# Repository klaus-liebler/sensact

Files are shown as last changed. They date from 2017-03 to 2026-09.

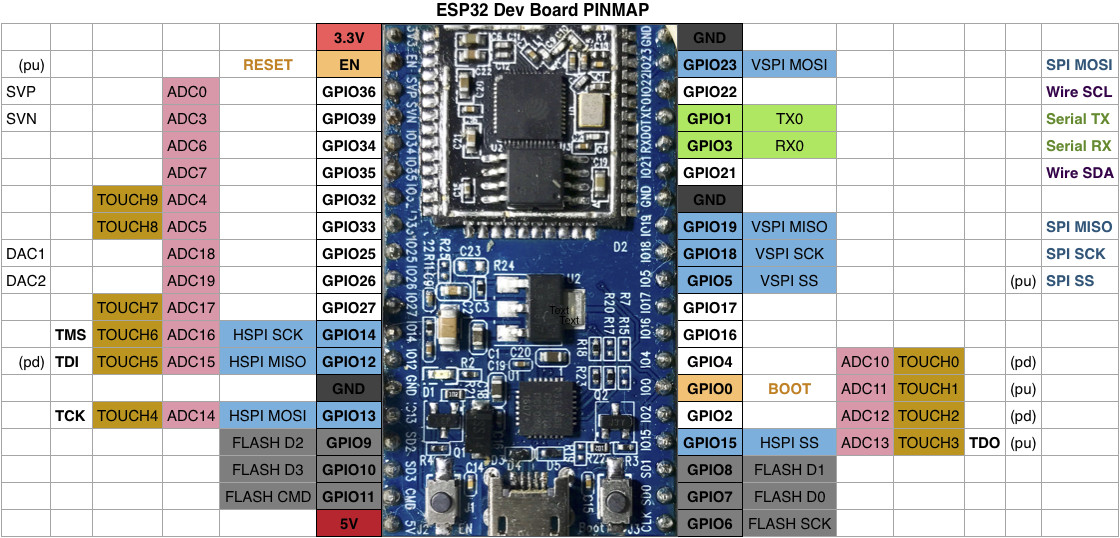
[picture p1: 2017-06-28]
doc/ESP32-T-Pinout-Diagram-Large.jpg

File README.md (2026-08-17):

# sensact
Smarthome system - hardware, firmware, visualization

## Architektur
* Verteiltes System. Modellbasierte Codeerzeugung.
* Grundlage ist `firmware/sensact_firmware/builder/Models/` (Phase `GenerateModelFiles`).
  Hier ein Projekt analog Beispielprojekt "Sattlerstrasse16" anlegen (s.
  `firmware/sensact_firmware/docs/build-process.md`).
* Kleinste Einheit ist eine "Application", die eine eindeutige ID besitzt. Beispiele für Applications sind "Taster", "Drehencoder", "Jalousie" oder "PWM-Licht"

## Hardware
1. SensactHS: Hutschienenmontage
1. SensactUP: Unterputzmontage

## Kommunikation zwischen den Knoten
Die Knoten sind über einen gemeinsamen CAN-Bus verbunden.

### Altes Nachrichtenformat ()
TBD

### Neues Nachrichtenformat

Es gibt vier Namespaces für Nachrichten "REQUEST" und "RESPONSE", "EVENT" und "ACKNOWLEDGE". Dies wird mit den beiden LSB des Versions-Namespace-Bytes erklärt (Somit bleiben 64 Versionierungsmöglichkeiten)
Alle vier Namespaces haben ihren eigenen counter. Dieser beginnt bei 0x0 mit der ersten versendeten Nachricht und läuft nach 255 (0xFF) wieder auf 0. Die Ready-Nachricht wird immer mit counter=0x0 übertragen. Sie darf verwendet werden, um die Kommunikations-Session abzubrechen und die counter neu zu starten. Die counter representieren gemeinsames Wissen von Master und Slave  
REQEST (0b00): Vom Master zum Slave.
RESPONSE (0b01): Antwort auf REQUEST
EVENT (0b10): Vom Slave zum Master
ACKNOWLEDGE (0b11): Antwort des Masters auf ein Event

REQUEST
0x00: "HEARTBEAT": Board gibt Heartbeat zurück
0x01: "IDENTIFY: 
0x02: "SEND_CAN":

RESPONSE
In der Response wird einfach die ID des Requests übernommen. Häufig wird dann ein REQUEST-spezifischer Fehlercode als uint32-t zurück geliefert. Eine 0x0 steht dann per Konvention für eine fehlerfreie Verarbeitung. Ggf. werden in Zukunft WELL_KNOWN_ERROR_CODES definiert.
0x01: UNEXPECTED_COUNTER
0x02: CRC_ERROR

Alle Responses, die nicht nur einen reinen Error-Code, sondern spezifischere Daten zurück liefern, werden im folgenden beschrieben  
0x01: "IDENTIFY": Board gibt Board-Typ u16. NodeID u16 und ID des Chips u96 (?) zurück.

EVENTS
00 "READY" Slave meldet sich nach dem Booten und gibt an, dass er jetzt für Befehle aller Art bereit steht. Beginn einer Session. Alle counter werden auf 0 gesetzt, außer der EVENT_COUNTER - der muss nun auf 1 stehen
02 "CAN_RECEIVED": Slave zeigt an, dass er eine CAN-Nachricht empfangen (besser: auf dem Bus mitgelesen) hat

ACKNOWLEDGES:
Der Slave kann bei ausbleibendem Acknowledge die Nachricht nochmals versenden

## WebUI

### Konzept

Auf einer Website sollen alle Apps einer Node mit commands versehen werden können
Jeder Host hat eine Bedienoberfläche
Problem: Wird die Bedienoberfläche zur Laufzeit von den Hosts und ihren Unterobjekten generiert (a) HTML oder b)JSON) oder kennt die WebUI bereits alle Objekte
Kennt die WebUI die Objekte auch semantisch oder kann Sie nur eine HTML-GUI aufbauen zur Erzeugung von CAN-Bus-Nachrichten 
Denkweise: Die WebUI kann CAN-Nachrichten erzeugen und so an die Node senden, wie sie auch über den CAN-Bus an der Node ankommen würden. Es muss ein JSON generiert werden, das zur Erzeugung einer HTML-UI verwendet werden kann, die dann eben genau diese Nachrichten sendet
Die WebUI kennt bereits alle Applications, die in der Node vorhanden sind. Dazu wird neben der C++-Instanzierung auch TypeScript-Code aufgebaut, der die entsprechenden Objekte aufbaut
Für Buttons und RotEnc gibt es die Möglichkeit, die Beträtigung zu simulieren. Dazu wird dann einfach jene Nachricht auf den MessageBus gelegt, die auch in Wirklichkeit vrsendet wird
An Aktoren können jene Commands versendet werden mitsamt notwendiger Parameter
Für die Erstellung eines Command

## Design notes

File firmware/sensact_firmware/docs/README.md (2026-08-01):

# sensact_firmware – Entwicklerdokumentation

Einstiegspunkt für alles, was zum Verständnis und zur Weiterentwicklung dieses
Projekts gebraucht wird.

- [repo-map.md](repo-map.md) – Aus welchen Repos das Gesamtsystem besteht und wie sie
  zusammenhängen
- [build-process.md](build-process.md) – Wie ein Build/Flash Schritt für Schritt
  abläuft
- [board-provisioning.md](board-provisioning.md) – Wie ein neues Board angelegt und
  in Betrieb genommen wird
- [architecture.md](architecture.md) – Node-/HAL-/App-Architektur der Firmware
  (lebendes Dokument)
- [plan_v2/00-overview.md](plan_v2/00-overview.md) – Der mehrstufige Überarbeitungsplan
  (Stand 2026), falls du wissen willst, warum etwas gerade so ist, wie es ist, oder
  was als Nächstes geplant ist

## Kurzfassung für Eilige

`sensact_firmware` ist die ESP-IDF-Firmware für die "sensact"-Hausautomatisierungs-
Boards (Rollladen, Relais, Dimmer, Fingerprint-Türsteuerung u.a.). Sie ist Teil des
größeren `sensact`-Repos, bindet aber mehrere eigenständige Repos ein (Wifimanager,
Web-UI-Bausteine, Build-Tools) – siehe [repo-map.md](repo-map.md) für Details, bevor
du an mehreren Stellen gleichzeitig etwas änderst.

Ein Build läuft heute über `builder/gulpfile.ts` (Node/TypeScript, wird gerade
schrittweise auf ein C#-Tool umgestellt, siehe
[plan_v2/02-builder-migration-csharp.md](plan_v2/02-builder-migration-csharp.md)) –
Details in [build-process.md](build-process.md).

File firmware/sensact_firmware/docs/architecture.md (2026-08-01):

# Architektur

Lebendes Dokument – wird im Zuge von
[plan_v2/04-architektur-review.md](plan_v2/04-architektur-review.md) laufend
erweitert/korrigiert. Der aktuelle Stand ist eine erste, aus einer Code-Analyse
gewonnene Bestandsaufnahme (2026-07-31), noch nicht vollständig verifiziert.

## Grobe Schichten

```
main.cc (app_main)
  └─ webmanager::M (eigenes Repo: espidf-component-webmanager)
       – Wifi-Statemachine, HTTP/OTA/Login, Plugin-Dispatch
  └─ cNodemaster (nodemaster.hh)
       – 100ms-Zyklus: CAN-RX -> OfferMessage(hosts) -> Loop(hosts) -> CAN/Health
       – implementiert iHostContext (Services für Hosts) und iWebmanagerPlugin
       ├─ AbstractBusmaster[] (busmaster.hh)
       │    ├─ I2CBusmaster       – PCA9555/PCA9685 über I2C, eigener Task
       │    ├─ DirectGPIOBusmaster – direkt über iHAL
       │    └─ CANBusmaster        – Stub
       └─ iHost[] (interfaces.hh)
            ├─ cApplicationHost (node_applicationhost.cc/hh)
            │    – implementiert iHost + sensact::apps::iSensactContext + iWebmanagerPlugin
            │    – Setup/Loop/Status-Publishing aller sensact-Apps
            │    └─ cApplication[] (sensact/espidf-components/sensact-applicationmodel/apps/)
            │         blind, blindstimer, onoff, pump, singlepwm, rgbw, sound,
            │         milightcontroller, pushbutton, rotaryencoder, node, fingerprint
            ├─ cGatewayHost (node_gatewayhost.hh) – aktuell No-Op-Stub
            └─ cIoHost (node_iohost.hh)          – aktuell No-Op-Stub
```

## HAL-Board-Varianten (`main/hal/`)

Gemeinsame Basis `hal_esp32.hh` (`sensact::hal::cESP32`, TWAI/CAN, GPIO, UART,
MCPWM, Temperatursensor). Board-spezifische Ableitungen:

| Datei | Board-Variante | Besonderheiten |
|---|---|---|
| `hal_sensactHs_modular.hh` | HS Modular | internes I2C, I2S-Audio (MAX98357), Ethernet, CAN |
| `hal_sensactHsNano3.hh` | HS Nano3 | TAS580x-Verstärker, Ethernet, ADC-Buttons, Buzzer |
| `hal_sensactOutdoor.hh` | Outdoor | Relais K1–K4, LEDs, NRF-Funk, MAX98357-Audio |
| `hal_sensactUp3.hh` | Up3 | SPI-LCD, 1-Wire, Drehencoder |
| `hal_sensactUpControl.hh` | Up Control | NRF-Funk, Fingerprint-Sensor, Buzzer |
| `hal_sensactUpHs.hh` | Up HS | 2 Drehencoder, Codec/MAX98357-Audio, USB-VBUS-Sense |

Grad der Code-Duplizierung zwischen diesen 6 Dateien noch nicht im Detail geprüft –
siehe Backlog-Punkt in
[plan_v2/04-architektur-review.md](plan_v2/04-architektur-review.md).

Pro Node (`main/hal/<NODE_ID>/`) liegen zusätzlich drei **von Hand gepflegte**
`.inc`-Dateien (`hal.inc`, `station_config_hardware.inc`,
`station_config_hosts.inc`), die auswählen, welche HAL/Busmaster/Hosts für dieses
konkrete Board aktiv sind – siehe [board-provisioning.md](board-provisioning.md).

## Sensact-Apps

Jede App erbt von `sensact::apps::cApplication`
(`sensact-applicationmodel/cApplication.hh`): `Setup(iSensactContext*)`,
`Loop(iSensactContext*)`, `FillStatus(iSensactContext&, array<uint16_t,4>&)`, plus
generierte Command-Handler. Die Registry `cApplications::Glo2locCmd[]`/`Glo2locEvt[]`
bildet `eApplicationID` auf konkrete Instanzen ab (oder `nullptr`, falls die App auf
einem anderen Node gehostet wird). Alle App-Methoden hängen nur am Interface
`iSensactContext`, nicht an ESP-IDF-Typen direkt – das ist die Grundlage für die
Host-Testbarkeit in [plan_v2/05-unit-tests-sensact-apps.md](plan_v2/05-unit-tests-sensact-apps.md).

## Cross-Cutting

- `messagecodes.hh` – X-Macro-generiertes `enum class messagecodes::C` +
  String-Tabelle, aus `messagecodes_default.inc` + optionalem `messagecodes_user.inc`.
- `logger.hh` – `LOGGER::Journal(code, data)`, leitet an
  `webmanager::JournalPlugin` weiter.
- `journal_plugin.cc/hh` – Ringpuffer (16 Einträge) in `__NOINIT_ATTR`-RAM (überlebt
  Neustarts außer Kaltstart), exponiert über Websocket (`ns10journal`).

## Bekannt tote/veraltete Teile

`main/__archive/` – nicht im Build referenziert (`.ccold`/`.hhold`-Endungen,
veraltete APIs). Aufräum-Kandidat, siehe
[plan_v2/04-architektur-review.md](plan_v2/04-architektur-review.md).

## Wifimanager

Server-seitig eine einzelne ~1430-Zeilen-Klasse `webmanager::M`
(`espidf-component-webmanager/cpp/webmanager.hh`), die WLAN-Statemachine,
HTTP-Fileserver, OTA, Login/Session und Wifimanager-Protokoll in einer Klasse
vereint. Details, bekannte Bugs und das geplante konfigurierbare AP-Fallback siehe
[plan_v2/03-wifimanager-review.md](plan_v2/03-wifimanager-review.md).

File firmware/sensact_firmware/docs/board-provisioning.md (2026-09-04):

# Board-Provisioning

Ablauf, um ein neues physisches Board mit dieser Firmware in Betrieb zu nehmen.

## 1. Board anschließen und auslesen

```
cd builder
npm run u    # addOrUpdateConnectedBoard
```

Liest MAC-Adresse und Chip-Infos vom per USB verbundenen Board aus (eigene
serielle SLIP/ROM-Loader-Implementierung in `esp32.ts`, kein `esptool`-Aufruf) und
legt/aktualisiert die board-spezifische `board_info.json` unter
`%USERPROFILE%\OneDrive - HSOS\esp32_boards\<mac-dir>\board_info.json` an. Diese
Datei wird außerdem als "aktuell verbundenes Board" in den Projekt-Root kopiert
(`board_info.json` neben dieser Datei).

`board_info.json`-Schema (`SensactBoardRecord`) -- generischer, projektübergreifender Teil des
Board-Zustands (Backing für `IBuildContext.WebAdminPassword`/`BoardSettings`, s.
`dotnet_libs/firmware_builder_common`):

```json
{
  "mac": "...",
  "board_version": 10000,
  "board_settings": { "override_hostname": "...", "last_debug_probe_id": "..." },
  "first_connected_dt": "...",
  "last_connected_dt": "...",
  "web_admin_password": null,
  "flash_encryption_key_burned_and_activated": false
}
```

`board_settings` ist ein flaches String-Dictionary (generische Overrides, projektübergreifend).
Wohlbekannte Schlüssel: `"override_hostname"`, `"override_wifi_ap_ssid"`, `"last_debug_probe_id"`.

## 2. Node-ID / Board-Rolle festlegen

Nicht `board_info.json`, sondern das board-spezifische `sensact.json` (s. Abschnitt 3) legt per
`node_id` fest, welches Unterverzeichnis unter `main/hal/<NODE_ID>/` zur Build-Zeit eingebunden
wird (`main/CMakeLists.txt`: `INCLUDE_DIRS "hal/${NODE_ID}"`). `board_version` ist rein
beschreibend und beeinflusst die `NODE_ID` nicht. `board_name` (Anzeige, Default-Web-Passwort)
lebt jetzt ebenfalls in `sensact.json`, s. Abschnitt 3 -- sensact-spezifisch, nicht Teil des
projektübergreifenden `board_info.json`-Vertrags.

**Wichtig (bestätigt von Klaus, 2026-07-31): die drei Dateien pro Node-Verzeichnis
werden von Hand gepflegt, es gibt aktuell keinen Generator dafür:**

- `hal.inc` – welche `iHAL`-Implementierung (`hal_sensact*.hh`) für dieses Board
  verwendet wird.
- `station_config_hardware.inc` – Verdrahtung der `AbstractBusmaster`-Instanzen
  (I2C-Busmaster, GPIO-Busmaster, …) auf die physische Hardware.
- `station_config_hosts.inc` – welche `iHost`-Instanzen (`cApplicationHost`,
  `cGatewayHost`, `cIoHost`) für diesen Node aktiv sind.

Existiert für die gewünschte `NODE_ID` noch kein solches Verzeichnis, muss es manuell
neu angelegt werden (bestehendes `main/hal/<ähnliches-Board>/` als Vorlage nehmen).

## 3. Sensact-spezifisches `sensact.json`

Zusätzlich zu `board_info.json` liest der Builder (`ISensactContext`/`SensactContextLoader.cs`)
ein board-spezifisches `sensact.json` (`<boardsDir>\<mac-dir>\sensact.json`):

```json
{
  "node_id": "SNSCT_L3_WORK_HS",
  "board_name": "SENSACT_L3_WORK",
  "board_settings": { "web": {}, "firmware": {} }
}
```

`node_id` wird als HAL-Include-Verzeichnisname *und* (sofern nicht per `board_settings.override_hostname`
überschrieben) als Hostname verwendet. `board_name`/`board_settings` sind sensact-spezifisch (Anzeige,
Default-Web-Passwort-Fallback, App-/Web-Defines) -- nicht Teil des projektübergreifenden
`board_info.json`-Vertrags. Muss beim erstmaligen Anlegen eines Boards von Hand angelegt werden.

## 4. Generieren, bauen, flashen

```
npm run c     # buildForCurrent: createFiles + Web-Build + idf.py build
# oder die Vollkette inkl. Flash:
npm start     # addOrUpdateConnectedBoard -> buildForCurrent -> encrypt (falls nötig) -> flash
```

## 5. Zertifikate & Flash-Encryption

- Board-Zertifikat (`esp32.pem.crt`/`esp32.pem.key`) wird beim ersten `createFiles`-Lauf
  automatisch erzeugt (selbstsigniert, signiert von der Root-CA unter
  `OneDrive - HSOS\certificates`), falls noch nicht vorhanden.
- Flash-Encryption-Key wird ebenfalls lazy erzeugt, falls noch nicht vorhanden.
  Ob tatsächlich verschlüsselt geflasht wird, hängt von `DEFAULT_ENCRYPTION_MODE`
  (`gulpfile.ts`) und dem gespeicherten
  `flash_encryption_key_burned_and_activated`-Flag ab.

## 6. Build ohne physisches Board (offline)

Um für eine beliebige `NODE_ID` (z.B. `SNSCT_NODE_SIDEDOOR`) einen kompletten Build
durchzuführen, ohne dass das Board angeschlossen ist und ohne dessen echte MAC zu
kennen, ruft `PipelineOffline --nodeId <NODE_ID>` intern zuerst `PrepareContextWithCommandLineArguments`
auf (Nachfolger von `SelectOfflineBoard`) -- wählt ein synthetisches Board-Archiv aus (eine
aus der `NODE_ID` deterministisch abgeleitete, als "locally administered" markierte
Fake-MAC -- niemals eine echte Hersteller-MAC, s. `SensactBuildContext.EnsureBoardForOfflineNodeId`).
Danach laufen die uebrigen Schritte wie gewohnt:

```
dotnet run --project builder -- PipelineOffline --nodeId SNSCT_NODE_SIDEDOOR --model Sattlerstrasse16
# oder einzeln:
dotnet run --project builder -- PrepareContextWithCommandLineArguments --nodeId SNSCT_NODE_SIDEDOOR
dotnet run --project builder -- PipelineOffline --model Sattlerstrasse16
```

Legt bei Bedarf ein neues Board-Archiv unter `<boardsDir>\<fake-mac-dir>\` mit
Default-`board_info.json` und passender `sensact.json` an (inkl. eigenem Zertifikat,
s. Abschnitt 5) und überschreibt den Repo-Root-Cache (`board_info.json`), genau wie
`PrepareContextWithRealHardware` es für ein echtes Board täte. Gleiche `NODE_ID` -> gleiche Fake-MAC
-> gleiches Archiv, das Zertifikat wird also nicht bei jedem Lauf neu erzeugt. Flashen
(`FlashFirmware`) ergibt für ein solches Board naturgemäß keinen Sinn und ist nicht
Teil von `PipelineOffline`.

## Offene Punkte (siehe auch [plan_v2/01-entwicklerdokumentation-und-build.md](plan_v2/01-entwicklerdokumentation-und-build.md))

- Es gibt keinen automatisierten Weg, ein komplett neues `main/hal/<NODE_ID>/`-Verzeichnis
  aus einer Vorlage zu erzeugen – das ist reine Handarbeit und ein möglicher, aber
  aktuell nicht geplanter Verbesserungspunkt für die C#-Builder-Migration (Stufe 2).

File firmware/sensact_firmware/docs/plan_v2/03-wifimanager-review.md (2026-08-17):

# Stufe 3 – Wifimanager-Review + konfigurierbares AP-Fallback

**Status (2026-08-01): umgesetzt.** Ueber den urspruenglichen Scope dieser Stufe
hinaus wurde auf Nutzerwunsch gleichzeitig die komplette ws-protocol-Migration
(BestBinaryBuffers statt Flatbuffers) fuer alle 8 Namespaces mit echter Server-
Implementierung durchgezogen (wifimanager, scheduler, systeminfo, usersettings,
nodemaster, sensact, journal, fingerprint) -- s. eigener Abschnitt "ws-protocol-
Migration (ueber den urspruenglichen Scope hinaus)" am Ende dieser Datei fuer Details,
betroffene Dateien und offene Punkte (v.a. Firmware-Build-Verifikation, s.u.).

**Repo-Hinweis:** Der Server-Code liegt in `C:\repos\espidf-component-webmanager`
(eigenes Repo, Remote `klaus-liebler/espidf-component-webmanager`), der Client-Code in
`C:\repos\npm-packages\@klaus-liebler\web-components` (eigenes Repo, Remote
`klaus-liebler/npm-packages`). Beide waren in dieser Session (anders als die hier
urspruenglich vermerkte Annahme) tatsaechlich als Working Directories zugaenglich,
ebenso `C:\repos\npm-packages\@klaus-liebler\web-components-sensact` und
`sensact-base` (weitere, urspruenglich nicht erwaehnte Consumer-Pakete, s.u.).

## Ist-Zustand: WLAN-Statemachine (Server, `cpp/webmanager.hh`)

Die gesamte Logik steckt in einer einzigen Klasse `webmanager::M` (Singleton,
~1430 Zeilen, `cpp/webmanager.hh`), die gleichzeitig WLAN-State-Machine,
HTTP-Fileserver, OTA-Update, Login/Session-Verwaltung und den Wifimanager-Websocket-
Handler enthält (siehe auch Stufe 4 – das ist auch ein Architektur-Fund).

Zustände: `WorkingState::AP_STARTED` / `KEEP_CONNECTION`
(`webmanager_workingstate.inc`). Drei Timer (`tTimeout_us`, `tShutdownAp_us`,
`tReconnect_us`), die per `Supervise()` (alle 4s, eigener FreeRTOS-Task) gepollt
werden (`webmanager.hh:1401-1430`).

**Aktuelles Reconnect-/Fallback-Verhalten** (`wifi_event_handler`,
`webmanager.hh:273-337`, Konstanten in `webmanager_constants.hh`):
- Bei Verbindungsabbruch (`WIFI_EVENT_STA_DISCONNECTED`) wird ein Zähler
  `remainingAttempsToConnectAsSTA` runtergezählt.
- Beim Boot startet dieser Zähler bei `RECONNECTS_ON_STARTUP = 3` – nach 3
  gescheiterten Versuchen (~24s) fällt das Gerät zurück in den Access-Point-Modus.
- Nach dem **ersten erfolgreichen** Connect wird der Zähler auf
  `RECONNECTS_ON_OPERATION = UINT32_MAX` gesetzt (`webmanager.hh:307`) – das
  bedeutet: **sobald das Gerät einmal erfolgreich verbunden war, wird praktisch nie
  wieder ein Access Point geöffnet**, das Gerät versucht für immer (alle 8s,
  `RECONNECT_TIMEOUT_US`) erneut zu verbinden.
- Das ist **das Gegenteil** dessen, was gewünscht ist: aktuell gibt es keine
  Zeit-basierte Konfiguration, sondern zwei fest kodierte, inkonsistente
  Attempt-Zähler (3 vs. "unendlich"), die zudem Boot-Fall und Betriebs-Fall
  unterschiedlich behandeln, ohne dass das irgendwo konfigurierbar wäre.

## Gewünschte neue Funktionalität

Konfigurierbare Zeitdauer, nach der (bei durchgehend fehlgeschlagenen
Reconnect-Versuchen) ein eigener Access Point geöffnet wird, um Rekonfiguration zu
ermöglichen. Ein Sentinel-Wert (z.B. `INT64_MAX`, passend zur bereits existierenden
Konstante `FAR_FUTURE` in `webmanager_constants.hh:8`) soll bedeuten: **niemals**
einen Access Point öffnen, stattdessen für immer weitere Verbindungsversuche starten.

### Vorgeschlagenes Design

1. Attempt-Zähler-Modell (`remainingAttempsToConnectAsSTA`,
   `RECONNECTS_ON_STARTUP`/`RECONNECTS_ON_OPERATION`) durch ein
   **Deadline-Modell** ersetzen:
   - Neuer Zustand: `giveUpAt_us` (Zeitpunkt, ab dem – falls immer noch nicht
     verbunden – der AP geöffnet wird). Wird gesetzt, sobald die STA-Verbindung
     verloren geht bzw. beim Boot, falls von Anfang an keine Verbindung zustande
     kommt: `giveUpAt_us = now_us + WIFIMANAGER_AP_FALLBACK_TIMEOUT_US`.
   - Wird auf `FAR_FUTURE` zurückgesetzt, sobald `IP_EVENT_STA_GOT_IP` feuert
     (erfolgreich verbunden).
   - `Supervise()` bzw. der Disconnect-Handler prüfen `now_us > giveUpAt_us` statt
     eines Zählers – das vereinheitlicht Boot- und Betriebsverhalten unter einer
     einzigen, konfigurierbaren Zeitspanne statt zwei verschiedenen Konstanten.
   - Retry-Abstand (aktuell `RECONNECT_TIMEOUT_US = 8s`) bleibt eine **feste,
     nicht konfigurierbare** `constexpr` (Reconnect-Intervall ≠ Gesamt-Timeout bis
     AP-Fallback – nur Letzterer wird konfigurierbar, siehe "Entschieden" unten).
   - Sentinel: `WIFIMANAGER_AP_FALLBACK_TIMEOUT_US == INT64_MAX` (bzw. wiederverwendbar
     als `FAR_FUTURE`) ⇒ `giveUpAt_us` wird nie erreicht ⇒ Gerät versucht für immer,
     nie AP. Das deckt sich mit dem bestehenden `FAR_FUTURE`-Konzept, das im Code
     schon für "kein Timeout" verwendet wird – konsistente Wiederverwendung statt
     neuer Sonderwert.

2. **Wo die Konfiguration herkommt:** aktuell ist die Zeitkonstante in
   `webmanager_constants.hh` fest einkompiliert (`constexpr`). Für Konfigurierbarkeit
   pro Board muss sie zu einem Parameter von `M::Begin(...)` werden (die Methode nimmt
   bereits mehrere optionale Parameter entgegen, z.B. `wifiLogLevel`,
   `auth_username_param` – das neue Verhalten reiht sich dort ein:
   `time_t apFallbackTimeout_us = FAR_FUTURE`). `RECONNECT_TIMEOUT_US` bleibt
   unverändert eine `constexpr` in `webmanager_constants.hh` (siehe "Entschieden").
   Aufrufseitig (`sensact_firmware/main/main.cc`, wo `webmanager::M::GetSingleton()->Begin(...)`
   aufgerufen wird) wird der Wert aus dem bereits bestehenden Build-Define-Mechanismus
   bezogen (`board_settings.firmware` in `board_info.json` → `createObjectWithDefines()`
   im Builder (Stufe 1/2) → generiertes `runtimeconfig.hh`, Namespace `cfg::`) – das ist
   exakt der Mechanismus, der für alle anderen board-spezifischen Firmware-Einstellungen
   schon existiert, hier lediglich um einen neuen Key erweitert
   (`WIFIMANAGER_AP_FALLBACK_TIMEOUT_MS`).
3. Optionale, spätere Erweiterung (nicht Teil des MVP): exponentielles Backoff statt
   fixem Reconnect-Intervall; UI-Anzeige "verbleibende Zeit bis AP-Fallback" im
   Wifimanager-Web-Client.

## Konkrete Bugs/Inkonsistenzen, die im Zuge dieser Stufe mitgeprüft/behoben werden sollten

1. **Inkonsistente Argumentanzahl bei `CreateResponseWifiConnectDirect`**:
   - `sendWifiConnectionNotSuccessfulMessage()` (`webmanager.hh:157-166`) ruft
     `CreateResponseWifiConnectDirect(b, false, "", 0, 0, 0)` (bool + 4 weitere Werte).
   - `handleRequestWifiConnect()`s `negativeresponse`-Label (`webmanager.hh:587-594`)
     ruft dieselbe Funktion mit `(b, false, ssid, 0, 0, 0, 0)` (bool + 5 weitere Werte).
   - Das Flatbuffers-Schema `ResponseWifiConnect` hat die Felder
     `success, ssid, ip, netmask, gateway, rssi` (6 Felder,
     `ns01wifimanager.fbs:39-45`) – die beiden Call-Sites sind demnach
     unterschiedlich (und mindestens eine davon vermutlich falsch/inkonsistent).
     **Muss zuerst gegen die tatsächlich generierte Signatur
     (`ns01wifimanager_generated.h`, wird zur Build-Zeit erzeugt) geprüft und dann
     vereinheitlicht werden.**
2. **Fehlerhafter `Set-Cookie`-Header beim Login** (`handle_login_post`,
   `webmanager.hh:~1082-1090`): zwei Cookies werden in *einen* Aufruf von
   `httpd_resp_set_hdr(req, "Set-Cookie", cookie_header)` gepackt, wobei
   `cookie_header` selbst bereits den literalen Text `"Set-Cookie: "` und ein
   eingebettetes `\r\n` enthält. Das ist kein valides HTTP (ein Header-Wert darf
   keinen zweiten Header-Namen + Zeilenumbruch enthalten). Der Beweis, dass das ein
   echter Bug ist: der Dev-Proxy (`web/vite.config.mts`, aktuell in Bearbeitung im
   Arbeitsverzeichnis) muss den Client-seitigen Workaround
   `c.replace(/^Set-Cookie:\s*/i, "")` einbauen, weil sonst das Cookie nicht
   erkannt wird. **Fix:** `httpd_resp_set_hdr` zweimal aufrufen (einmal pro Cookie),
   oder – falls die HTTP-Server-API in ESP-IDF Mehrfach-Header nicht sauber
   unterstützt – nur ein Cookie mit beiden Infos kombiniert übertragen, statt zwei
   separate `Set-Cookie`-Zeilen ineinander zu verschachteln.
3. **Default-Zugangsdaten** `"admin"`/`"password"` als Fallback-Parameter von
   `Begin(...)` – prüfen, ob das in der Praxis immer überschrieben wird (Board-
   Provisioning) oder ob hier ein reales Risiko besteht, dass ein Board mit
   Standard-Login im Feld landet. Falls ja: in Stufe 1 (Board-Provisioning-Doku)
   und/oder Stufe 4 (Architektur-Backlog) verpflichtend machen, dass eigene
   Zugangsdaten gesetzt werden.
4. **`validate_credentials`** vergleicht Strings mit `==` (nicht
   konstant-zeitig) – Timing-Seitenkanal. Angesichts des Einsatzzwecks (lokales
   Access Point, physischer Zugriff nötig) niedrige Priorität, aber als Fund im
   Architektur-Backlog vermerken.

## Client-Seite

- Wifimanager-UI: `C:\repos\npm-packages\@klaus-liebler\web-components\typescript\screen_controller\wifimanager_controller.ts`
  (`WifimanagerController`) – zeigt STA-Status, AP-Konfiguration, Netzwerkliste,
  Connect/Disconnect-Dialoge. Transport über
  `.../typescript/screen_controller/app_controller.ts` (`AppController`,
  WebSocket mit Namespace-Präfix-Framing).
- **Es gibt aktuell keine automatische Reconnect-Logik im Client** – nur eine
  statische Fehler-Snackbar bei `onclose`/`onerror`. Das ist prinzipiell in Ordnung
  (Reconnect ist Firmware-Sache), aber es gibt auch **keine UI-Anzeige, dass/wann**
  das Gerät gerade in den AP-Fallback wechselt. Optionale Erweiterung (nicht MVP):
  die neue `ResponseNetworkInformation` könnte um ein Feld
  "verbleibende Zeit bis AP-Fallback" ergänzt werden, das der Client anzeigt.

## Vorgehen

- [x] Bug #1 (Argumentanzahl bei `CreateResponseWifiConnectDirect`) – **erledigt sich
      automatisch**: die komplette Flatbuffers-Funktion entfaellt durch die
      ws-protocol-Migration (s.u.), `ResponseWifiConnect::Payload` wird jetzt an
      genau einer Stelle je Call-Site befuellt (`webmanager.hh`,
      `sendWifiConnectionNotSuccessfulMessage`/`sendWifiConnectionSuccessfulMessage`/
      `handleRequestWifiConnect`), kein Uneinigkeits-Risiko mehr moeglich. Dabei
      wurde nebenbei auch der schon damals vermerkte Bug behoben, dass `ap.rssi` in
      `sendWifiConnectionSuccessfulMessage` zwar geholt, aber nie in die Response
      geschrieben wurde.
- [x] Bug #2 (Set-Cookie) behoben: `handle_login_post` ruft jetzt zweimal
      `httpd_resp_set_hdr(req, "Set-Cookie", ...)` (einmal pro Cookie) statt eines
      kombinierten, malformten Header-Werts. Client-seitiger Workaround in
      `web/vite.config.mts` (`c.replace(/^Set-Cookie:\s*/i, "")`) entfernt.
      **Noch offen:** echte End-to-End-Verifikation (Login-Flow gegen ein Board)
      steht aus, s. "Offene Punkte" unten.
- [x] Bug #3 (Default-Zugangsdaten): `Begin(...)` bekommt weiterhin `"admin"`/
      `"password"` als Fallback, aber `main.cc`s Aufruf reicht jetzt optional
      `cfg::WEBMANAGER_AUTH_USERNAME`/`cfg::WEBMANAGER_AUTH_PASSWORD` durch (per
      `#ifdef`-Praesenzpruefung gegen `runtimeconfig_defines.hh`, analog zum neuen
      AP-Fallback-Timeout-Mechanismus) – pro Board ueberschreibbar, kein Board setzt
      die Keys aktuell, also unveraendertes Verhalten bis explizit konfiguriert.
- [x] Bug #4 (nicht-konstantzeitiger Credential-Vergleich): `validate_credentials`
      nutzt jetzt `constant_time_equals` (Laengen-Check + XOR-Akkumulation ohne
      Early-Exit).
- [x] Deadline-Modell implementiert: `giveUpAt_us`/`apFallbackTimeout_us` ersetzen
      `remainingAttempsToConnectAsSTA`/`RECONNECTS_ON_STARTUP`/
      `RECONNECTS_ON_OPERATION` (aus `webmanager_constants.hh` entfernt). Neuer
      `Begin(...)`-Parameter `time_t apFallbackTimeout_us_param = FAR_FUTURE`.
      `giveUpAt_us` wird nur beim ERSTEN Disconnect einer Serie scharfgeschaltet
      (nicht bei jedem Retry neu), bei erfolgreichem Connect auf `FAR_FUTURE`
      zurueckgesetzt.
- [x] Konfigurationswert durch die Build-Kette durchgereicht: `board_settings.firmware`
      → (generischer, unveraenderter Mechanismus in `GenerateRuntimeConfig.cs`) →
      `runtimeconfig.hh`/`runtimeconfig_defines.hh` → `main.cc`s `Begin(...)`-Aufruf
      (`#ifdef __WIFIMANAGER_AP_FALLBACK_TIMEOUT_MS__` mit `FAR_FUTURE`-Fallback,
      d.h. kein Board-Verhalten aendert sich, bis ein Board den Key explizit setzt).
- [ ] Kurzer Testplan (manuell): **noch nicht durchgefuehrt**, da kein Firmware-Build
      moeglich war (s. "Offene Punkte" unten) – AP-Fallback nach konfigurierter Zeit
      auslösen (z.B. durch Router ausschalten), Sentinel-Wert testen (Gerät soll
      dauerhaft weiterprobieren, nie AP öffnen), sobald ein Build moeglich ist.
- [ ] Optional/Stretch: `webmanager::M` in kleinere Klassen aufteilen – weiterhin
      nicht Teil dieser Stufe, Eintrag fuer Stufe 4 (Architektur-Backlog) bleibt
      bestehen. wifimanager wird weiterhin inline in `M` behandelt (nicht als
      eigenstaendiges Plugin extrahiert), s. "ws-protocol-Migration" unten fuer die
      Begruendung.

## Offene Punkte (Stand 2026-08-17)

- **Firmware-Build ist jetzt gruen**: die ESP-IDF-Python-venv war kaputt
  (Basis-Interpreter durch ein Scoop-Update verschwunden), per `install.bat`
  gegen die verbliebene Python-3.14-Installation neu aufgesetzt. Der erste echte
  `idf.py build` gegen den migrierten Code deckte danach zwei Codegenerator-Bugs
  in `BestBinaryBuffers` auf (Structs/Classes wurden in Schema-Deklarations-
  statt Abhaengigkeits-Reihenfolge emittiert → C++-Vorwaertsreferenzfehler;
  Append/Encode/Decode-Helper waren unnoetig eine Namespace-Ebene zu tief
  verschachtelt) – beide in `CppGenerator.cs` gefixt (topologische Sortierung,
  Helper-Emission auf die Owner-Namespace-Ebene gehoben). Dazu ein paar kleinere
  Bugs im migrierten Code (fehlendes `ret` fuer `ESP_GOTO_ON_FALSE`, Parameter-
  Shadowing in `journal_plugin.hh`, fehlendes `<sys/time.h>`, `std::string`→
  `const char*`-Konvertierung in `nodemaster.hh`, zu kleiner Cookie-Puffer). Alle
  drei Repos (`sensact`, `espidf-component-webmanager`, `best_binary_buffers`)
  committet, erste zwei gepusht.
- **TypeScript-Seite weiterhin verifiziert**: `tsc --noEmit` in `web/` (deckt
  `web-components`, `web-components-sensact`, `sensact-base`,
  `usersettings_runtime` ueber die npm-`file:`-Abhaengigkeiten mit ab) laeuft
  fehlerfrei durch – das prueft aber nur Typkorrektheit, nicht tatsaechliches
  Laufzeitverhalten gegen einen echten Server.
- **Immer noch offen: End-to-End-Test gegen ein echtes Board** fuer keinen der 8
  migrierten Namespaces (wifimanager, scheduler, systeminfo, usersettings,
  nodemaster, sensact, journal, fingerprint) – jetzt, wo der Build durchlaeuft,
  ist das der naechste sinnvolle Schritt. Das `SENSACT_L3_WORK`-Board eignet sich
  dafuer (AP-Fallback-Timeout + Sentinel-Wert testen, danach alle 8 Namespaces
  einmal durchspielen).

## Entschieden

- **Reconnect-Intervall bleibt eine feste Konstante** (nicht konfigurierbar) –
  nur der **AP-Fallback-Timeout wird konfigurierbar**. Das vereinfacht Punkt 2 im
  Design oben: `M::Begin(...)` bekommt nur einen neuen Parameter
  (`time_t apFallbackTimeout_us = FAR_FUTURE`), `RECONNECT_TIMEOUT_US` bleibt wie
  bisher eine `constexpr` in `webmanager_constants.hh`. Entsprechend gibt es auch nur
  **einen** neuen Build-Define-Key, nicht zwei (`WIFIMANAGER_AP_FALLBACK_TIMEOUT_MS`).
- **Sentinel-Kodierung**: numerischer Wert in Millisekunden im Board-Settings-JSON,
  `INT64_MAX`-Millisekunden-Äquivalent als Sentinel für "nie AP öffnen" – wie
  vorgeschlagen.

## ws-protocol-Migration (ueber den urspruenglichen Scope hinaus, 2026-08-01)

Auf expliziten Nutzerwunsch ("Jetzt Stufe 3! und dabei die neue Serialisierung des
Websockets einbinden!", spaeter praezisiert zu "kein Nebeneinander, keine
Kompatibilitaetsschicht") wurde diese Stufe genutzt, um Flatbuffers durch den neuen
`BestBinaryBuffers`-Serializer (Schema als annotierter C#-Code statt `.fbs`/JSON, s.
`C:\repos\dotnet_libs\best_binary_buffers`) zu ersetzen – nicht nur fuer wifimanager,
sondern fuer alle Namespaces mit echter Server-Implementierung.

### Scope

Von den 12 Wire-Namespaces haben **8 eine echte Server-Implementierung** und wurden
vollstaendig migriert (Server + Client, soweit ein Client existiert):
`wifimanager`, `scheduler`, `systeminfo`, `usersettings` (alle in
`espidf-component-webmanager/cpp/`), sowie `nodemaster`, `sensact`, `journal`,
`fingerprint` (alle in `sensact_firmware/main/`).

- `canmonitor`, `chatbot`: keine Server-Implementierung irgendwo – Schema existiert,
  aber nichts zu migrieren (canmonitor hat einen toten Client, s.u.).
- `functionblock`, `heaterexperiment`: echter TS-Client existiert
  (`Flowchart.ts`/`develop_cfc_controller.ts`, `heater_experiment_controller.ts`),
  aber keine Server-Implementierung im `sensact`-Monorepo – der Server lebt in einem
  anderen, hier nicht betrachteten Firmware-Projekt (das `web-components`-Paket wird
  projektuebergreifend genutzt). **Bewusst nicht migriert** – bleiben auf Flatbuffers,
  s. "Uebergangsregel" unten.

### Teil A: Einheitlicher Transport-Mechanismus (statt Parallelbetrieb)

- **Server** (`espidf-component-webmanager/cpp/webmanager_interfaces.hh`):
  `iWebmanagerCallback::WrapAndSendAsync(uint32_t, FlatBufferBuilder&)` komplett
  ersetzt durch `SendRawAsync(const uint8_t* data, size_t len)` (erwartet einen
  bereits vollstaendig ws-protocol-gerahmten Frame). `iWebmanagerPlugin::
  ProvideWebsocketMessage(...)` liest jetzt `uint16_t namespaceId, uint16_t
  messageTypeId, const uint8_t *frame, size_t frameLen` statt `uint32_t ns, uint8_t*
  buf` (kein Vorab-Slicing durch den Dispatcher mehr). `webmanager_async_response.hh`s
  `AsyncResponse` hat entsprechend nur noch einen Konstruktor (roher Byte-Puffer,
  kein Namespace-Praefix-Voranstellen mehr). wifimanager bleibt bewusst **inline** in
  `M` (keine Extraktion in eine eigene `WifimanagerPlugin`-Klasse, da eng mit der
  WLAN-State-Machine verzahnt) und implementiert `ProvideWebsocketMessage` einfach
  mit derselben Signatur, direkt vom Dispatcher aufgerufen (kein Sonderfall im
  Dispatcher-Code selbst mehr, anders als zuvor).
- **Client** (`web-components/typescript/`): `IWebsocketMessageListener`/
  `IAppManagement` in `utils/interfaces.ts` ersetzt durch `IMessageListener.
  OnMessage(namespaceId, messageTypeId, view: DataView)` und `IAppManagement.
  RegisterNamespace(...)`/`SendFrame(namespaceId, bytes, maxLockingTimeMs?)`.
  `AppController` kennt kein Flatbuffers-Konzept mehr, hat nur noch eine Map/ein
  Interface/eine Sende-Methode, haengt selbst keinen Praefix mehr an (jeder Aufrufer
  liefert einen fertigen Frame).
- **Uebergangsregel fuer functionblock/heaterexperiment** (bewusst NICHT migriert):
  kein Widerspruch zu "keine Kompatibilitaetsschicht" – `AppController` bleibt bei
  genau einem Mechanismus, die 2 Controller (`Flowchart.ts`/
  `develop_cfc_controller.ts`, `heater_experiment_controller.ts`) adaptieren sich
  selbst mechanisch (eigenes Slicen/`ByteBuffer`-Wrap in ihrem `OnMessage`, eigenes
  Voranstellen des alten 4-Byte-uint32-Praefix vor `SendFrame`) – ihre Flatbuffers-
  Payload-Logik selbst bleibt unangetastet.

### Teil B: Migrierte Namespaces (Server + Client)

Gemeinsames Muster: `#include "flatbuffers_cpp/nsNN..._generated.h"` →
`#include "wsprotocol_cpp/ws_protocol.hh"`; `flatbuffers::GetRoot<...RequestWrapper>`/
`request_type()`-Switch → `if (namespaceId != WsProtocol::<ns>::NAMESPACE_ID) return
NOT_FOR_ME;` + `switch (messageTypeId)` gegen generierte `TYPE_ID`-Konstanten;
`CreateResponseWrapper(...).Union()` + `WrapAndSendAsync` → `WsProtocol::<ns>::
ResponseXxx::Payload` befuellen + `Encode(...)` in einen Stack-/`static`-Scratch-Puffer
+ `SendRawAsync(...)`. `requestId` wird aus dem jeweils dekodierten Request
uebernommen und in der Response zurueckgegeben (bei asynchron gepushten Notifications
– wifimanager `ResponseWifiConnect`, sensact `NotifyStatus`, fingerprint
`NotifyFingerDetected`/`NotifyEnrollNewFinger` – ueber ein gemerktes Member-Feld bzw.
`requestId=0` fuer echte Server-Pushes ohne zugehoerigen Request).

- **wifimanager**: `webmanager.hh` (inline, s.o.). `AccessPoint`-Liste jetzt ueber
  `AppendResponseNetworkInformationAccesspointsAccessPointElement` in einen Scratch-
  Puffer statt Flatbuffers-Vector. Nebenbei behobener Bug: `ap.rssi` wird jetzt
  tatsaechlich in `ResponseWifiConnect` geschrieben (vorher geholt, aber verworfen).
- **systeminfo**: `cpp/webmanager_plugins/systeminfo_plugin.hh`. `Mac6`/`PartitionInfo`
  ueber generierte Struct-/Class-Encode-Funktionen, `partitions`-Liste ueber
  `AppendResponseSystemDataPartitionsPartitionInfoElement`.
- **usersettings**: `cpp/webmanager_plugins/usersettings_plugin.hh`. Design-Aenderung
  im Schema selbst (bewusst, s. `best_binary_buffers_schema/usersettings.cs`-Kommentar): statt einer
  Flatbuffers-Union `Setting{Integer,Enum,Boolean,String}` jetzt 4 eigenstaendige
  getaggte Wrapper-Klassen (`IntegerSettingWrapper` etc.), decodiert per
  `DecodeRequestSetUserSettingsSettingsElements`-Visitor mit `if constexpr`-
  Typunterscheidung. `usersettings::Setting`-Enum (Flatbuffers) durch neues,
  protokoll-unabhaengiges `SettingKind`-Enum in `usersettings_plugin.hh` ersetzt;
  `usersettings/nvs_accessor.hh.inc` (generierte, aber nicht durch `builder`
  erzeugte Konfigurationsdatei unter `C:\repos\generated\usersettings\`) direkt
  angepasst. Client: `usersettings_runtime`-Paket (separates npm-Paket,
  `ConfigItemRT.WriteToFlatbufferBufferAndReturnSettingWrapperOffset`/
  `ReadFlatbuffersObjectAndSetValueInDom` → `BuildSettingsElement`/
  `ReadSettingsElementAndSetValueInDom`) mitmigriert.
- **scheduler**: `cpp/scheduler.hh` + `cpp/scheduler_timers.hh`. Polymorphe
  `Schedule`-Varianten (`Predefined`/`OneWeekIn15Minutes`/`SunRandom`) jetzt ueber
  `[BinaryUnion] IScheduleVariant` statt Flatbuffers-Union `uSchedule`. `aTimer`
  bekommt neue virtuelle Methoden `GetScheduleType()`/`EncodeScheduleVariant(...)`
  statt `FillListOfResponseSchedulerListItems`/`CreateFlatbufferScheduleOffset`; die
  5 Predefined-Singletons (`ALWAYS`/`NEVER`/...) teilen sich jetzt eine gemeinsame
  Basisklasse `aPredefinedTimer` (kleine, durch die Migration motivierte
  Konsolidierung). **NVS-Format wechselt ersatzlos** (Nutzer-Entscheidung: keine
  bestehenden Zeitplaene vorhanden, kein Migrations-/Kompat-Code fuer alte
  Flatbuffers-NVS-Blobs). `iScheduler::FillFlatbufferWithAvailableNames` →
  `FillAvailableScheduleNames(std::vector<std::string>&)` (protokoll-unabhaengig,
  betrifft auch den Aufrufer in `fingerprint_webmanager_sensact_adapter.hh`).
- **nodemaster**: `main/nodemaster.hh`. Kein TS-Consumer gefunden (in
  `web-components/typescript/`; s. aber "Zusaetzlich entdeckte Consumer" unten –
  `web/nodemaster_controller.ts` existiert doch und wurde ebenfalls migriert).
- **sensact**: `main/node_applicationhost.hh`/`.cc`. `NotifyStatus` (asynchroner
  Push aus `PublishApplicationStatus()`) nutzt `requestId=0`. Kein TS-Consumer in
  `web-components/typescript/` gefunden (s. aber "Zusaetzlich entdeckte Consumer" –
  `web-components-sensact/sensact_controller.ts` existiert und wurde migriert).
- **journal**: `main/journal_plugin.hh`. Singleton-Logging-Sink (`LogJournal`/
  `ResetJournal`, aufgerufen aus `main/logger.hh`/`nodemaster.hh`) bleibt
  namespace-agnostisch unangetastet, nur `ProvideWebsocketMessage` migriert.
- **fingerprint**: `main/fingerprint/fingerprint_webmanager_sensact_adapter.hh`.
  Komplexester Namespace (10 Request-/12 Response-Typen). Board-bedingt: nur auf
  `SNSCT_NODE_SIDEDOOR` tatsaechlich instanziiert.

### Zusaetzlich entdeckte Consumer (nicht im urspruenglichen TS-Consumer-Survey erfasst)

Eine erste Recherche hatte nur `web-components/typescript/` durchsucht und dabei
uebersehen, dass `nodemaster`/`sensact`/`canmonitor` **doch** TS-Consumer haben – nur
in anderen Paketen: `web/nodemaster_controller.ts` (im Firmware-Repo selbst),
`web-components-sensact/sensact_controller.ts` + `sensactapps_base.ts` (separates
Paket), `web-components-sensact/canmonitor_controller.ts` (canmonitor hat also einen
Client, obwohl es nie einen Server gab – der Client war/ist daher schon immer
funktionslos, aber musste trotzdem migriert werden, damit er weiter kompiliert).
Gefunden erst durch `tsc --noEmit` in `web/` (schlug zunaechst mit ca. 15 Fehlern in
4 Dateien fehl) – **Lektion**: bei TS-Consumer-Recherchen kuenftig immer das ganze
Monorepo durchsuchen, nicht nur ein einzelnes Paket, und/oder `tsc --noEmit` als
Verifikationsschritt nicht erst am Ende, sondern schon waehrend der Migration laufen
lassen. Alle 4 Dateien wurden nachtraeglich auf die neue `wsprotocol_ts`-API
umgestellt (inkl. `sensact-base/can_message_utils.ts`,
`application_id_utils.ts`, `interfaces.ts` und der generierten Vorlagen
`web/templates/sendCommandImplementation.template.ts`/`sensactapps.template.ts` in
`builder`), `tsc --noEmit` in `web/` laeuft jetzt fehlerfrei durch (Exit Code 0).

### Echter Bug gefunden und gefixt: Namespace-ID-Kollision

Die von `BestBinaryBuffers`' `IdMap` (alphabetisch bei Erstauftreten) automatisch
vergebenen neuen `NAMESPACE_ID`s kollidierten real mit den alten, **weiterhin aktiven**
Flatbuffers-`Namespace.Value`s der nicht migrierten Namespaces: neues `fingerprint`
(NAMESPACE_ID=3) kollidierte mit dem alten, weiterhin von `functionblock` benutzten
Wert 3. Da `AppController` nach der Migration nur noch EINE Dispatch-Map hat (per
Absicht, s.o.), haette das dazu gefuehrt, dass `FingerprintScreenController` und
`DevelopCFCController` (functionblock) sich gegenseitig Nachrichten "gestohlen"
haetten. Behoben durch manuelle Korrektur in `best_binary_buffers_schema/ids.txt`
(`namespace fingerprint 3` → `namespace fingerprint 13`, einmalig vertretbar, da
diese ID nie ausgeliefert wurde) und Neu-Generierung via
`dotnet run -- GenerateWsProtocolFiles`. **Wichtig fuer zukuenftige Migrationen**:
vor jeder weiteren Namespace-Migration pruefen, ob die neue `NAMESPACE_ID` mit einem
noch aktiven alten Flatbuffers-`Namespace.Value` kollidiert (aktuell noch aktiv:
functionblock=3, heaterexperiment=4 im alten Schema).

### Betroffene Dateien (Gesamtuebersicht)

**`espidf-component-webmanager`**: `cpp/webmanager_interfaces.hh`,
`cpp/webmanager_async_response.hh`, `cpp/webmanager.hh`, `cpp/webmanager_constants.hh`,
`cpp/webmanager_plugins/systeminfo_plugin.hh`,
`cpp/webmanager_plugins/usersettings_plugin.hh`, `cpp/scheduler.hh`,
`cpp/scheduler_timers.hh`.

**`sensact_firmware`**: `main/main.cc`, `main/nodemaster.hh`,
`main/node_applicationhost.hh`/`.cc`, `main/journal_plugin.hh`,
`main/fingerprint/fingerprint_webmanager_sensact_adapter.hh`, `web/vite.config.mts`,
`web/nodemaster_controller.ts`, `web/templates/sendCommandImplementation.template.ts`,
`web/templates/sensactapps.template.ts`, `builder/Phases/GenerateWsProtocolFiles.cs`
(package.json-Generierung fuer `@generated/wsprotocol_ts` ergaenzt),
`builder/Phases/GenerateSensactFiles.cs` (Abhaengigkeiten umgestellt),
`best_binary_buffers_schema/ids.txt` (Kollisionsfix).

**`npm-packages`**: `@klaus-liebler/web-components/typescript/utils/interfaces.ts`,
`.../screen_controller/screen_controller.ts`, `.../app_controller.ts`,
`.../screen_controller/wifimanager_controller.ts`,
`.../screen_controller/systeminfo_controller.ts`,
`.../screen_controller/usersettings_controller.ts`,
`.../screen_controller/scheduler_controller.ts`,
`.../screen_controller/journal_controller.ts`,
`.../screen_controller/fingerprint_controller.ts`,
`.../flowchart/Flowchart.ts` + `.../screen_controller/develop_cfc_controller.ts`
(mechanisch angepasst, s.o.),
`.../screen_controller/heater_experiment_controller.ts` (mechanisch angepasst),
`@klaus-liebler/usersettings_runtime/index.ts`,
`@klaus-liebler/sensact-base/{can_message_utils,application_id_utils,interfaces}.ts`,
`@klaus-liebler/web-components-sensact/{canmonitor_controller,sensact_controller,
sensactapps_base}.ts`, sowie diverse `package.json`-Anpassungen (Abhaengigkeit von
`@generated/flatbuffers_ts` auf `@generated/wsprotocol_ts` umgestellt).

**Neu**: `C:\repos\generated\wsprotocol_ts\package.json` (macht `wsprotocol_ts` als
npm-Paket konsumierbar, analog zu `flatbuffers_ts`).

Kein Code-Change in `builder/ModelGeneration/` noetig.

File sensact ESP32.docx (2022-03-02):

# Konzept ESP32-sensact

# Begriffe

- Sensact = Sensor-Actor; der Projektname
- App = Ein Funktionsblock-artiges Softwareobjekt, das eine bestimmte Funktion wahrnimmt. Bekommt eine eindeutige u16-AppId innerhalb der Domain (s.u.). Einige AppId sind reserviert für NodeApps (s.u.)
- Node = Eine Hardwarebaustein, auf dem die sensact-Software läuft. Jede Node hat eine eindeutige u16-NodeId innerhalb einer Domain.
- NodeApp = Auf jeder Node läuft eine spezielle App, die NodeApp. Deren AppId entspricht der NodeId. Über diese App kann die Node als solche angesprochen werden, um beispielsweise Outputs zu setzen oder Inputs abzufragen
- Segment = ein Zusammenschluss mehrerer Nodes, die an einem gemeinsamen CAN-Bus hängen und die darüber einen gemeinsamen MessageBus unterhalten.
- Domain = ein komplettes Sensact-System, bestehen aus einem oder mehreren Segmenten. Innerhalb einer Domain ist die ID einer App und einer Node eindeutig
- Indizes sind in der Regel u16-Werte. Ein Index 0 hat KEINE spezielle Bedeutung! Ein hoher Indexwert als „magic number“ kann eine spezielle Bedeutung haben. Alle „magic numbers“ müssen in common.hh definiert werden

# Konzepte der Funktionsweise

Auf jeder Node laufen diverse Apps. Sie sind lose gekoppelt und kommunizieren durch Nachrichten miteinander.

### Variante 1: Nur eine Nachrichtenklasse „Event

Eine Nachricht geht an eine bestimmte ID und hat einen bestimmten Nachrichtentyp. JEDE Nachricht wird auf den lokalen und MessageBus gelegt und ist damit von allen Nodes im Segment empfangbar

### Variante 2: Zwei Nachrichtenklassen „Event“ und „Command“

mit den Nachrichten „Command“ und „Event“ miteinander. Ein Command ist dabei FÜR eine bestimmte App bestimmt „Du, Kellerleuchte 1, schalte dich ein!“. Demgegenüber informiert ein Event über ein Ereignis einer App „Ich, Lichtschalter 42, informiere darüber, dass ich gedrückt wurde – und zwar alle, die es interessiert“. Jeder App steht es frei, die Rollen EventEmitter, EventReceiver, CommandEmitter und CommandReceiver zu implementieren. „Alles kann, nichts muss“ lautet die Devise. Commands und Events werden über den sog. Message Bus verteilt. Dieser verteilt sowohl Nachrichten Node-intern, als auch über den CAN-Bus an alle anderen Nodes

## Konzept einer „Node“

Eine Node hat eine u16ID > 0, ist der Host für Apps und stellt physische Inputs und Outputs zur Verfügung.

# Konzept Inputs und Outputs

Jeder Input und jeder Output wird über eine 16bit ID angesprochen und liefert/erwartet einen 16bit-Wert. Inputs und Outputs leben im gleichen Namensraum. Es gibt also keinen Input mit der gleichen ID wie ein Output.

Die Inputs werden auf verschiedene Busse aufgeteilt. Von der 16bit ID werden die 2 MSB für die Auswahl des Busses verwendet. Es gibt die folgenden Bus-Typen

- DirectGPIO, also direkte GPIOs
- I2C
- CAN

Es gilt:

- 0b00 ist immer INTERNAL
- 0b11 ist immer CAN-Bus

Innerhalb des Busses können also 14bit frei verteilt / zugeordnet werden.

## Implementierungsstufe 1: Synchrones Abfragen und Setzen aller InOuts

Insbesondere der I2C-Bus läuft nicht in einem eigenen Task. In der Input-Phase werden alle konfigurierten I2C-Geräte abgefrage. In der Output-Phase wird auf alle I2C-Geräte geschrieben, bei denen es eine Änderung gab

Die Busse laufen in eigenen Tasks. Ihre Aufgabe ist es, effizient das in Ihnen intern gespeicherte Prozessabbild zu aktualisieren. Während des Loops darf aber keine Aktualisierung erfolgen.

## Implementierungsstufe 2: Asynchronität

Die Busse laufen in einer eigenen Task. Für Inputs gilt: Jeder Treiber verwaltet intern in einem Staging den neu hergeholten Wert. Ein CommitInputs-Aufruf sorgt dafür, dass die Werte von Scratchpad auf „WhitePaper“ geschrieben werden und dann für Apps zur Verfügung stehen. Dieses Umschreiben – und das ist entscheidend – findet nur beim Commit statt. Aufgabe des Nodemasters ist es deshalb, just vor dem App-Loop die ganzen Commits aufzurufen – über den Busmaster.

Umgekehrt können bei den Outputs die Apps erst in einen Staging-Bereich schreiben. Ein CommitOutputs sorgt dann dafür, dass die Werte möglichst effizinent an die Hardware rausgeschrieben wird. Wenn CommitOutputs zurück kehrt, müssen die Outputs nicht zwingend voll geschrieben sein, aber der Anstoß zum Schreiben muss unumkehrbar sein

## DirectGPIO

STM32: PA0 = 0, PA15=15, PB0=16, PB15=31 etc.

ESP32: GPIO-num

Beim Internal-Bus, finden sich auch die folgenden MAGIC-Numbers

Die ID 0x3FFF steht für einen Input mit dauerhaft 1 (letzte Bits sind 1 (wie I=input)-1)

Die ID 0x3FFE steht für einen Input mit dauerhaft 0 (letzte Bits sind 1 (wie I=input)-0)

Die ID 0x3FFC steht für einen unbeschalteten Output

## I2C-Bus.

- Problem: Über I2c können Subbusse bspw über DS2482-OneWire, implementiert werden
- Array mit 16 Einträgen fix (NULL zulässig). Erster Eintrag ist fest auf I2CMainBus eingestellt. Die anderen Einträge können (!) OneWireSubbus-Member enthalten
- Jeder Busmaster verwaltet eine Liste von InOut16-Membern (PCA9555, PCA9685, BME280/680). Am I2C können maximal 64 solche Member hängen. Dadurch kommen 32*16=1024InOuts zusammen.
- Jeder Busmaster verwaltet eine Liste mit maximal 15 Subbussen(derzeit nur OneWire via Ds2482), Jeder Subbus bekommt auch 1024 InOuts, also 1024-2047, 2048-...
  - Offsets für OneWire-Subbusse mit dem DS2482
  - Subbus verwaltet eine Liste (max 96 Einträge) von sensactSE-Devices (ein Device hat 8 InOuts), also 768 InOuts
  - Subbus verwaltet eine Lists (max 128 Einträge) von DS2413-Devices (ein Device hat 2 InOuts) also 256 InOuts

## CAN-Bus

Auch über den CAN-Bus können Ios verteilt werden

- Wenn eine Node die IOHost-Rolle implementiert, dann kann über ihre NodeApp (AppId entspricht NodeId!) auf die Ein-und Ausgänge zugegriffen werden. Die NodeIds sollten sich im Bereich 0…64 bewegen. Jeder IOHost kann dann IO 0…255 haben.

## Konfigurierbare Ein- und Ausgänge

Bestimmte physische Pins können sowohl als Eingang als auch als Ausgang fungieren. Direkt nach dem Start führt eine Node eine Konfigurationsprogramm aus, in dem alle Pins (sowohl die CPU-Pins als auch I2C-Pins als auch Funk-Pins als auch Wifi-Pins als auch CAN-Pins, aber eben nur solche in Verantwortung der Node…) durchkonfiguriert werden. Vor der Konfiguration sollen alle Pins bevorzugt hochohmig bzw im inaktiven Zustand sein („0“ bzw. Transistor nicht durchgeschaltet / Relais nicht angezogen). Konfigurierbare Inputs/Outputs kommen sowohl im Input- als auch im Output-Indexraum vor und müssen einen identischen Index haben

Ein nicht vorhandener Input liefert 0. Auch die Anfrage eines nicht als Input konfigurierten Index liefert 0.

## Technische Realisierung von Outputs

- Transistor-Outputs an Port-Pins (beim ESP32 bitte immer PWM-fähig)
- Als Port-Expander am I2C
- Als Port-Expander am 1Wire
- Als per CAN angeschlossenes Device, das mit CAN-Messages in einem speziellen InOut-Namespace angesprochen werden kann. Weil derartige Outputs (ebenso die Inputs) letztlich jeder Node zur Verfügung stehen, müssen dafür bei den u16-Indices für Inputs und Outputs einige frei gehalten werden

## Technische Realisierung von Inputs

Technisch können Eingänge direkt über PortPINs der CPU realisiert werden. Alternativ

- I2C-Port-expander
- Fernbedienungen

## Aufteilung der Input- und Output-Namespaces

Letztendlich steht es in der Verantwortung der Node, die von ihr verwalteten Ios in den beiden u16-Namespaces zu organisieren. Empfohlen wird die folgende Aufteilung:

- Grundsätzlich 64 Blöcke a 1024 Indices (also: Ein kleinerer Block als 1024 wird nicht vergeben)
- 0 ist der NULL-Output
- Block 0( 1-1023) sind GPIO-Pins
- Block 1 bis 17 sind für 16 angeschlossene I2C-Devices
- Block 64 sind CAN-IOs

## Verhalten von Ausgängen

Es gibt binäre, analoge und PWM-Outputs. Ein binärer Output schaltet (voll) ein, wenn der Wert !=0 ist. Ein PWM-Output liefert dann nur ein 1/65535-PWM. Um auch mit PWM-Signalen binäre Ausgänge nachahmen zu können, sollte ein Ausgabebefehl bspw für ein Relais immer UINT16_MAX als Wert setzen.

# Application

Eine App ist ein Softwareobjekt, das eine bestimmte fachliche Funktionalität mit Bezug zur Gebäudeautomation wahrnimmt. Beispielsweise sind „Taster Wohnzimmer 1“ oder „Rolladen Küche 2“ oder „Beleuchtung Kellerraum 1“ solche Apps. Eine App „lebt“ auf einer Node.

Jede App hat eine systemweit eindeutige ID. Über diese ID kann die App im System Events publizieren bzw. auf Commands reagieren.

## Blind-App

- Gegenwärtige Postion wird in einer s32-Variable „estimatedPosition“ gespeichert
- App kennt Command zum Verfahren auf eine Position und zum kompletten Öffnen und Schließen.
- SAFE_CLOSE=10%, FULL_CLOSED= 25%, FULL_OPEN=75%, SAFE_OPEN=90% des Variablen-Maximalwertes
- App kennt die Zeiten zum kompletten Öffnen und kompletten Schließen des Rollos. Daraus wird ein „millistepsUp“ und „millistepsDown“ ausgerechnet. In der angegebenen Zeit geht der Rollo von FULL_CLOSED nach FULL_OPEN.
- Ein externer Positionswunsch 0…100% wird auf intern 25…75% abgebildet *0,5+0,25
- Ein externer Schließen-Wunsch wird intern auf „10%“ abgebildet
- Ein externer Öffnen-Wunsch wird intern auf 90% abgebildet.
- Ein externer Stopp-Wunsch wird auf einen internen Stopp-Wunsch abgebildet
- Ein interner Stopp-Wunsch stoppt die Motoren und macht 25%<=pos<=75%
- In der Loop wird geprüft, ob und in welche Richtung der Motor läuft. Es wird entsprechend die millistepsUp/Down auf die Position drauf gerechnet. Der Motor wird – je nach Richtung – gestoppt, wenn die estimatedPosition kleiner bzw größer ist, als der Zielwert
- requestedState={STOP,DOWN,UP}, requestedPosition=u32. Diese requested-Values werden gesetzt, wenn ein Command kommt. Ob up oder down, wird über die currentPositions festgelegt. Das Command wird nur angenommen, wenn die currentPos von der requestedPos signifikant abweicht (einen Motorlauf von >1sek erfordern würde)
- Wenn requestedState=STOP, wird die requestedPosition nicht weiter beachtet
- Wenn das Command gesendet wird, dann wird festgestellt, ob

# Code-Generierung

- Wird aktuell schon ganz gut gemacht
- Nutze dictionary intensiver!!!
- Generiere C++Code
- Die Code-Generierung soll minimal sein und möglichst keine festen Abschnitte umfassen. Deshalb werden mehrere kleine Dateien erzeugt, die im Template an verschiedenen Stellen eingebunden werden.
- Damit der Code compilierbar ist, auch wenn die Dateien noch nicht erzeugt wurden (wenn es nicht verfügbar ist, zumindest #warning ausgeben:

// Note the two possible file name string formats.

#if __has_include("myinclude.h") && __has_include(<stdint.h>)

# include "myinclude.h"

#endif

- Templates sollen auch ohne generierten Code syntaktisch korrekt sein
- Generierte Dateien haben die Endung .gen.hh bzw .gen.cc (bisher: inc), um klar zu machen, um was für Dateien es sich handelt

# CAN-Bus-Kommunikation

- 125kbits CAN-Bus
- ExtendedID mit 29bits, 5bit Namespace, dann 24bit namespace-spezifisch
  - NodeEvent = 0x00000000,
  - AppEvent= 0x01000000, AppEvents. 16bit EventEmitterID, 8 bit EventType
  - NodeCommand = 0x02000000,
  - NodeCommandAcknowledge= 0x03000000,
  - ApplicationCommand= 0x04000000, 16bit CommandTargetID, 8 bit CommandType
  - CommandAcknowledge= 0x05000000,
  - ApplicationStatus = 0x06000000,
  - Payload = 0x1F000000,
  - Namespace 0b00001
- Modi
  - Wie bisher: Wenn möglich, Dinge komplett lokal bearbeiten und nicht auf den Bus geben
  - Alle Events auf den Bus geben
  - SensactUP-Nodes sind „dumm“. Sie senden alle Aktivitäten des Nutzers an eine Zentrale. Diese verarbeitet, entscheidet und sendet dann wiederum Commands an Aktoren
  - Wie zuvor, allerdings ist die Zentrale ein per MQTT angebundener PC

## Namespace Events 0b00000

- EventID besteht aus EventEmitterID (16bit, wer sendet es weg) und EventType (8bit, was ist dort passiert).
- Ein Event kann außerdem noch bis zu 8 Byte Nutzdaten transportieren
- EmitterID=0 bedeutet: Event kommt von der Management-Ebene
- EventType=0 bedeutet: Unspezifiziertes Event vom Sender
- EventType 0xFF bedeutet: Dem Empfänger ist es egal, welches konkrete Event gesendet wird. Der Empfänger reagiert damit auf alle Events gleichermaßen
- Event Emitter sind
  - „ButtonSensor“ mit Press, Hold (wenn sicher ist, dass es kein ShortPress ist), ReleaseShort (auch wenn danach ein DoubleClick kommt), ReleaseLong, DoubleClick (DoubleClick hat zuvor einen ReleaseShort, aber dann kein Press und ReleaseShort mehr) (Prinzip: Events werden zum frühestmöglichen Zeitpunkt gesendet)
    - Was wird da gegenwärtig überhaupt gebraucht?, insbesondere für den SingleButton-Dimmer und den SingleButtonBlinds
  - „ButtonSensor“ remote mit Press und Hold
  - RotarySensor mit TurnLeft, TurnRight, Press
  - JogDial (sowohl rund als auch gerade) mit ValueSelected und dem aktuellen Wert
  - PWMLightingActor mit OnTriggerHeartbeat
- EventReceiver sind
  - BlindsActor kennen eine Liste ihrer „Up“-ButtonSensors und ihrer „Down“-ButtonSensors. SingleControl-Buttons gibt es da nicht
  - PWMLightingActor kennen die Liste der Ups, der Downs, der SingleControls und der RotarySensors. Ein derartiger Actor ist für die kompletten LEDs eines Raumbereichs zuständig (nicht: jeder Spot hat eine eigene App)
  - BinaryActor kennt Toggles, Ons, Offs, Heartbeats
  - SoundActor hat eine Map EventId→Song-Index

# Special-Hardware

- Lampe in Klaus Arbeitszimmer →10V PWM
- Fingerprint →Potentialfreier Kontakt
- Klingel →Taster
- RGB-LEDs in den Bädern: 12V-LEDs, gemeinsame Kathode (mit zusätzlichem Vorwiderstand einfach an 24V)

# Software-Architektur

## Rollen

Alle Nodes, die über den CAN-Bus miteinander kommunizieren, erhalten eine Software, die dem im folgenden beschriebenen Architekturkonzept entspricht. Eine Node kann die folgenden Rollen (auch parallel) übernehmen

- Gateway: Führt Apps aus und bündelt sammelt alle Status- und Event-Infos im CAN-Netzwerk zusammen, um diese per MQTT weiter zu tragen. Leitet auch Infos aus MQTT in den CAN-Bus ein. Es muss im Netzwerk genau eine Node geben, die diese Rolle übernimmt.
- UserInterface:
- ApplicationHost: Führt Apps aus
- IOHost: Führt keine Apps aus, sondern verbindet nur „low-level“ physische Ein- und Ausgänge mit dem CAN-Bus

## Softwareobjekte und deren Verantwortlichkeiten

Frage: Nutzt HAL den Nodemaster oder nutzt Nodemaster den HAL? →Letzteres!

- Main.cc
  - StartUp und grundlegende Konfiguration
  - Einmalige Ausführung des FirmwareUpdate-Prozesses beim Start
  - Start aller Tasks
- Updater.cc
  - Prüft regelmäßig oder explizit auf Befehl, ob eine aktualisierte Firmware vorliegt. Wenn ja, dann werden alle Tasks (Handle auf alle Tasks wird bei der Initialisierung übergeben) beendet und der Update-Zyklus ausgeführt
- HAL.cc
  - Unterste Hardware-Abstraktionsebene; greift auf nichts zu, sondern wird genutzt
  - Eine „Loop1ms“-Methode und eine „LoopTick“-Methode
  - Methoden zum Lesen oder Schreiben von GPIO-basierten u16-Inputs/Outputs
    - Auch ein möglicherweise angeschlossener Rotary-Encoder soll als u16-Input umgesetzt werden
    - Auch eine möglicherweise verbundene Fernbedienung soll als u16-Input umgesetzt werden
  - Methoden zum Zugriff auf I2C (synchron!, schöne Schnittmenge aus der STM32-HAL und „meiner“ I2C-Bibliothek für den ESP32
  - RGB-LED SetColor(ledId, CRGB color)
  - Sound: PlaySound(soundId), StopSound(), SetSoundVolume(u16)
  - Methoden zum Zugriff auf CAN (Gepuffert!)
  - Zugriff auf ein Display? →NEIN, das muss separat gemacht werden
- Busmaster
  - Mittlere Abstraktionsebene
  - Gibt es in den Varianten LocalGPIO, I2C und CAN
  - Nutzt HAL für den Zugriff
  - Ist dafür verantwortlich, das Prozessabbild eines Busses zu aktualisieren
  - Jeder Busmaster startet seinen eigenen Task, in dem permanent das Prozessabbild aktualisiert wird.
  - Jeder Busmaster verwaltet seine Ios über Treiber-Objekte, die mit dem am Bus angeschlossenen Gerät kommunizieren können und auch dessen Daten cachen
- Nodemaster
  - Oberste Abstraktionsebene
  - Kennt die Rollen der Node und handelt entsprechend
  - Grundlage der Funktionsweise ist ein klassischer 3phasiger AS-Zyklus
  - Wenn Rolle APPLICATION_HOST: Sie kennt alle Apps und führt die unendliche Schleife aus. Sie erzeugt ein HAL-Objekt und gibt allen Apps darüber Zugriff auf die Hardware. Für den Zugriff auf lokal verwaltete Inputs oder Outputs erzeugt Sie InputOutputRangeManager. Ein solcher stellt der Node für einen bestimmten Bereich im I-O-Indexraum Inputs und Outputs zur Verfügung. Ein IndexRange ist mind. 1024 Elemente groß. Node weiß für jeden Bereich, welcher Manager dafür vorgesehen ist. Jeder IoRangeManager hat die Lebenszyklusmethoden
- Init (beim Start des Systems)
- ReInit ? (zum Zurücksetzen, nach irgendwelchen Fehlern)
- Phase1_UpdateInputs()
- Phase3_UpdateOutputs()

Schreib- und Lesezugriffe werden direkt auf den IoRangeManager durchgeleitet. Durch die interne Konstruktion ist aber sicher gestellt, dass Ins und Outs frühestens beim Aufruf der entsprechenden Lebenszyklusmethode aktualisiert / für die Aktualisierung freigegeben werden

Alle Inputs und alle Outputs werden von einem IoMananger verwaltet. Ein IoManager

Ein LocalBus (incl. LocalSubbus) bindet IO-Baugruppen in den Input und Output-Indexraum ein. Bei de

## Tasks

- Sensor-Task holt sich die Messwerte der I2C und 1Wire-Sensoren
- PLC-Task agiert im 50ms-Zyklus

## Funktionalität des HAL

- „Rohzugriff“ auf I2C für die Enumeration und Konfiguration der Geräte
- Zugriff auf per u16 identifizierte Binäre/Analoge/Digitale Inputs und Outputs. Die Werte sind auch u16
- Zugriff auf den MessageBus als zentrales Kommunikationsvehikel
- KEINE Funktionalität ist:
  - Logging! Das Programmieren wir für den ESP-IDF alles um

Frage: Können diese „Spezialitäten“ über das Prinzip „u16-Input/Output“ oder „MessageBus“ an einen „SubsystemControl“-Namespace realisiert werden?

## Hardware-Konfiguration

Neben der Hardware (Hutschiene, Unterputz, Outdoor) und ihrer Version unterscheiden sich die Nodes durch die angeschlossene Hardware. Um welche Hardware handelt es sich? Kann diese durch Enumeration erkannt und in Betrieb genommen werden?

Typ der Geräte kann grundsätzlich mal über ihre I2C- bzw. OneWire Adresse erkannt werden. Aber: Einige dieser Geräte müssen konfiguriert werden und es muss klar sein, wie diese zu konfigurieren sind:

Alternative: Geräte kennen selbst Ihre Konfiguration und stellen diese dem Busmaster zur Verfügung? Nein, das kann nicht immer gefordert werden, weil „dumme“ Geräte ihre eigene Konfiguration nicht speichern können.

Es muss neben den sensact-Gerät-spezifischen generierten Dateien auch spezifisch programmierte Dateien geben, in denen dann die Konfiguration als Programmcode abgelegt wird . Ganz klassisch: Es handelt sich um eine Klasse, die von AbstractNodeHardwareConfiguration ableitet und eine noch zu definierende Menge an Funktionen für die verschiedenen Konfigurationsdomänen implementiert.

### Konfigurationsdomänen

- Konfiguration lokaler Ios
- Konfiguration 1Wire-Geräte
- Konfiguration der I2C-Geräte an ggf. mehreren Bussen
  - Enumeration aller Adressen
  - Map definiert, welche Befehle für welche Adresse zu senden sind
  - Fehler, falls ein in der Map definiertes Gerät fehlt bzw. ein Gerät gefunden wird, für das es keine Konfigurationseinstellungen gibt.
  - Zuordnung von InputIDs oder OutputIDs zu den Geräten
- Konfiguration Wifi: SSID und Passwort
- Konfiguration Ethernet: prüfe den Code, der da üblicherweise zur IP-Konfiguration benötigt wird
- Konfiguration CAN ist fix; keine individuelle Konfiguration erforderlic
- Konfiguration sonstiger lokal angeschlossener Peripherie
  - RS485 für Garagentor
  - eBus für Lüftung
  - Sound-Ausgabe
  - Lokale Sensoren, die mit I2C- oder 1Wire angeschlossen sind
  - RotaryEncoder
  - RGB-LED (die per Protokoll und nicht per 3xPWM angeschlossen wird)
  - Display
  - Funkempfänger Milight
- In der bisherigen Logik wurde das durch enum class realisiert enum class Mp3Cfg{NONE, INTERNAL_MP3_I2S, UART4_PA00_PA01_StandbyPE02, }; und es musste dann jede Möglichkeit im Quellcode berücksichtigt werden. Die enum musste als Template-Parameter gesetzt werden. In der main.cpp wurde dann eine Instanz der „richtigen“ Templates erzeugt →die Main.cpp muss dann entweder „ifdefs“ enthalten oder für jede Node individuell existieren…

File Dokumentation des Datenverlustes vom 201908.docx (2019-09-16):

# Sattlerstraße 16.cs

Zeile 206: Weshalb auskommentiert?

# Anlegen eines neuen Projektes

File -> New --> C++ Managed Build

Projektnamen angeben, "STM32F0xx C/C++ Project" auswählen

Bei "Chip Family" den Wert STM32F072 auswählen, "Content"="Empty", "Use System Calls" = "Freestanding"

Durchbestätigen

Bei "Toolchain Path" den Pfad "C:\stm32\gcc20190214\bin" (oder neuere Version) angeben

Nun das Projekt überarbeiten:

Aus Ordner "system" alle Unterordner rauslöschen

Rechtsklick auf Ordner-->New-->File: Link to file in the file system: {CUBE}/CMSIS/Device/ST/STM32F0xx/Source/Templates/system_stm32f0xx.c

Rechtsklick auf Ordner-->New-->File: Link to file in the file system: {CUBE}/CMSIS/Device/ST/STM32F0xx/Source/Templates/gcc/startup_stm32f072xb.asm (Achtung: Das dort vorhandene .asm-File vorher in .asm kopieren)

Aus Ordner include die conf-datei löschen und dann die Datei stm32f0xx_hal_conf.h und stm32_assert.h einkopieren

Ordner ldscripts löschen

Rechtsklick auf Projekt --> Properties -->C/C++ General -->Paths and Symbols -->Source Location -->Link Folder -->Link to Folder in the file system --> {CUBE}\Drivers\STM32F0xx_HAL_Driver\Src

In diesem Ordner alle .Template-Dateien auswählen, Rechtsklick -> Resource Configuration -> Exclude from Build (für alle Configs)

Rechtsklick auf Projekt --> Properties -->C/C++ General -->Paths and Symbols --> Includes

Für alle Languages alle inlcudes-Directories (außer das "include" im Projekt) löschen und dann hinzufügen (anhaken: Add to all configurations/languages"!)

{CUBE}\Drivers\STM32F1xx_HAL_Driver\Inc

{CUBE}\Drivers\CMSIS\Device\ST\STM32F1xx\Include

{CUBE}\Drivers\CMSIS\Include

Rechtsklick auf Projekt --> Properties -->C/C++ General -->Paths and Symbols --> Symbols

USE_STDPERIPH_DRIVER löschen

Hinzufügen: USE_HAL_DRIVER

Hinzufügen: USE_FULL_LL_DRIVER

Hinzufügen STM32F072xB

Rechtsklick auf Projekt --> Properties -->C/C++ Build -->Settings --> Tool Settings --> GNU ARM Cross C++ Linker --> General

- vorhandene Script-Files alle löschen

- Beispielsweise das {Cube}\Projects\STM32F072B-Discovery\Templates\SW4STM32\STM32F072B-Discovery\STM32F072RBTx_FLASH.ld einbinden.

- Haken bei "do not use start files rausnehmen"

# Hal_conf.h

#define LAN8720_PHY_ADDRESS 0x01U

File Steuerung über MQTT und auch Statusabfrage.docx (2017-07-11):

# Nummerierung der Outputs und der Inputs

es werden

- 64 pca9685 (Beginn ab 1b1000 0000, Ausnahme 1110 000X)
- 8 pca9555 (Beginn ab 1b0100 0000)
- 4 DS2482 (Beginn ab 1b0011 0000)

vorgesehen

diese werden zu beginn abgesucht und konfiguriert

Outputs, egal ob PWM oder on/off gehen stets über pca9685.

Es existieren also maximal 64*16 = 1024 Outputs und 8*16=128 Inputs.

Inputs und Outputs werden über einen uint16 definiert, wobei für den Output die untersten 10bit und für den Input die

untersten 7 bit rausgeschnitten werden. Dann wird die zahl um 4 bit nach rechts geschoben, um die Adresse des Chips zu bekommen.

Outputs und Inputs mit gesetztem ersten MSB (>0x8000) werden als "stm32-Intern" betrachtet und sind dann eben nach außen geführte Kontakte

BlockOnDoubleRegister wird gelöscht. Die Erkennung von Doppelregistrierungen findet zur Codeerzeugungszeit statt.

Die Unterscheidung zwischen PWM und nicht-PWM-Output fällt weg - Alles wird gleich behandelt. Ein technisch nicht-pwm-fähiger Ausgang schaltet voll durch, wenn das PWM-Niveau > 0 ist.

Der Treiber für PCS9685 und PCA9555 muss dahingehend geändert werden, dass der Chip bei allen Funktionen als Parameter übergeben wird und nicht ab Objekt gespeichert ist. Wegen der SharedIRQ-Lines muss auch das IRQ-Handling rausgenommen werden.

# Steuerung über MQTT und auch Statusabfrage

MasterNode hält immer den aktuellen Status jeder Applikation. Der Status der Applikationen auf den SlaveNodes ist mit der MasterNode zu synchronisieren. Jede Node sendet deshalb den Status ihrer Applikationen regelmäßig und bei Veränderungen sofort auf den CAN-Bus

Regelmäßig: Wann immer die Node eine „runde“ Laufzeit seit ihrem Start erreicht hat und sie in der letzten Zeit keine Nachrichten auf den Bus gelegt hat, sendet sie von der nächsten Applikation den Status. Immer schreibt CallMeRegularly den aktuellen Status ihrer Applikation in einen ihr übergebenen Buffer und die Länge in einen ihr übergebenen size_t pointer. Auch der Status der Node selbst wird regelmäßig von der Node publiziert (u32 errno und u8[0] mit Busfehler-Zählern, Busse sind i2c1, i2c2, ow1/lin1, ow2/lin2

Der Status muss in ein u64 passen, weil er über den CAN-Bus transportiert wird. Ein u64 muss ausreichen, um den Status zumindest für die Visualisierung zu definieren. Der Status kann nie vom Master in die Node geschrieben werden. Hierfür sind stets Commands zu verwenden.

Jede Applikation bekommt eine GetStatus und eine SetStatus-Methode.

GetStatus erwartet einen Buffer mit einer Mindestlänge von 64byte, u32-Aligned. Er kann diesen Puffer vollschreiben mit seinem Status und gibt die Anzahl der geschriebenen Bytes zurück

SetStatus erwartet einen Buffer mit einer Länge, die von der Applikation abhängig ist. SetStatus liest diesen Puffer und sorgt dafür, dass der Status richtig gesetzt wird. SetStatus führt bei der Abarbeitung Prüfungen, insbesondere die Länge, durch. Wenn etwas „faul“ ist, wird der Status nicht gesetzt

Zunächst soll der Status immer in 8byte reinpassen.

Bei jedem Start einer Applikation muss diese ihren Status von der MasterNode holen. Ein Neustart der Masternode wird per Event kommuniziert und lässt jede Node so verhalten, als ob sie selbst gerade gestartet wurde. Jede Node erfragt also für jede ihre Applikationen den Status und setzt dann den Status in der Applikation. Eine kleine Besonderheit gibt es: Damit sich die Nachrichten auf dem CAN-Bus nicht überlagern, werden die Abfragen leicht verzögert gemacht.

Jede Node hat also Funktion SetAllApplicationStati(bool triggeredThroughMasterNodeStartup). Diese wird mit „false“ beim eigenen Hochfahren und mit „true“ beim Event „MASTER_NODE_STARTED“ aufgerufen.

Intern iteriert die Funktion über alle Applications, sendet ein SET_MY_STATUS(applicationId) aus und wartet so lange immer wieder (!) 200ms, bis die richtige Nachricht kommt. Sofern es hier einen Timeout gibt, springt die Node zur nächsten Applikation.

Die Master-Node sendet nach dem Hochfahren das „MASTER_NODE_STARTED“-Event aus. Eintreffende SET_MY _STATUS-Commands werden mit SET_STATUS-Commands an die Applikation beantwortet, wobei der Master die Daten hierfür aus seinem Speicher nimmt.

Ein Hauptknoten – der auch die MQTT-Anbindung hat - verwaltet auch die Statuspakete zu jeder Applikation. Nur er kennt auch die Namen jeder Applikation. Alle anderen Nodes kennen weder Namen noch Statusinformationen der anderen. Beim Start fragt der Masterknoten alle ihm bekannten Applikationen nach ihrem Status per CAN-Bus. Die die Applikation hostende Node überführt die CAN-BUS-Anfrage in einen Aufruf der GetStatus-Funktion. Die Antwort besteht ggf aus mehreren Nachrichten wenn der Status länger als 8byte ist). In der Nachricht ist deshalb codiert, wie viele Nachrichten nach der aktuellen noch gesendet werden. Die Masternode kann sich dementsprechend für jede Node Speicher auf dem Heap allokieren und die Statusinfo abspeichern. (Problem: Was passiert, wenn eine Node neu geflashed wird und neue Applikationen hinzu kommen bzw wenn eine Applikation auf einmal mehr Speicher benötigt -> Neben dem Pointer auf den Status-Payload speichert die Mainnode auch ein Info-Objekt [Time_t lastUpdate, size_t length]. Die lenght wird immer abgeglichen mit dem, was die Node sendet. Beim Hochfahren fragt die Masternode immer alle Applikationen ab. Beim Hochfahren erfragen normale Nodes immer ihren Status bei der Master-Node. Sobald der Status durch eine andere Art als SetStatus akt

Wenn eine CAN-Nachricht „STATUS_CHANGED“ am Bus anliegt, dass liest die MasterNode diese und aktualisiert ihr StatusObjekt auf binärer Ebene (über einen u8-Pointer)

Wenn ein CAN-Nachricht „CHANGE_STATUS“ am Bus anliegt, wird diese der Applikation nicht als „normales“ Command übergeben, sondern: Bei jedem CallMeRegularly bekommt die Applikation einen pointer auf einen Buffer und einen Pointer auf einen size_t. Hiermit werden neue Statusinfos in die Applikation hineingeschrieben. Außerdem kann die Applikation den Buffer und den size_t verwenden, um ggf. den neuen Status zurückzugeben.

Bei jedem Statuswechsel legt die Node den neuen Status auf den CAN-Bus. Die Masternode kann diesen Status abgreifen und abspeichern. Jede Veränderung des Status leitet der Masternode auch an das MQTT-Topic „Sensact::StatusChanged“ weiter. Die Masternode kann die folgenden MQTT-Nachrichten empfangen:

- GetAllStatus: Auf diese Nachricht sendet die Masternode den Status aller Applikationen auf das Topic Sensact::StatusInfo. Die Kodierung des Payload ist dabei uint16 count, item[count] items mit item={u16 ApplicationId, u8 statusLength, uint8[statusLength] payload}.
- GetStatusOf(n). Auf diese Nachricht sendet die Masternode den Status der gewünschten Applikation oder aber eine Fehlernachricht, falls die ApplicationId unbekannt ist.

Innerhalb der Applikation könnte der Status gar nicht gespeichert sein. Statt dessen castet d… NEIN, dann müsste jedem command das u8-array übergeben werden und es müsste ein cast stattfinden – das machen wir nicht – sooo eng ist der Speicher nicht!

Was passiert, wenn die Masternode kurz weg ist und sich dann der Status einer node ändert, wie gehen wir dann vor, damit die masternode das beim Hochfahren wieder mit bekommt.

- Regelmäßiges Senden des Status von allen Applicationen?
- Exlizites Abfragen

Die masternode muss sich merken, ob sie für eine App bereits einen Status empfangen hat.

Ich meine, es ist doch sinnvoll, in jeder app einen GetStatus und einen SetStatus als Command explizit zu implementieren. Wenn die Masternode hochfährt, dann fragt sie alle Applikationen nach ihrem aktuellen Status im 200msek-Rhythmus. Im Betrieb fragt sie reihum alle 2sek. Eine Veränderung des Status wird immer direkt durchgepushed. Fraglich ist, ob es hier zu raceconditions kommen könnte: Antwort. Nein, da eine später losgesendete Nachricht auch IMMER einen späteren Status hat.

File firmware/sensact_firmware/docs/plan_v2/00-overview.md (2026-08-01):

# Plan v2 – Überarbeitung sensact_firmware & Umfeld

Stand: 2026-07-31. Dies ist der Einstiegspunkt für die mehrstufige Überarbeitung.
Jede Stufe hat eine eigene Datei in diesem Ordner. Die Dateien sind so geschrieben,
dass sowohl Klaus als auch Claude (in einer neuen Session) ohne weiteren Kontext
direkt einsteigen können.

## Die 5 Stufen (wie besprochen)

1. [01-entwicklerdokumentation-und-build.md](01-entwicklerdokumentation-und-build.md) – Entwickler-Doku, insbesondere Build-Prozess
2. [02-builder-migration-csharp.md](02-builder-migration-csharp.md) – Builder von gulp/TypeScript auf C# umstellen
3. [03-wifimanager-review.md](03-wifimanager-review.md) – Wifimanager prüfen + konfigurierbares AP-Fallback
4. [04-architektur-review.md](04-architektur-review.md) – Schrittweise Architektur-/Konsistenz-Review (laufender Backlog)
5. [05-unit-tests-sensact-apps.md](05-unit-tests-sensact-apps.md) – Unit-Tests für die sensact-Apps

Die Reihenfolge entspricht deiner Aufzählung. Tatsächliche Abhängigkeiten sind aber
lockerer, als es die Nummerierung suggeriert – siehe "Reihenfolge & Parallelisierung"
unten.

## Wichtigster Befund vorab: das Projekt ist kein einzelnes Repo

`sensact_firmware` (dieses Verzeichnis) ist **kein eigenes Git-Repository**, sondern
nur ein Unterordner von `C:\repos\sensact` (`git rev-parse --show-toplevel` liefert
`C:/repos/sensact`). Der eigentliche Anwendungscode ist über mehrere, teils
unabhängige Repos verteilt:

| Repo (Remote) | Lokaler Pfad | Rolle |
|---|---|---|
| `klaus-liebler/sensact` | `C:\repos\sensact` | Enthält u.a. `firmware/sensact_firmware` (diese Firmware), `espidf-components/sensact-applicationmodel` (**die eigentlichen "sensact apps"**: blind, onoff, pump, rgbw, sound, …), `sensact-hal`, `sensact-middleware` |
| `klaus-liebler/espidf-component-webmanager` | `C:\repos\espidf-component-webmanager` | Wifimanager + generischer Webserver/OTA/Login, als ESP-IDF-Komponente eingebunden über `EXTRA_COMPONENT_DIRS` |
| `klaus-liebler/npm-packages` | `C:\repos\npm-packages` | Alle `@klaus-liebler/*`-Pakete: Build-Tools (`espidf-vite-secure-build-tools`), Web-UI-Bausteine (`web-components`, `web-components-sensact`), Test-Server-Helfer (`websocket_file_testserver`), u.a. |
| `klaus-liebler/factory_in_a_box` | `C:\repos\factory_in_a_box\firmware_factory_control_unit` | Enthält den **Referenz-Builder in C#** (`builder/`), der als Vorlage für Stufe 2 dient |

Konsequenz für die Arbeit:
- Änderungen an den "sensact apps" (Stufe 5) und an der Firmware selbst (Stufen 1–4)
  landen im selben Repo (`sensact`) – ein `git commit` in `sensact_firmware` committet
  ins Eltern-Repo.
- Änderungen am Wifimanager (Stufe 3) und an den Build-Tools/Web-Components
  (Stufen 1–2) betreffen **andere Repos mit eigenen Remotes**. Diese Session ist
  aktuell nur für `sensact_firmware` (+ ein paar `factory_in_a_box`-Pfade) als
  Arbeitsverzeichnis freigegeben. Für produktive Änderungen in
  `espidf-component-webmanager` oder `npm-packages` braucht es entweder eine neue
  Claude-Code-Session mit passendem Arbeitsverzeichnis, oder wir erarbeiten die
  Änderung hier als Vorschlag/Diff und du wendest sie dort an.
- Jede Stufe, die mehrere Repos berührt, braucht am Ende **mehrere Commits in
  mehreren Repos** – das wird in den jeweiligen Stufen-Dateien explizit vermerkt.

## Weitere Grundtatsachen (Referenz für alle Stufen)

- Aktuelle Build-Kette: `builder/gulpfile.ts` (gulp 5, TypeScript via `tsx`) orchestriert
  Codegenerierung, Zertifikate, Flatbuffers, Vite-Web-Build und ESP-IDF-Build/Flash.
  Alle Low-Level-Funktionen stecken im npm-Paket
  `@klaus-liebler/espidf-vite-secure-build-tools`
  (`C:\repos\npm-packages\@klaus-liebler\espidf-vite-secure-build-tools`).
- Generierte Artefakte landen zentral unter `C:\repos\generated\` (hart codiert in
  `CMakeLists.txt:4` und `gulpfile.ts:37`) sowie board-spezifisch unter
  `%USERPROFILE%\OneDrive - HSOS\esp32_boards\<mac-dir>\`. **In Diskussion:** ob
  `C:\repos\generated\` stattdessen projekt-lokal (`sensact_firmware\generated\`)
  liegen soll – siehe [02-builder-migration-csharp.md](02-builder-migration-csharp.md#offene-fragen).
- Es gibt aktuell **keine automatisierten Tests** irgendwo im Projekt (weder für die
  Firmware noch für den Builder noch für den Wifimanager) und **keinen `docs/`-Ordner**
  vor diesem Plan.
- Es gibt unklare bzw. potenziell falsche Altlasten, die während der Recherche
  aufgefallen sind (Details in den jeweiligen Stufen), u.a.:
  - ~~Widersprüchliche Zertifikatspfade~~ – **erledigt 2026-07-31**: `netcase\certificates`
    war eine Altlast, `main/CMakeLists.txt` nutzt jetzt ausschließlich
    `OneDrive - HSOS\certificates` (wie schon in `gulpfile.ts`).
  - `main/__archive/` enthält tote Dateien mit veralteten APIs (nicht im Build
    referenziert) – Aufräum-Kandidat für Stufe 4.
  - (`board_info copy.json` im Projekt-Root ist **kein** Problem – wird bewusst für
    interne Tests gebraucht.)

## Reihenfolge & Parallelisierung

- **Stufe 1 (Doku)** zuerst als schneller, risikoarmer Start – aber als *lebendes
  Dokument* verstehen: nach Stufe 2 (Builder-Migration) muss der Build-Abschnitt
  aktualisiert werden.
- **Stufe 2 (Builder-Migration)** ist die aufwändigste Einzelstufe und sollte in
  kleinen, parallel lauffähigen Schritten passieren (alter gulp-Weg bleibt nutzbar,
  bis der neue C#-Weg für alle Aufgaben Parität hat).
- **Stufe 3 (Wifimanager)** ist inhaltlich unabhängig von 1/2 und kann jederzeit
  parallel laufen – betrifft aber ein anderes Repo (`espidf-component-webmanager`).
- **Stufe 4 (Architektur-Review)** ist bewusst kein einmaliger Block, sondern ein
  fortlaufender Backlog, der ab sofort parallel zu allen anderen Stufen gepflegt
  wird (jede Stufe trägt Funde dort ein statt sie "nebenbei" zu reparieren).
- **Stufe 5 (Unit-Tests) kommt bewusst als Letztes** (Entscheidung von Klaus,
  siehe [05-unit-tests-sensact-apps.md](05-unit-tests-sensact-apps.md)) – nicht
  parallel zu den anderen Stufen. Trotzdem gilt schon *während* aller anderen
  Stufen: bei jedem Refactoring mitdenken, dass der Code hinterher gut testbar
  bleiben muss (z.B. sauber gegen `iSensactContext` statt gegen ESP-IDF-Header
  programmieren) – Testbarkeit ist ein Kriterium für Umbau-Entscheidungen in Stufe 4,
  auch wenn die Tests selbst erst am Ende geschrieben werden.

## Wie wir mit diesem Plan arbeiten

- Jede Stufen-Datei enthält eine Checkliste (`- [ ]`), die während der Umsetzung
  abgehakt wird – bitte die Dateien direkt editieren, nicht nur im Chat abhaken.
- Offene Entscheidungen sind explizit als "Offene Frage" markiert. Bei diesen bitte
  vor Beginn der Umsetzung kurz Rücksprache halten (per Chat), auch nachdem der Plan
  steht.
- Neue Erkenntnisse während der Umsetzung (z.B. weitere Inkonsistenzen) werden in
  `04-architektur-review.md` nachgetragen, nicht in dieser Übersicht.

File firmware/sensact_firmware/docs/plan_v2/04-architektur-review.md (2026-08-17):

# Stufe 4 – Schrittweise Architektur-Review (laufender Backlog)

Diese Stufe ist bewusst **kein einmaliger Block**, sondern ein fortlaufender Prozess:
jede Session (egal ob an Stufe 1, 2, 3 oder 5 gearbeitet wird) trägt neue Funde hier
ein, statt sie "mal eben nebenbei" zu fixen. Größere Fixes werden als eigener
Punkt hier abgehakt, sobald sie erledigt sind.

**Leitprinzip bei jedem Refactoring (Entscheidung von Klaus):** Unit-Tests
(Stufe 5) kommen erst ganz zum Schluss, aber jede hier durchgeführte
Umstrukturierung muss so gestaltet sein, dass der Code hinterher gut testbar ist
(z.B. Abhängigkeiten weiter über Interfaces wie `iSensactContext` statt über
konkrete ESP-IDF-Typen führen). Testbarkeit ist also schon jetzt ein
Bewertungskriterium für Architektur-Entscheidungen, auch ohne dass schon Tests
geschrieben werden.

## Empfohlene Reihenfolge für die eigentliche Review-Arbeit

Nicht alles auf einmal – pro Sitzung ein Modul, mit kurzem Ergebnis-Vermerk hier:

1. Node-Architektur: `nodemaster.hh`, `busmaster.hh`, `interfaces.hh`,
   `node_applicationhost.cc/.hh`, `node_gatewayhost.hh`, `node_iohost.hh`
2. HAL-Board-Varianten: `main/hal/hal_sensact*.hh` (6 Dateien) – prüfen, wie viel
   davon tatsächlich Board-spezifisch sein *muss* vs. Copy-Paste ist
3. Sensact-Apps: `sensact/espidf-components/sensact-applicationmodel/apps/*`
   (überschneidet sich mit Stufe 5 – dort werden ohnehin alle Apps einzeln
   angefasst, Architektur-Findings fallen dabei nebenbei ab)
4. Wifimanager (`espidf-component-webmanager`) – größtenteils bereits in Stufe 3
   behandelt, hier nur das, was über den Wifi-Teil hinausgeht (HTTP/OTA/Login/
   File-Handling)
5. Build-/Codegen-Tooling – nach Abschluss von Stufe 2, da sich davor ohnehin alles
   ändert
6. Cross-Cutting: `messagecodes.hh`, `logger.hh`, `journal_plugin.cc/.hh`,
   `sensact_projectconfig.hh`

## Bereits bekannte Funde (Startbestand des Backlogs)

Status-Legende: 🔴 Offen · 🟡 In Arbeit · 🟢 Erledigt

### 🟢 `configware` war ein unentdeckter, manueller Pipeline-Schritt (erledigt 2026-08-17)
- `C:\repos\sensact\configware\` (C#-Hausmodell-Generator, erzeugt die meisten
  `.inc`-Dateien für `sensact-applicationmodel`) lief ursprünglich komplett
  manuell und unabhängig vom Gulp-Build – nirgends dokumentiert, keine
  Automatisierung, Fehlerquelle bei vergessener Neugenerierung nach
  Modelländerungen.
- Entschieden (2026-07-31), umgesetzt (2026-08-01): vollständig in den
  C#-Build-Orchestrator verschmolzen (Phase `GenerateModelFiles`), siehe
  [02-builder-migration-csharp.md](02-builder-migration-csharp.md).
  `configware/`-Verzeichnis selbst am 2026-08-17 gelöscht, nachdem eine
  zwischenzeitliche Divergenz der zwei parallel gepflegten Generator-Kopien
  bestätigte, dass der alte Pfad nur noch Risiko ohne Nutzen war (s.
  [build-process.md](../build-process.md)).

### 🔴 Tote Dateien in `main/__archive/`
- Dateien: `busmaster.ccold`, `nodemaster.ccold`, `connect.hhold`, `updater.hh`,
  `lcd_manager.hh`.
- Keine davon ist in `main/CMakeLists.txt` referenziert (nur `journal_plugin.cc`,
  `node_applicationhost.cc`, `model_node.cc`, `main.cc` werden kompiliert), die
  Endungen `.ccold`/`.hhold` sind ohnehin keine gültigen C++-Endungen. `updater.hh`
  und `connect.hhold` nutzen zudem veraltete APIs (`esp_spi_flash.h`).
- Vorschlag: löschen (Git-Historie bleibt ja erhalten, falls doch mal gebraucht).
- Aufwand: trivial. Risiko: keins (nicht im Build).

### 🟢 Widersprüchliche Zertifikatspfade (erledigt 2026-07-31)
- War: `gulpfile.ts:42` nutzt `OneDrive - HSOS\certificates` als Quelle der Root-CA,
  `main/CMakeLists.txt` bettete aber `%USERPROFILE%\netcase\certificates\rootCA.pem.crt`
  ein (`netcase` = Altlast einer früheren Migration).
- Klärung durch Klaus: ausschließlich `OneDrive - HSOS\certificates` ist korrekt.
- Fix: `main/CMakeLists.txt:7` (`EMBED_TXTFILES`) korrigiert auf
  `${USERPROFILE}/OneDrive - HSOS/certificates/rootCA.pem.crt`.

### ⚪ `board_info.json` vs. `board_info copy.json` im Repo-Root – kein Problem
- Klärung durch Klaus: `board_info copy.json` ist absichtlich vorhanden, wird für
  interne kleine Tests gebraucht. Kein Aufräum-Kandidat, ignorieren.

### 🔴 Absoluter Pfad-Wildwuchs (Portabilität)
- Hart codierte Pfade in `gulpfile.ts` (`C:\\repos\\sensact\\firmware\\sensact_firmware`,
  `C:\\repos\\espidf-component-webmanager`, `C:\\repos\\generated`), in
  `CMakeLists.txt` (`C:/repos/generated/`, absolute `EXTRA_COMPONENT_DIRS`), und
  `%USERPROFILE%\OneDrive - HSOS\...` für Board-Secrets.
- Nicht zwingend "falsch" für ein Ein-Entwickler-Setup, aber macht das Projekt
  nicht auf einer anderen Maschine/für einen zweiten Mitwirkenden lauffähig, ohne
  Quellcode zu ändern.
- Vorschlag (niedrige Priorität, kein Blocker): ein einziges, nicht eingechecktes
  `local.settings.json`/`.env` als Quelle dieser Pfade, das von Gulp (heute) bzw.
  dem C#-Builder (nach Stufe 2) gelesen wird. Guter Kandidat, um direkt im Zuge von
  Stufe 2 mitzuerledigen (der neue Builder liest ohnehin `appsettings.json`).
- **In Diskussion (2026-07-31):** `C:\repos\generated\` projekt-lokal machen (z.B.
  `sensact_firmware\generated\`) statt eines maschinenweiten Pfads außerhalb des
  Repos. Reduziert genau diesen Fund für den größten der hart codierten Pfade.
  Klaus prüft das noch; Entscheidung + Umsetzungsdetails siehe
  [02-builder-migration-csharp.md](02-builder-migration-csharp.md#offene-fragen).
  `%USERPROFILE%\OneDrive - HSOS\...` bleibt davon unberührt (Board-Secrets sollen
  bewusst außerhalb des Repos liegen).

### 🔴 `webmanager::M` – "God Class"
- Eine einzige Singleton-Klasse (`cpp/webmanager.hh`, ~1430 Zeilen) vereint:
  WLAN-Verbindungs-Statemachine, HTTP-Fileserver (Upload/Download/Delete), OTA-Update,
  Login/Session-Verwaltung, Wifimanager-Websocket-Protokoll, allgemeines
  Plugin-Dispatching.
- Macht die Klasse schwer zu testen (kein Host-Build möglich, da tief mit ESP-IDF-
  Headern verwoben) und schwer zu verstehen/ändern (Stufe 3 arbeitet notgedrungen
  direkt in dieser Datei).
- Vorschlag (mittelfristig, nicht Teil von Stufe 3's MVP): Aufteilen in z.B.
  `WifiConnectionManager` (reine State-Machine, host-testbar), `HttpFileServer`,
  `OtaUpdater`, `SessionAuth`, `WifimanagerProtocolHandler` – orchestriert von einer
  dünnen `M`-Fassade.
- Konkret gefundene Bugs innerhalb dieser Klasse siehe
  [03-wifimanager-review.md](03-wifimanager-review.md).

### 🔴 HAL-Board-Varianten – Duplizierungsgrad ungeklärt
- 6 Board-Varianten (`hal_sensactHs_modular.hh`, `hal_sensactHsNano3.hh`,
  `hal_sensactOutdoor.hh`, `hal_sensactUp3.hh`, `hal_sensactUpControl.hh`,
  `hal_sensactUpHs.hh`, je 125–288 Zeilen) erben von einer gemeinsamen Basis
  (`hal_esp32.hh`, `cESP32`). Noch nicht im Detail geprüft, wie viel Pin-/Config-Code
  in den einzelnen Board-Dateien tatsächlich dupliziert ist vs. wie viel echte,
  unvermeidbare Board-Spezifika sind. **To-Do**: bei der Node-Architektur-Review
  (Punkt 2 der Reihenfolge oben) explizit gegenüberstellen und ggf. gemeinsame
  Tabellen-/Config-Strukturen extrahieren.

### 🔴 `RECONNECTS_ON_STARTUP` vs. `RECONNECTS_ON_OPERATION` – siehe Stufe 3
- Wird im Zuge von Stufe 3 behoben (Deadline-Modell statt zwei inkonsistenten
  Attempt-Zählern). Hier nur verlinkt, damit der Fund nicht doppelt in zwei
  Dokumenten gepflegt werden muss.

### 🔴 Keine Tests, kein CI, irgendwo im Projekt
- Weder Firmware noch Builder noch Wifimanager haben aktuell automatisierte Tests.
  Stufe 5 adressiert das für die Sensact-Apps; Stufe 2 sieht Tests für den neuen
  C#-Builder vor. Wifimanager-State-Machine bleibt vorerst ungetestet (siehe
  "optional/stretch" in Stufe 3) – als eigenständiger Backlog-Punkt festhalten, falls
  später Kapazität dafür da ist.

### 🔴 Login-Browser merkt sich Zugangsdaten nicht (analysiert 2026-08-17)
- **Mechanische Ursache gefunden**: `main/main.cc:1-2` hat `HTTP`/`HTTPS` fest
  einkompiliert (`//#define HTTP` / `#define HTTPS`) statt über den generischen
  `board_settings.firmware`-Mechanismus konfigurierbar zu sein – der Server läuft
  deshalb IMMER über `httpd_ssl_start` mit einem selbstsignierten Zertifikat
  (`builder/Certificates.cs`, signiert von einer privaten Root-CA unter
  `OneDrive - HSOS\certificates\rootCA.pem.crt`). Nichts deutet darauf hin, dass
  diese Root-CA je in einem Betriebssystem-/Browser-Truststore installiert wurde.
- Browser (v.a. Chrome/Edge) zeigen bei einer HTTPS-Seite mit nicht vertrauens-
  würdigem Zertifikat eine Warn-Zwischenseite, die bei jedem Besuch neu bestätigt
  werden muss – UND (das ist der eigentliche Grund für das gemeldete Symptom):
  **Chrome bietet auf einer per Zertifikatswarnung erreichten Seite grundsätzlich
  kein "Passwort speichern?"-Prompt an** (bewusste Sicherheitsentscheidung, keine
  Zugangsdaten gegen eine nicht verifizierbare Identität zu speichern).
- Kleinere Mitursachen: `<input>`-Felder im Login-Formular
  (`espidf-component-webmanager/cpp/webmanager.hh`,
  `handle_login_form`) haben kein `autocomplete="username"`/
  `"current-password"`; das Session-Cookie hat trotz HTTPS kein `Secure`-Attribut;
  das externe `<link href='https://fonts.googleapis.com/...'>` kann im
  AP-Fallback-Modus (kein Internet) ohnehin nie geladen werden.
- **Vorgeschlagene Alternativen** (Trade-off, keine davon eindeutig "richtig" –
  Entscheidung steht noch aus):
  1. **Private Root-CA einmalig im Client-Truststore installieren** (dokumentierter
     Provisioning-Schritt, z.B. Download-Link auf der AP-Fallback-Startseite).
     Sauberste Lösung (echtes TLS, normales Browser-Passwort-Verhalten danach),
     aber Einrichtungsaufwand pro Client-Gerät/Browser.
  2. **Auf Klartext-HTTP umschalten** für das rein lokale Admin-Interface (der
     `HTTP`-Zweig existiert bereits, ist nur auskommentiert) – Chrome bietet auf
     HTTP-Formularen im privaten/lokalen Netz ganz normal das Passwort-Speichern
     an. Trade-off: Zugangsdaten/Session-Cookie gehen unverschlüsselt übers WLAN
     (bei einem rein lokal genutzten Smart-Home-Gerät oft akzeptabel, s.
     vergleichbare Consumer-IoT-Geräte).
  3. **HTTP Basic Auth statt Formular-Login.** Browser merken sich Basic-Auth-
     Zugangsdaten sehr zuverlässig (auch über HTTP), kein `<form>`/Cookie-Handling
     nötig. Nachteil: nicht stylebarer nativer Browser-Dialog, kein sauberer
     Logout-Mechanismus.
  4. **SPA-seitiges Session-Persistieren** (`localStorage`/langlebiges Token) als
     Ergänzung zu jeder der obigen Optionen – löst das eigentliche
     "Browser-Autofill"-Problem nicht, reduziert aber, wie oft überhaupt neu
     eingeloggt werden muss.
  - Empfehlung fürs Erste (niedrigster Aufwand, behebt das gemeldete Symptom
    direkt): Option 2, `HTTP`/`HTTPS` dabei über `board_settings.firmware` statt
    hart im Quellcode umschaltbar machen (konsistent mit allen anderen
    board-spezifischen Einstellungen).

### 🟡 Builder soll über sensact hinaus wiederverwendbar werden
- Nutzerwunsch (2026-08-17): der C#-Builder (`builder/`) soll künftig auch in
  anderen, ähnlich aufgebauten ESP32-Firmware-Projekten (s. z.B.
  `C:\repos\labathome\labathome_firmware`) einsetzbar sein. Zielbild: pro
  Projekt bleiben nur `builder/appsettings.json` + eine dünne `builder/Program.cs`
  übrig, der gesamte übrige Code (`Paths.cs`, `Phases/*.cs`, `ModelGeneration/*`,
  `NpmProject.cs`, `Certificates.cs` etc.) wandert in ein eigenständiges,
  gemeinsames Repo/Paket (z.B. `C:\repos\dotnet_libs\firmware_builder`, analog zu
  `best_binary_buffers`) und wird von dort per `ProjectReference`/NuGet
  eingebunden statt pro Projekt kopiert zu werden.
- Voraussetzung/Vorarbeit bereits erledigt: `Paths.FindRootDir()` verlässt sich
  nicht mehr auf eine unbegrenzte Aufwärtssuche, sondern ausschließlich auf das
  unmittelbar übergeordnete Verzeichnis von `builder/` (s. Commit vom
  2026-08-17) – Voraussetzung dafür, dass derselbe Code in unterschiedlich
  verschachtelten Projektstrukturen zuverlässig funktioniert. Maschinen-/
  Projekt-abhängige absolute Pfade liegen ebenfalls bereits vollständig in
  `appsettings.json` (`NpmPackagesDir`, `WebmanagerWsProtocolDir`,
  `BoardsDir`, `CertsDir`), nicht mehr im Code.
- Noch offen/zu klären, bevor die Extraktion angegangen wird: welche Teile sind
  wirklich sensact-agnostisch (`ModelGeneration/*`, `GenerateSensactFiles.cs`
  sind z.B. eng an das sensact-Anwendungsmodell gekoppelt – klare Trennung
  "generischer Kern" vs. "projektspezifische Phase" nötig), wie Versionierung
  zwischen mehreren Konsumenten-Projekten funktioniert (ProjectReference wie bei
  `best_binary_buffers` vs. echtes NuGet-Paket), und ob `labathome_firmware`
  überhaupt zuerst auf das neue best_binary_buffers_schema/BestBinaryBuffers migriert sein muss
  (s. dortige `docs/MIGRATION_TO_BESTBINARYBUFFERS.md`), bevor eine Builder-
  Wiederverwendung dort sinnvoll ist.

## Vorgehen für neue Funde

- [ ] Neuer Fund → hier als eigener Abschnitt mit Status 🔴, kurzer Beschreibung,
      betroffene Datei(en)/Repo, Vorschlag, Aufwand/Risiko-Einschätzung eintragen.
- [ ] Beim Beheben: Status auf 🟢 setzen, kurz vermerken, in welchem Commit/welcher
      PR das passiert ist.
- [ ] Größere/grundsätzliche Findings (z.B. "God Class" aufteilen) nicht in dieser
      Datei im Detail ausplanen, sondern bei Bedarf eine eigene Datei
      `04a-<thema>.md` daneben anlegen und hier nur verlinken – damit dieses
      Dokument als schnell überfliegbare Übersicht nutzbar bleibt.

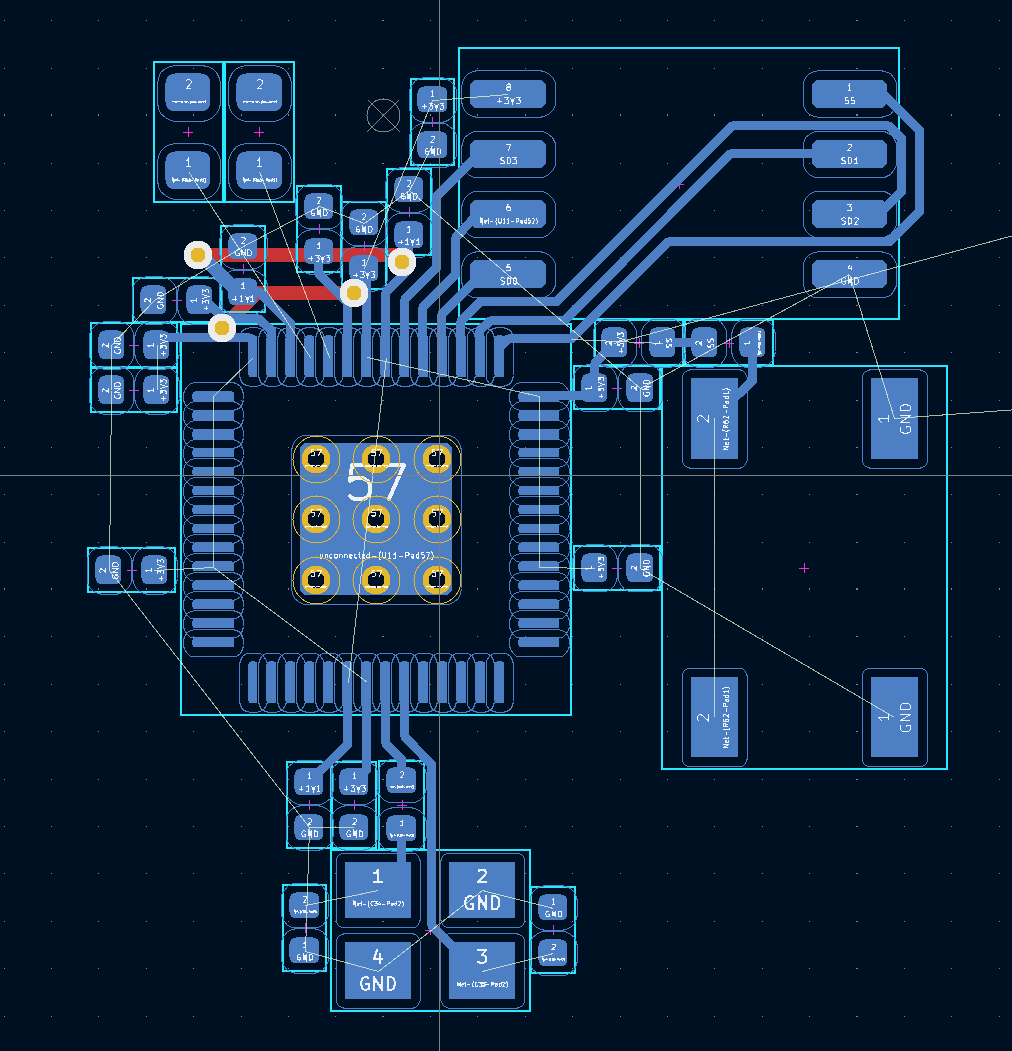
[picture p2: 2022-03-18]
pcb/sensactHsIO4/Layout RP2040.png

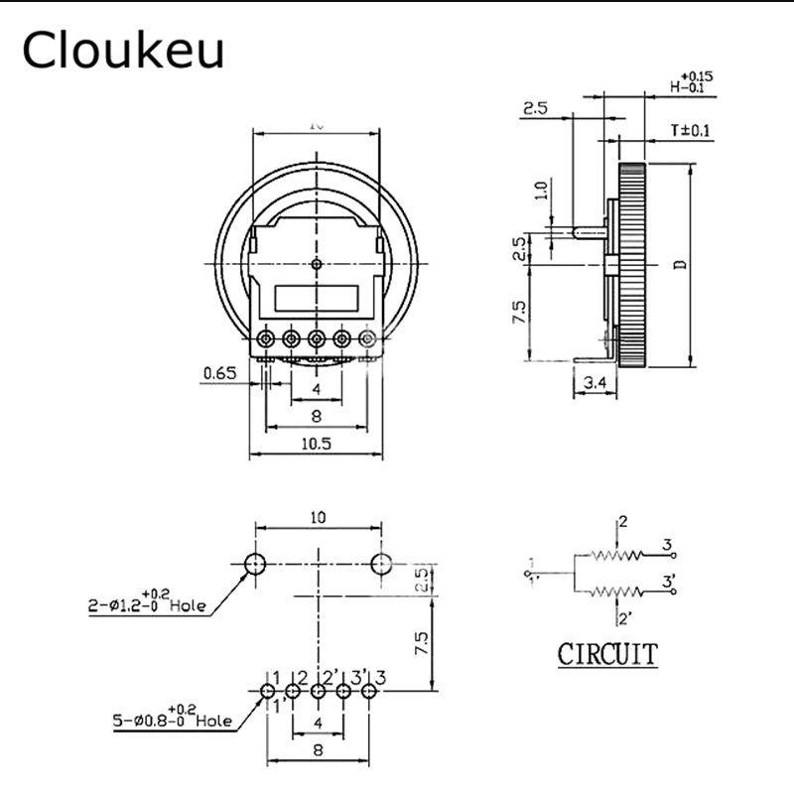
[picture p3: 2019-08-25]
pcb/dual dial potentiometer.PNG

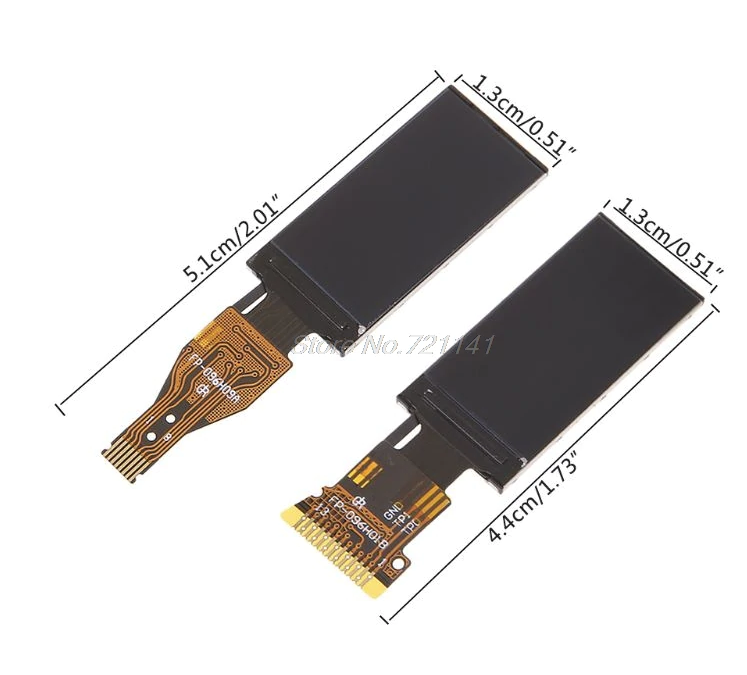
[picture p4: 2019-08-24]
pcb/sensactHsExt/Display.PNG

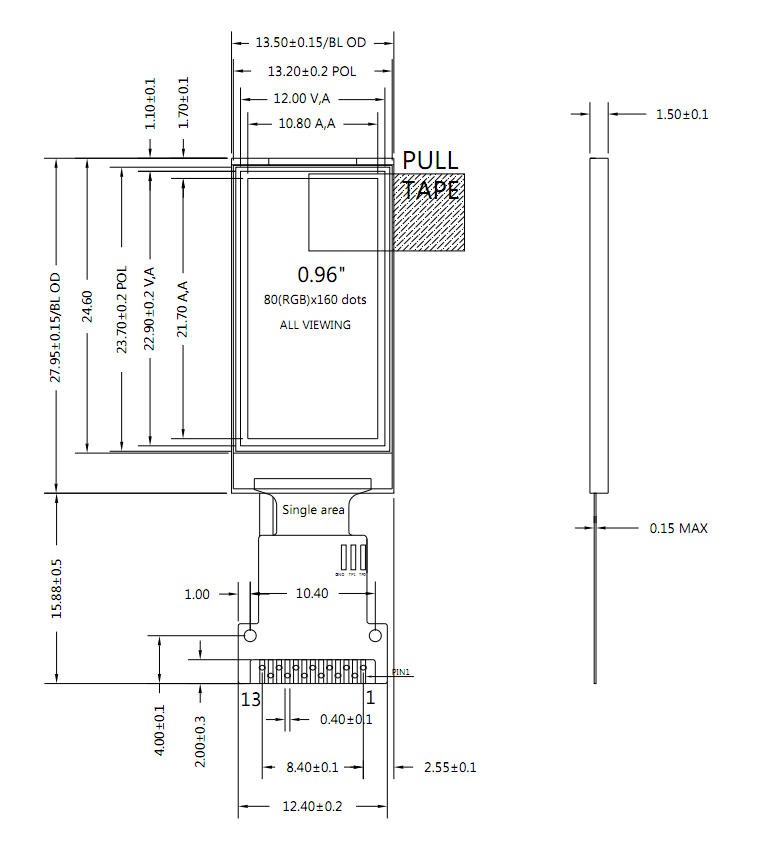
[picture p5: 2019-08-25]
pcb/er-tft0.96-1_outline.jpg

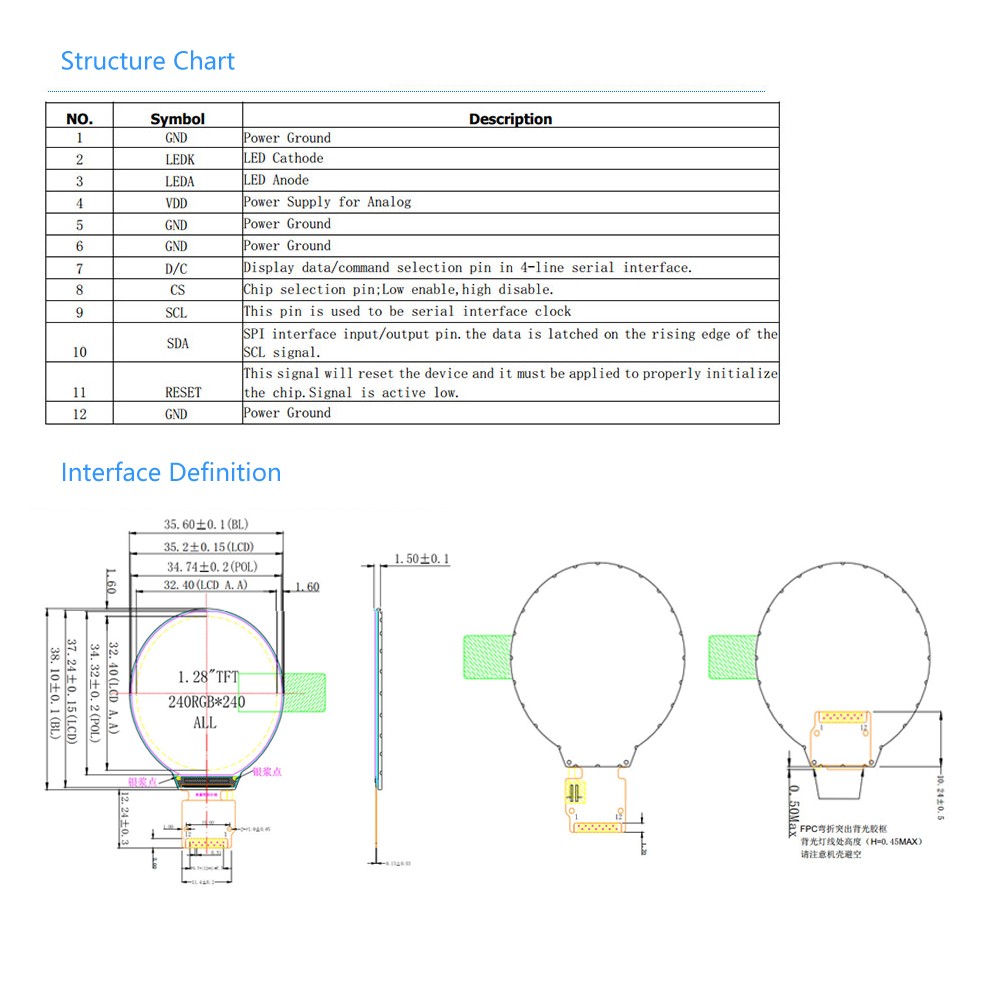
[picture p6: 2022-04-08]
pcb/sensactUp3/DC 3_3V 1_28inch IPS LCD Display Screen_2.jpg

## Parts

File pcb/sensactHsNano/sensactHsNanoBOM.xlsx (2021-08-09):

Reference | Quantity | Value | Footprint
C1 C8 | 2 | 470u | Capacitor_THT:CP_Radial_D10.0mm_P3.50mm
C11 C12 C13 C14 | 4 | u22 | Capacitor_SMD:C_0805_2012Metric_Pad1.18x1.45mm_HandSolder
C15 C16 C17 C18 | 4 | u68 | Capacitor_SMD:C_1206_3216Metric_Pad1.33x1.80mm_HandSolder
C2 C6 C7 C19 | 4 | 1u | Capacitor_SMD:C_0805_2012Metric_Pad1.18x1.45mm_HandSolder
C4 C5 C10 C20 C21 C22 C23 C25 C27 C28 C32 C40 C43 | 13 | u1 | Capacitor_SMD:C_0805_2012Metric_Pad1.18x1.45mm_HandSolder
C24 C26 C29 | 3 | 2u2 | Capacitor_SMD:C_0805_2012Metric_Pad1.18x1.45mm_HandSolder
C3 C9 C33 | 3 | 22u | Capacitor_SMD:C_1206_3216Metric_Pad1.33x1.80mm_HandSolder
C34 | 1 | 10u | Capacitor_SMD:C_1210_3225Metric_Pad1.33x2.70mm_HandSolder
C30 C31 C35 | 3 | 10n | Capacitor_SMD:C_0805_2012Metric_Pad1.18x1.45mm_HandSolder
C36 C37 C38 C39 | 4 | m1 | Capacitor_SMD:C_1210_3225Metric_Pad1.33x2.70mm_HandSolder
C41 C42 | 2 | 10u | Capacitor_SMD:C_1206_3216Metric_Pad1.33x1.80mm_HandSolder
D1 | 1 | Rpower_Ginfo | liebler_SEMICONDUCTORS:Dialight-5530123F-0
D3 | 1 | NUP2105 | Package_TO_SOT_SMD:SOT-23_Handsoldering
D2 D4 | 2 | 2A | Diode_SMD:D_SMB_Handsoldering
D5 | 1 | ebus-RX | Diode_SMD:D_0805_2012Metric_Pad1.15x1.40mm_HandSolder
D6 | 1 | ebus-TX | Diode_SMD:D_0805_2012Metric_Pad1.15x1.40mm_HandSolder
D7 | 1 | 9,1V/1,3W | Diode_THT:D_DO-41_SOD81_P10.16mm_Horizontal
D8 D9 D10 D11 | 4 | 1N4007 | liebler_SEMICONDUCTORS:D_SOD-123_handsolder
FB1 | 1 | Bead | Inductor_SMD:L_0805_2012Metric_Pad1.15x1.40mm_HandSolder
J1 | 1 | PROG | liebler_CONN:IDC_2x03_P1.27mm_Vertical
J2 | 1 | SensactBus | Connector_IDC:IDC-Header_2x05_P2.54mm_Horizontal
J3 | 1 | CAN+24V | Connector_Phoenix_MC:PhoenixContact_MC_1,5_4-G-3.5_1x04_P3.50mm_Horizontal
J4 | 1 | HR911105A | liebler_CONN:HANRUN_HR911105A
J5 | 1 | Audio | Connector_Phoenix_MC:PhoenixContact_MC_1,5_4-G-3.5_1x04_P3.50mm_Horizontal
J6 | 1 | 1wire | Connector_JST:JST_XH_B4B-XH-AM_1x04_P2.50mm_Vertical
JP1 | 1 | INT0 | Jumper:SolderJumper-2_P1.3mm_Open_RoundedPad1.0x1.5mm
JP2 | 1 | SUP_MON | Jumper:SolderJumper-2_P1.3mm_Open_RoundedPad1.0x1.5mm
L1 L2 L3 L4 | 4 | 10u | liebler_PASSIVES:Inductor_CDRH104_handsolder
L5 | 1 | 22u | liebler_PASSIVES:Inductor_CDRH104_handsolder
NT1 | 1 | Net-Tie_2 | NetTie:NetTie-2_SMD_Pad2.0mm
Q1 | 1 | BC817 | Package_TO_SOT_SMD:SOT-23_Handsoldering
R1 R2 R3 R4 R6 R23 R28 R29 | 8 | 4k7 | Resistor_SMD:R_0805_2012Metric_Pad1.20x1.40mm_HandSolder
R11 R13 R24 R32 R43 R45 R46 | 7 | 1k | Resistor_SMD:R_0805_2012Metric_Pad1.20x1.40mm_HandSolder
R15 R17 R18 R19 | 4 | 49R9 | Resistor_SMD:R_0805_2012Metric_Pad1.20x1.40mm_HandSolder
R16 | 1 | 12K1 | Resistor_SMD:R_0805_2012Metric_Pad1.20x1.40mm_HandSolder
R20 R21 | 2 | K33 | Resistor_SMD:R_0805_2012Metric_Pad1.20x1.40mm_HandSolder
R22 R25 R35 R42 R44 | 5 | 10k | Resistor_SMD:R_0805_2012Metric_Pad1.20x1.40mm_HandSolder
R26 R27 R30 R31 R41 | 5 | k22 | Resistor_SMD:R_0805_2012Metric_Pad1.20x1.40mm_HandSolder
R33 R34 | 2 | k47 | Resistor_SMD:R_0805_2012Metric_Pad1.20x1.40mm_HandSolder
R36 | 1 | m22 | Resistor_SMD:R_0805_2012Metric_Pad1.20x1.40mm_HandSolder
R37 | 1 | 18k | Resistor_SMD:R_0805_2012Metric_Pad1.20x1.40mm_HandSolder
R38 | 1 | 15k | Resistor_SMD:R_0805_2012Metric_Pad1.20x1.40mm_HandSolder
R39 | 1 | m1 | Resistor_SMD:R_0805_2012Metric_Pad1.20x1.40mm_HandSolder
R40 | 1 | 22k | Resistor_SMD:R_0805_2012Metric_Pad1.20x1.40mm_HandSolder
R5 | 1 | 1K5 | Resistor_SMD:R_0805_2012Metric_Pad1.20x1.40mm_HandSolder
R7 | 1 | 120R | Resistor_SMD:R_1206_3216Metric_Pad1.30x1.75mm_HandSolder
R8 R14 | 2 | k1 | Resistor_SMD:R_0805_2012Metric_Pad1.20x1.40mm_HandSolder
R9 R10 R12 | 3 | 33R | Resistor_SMD:R_0805_2012Metric_Pad1.20x1.40mm_HandSolder
SW1 | 1 | TERM | liebler_MECH:SW_SPDT_PCM12_handsolder
SW2 | 1 | Prog | Button_Switch_THT:SW_Tactile_SPST_Angled_PTS645Vx58-2LFS
SW3 | 1 | Reset | sensact:SW_SPST_2x4x3,5
U1 | 1 | TAS5805M | sensact:TSSOP-28_4.4x9.7mm_Pitch0.65mm_pad_handsolder
U10 | 1 | HT75xx-1-SOT89 | Package_TO_SOT_SMD:SOT-89-3_Handsoldering
U2 | 1 | LAN8720A | sensact:QFN-24-1EP_4x4mm_P0.5mm_EP2.6x2.6mm_handsolder
U3 | 1 | ESP32 | smopla:ESP32-WROOM-32_HANDSOLDER
U4 | 1 | DS2482 | sensact:SOIC-8_3.9x4.9mm_Pitch1.27mm_handsolder
U5 | 1 | SN65HVD230 | sensact:SOIC-8_3.9x4.9mm_Pitch1.27mm_handsolder
U6 U8 | 2 | EL817 | liebler_SEMICONDUCTORS:SO-4_7.6x3.6mm_P2.54mm_handsolder
U7 | 1 | TPS5430DDA | sensact:SOIC-8_3.9x4.9mm_Pitch1.27mm_pad_handsolder
U9 | 1 | LM393 | sensact:SOIC-8_3.9x4.9mm_Pitch1.27mm_handsolder
X1 | 1 | 50MHz | Oscillator:Oscillator_SMD_EuroQuartz_XO32-4Pin_3.2x2.5mm_HandSoldering

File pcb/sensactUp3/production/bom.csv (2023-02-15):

Designator | Footprint | Quantity | Value | LCSC Part #
C1 | 0603 | 1 | 22u
C10 | 0603 | 1 | 22u
C11 | 0603 | 1 | 22u
C12 | 0402 | 1 | 1u
C13 | 1206 | 1 | 100u
C14 | 0402 | 1 | u1
C15 | 0402 | 1 | u1
C16 | 0402 | 1 | 1u
C17 | 0402 | 1 | u1
C18 | 0402 | 1 | 1u
C19 | 0402 | 1 | 4u7
C2 | 0402 | 1 | u1
C20 | 0402 | 1 | 1u
C21 | 0402 | 1 | 4u7
C22 | 0402 | 1 | 1u
C23 | 0402 | 1 | u1
C24 | 0402 | 1 | u1
C25 | 0402 | 1 | u1
C26 | 0402 | 1 | u1
C3 | 0402 | 1 | u1
C4 | 0805 | 1 | 10u
C5 | 0805 | 1 | 10u
C6 | 0402 | 1 | u1
C7 | 0402 | 1 | u1
C8 | 0402 | 1 | u1
C9 | 0805 | 1 | 10u
D1 | SOT-23_Handsoldering | 1 | NUP2105
D2 | LED_D5.0mm-4_RGB_Staggered_Pins | 1 | Betrieb
D3 | LED_D5.0mm-4_RGB_Staggered_Pins | 1 | Stellgröße
D4 | SOT-23_Handsoldering | 1 | PSM712
FB1 | 0805 | 1 | 100R
J1 | JST_XH_S4B-XH-A_1x04_P2.50mm_Horizontal | 1 | AOUT
J2 | IDC-Header_2x05_P2.54mm_Vertical | 1 | BaseConnect
J3 | PinHeader_1x04_P2.54mm_Vertical | 1 | G C B A
J4 | IDC_2x03_P1.27mm_Vertical | 1 | PROG
J5 | TestPoint_THTPad_1.5x1.5mm_Drill0.7mm | 1 | S+
J6 | GT-USB-7051A | 1 | USB
J7 | TestPoint_THTPad_1.5x1.5mm_Drill0.7mm | 1 | S-
J8 | PhoenixContact_MCV_1,5_4-G-3.5_1x04_P3.50mm_Vertical | 1 | G C B A
L1 | L_Abracon_ASPI-0630LR | 1 | 4u7
NT2 | NetTie-2_SMD_Pad0.5mm | 1 | 1
Q1 | SOT-23_smaller | 1 | BC817
R1 | 0402 | 1 | 10k
R10 | 1206 | 1 | K12
R11 | 0603 | 1 | 1k
R12 | 0402 | 1 | 4k7
R13 | 0402 | 1 | 4k7
R14 | 0402 | 1 | 5k1
R15 | 0402 | 1 | 5k1
R16 | 0402 | 1 | 1K
R17 | 1206 | 1 | K12
R18 | 0402 | 1 | 1k
R19 | 0402 | 1 | 1k
R2 | 0402 | 1 | 10k
R20 | 0402 | 1 | 10k
R21 | 0402 | 1 | 1k
R22 | 0402 | 1 | 1k
R3 | 0402 | 1 | 22k
R4 | 0402 | 1 | 1k
R5 | 0402 | 1 | 10k
R6 | 0805 | 1 | 10R
R7 | 0402 | 1 | 4k7
R8 | 0402 | 1 | 68k
R9 | 0402 | 1 | 15k
SW1 | SW_SPST_TL3342 | 1 | Reset
SW2 | Switch_SS12D00 | 1 | ON CAN OFF
SW4 | Switch_SS12D00 | 1 | ON 485 OFF
SW5 | RotaryEncoder_Alps_EC11E-Switch_Vertical_H20mm | 1 | ROT1
SW6 | SW_PUSH_6mm_H13mm | 1 | GREEN
U1 | SOIC-8_3.9x4.9mm_P1.27mm | 1 | LM358
U2 | ESP32-S3-WROOM-1 | 1 | ESP32-S3-WROOM-1
U3 | SOIC-8_3.9x4.9mm_P1.27mm | 1 | SN65HVD230
U4 | SOT-23-6 | 1 | RY8310
U5 | AHT21 | 1 | AHT21
U6 | SOIC-8_3.9x4.9mm_Pitch1.27mm_pad_handsolder | 1 | NS4168
U7 | SOIC-8_3.9x4.9mm_P1.27mm | 1 | MAX3485
U8 | SOT-223-3_TabPin2 | 1 | AMS1117
U9 | TO-92_HandSolder | 1 | DS18B20
X1 | Display_LH154K-PG04_variant | 1 | Display_LH154K-PG04

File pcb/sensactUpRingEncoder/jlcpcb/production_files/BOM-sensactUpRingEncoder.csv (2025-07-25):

Comment | Designator | Footprint | LCSC | Quantity
5k1 | R14,R15,R16 | R_0402_1005Metric | C105872 | 3
10k | R11,R13,R17,R4,R47,R48,R5,R6,R7,R8 | R_0201_0603Metric | C106225 | 10
3k3 | R10,R46,R50,R51,R52,R53,R54 | R_0402_1005Metric | C137992 | 7
USB | J6 | USB_C_Receptacle_HRO_TYPE-C-31-M-12 | C165948 | 1
22R | R2,R3 | R_0805_2012Metric | C17561 | 2
MAX98357A_WLP_Package | U2 | Maxim_WLP-9_1.595x1.415_Layout3x3_P0.4mm_Ball0.27mm_Pad0.25mm_NSMD | C2682619 | 1
ToBase | J4 | Hirose_FH12-14S-0.5SH_1x14-1MP_P0.50mm_Horizontal | C2856800 | 1
Display_P169H002-CTP | X1 | Display_P169H002-CTP | C2856802 | 1
TJA1051TK-3 | U7 | HVSON-8-1EP_3x3mm_P0.65mm_EP1.6x2.4mm | C2875699 | 1
ESP32-S3-MINI-1 | U1 | ESP32-S3-MINI-1 | C2913206 | 1
AHT20 | U12 | AHT21 | C3012622 | 1
10u | C12,C13,C14,C15,C9 | C_0402_1005Metric | C315248 | 5
T3902 | MK1 | MIC_T3902 | C3171752 | 1
AO3400 | Q1 | SOT-23_smaller | C347475 | 1
PROG | J32 | PinHeader_2x03_P1.27mm_Vertical_SMD | C3975186 | 1
AMS1117-3.3 | U4 | SOT-223-3_TabPin2 | C6186 | 1
u1 | C1,C10,C11,C38,C39,C40,C41,C45,C46,C57 | C_0201_0603Metric | C76934 | 10
10n | C42,C6,C7 | C_0201_0603Metric | C76941 | 3
22u | C56,C85,C86 | C_0603_1608Metric | C86295 | 3
DS18B20U | U6 | MSOP-8_3x3mm_P0.65mm_handsolder |  | 1
RESET | SW4 | SW_Push_SPST_NO_4x3x2_handsolder |  | 1
VCNL4040 | U5 | VCNL4040_handsolder |  | 1

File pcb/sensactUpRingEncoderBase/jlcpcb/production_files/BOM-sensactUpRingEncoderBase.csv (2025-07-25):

Comment | Designator | Footprint | LCSC | Quantity
AMS1117-12 | U7 | SOT-223-3_TabPin2_HANDSOLDER |  | 1
ROT_EXT | J1 | PhoenixContact_MCV_1,5_3-G-3.5_1x03_P3.50mm_Vertical_smallerCourtyard |  | 1
10u | C55 | C_0805_2012Metric_Pad1.18x1.45mm_HandSolder |  | 1
u1 | C54 | C_0805_2012Metric_Pad1.18x1.45mm_HandSolder |  | 1
u1 | C53 | C_0805_2012Metric_Pad1.18x1.45mm_HandSolder |  | 1
10u | C48 | C_0805_2012Metric_Pad1.18x1.45mm_HandSolder |  | 1
BaseConnector | J3 | IDC-Header_2x05_P2.54mm_Vertical |  | 1
AMS1117-3.3 | U4 | SOT-223-3_TabPin2_HANDSOLDER |  | 1
M1 | R61 | R_0805_2012Metric_Pad1.20x1.40mm_HandSolder |  | 1
M1 | R62 | R_0805_2012Metric_Pad1.20x1.40mm_HandSolder |  | 1
MountingHole | H5 | MountingHole_2.2mm_M2 |  | 1
SW_Push | SW1 | Button_12mm_ANCHOR_CENTER |  | 1
u1 | C15 | C_0805_2012Metric_Pad1.18x1.45mm_HandSolder |  | 1
M1 | R64 | R_0805_2012Metric_Pad1.20x1.40mm_HandSolder |  | 1
u1 | C20 | C_0805_2012Metric_Pad1.18x1.45mm_HandSolder |  | 1
TERM ON OFF | SW2 | SW_SPDT_PCM12_handsolder |  | 1
NUP2105L | D1 | SOT-23_Handsoldering |  | 1
WS2812B | D6 | LED_WS2812B-Mini_PLCC4_3.5x3.5mm |  | 1
MountingHole | H4 | MountingHole_2.2mm_M2 |  | 1
WS2812B | D12 | LED_WS2812B-Mini_PLCC4_3.5x3.5mm |  | 1
MountingHole | H1 | MountingHole_5mm |  | 1
WS2812B | D7 | LED_WS2812B-Mini_PLCC4_3.5x3.5mm |  | 1
u1 | C22 | C_0805_2012Metric_Pad1.18x1.45mm_HandSolder |  | 1
WS2812B | D13 | LED_WS2812B-Mini_PLCC4_3.5x3.5mm |  | 1
u1 | C17 | C_0805_2012Metric_Pad1.18x1.45mm_HandSolder |  | 1
u1/16V | C81 | R_0805_2012Metric_Pad1.20x1.40mm_HandSolder |  | 1
u1/35V | C79 | R_0805_2012Metric_Pad1.20x1.40mm_HandSolder |  | 1
k12 | R1 | R_0805_2012Metric_Pad1.20x1.40mm_HandSolder |  | 1
M1 | R63 | R_0805_2012Metric_Pad1.20x1.40mm_HandSolder |  | 1
3k3 | R49 | R_0805_2012Metric_Pad1.20x1.40mm_HandSolder |  | 1
WS2812B | D15 | LED_WS2812B-Mini_PLCC4_3.5x3.5mm |  | 1
WS2812B | D4 | LED_WS2812B-Mini_PLCC4_3.5x3.5mm |  | 1
u1 | C23 | C_0805_2012Metric_Pad1.18x1.45mm_HandSolder |  | 1
u1 | C24 | C_0805_2012Metric_Pad1.18x1.45mm_HandSolder |  | 1
WS2812B | D14 | LED_WS2812B-Mini_PLCC4_3.5x3.5mm |  | 1
u1 | C16 | C_0805_2012Metric_Pad1.18x1.45mm_HandSolder |  | 1
1k | R57 | R_0805_2012Metric_Pad1.20x1.40mm_HandSolder |  | 1
u1 | C28 | C_0805_2012Metric_Pad1.18x1.45mm_HandSolder |  | 1
22u | C84 | R_0805_2012Metric_Pad1.20x1.40mm_HandSolder |  | 1
AO6800-HXY | Q3 | SOT-23-6_Handsoldering |  | 1
WS2812B | D10 | LED_WS2812B-Mini_PLCC4_3.5x3.5mm |  | 1
u1 | C26 | C_0805_2012Metric_Pad1.18x1.45mm_HandSolder |  | 1
PowerOutput | J7 | PinHeader_1x05_P2.54mm_Vertical |  | 1
u1 | C27 | C_0805_2012Metric_Pad1.18x1.45mm_HandSolder |  | 1
WS2812B | D5 | LED_WS2812B-Mini_PLCC4_3.5x3.5mm |  | 1
10u | C12 | C_0805_2012Metric_Pad1.18x1.45mm_HandSolder |  | 1
u1 | C29 | C_0805_2012Metric_Pad1.18x1.45mm_HandSolder |  | 1
WS2812B | D16 | LED_WS2812B-Mini_PLCC4_3.5x3.5mm |  | 1
MountingHole | H2 | MountingHole_5mm |  | 1
WS2812B | D17 | LED_WS2812B-Mini_PLCC4_3.5x3.5mm |  | 1
10uH | L4 | L_0630 |  | 1
WS2812B | D9 | LED_WS2812B-Mini_PLCC4_3.5x3.5mm |  | 1
MountingHole | H3 | MountingHole_2.2mm_M2 |  | 1
u1 | C10 | C_0805_2012Metric_Pad1.18x1.45mm_HandSolder |  | 1
WS2812B | D8 | LED_WS2812B-Mini_PLCC4_3.5x3.5mm |  | 1
56p | C82 | R_0805_2012Metric_Pad1.20x1.40mm_HandSolder |  | 1
u1 | C21 | C_0805_2012Metric_Pad1.18x1.45mm_HandSolder |  | 1
WS2812B | D2 | LED_WS2812B-Mini_PLCC4_3.5x3.5mm |  | 1
10u/35V | C80 | C_1206_3216Metric_Pad1.33x1.80mm_HandSolder |  | 1
AO6800-HXY | Q2 | SOT-23-6_Handsoldering |  | 1
WS2812B | D3 | LED_WS2812B-Mini_PLCC4_3.5x3.5mm |  | 1
10u | C9 | C_0805_2012Metric_Pad1.18x1.45mm_HandSolder |  | 1
u1 | C11 | C_0805_2012Metric_Pad1.18x1.45mm_HandSolder |  | 1
u1 | C18 | C_0805_2012Metric_Pad1.18x1.45mm_HandSolder |  | 1
WS2812B | D11 | LED_WS2812B-Mini_PLCC4_3.5x3.5mm |  | 1
u1 | C14 | C_0805_2012Metric_Pad1.18x1.45mm_HandSolder |  | 1
10k | R60 | R_0805_2012Metric_Pad1.20x1.40mm_HandSolder |  | 1
22u | C83 | R_0805_2012Metric_Pad1.20x1.40mm_HandSolder |  | 1
1k | R56 | R_0805_2012Metric_Pad1.20x1.40mm_HandSolder |  | 1
M1 | R59 | R_0805_2012Metric_Pad1.20x1.40mm_HandSolder |  | 1
u1 | C19 | C_0805_2012Metric_Pad1.18x1.45mm_HandSolder |  | 1
1k | R58 | R_0805_2012Metric_Pad1.20x1.40mm_HandSolder |  | 1
TPS54202DDC | U27 | SOT-23-6_Handsoldering |  | 1
1k | R55 | R_0805_2012Metric_Pad1.20x1.40mm_HandSolder |  | 1
RotaryEncoder | SW3 | Encoder Alps-Alpine EC35 |  | 1
u1 | C25 | C_0805_2012Metric_Pad1.18x1.45mm_HandSolder |  | 1
u1 | C13 | C_0805_2012Metric_Pad1.18x1.45mm_HandSolder |  | 1
ToBase | J5 | Hirose_FH12-14S-0.5SH_1x14-1MP_P0.50mm_Horizontal_handsolder |  | 1
74AHCT1G125 | U5 | SOT-353_SC-70-5_Handsoldering |  | 1

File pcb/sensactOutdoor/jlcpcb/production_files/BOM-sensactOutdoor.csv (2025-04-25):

Comment | Designator | Footprint | LCSC | Quantity
m1 | C1,C2,C20 | C_1206_3216Metric | C15008 | 3
u1 | C15 | C_0805_2012Metric_Pad1.18x1.45mm_HandSolder | C1525 | 1
10u | C12 | C_0805_2012Metric_Pad1.18x1.45mm_HandSolder | C19702 | 1
LED0 | D12,D13,D14,D15,D16 | LED_0805_2012Metric_Pad1.15x1.40mm_HandSolder | C2286 | 5
0R15 | R13,R2 | R_1206_3216Metric_Pad1.30x1.75mm_HandSolder | C25271 | 2
22uH | L1,L2 | L_0630 | C408455 | 2
u1 | C13,C17,C18,C19,C25,C27,C28,C30,C32,C9 | C_0805_2012Metric_Pad1.18x1.45mm_HandSolder | C49678 | 10
22u | C16 | C_0805_2012Metric_Pad1.18x1.45mm_HandSolder | C59461 | 1
SM4007PL | D10,D2,D3,D4 | D_SOD-123_handsolder | C64898 | 4
BC847 | Q6 | SOT-23_Handsoldering | C8512 | 1
LED1 | J22 | JST_XH_B2B-XH-A_1x02_P2.50mm_Vertical |  | 1
H | H6 | MountingHole_3.2mm_M3 |  | 1
L1 | J23 | Flachstecker gewinkelt 4,8 oder 6,35mm |  | 1
LED1 | J15 | JST_XH_B2B-XH-A_1x02_P2.50mm_Vertical |  | 1
ALDP105W | K1 | RELAY_ALDP105W |  | 1
H | H1 | MountingHole_3.2mm_M3 |  | 1
LED1 | J10 | JST_XH_B2B-XH-A_1x02_P2.50mm_Vertical |  | 1
N | J29 | Flachstecker gewinkelt 4,8 oder 6,35mm |  | 1
LED Out | J17 | PhoenixContact_MCV_1,5_4-G-3.5_1x04_P3.50mm_Vertical |  | 1
H | H5 | MountingHole_3.2mm_M3 |  | 1
INFO | D23 | LED_0805_2012Metric_Pad1.15x1.40mm_HandSolder |  | 1
RGB | J13 | PinHeader_1x03_P2.54mm_Vertical |  | 1
DS18B20 | U10 | TO-92L_HandSolder |  | 1
LED1 | J19 | JST_XH_B2B-XH-A_1x02_P2.50mm_Vertical |  | 1
LED0 | TP3 | TestPoint_THTPad_D2.0mm_Drill1.0mm |  | 1
10D561K | RV1 | RV_Disc_D12mm_W3.9mm_P7.5mm |  | 1
N | J27 | Flachstecker gewinkelt 4,8 oder 6,35mm |  | 1
L_IN | J9 | Flachstecker gewinkelt 4,8 oder 6,35mm |  | 1
T2.0 | F1 | Fuse_Littelfuse_372_D8.50mm |  | 1
MAX98357_MODULE | U1 | PinHeader_1x07_P2.54mm_Vertical |  | 1
LED1 | J12 | JST_XH_B2B-XH-A_1x02_P2.50mm_Vertical |  | 1
PE | J28 | Flachstecker gewinkelt 4,8 oder 6,35mm |  | 1
H | H8 | MountingHole_3.2mm_M3 |  | 1
L3 | J25 | Flachstecker gewinkelt 4,8 oder 6,35mm |  | 1
ALDP105W | K2 | RELAY_ALDP105W |  | 1
N_IN | J16 | Flachstecker gewinkelt 4,8 oder 6,35mm |  | 1
LED1 | J11 | JST_XH_B2B-XH-A_1x02_P2.50mm_Vertical |  | 1
PROG | SW2 | SW_SPST_TL3342_smaller_handsolder |  | 1
LED1 | J20 | JST_XH_B2B-XH-A_1x02_P2.50mm_Vertical |  | 1
USB | J1 | PinHeader_1x04_P2.54mm_Vertical |  | 1
22n/250V | C23 | C_Rect_L11.0mm_W5.1mm_P10.00mm_MKT |  | 1
H | H3 | MountingHole_3.2mm_M3 |  | 1
TERM OFF | SW1 | Switch_SS12D00 |  | 1
PROG | J32 | PinHeader_2x03_P2.54mm_Vertical |  | 1
ALDP105W | K4 | RELAY_ALDP105W |  | 1
RESET | SW4 | SW_SPST_TL3342_smaller_handsolder |  | 1
L4 | J26 | Flachstecker gewinkelt 4,8 oder 6,35mm |  | 1
HLK-30M24C | PS2 | Converter_ACDC_Hi-Link_HLK-30Mxx |  | 1
LED1 | J18 | JST_XH_B2B-XH-A_1x02_P2.50mm_Vertical |  | 1
PE | J30 | Flachstecker gewinkelt 4,8 oder 6,35mm |  | 1
H | H2 | MountingHole_3.2mm_M3 |  | 1
ALDP105W | K3 | RELAY_ALDP105W |  | 1
Info1 | D7 | LED_D5.0mm-4_RGB_Staggered_Pins |  | 1
LED1 | J21 | JST_XH_B2B-XH-A_1x02_P2.50mm_Vertical |  | 1
H | H4 | MountingHole_3.2mm_M3 |  | 1
PE_IN | J14 | Flachstecker gewinkelt 4,8 oder 6,35mm |  | 1
EXT1 | J7 | JST_XH_B5B-XH-A_1x05_P2.50mm_Vertical |  | 1
L2 | J24 | Flachstecker gewinkelt 4,8 oder 6,35mm |  | 1
CAN | J6 | PhoenixContact_MCV_1,5_4-G-3.5_1x04_P3.50mm_Vertical |  | 1
H | H7 | MountingHole_3.2mm_M3 |  | 1
1k | R7 | R_0805_2012Metric_Pad1.20x1.40mm_HandSolder |  | 1
MAINS | D1 | LED_0805_2012Metric_Pad1.15x1.40mm_HandSolder |  | 1
LED Out | J8 | ÖLFLEX 4x1mm2 |  | 1
AMS1117-3.3 | U5 | SOT-223-3_TabPin2_HANDSOLDER |  | 1
470K | R31 | R_2512_6332Metric_Pad1.40x3.35mm_HandSolder |  | 1
1k | R1 | R_0805_2012Metric_Pad1.20x1.40mm_HandSolder |  | 1
3k3 | R16 | R_2512_6332Metric_Pad1.40x3.35mm_HandSolder |  | 1
470K | R30 | R_2512_6332Metric_Pad1.40x3.35mm_HandSolder |  | 1
15k | R10 | R_0805_2012Metric_Pad1.20x1.40mm_HandSolder |  | 1
10u | C21 | C_1206_3216Metric_Pad1.33x1.80mm_HandSolder |  | 1
k1 | R32 | R_0805_2012Metric_Pad1.20x1.40mm_HandSolder |  | 1
NUP2105 | D8 | SOT-23_Handsoldering |  | 1
BC847 | Q7 | SOT-23_Handsoldering |  | 1
BC847 | Q9 | SOT-23_Handsoldering |  | 1
K12 | R12 | R_1206_3216Metric_Pad1.30x1.75mm_HandSolder |  | 1
10uH | L3 | L_0630 |  | 1
10u | C22 | C_0805_2012Metric_Pad1.18x1.45mm_HandSolder |  | 1
10u | C31 | C_1206_3216Metric_Pad1.33x1.80mm_HandSolder |  | 1
TPS92200D2DDCR | U2 | SOT-23-6_Handsoldering |  | 1
1k | R8 | R_0805_2012Metric_Pad1.20x1.40mm_HandSolder |  | 1
4k7 | R25 | R_0805_2012Metric_Pad1.20x1.40mm_HandSolder |  | 1
6k8 | R17 | R_0805_2012Metric_Pad1.20x1.40mm_HandSolder |  | 1
10k | R3 | R_0805_2012Metric_Pad1.20x1.40mm_HandSolder |  | 1
TPS54202DDC | U9 | SOT-23-6_Handsoldering |  | 1
TPS92200D2DDCR | U3 | SOT-23-6_Handsoldering |  | 1
k47 | R38 | R_0805_2012Metric_Pad1.20x1.40mm_HandSolder |  | 1
3k3 | R28 | R_2512_6332Metric_Pad1.40x3.35mm_HandSolder |  | 1
10u | C24 | C_1206_3216Metric_Pad1.33x1.80mm_HandSolder |  | 1
k47 | R34 | R_0805_2012Metric_Pad1.20x1.40mm_HandSolder |  | 1
1N5819WS | D9 | D_SMA_Handsoldering |  | 1
10k | R47 | R_0805_2012Metric_Pad1.20x1.40mm_HandSolder |  | 1
k47 | R33 | R_0805_2012Metric_Pad1.20x1.40mm_HandSolder |  | 1
10k | R11 | R_0805_2012Metric_Pad1.20x1.40mm_HandSolder |  | 1
k1 | R9 | R_0805_2012Metric_Pad1.20x1.40mm_HandSolder |  | 1
10u | C26 | C_1206_3216Metric_Pad1.33x1.80mm_HandSolder |  | 1
k1 | R48 | R_0805_2012Metric_Pad1.20x1.40mm_HandSolder |  | 1
SN65HVD230 | U7 | SOIC-8_3.9x4.9mm_Pitch1.27mm_handsolder |  | 1
10u | C14 | C_0805_2012Metric_Pad1.18x1.45mm_HandSolder |  | 1
22u | C34 | C_0805_2012Metric_Pad1.18x1.45mm_HandSolder |  | 1
4k7 | R26 | R_0805_2012Metric_Pad1.20x1.40mm_HandSolder |  | 1
10k | R29 | R_0805_2012Metric_Pad1.20x1.40mm_HandSolder |  | 1
22u | C35 | C_0805_2012Metric_Pad1.18x1.45mm_HandSolder |  | 1
22k | R4 | R_0805_2012Metric_Pad1.20x1.40mm_HandSolder |  | 1
k47 | R14 | R_0805_2012Metric_Pad1.20x1.40mm_HandSolder |  | 1
BC847 | Q8 | SOT-23_Handsoldering |  | 1
10u | C10 | C_1206_3216Metric_Pad1.33x1.80mm_HandSolder |  | 1
EL817 | U8 | SO-4_7.6x3.6mm_P2.54mm_handsolder |  | 1
M1 | R15 | R_0805_2012Metric_Pad1.20x1.40mm_HandSolder |  | 1
1k | R5 | R_0805_2012Metric_Pad1.20x1.40mm_HandSolder |  | 1
1k | R6 | R_0805_2012Metric_Pad1.20x1.40mm_HandSolder |  | 1
56p | C33 | C_0805_2012Metric_Pad1.18x1.45mm_HandSolder |  | 1
6k8 | R18 | R_0805_2012Metric_Pad1.20x1.40mm_HandSolder |  | 1
1k | R46 | R_0805_2012Metric_Pad1.20x1.40mm_HandSolder |  | 1
u1 | C29 | C_0805_2012Metric |  | 1
ESP32-S3-WROOM-1 | U11 | ESP32-S3-WROOM-1_handsolder |  | 1
k47 | R37 | R_0805_2012Metric_Pad1.20x1.40mm_HandSolder |  | 1
NRF24L01_Breakout_SMD | U4 | NRF24L01-Module-SMD |  | 1

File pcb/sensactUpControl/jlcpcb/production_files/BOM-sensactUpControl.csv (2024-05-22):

Comment | Designator | Footprint | LCSC
1k | R3 | R_0805_2012Metric_Pad1.20x1.40mm_HandSolder
MAX3485 | U2 | SOIC-8_3.9x4.9mm_Pitch1.27mm_handsolder
4k7 | R1 | R_0805_2012Metric_Pad1.20x1.40mm_HandSolder
I2C_Sensor | J11 | PinHeader_1x04_P2.54mm_Vertical
K12 | R8 | R_1206_3216Metric_Pad1.30x1.75mm_HandSolder
K12 | R5 | R_1206_3216Metric_Pad1.30x1.75mm_HandSolder
22u | C9 | C_0805_2012Metric_Pad1.18x1.45mm_HandSolder
Buzzer | BZ1 | XDCR_CMT-7525-80-SMT-TR_handsolder
BC847 | Q1 | SOT-23_Handsoldering
1k | R14 | R_0805_2012Metric_Pad1.20x1.40mm_HandSolder
NRF24L01_Breakout | U7 | nRF24L01_Breakout
10k | R12 | R_0805_2012Metric_Pad1.20x1.40mm_HandSolder
ON TERM CAN | SW2 | SW_SPDT_PCM12_handsolder
4k7 | R7 | R_0805_2012Metric_Pad1.20x1.40mm_HandSolder
Boot | SW5 | SW_SPST_TL3342_smaller_handsolder
u1 | C1 | C_0805_2012Metric_Pad1.18x1.45mm_HandSolder
GND | J2 | PinHeader_1x02_P2.00mm_Vertical
4k7 | R2 | R_0805_2012Metric_Pad1.20x1.40mm_HandSolder
LED | D7 | LED_PLCC_2835_Handsoldering
ESP32-S3-WROOM-1 | U1 | ESP32-WROOM-32_HANDSOLDER
CentralHole | H1 | MountingHole_3.2mm_M3
-USB+ | J1 | PinHeader_1x02_P2.00mm_Vertical
DS18B20 | U8 | TO-92_HandSolder
1k | R4 | R_0805_2012Metric_Pad1.20x1.40mm_HandSolder
LH114 | X1 | FP-114 13pol top only
PROG | J10 | IDC_2x03_P1.27mm_Vertical
k22 | R24 | R_1206_3216Metric_Pad1.30x1.75mm_HandSolder
Reset | SW4 | SW_SPST_TL3342_smaller_handsolder
u1 | C10 | C_0805_2012Metric_Pad1.18x1.45mm_HandSolder
SN65HVD230 | U3 | SOIC-8_3.9x4.9mm_Pitch1.27mm_handsolder
1k | R6 | R_0805_2012Metric_Pad1.20x1.40mm_HandSolder
10k | R13 | R_0805_2012Metric_Pad1.20x1.40mm_HandSolder
u1 | C8 | C_0805_2012Metric_Pad1.18x1.45mm_HandSolder
ON TERM 485 | SW1 | SW_SPDT_PCM12_handsolder
BC847 | Q3 | SOT-23_Handsoldering
PSM712 | D1 | SOT-23_Handsoldering
1k | R11 | R_0805_2012Metric_Pad1.20x1.40mm_HandSolder
4k7 | R17 | R_0805_2012Metric_Pad1.20x1.40mm_HandSolder
1k | R9 | R_0805_2012Metric_Pad1.20x1.40mm_HandSolder
u1 | C2 | C_0805_2012Metric_Pad1.18x1.45mm_HandSolder
BaseConnect | J8 | PinHeader_2x07_P2.54mm_Vertical
NUP2105 | D2 | SOT-23_Handsoldering
k1 | R10 | R_0805_2012Metric_Pad1.20x1.40mm_HandSolder
1u | C3 | C_0805_2012Metric_Pad1.18x1.45mm_HandSolder
1u | C4 | C_0805_2012Metric_Pad1.18x1.45mm_HandSolder

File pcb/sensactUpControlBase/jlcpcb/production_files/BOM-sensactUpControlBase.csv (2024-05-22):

Comment | Designator | Footprint | LCSC
10u | L1 | L_0630
GND T0 T1 | J3 | KF250-3.5-3P-A
BaseConnect | J1 | PinHeader_2x07_P2.54mm_Vertical
~ | J9 | WAGO_250-210
A RS485 B | J4 | KF250-3.5-3P-A
~ | J2 | WAGO_250-210
22u | C4 | C_0805_2012Metric_Pad1.18x1.45mm_HandSolder
10u | C1 | C_1206_3216Metric_Pad1.33x1.80mm_HandSolder
56p | C3 | C_0805_2012Metric_Pad1.18x1.45mm_HandSolder
u1 | C2 | C_0805_2012Metric_Pad1.18x1.45mm_HandSolder
PC817 | U2 | mdip_4_handsolder
22u | C5 | C_0805_2012Metric_Pad1.18x1.45mm_HandSolder
22k | R2 | R_0805_2012Metric_Pad1.20x1.40mm_HandSolder
M1 | R1 | R_0805_2012Metric_Pad1.20x1.40mm_HandSolder
k22 | R3 | R_0805_2012Metric_Pad1.20x1.40mm_HandSolder
TPS54202DDC | U1 | SOT-23-6_Handsoldering

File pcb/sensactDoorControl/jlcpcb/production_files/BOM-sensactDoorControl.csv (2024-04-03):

Comment | Designator | Footprint | LCSC
1k | R14 | R_0805_2012Metric_Pad1.20x1.40mm_HandSolder
4k7 | R3 | R_0805_2012Metric_Pad1.20x1.40mm_HandSolder
PSM712 | D2 | SOT-23_Handsoldering
PC817 | U3 | mdip_4_handsolder
NUP2105 | D1 | SOT-23_Handsoldering
k22/1k | R11 | R_0805_2012Metric_Pad1.20x1.40mm_HandSolder
1k | R1 | R_0805_2012Metric_Pad1.20x1.40mm_HandSolder
K12 | R4 | R_1206_3216Metric_Pad1.30x1.75mm_HandSolder
56p | C1 | C_0805_2012Metric_Pad1.18x1.45mm_HandSolder
4k7 | R13 | R_0805_2012Metric_Pad1.20x1.40mm_HandSolder
u1 | C8 | C_0805_2012Metric_Pad1.18x1.45mm_HandSolder
ON TERM | SW3 | SW_SPDT_PCM12_handsolder
ESP32-WROOM-E | U1 | ESP32-WROOM-32_HANDSOLDER
u1 | C7 | C_0805_2012Metric_Pad1.18x1.45mm_HandSolder
TERM ON | SW4 | SW_SPDT_PCM12_handsolder
SN65HVD230 | U4 | SOIC-8_3.9x4.9mm_Pitch1.27mm_handsolder
K12 | R9 | R_1206_3216Metric_Pad1.30x1.75mm_HandSolder
u1 | C3 | C_0805_2012Metric_Pad1.18x1.45mm_HandSolder
G16 | J9 | TestPoint_THTPad_D1.5mm_Drill0.7mm
G23 | J12 | TestPoint_THTPad_D1.5mm_Drill0.7mm
1k | R2 | R_0805_2012Metric_Pad1.20x1.40mm_HandSolder
22u | C10 | C_0805_2012Metric_Pad1.18x1.45mm_HandSolder
M1 | R5 | R_0805_2012Metric_Pad1.20x1.40mm_HandSolder
1k | R15 | R_0805_2012Metric_Pad1.20x1.40mm_HandSolder
4k7 | R12 | R_0805_2012Metric_Pad1.20x1.40mm_HandSolder
MAX3485 | U5 | SOIC-8_3.9x4.9mm_Pitch1.27mm_handsolder
10u | C11 | C_1206_3216Metric_Pad1.33x1.80mm_HandSolder
10u | L2 | L_0630
Reset | SW2 | SW_SPST_TL3342_smaller_handsolder
1k | R10 | R_0805_2012Metric_Pad1.20x1.40mm_HandSolder
u1 | C14 | C_0805_2012Metric_Pad1.18x1.45mm_HandSolder
I2C | J13 | JST_XH_B6B-XH-A_1x06_P2.50mm_Vertical
22k | R8 | R_0805_2012Metric_Pad1.20x1.40mm_HandSolder
Fingerprint | J10 | JST_SH_SM06B-SRSS-TB_1x06-1MP_P1.00mm_Horizontal_handsolder
Can+24V | J2 | PhoenixContact_MC_1,5_4-G-3.5_1x04_P3.50mm_Horizontal_smallerCourtyard
Boot | SW1 | SW_SPST_TL3342_smaller_handsolder
10k | R7 | R_0805_2012Metric_Pad1.20x1.40mm_HandSolder
u1 | C9 | C_0805_2012Metric_Pad1.18x1.45mm_HandSolder
INFO | D3 | LED_0805_2012Metric_Pad1.15x1.40mm_HandSolder
RS485 | J3 | PhoenixContact_MC_1,5_4-G-3.5_1x04_P3.50mm_Horizontal_smallerCourtyard
22u | C15 | C_0805_2012Metric_Pad1.18x1.45mm_HandSolder
Finger_large | J1 | PhoenixContact_MC_1,5_4-G-3.5_1x04_P3.50mm_Horizontal_smallerCourtyard
10k | R6 | R_0805_2012Metric_Pad1.20x1.40mm_HandSolder
TPS54202DDC | U2 | SOT-23-6_Handsoldering
Motor | J5 | PhoenixContact_MC_1,5_4-G-3.5_1x04_P3.50mm_Horizontal_smallerCourtyard
PROG | J4 | JST_SH_SM06B-SRSS-TB_1x06-1MP_P1.00mm_Horizontal_handsolder
Buzzer | BZ1 | XDCR_CMT-7525-80-SMT-TR_handsolder
BC847 | Q1 | SOT-23_Handsoldering
22u | C2 | C_0805_2012Metric_Pad1.18x1.45mm_HandSolder
1k | R18 | R_0805_2012Metric_Pad1.20x1.40mm_HandSolder
M1 | R17 | R_0805_2012Metric_Pad1.20x1.40mm_HandSolder
PNP | Q2 | SOT-23_Handsoldering
k22 | R16 | R_0805_2012Metric_Pad1.20x1.40mm_HandSolder
D | D4 | D_SOD-123_handsolder
BC847 | Q3 | SOT-23_Handsoldering
LCD | J6 | PinHeader_1x04_P2.54mm_Vertical
1k | R19 | R_0805_2012Metric_Pad1.20x1.40mm_HandSolder

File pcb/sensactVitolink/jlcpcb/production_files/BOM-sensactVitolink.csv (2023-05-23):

Comment | Designator | Footprint | LCSC
PT26-21B/TR8 | Q1 | LED_1206_3216Metric_ReverseMount_Hole1.8x2.4mm | C131248
u1 | C1,C2,C3,C8 | C_0402_1005Metric | C1525
10u | C9 | C_0402_1005Metric | C15525
10u | C7 | C_0603_1608Metric | C19702
k1 | R7 | R_0402_1005Metric | C25076
10k | R6,R8,R9 | R_0402_1005Metric | C25744
4k7 | R1 | R_0402_1005Metric | C25900
5k1 | R10,R2 | R_0402_1005Metric | C25905
HIR25-21C/L423/2T | D1 | LED_1206_3216Metric_ReverseMount_Hole1.8x2.4mm | C282224
USB | J4 | GT-USB-7051A | C2843970
ESP32-S3-MINI-1 | U1 | ESP32-S3-MINI-1U | C2980299
BOOT | SW3 | SW_SPST_TL3342 | C318884
22u | C4 | C_0603_1608Metric | C59461
AMS1117-3.3 | U2 | SOT-223-3_TabPin2 | C6186
SRV05-4 | U3 | SOT-23-6 | C85364
K1..K18 | R5 | R_0805_2012Metric_Pad1.20x1.40mm_HandSolder
IR_TX | TP1 | TestPoint_Pad_D1.5mm
PROG | J1 | IDC_2x03_P1.27mm_Vertical
NUP2105 | D2 | SOT-23_Handsoldering
Reset | SW2 | Button_2x4x3,5_handsolder
SN65HVD230 | U4 | SOIC-8_3.9x4.9mm_Pitch1.27mm_handsolder
5V CL CH GN | J3 | PhoenixContact_MCV_1,5_4-G-3.5_1x04_P3.50mm_Vertical
MountingHole | H1 | MountingHole_2.2mm_M2
Ext | J2 | PinHeader_1x08_P2.54mm_Horizontal
IR_RX | TP2 | TestPoint_Pad_D1.5mm
PU | R4 | R_0805_2012Metric_Pad1.20x1.40mm_HandSolder
MountingHole | H2 | MountingHole_2.2mm_M2
IPS_240_240 | U5 | IPS_240_240_1.3
PU | R3 | R_0805_2012Metric_Pad1.20x1.40mm_HandSolder

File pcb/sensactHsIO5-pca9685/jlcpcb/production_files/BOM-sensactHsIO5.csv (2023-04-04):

Comment | Designator | Footprint | LCSC
u47 | C8 | C_0805_2012Metric | C13967
u1 | C11,C2,C9 | C_0402_1005Metric | C1525
K15 | R12,R13,R15,R16,R17,R18,R19,R21,R22,R23,R24,R25,R3,R5,R6,R9 | R_0805_2012Metric | C17471
4k7 | R11 | R_1206_3216Metric | C17936
ULN2803A | U8,U9 | SOIC-18W_7.5x11.6mm_P1.27mm | C181731
k22 | R20,R69,R70,R71,R72,R73,R74,R75,R76,R77,R78,R79,R80,R81,R82,R83,R84 | R_0402_1005Metric | C25091
10k | R10,R4 | R_0402_1005Metric | C25744
22k | R14,R8 | R_0402_1005Metric | C25768
4k7 | R7 | R_0402_1005Metric | C25900
PCA9685PW | U3 | TSSOP-28_4.4x9.7mm_Pitch0.65mm_handsolder | C2678753
22u | C7 | C_0603_1608Metric | C59461
LM358 | U1 | SOIC-8_3.9x4.9mm_P1.27mm | C7950
24V active | D1,D10,D11,D12,D13,D14,D15,D16,D17,D18,D19,D2,D20,D5,D6,D7,D8,D9 | LED_1606 | C965863
AO1 | TP1 | TestPoint_Pad_2.0x2.0mm
4k7opt | R1 | R_0402_1005Metric
SCL | JP33 | SolderJumper-2_P1.3mm_Bridged2Bar_RoundedPad1.0x1.5mm
A4 | JP7 | SolderJumper-3_P1.3mm_Open_RoundedPad1.0x1.5mm_NumberLabels
L78L15_SOT89 | U4 | SOT-89-3_Handsoldering
A1 | JP4 | SolderJumper-3_P1.3mm_Open_RoundedPad1.0x1.5mm_NumberLabels
4k7opt | R2 | R_0402_1005Metric
A0 | JP3 | SolderJumper-3_P1.3mm_Open_RoundedPad1.0x1.5mm_NumberLabels
24V LED | JP24 | SolderJumper-2_P1.3mm_Open_RoundedPad1.0x1.5mm
SDA | JP34 | SolderJumper-2_P1.3mm_Bridged2Bar_RoundedPad1.0x1.5mm
A3 | JP6 | SolderJumper-3_P1.3mm_Open_RoundedPad1.0x1.5mm_NumberLabels
A2 | JP5 | SolderJumper-3_P1.3mm_Open_RoundedPad1.0x1.5mm_NumberLabels
3V LED | JP25 | SolderJumper-2_P1.3mm_Open_RoundedPad1.0x1.5mm
Auto Manu | SW7 | SW_SPDT_PCM12_handsolder
AO0 | TP2 | TestPoint_Pad_2.0x2.0mm
ULN_CPU | JP8 | SolderJumper-3_P1.3mm_Open_RoundedPad1.0x1.5mm
ULN_CPU | JP16 | SolderJumper-3_P1.3mm_Open_RoundedPad1.0x1.5mm
ULN_CPU | JP11 | SolderJumper-3_P1.3mm_Open_RoundedPad1.0x1.5mm
ULN_CPU | JP10 | SolderJumper-3_P1.3mm_Open_RoundedPad1.0x1.5mm
ULN_CPU | JP18 | SolderJumper-3_P1.3mm_Open_RoundedPad1.0x1.5mm
SW_DIP_x08 | SW5 | SW_DIP_SPSTx08_Piano
Conn_01x08 | J4 | KF141R-8p
Bus | J8 | IDC-Header_2x05_P2.54mm_Horizontal_tightCrtYd
ULN_CPU | JP17 | SolderJumper-3_P1.3mm_Open_RoundedPad1.0x1.5mm
ULN_CPU | JP14 | SolderJumper-3_P1.3mm_Open_RoundedPad1.0x1.5mm
ULN_CPU | JP9 | SolderJumper-3_P1.3mm_Open_RoundedPad1.0x1.5mm
ULN_CPU | JP2 | SolderJumper-3_P1.3mm_Open_RoundedPad1.0x1.5mm
ULN_CPU | JP15 | SolderJumper-3_P1.3mm_Open_RoundedPad1.0x1.5mm
SW_DIP_x08 | SW4 | SW_DIP_SPSTx08_Piano
ULN_CPU | JP20 | SolderJumper-3_P1.3mm_Open_RoundedPad1.0x1.5mm
ULN_CPU | JP19 | SolderJumper-3_P1.3mm_Open_RoundedPad1.0x1.5mm
ULN_CPU | JP13 | SolderJumper-3_P1.3mm_Open_RoundedPad1.0x1.5mm
ULN_CPU | JP1 | SolderJumper-3_P1.3mm_Open_RoundedPad1.0x1.5mm
Conn_01x08 | J5 | KF141R-8p
ULN_CPU | JP21 | SolderJumper-3_P1.3mm_Open_RoundedPad1.0x1.5mm
ULN_CPU | JP12 | SolderJumper-3_P1.3mm_Open_RoundedPad1.0x1.5mm
ULN_CPU | JP22 | SolderJumper-3_P1.3mm_Open_RoundedPad1.0x1.5mm
ULN_CPU | JP23 | SolderJumper-3_P1.3mm_Open_RoundedPad1.0x1.5mm
Conn_01x08 | J3 | PhoenixContact_MC_0,5_8-G-2.5_1x08_P2.50mm_Horizontal
Conn_01x08 | J1 | PhoenixContact_MC_0,5_8-G-2.5_1x08_P2.50mm_Horizontal
Conn_01x08 | J2 | PhoenixContact_MC_0,5_8-G-2.5_1x08_P2.50mm_Horizontal

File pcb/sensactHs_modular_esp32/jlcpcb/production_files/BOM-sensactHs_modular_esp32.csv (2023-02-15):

Comment | Designator | Footprint | LCSC
VOL LEFT | RV2 | Potentiometer_Alps_RK09K_Single_Vertical
Housing | N1 | KiCad-Logo2_5mm_SilkScreen
u1 | C1 | C_0805_2012Metric_Pad1.18x1.45mm_HandSolder
AMS1117 | U6 | SOT-223-3_TabPin2_HANDSOLDER
CAN | J2 | PhoenixContact_MC_1,5_5-G-3.81_1x05_P3.81mm_Horizontal
24V | J5 | PhoenixContact_MC_1,5_2-G-3.5_1x02_P3.50mm_Horizontal
NetTie_2 | NT1 | NetTie-2_SMD_Pad2.0mm
DCDC_MP2315 | U5 | MODULE_STEPDOWN
MODULE_TPA3110 | U3 | TPA3110_module
Housing | N2 | KiCad-Logo2_5mm_SilkScreen
CAN | J3 | PhoenixContact_MC_1,5_5-G-3.81_1x05_P3.81mm_Horizontal
Speaker | J4 | PhoenixContact_MC_1,5_5-G-3.81_1x05_P3.81mm_Horizontal
SN65HVD230 | U2 | SOIC-8_3.9x4.9mm_P1.27mm
22u | C5 | C_1206_3216Metric_Pad1.33x1.80mm_HandSolder
MODULE_PCM5102 | U4 | MODULE_PCM5102A
TERM ON | SW1 | Switch_SS12D00
ESP32-S3-DevKitC | U1 | AIthinker_ESP32_S3
W5500_mini | M1 | W5500-mini
VOL RIGHT | RV1 | Potentiometer_Alps_RK09K_Single_Vertical
u1 | C3 | C_0805_2012Metric_Pad1.18x1.45mm_HandSolder
22u | C2 | C_1206_3216Metric_Pad1.33x1.80mm_HandSolder
u1 | C4 | C_0805_2012Metric_Pad1.18x1.45mm_HandSolder
4k7 | R1 | R_0805_2012Metric_Pad1.20x1.40mm_HandSolder
SensactBusConnector | J1 | IDC-Header_2x05_P2.54mm_Horizontal
NUP2105 | D1 | SOT-23_Handsoldering
K12 | R2 | R_1206_3216Metric_Pad1.30x1.75mm_HandSolder
4k7 | R4 | R_0805_2012Metric_Pad1.20x1.40mm_HandSolder
4k7 | R3 | R_0805_2012Metric_Pad1.20x1.40mm_HandSolder

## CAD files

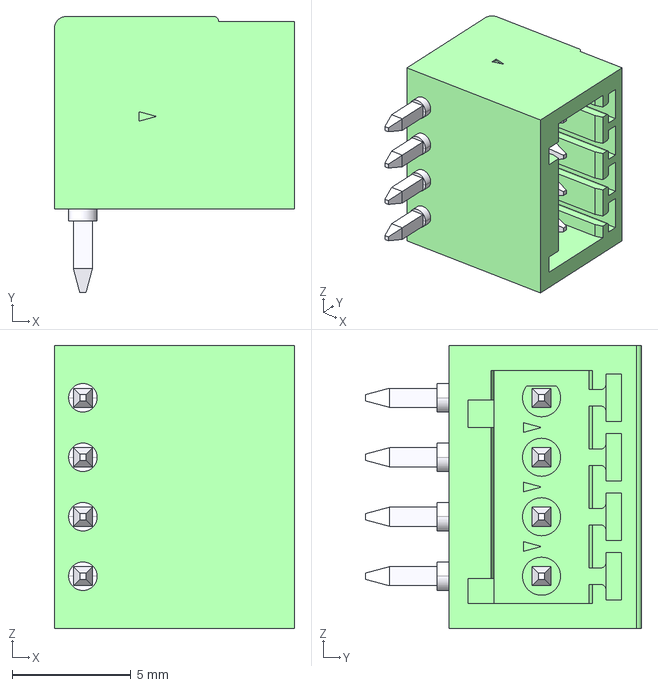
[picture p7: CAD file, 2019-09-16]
pcb/kicad-libs/sensact.3d/pxc_1881464_00_MC-0-5-4-G-2-5_3D.stp
10.1 x 11.6 x 11.9 mm

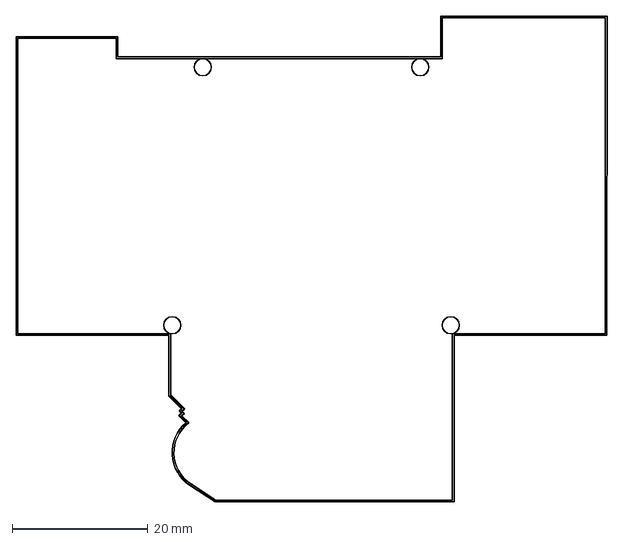
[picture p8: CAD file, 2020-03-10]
pcb/platine-edgeCuts.dxf
87.0 x 71.5 mm

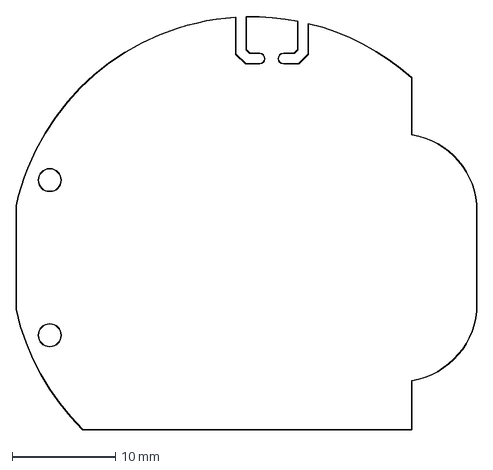
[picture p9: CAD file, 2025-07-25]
pcb/sensactUpRingEncoder/PCBOutline.dxf
44.6 x 40.0 mm

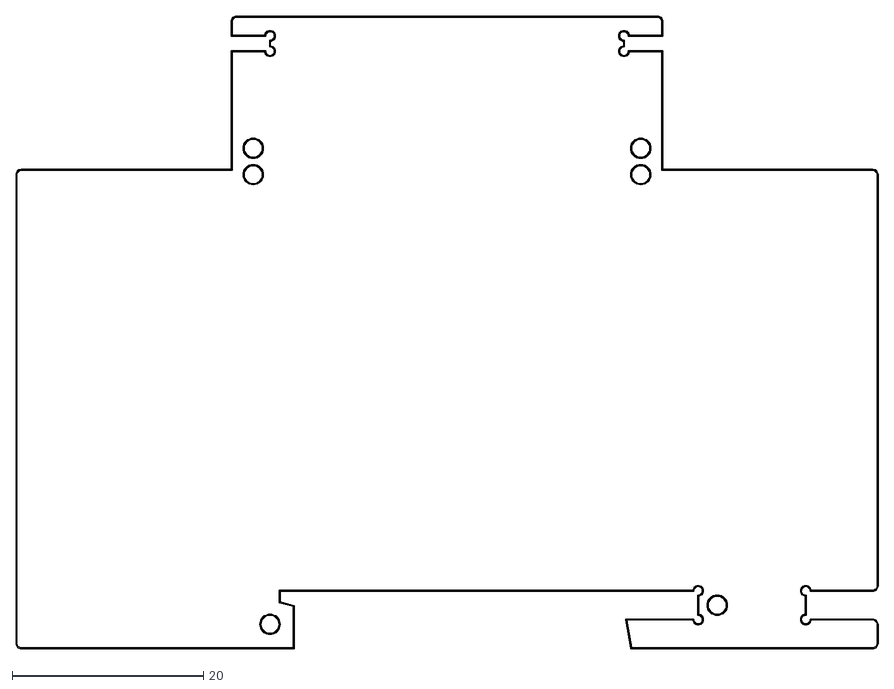
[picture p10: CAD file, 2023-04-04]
pcb/din_schiene_seitenwand/plots/din_schiene_seitenwand-Edge_Cuts.dxf
90.1 x 66.1

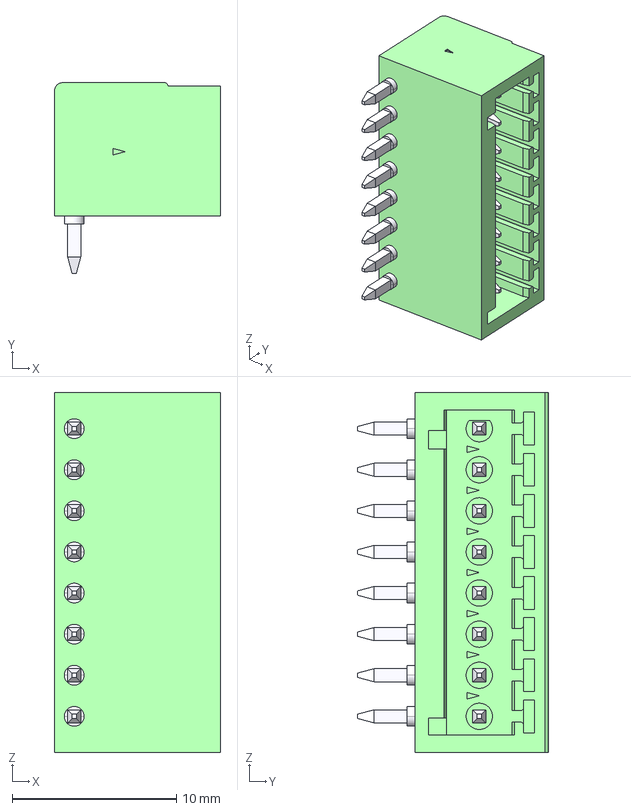
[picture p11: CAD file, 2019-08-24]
pcb/kicad-libs/sensact.3d/pxc_1881503_00_MC-0-5-8-G-2-5_3D.stp
10.1 x 11.6 x 21.9 mm

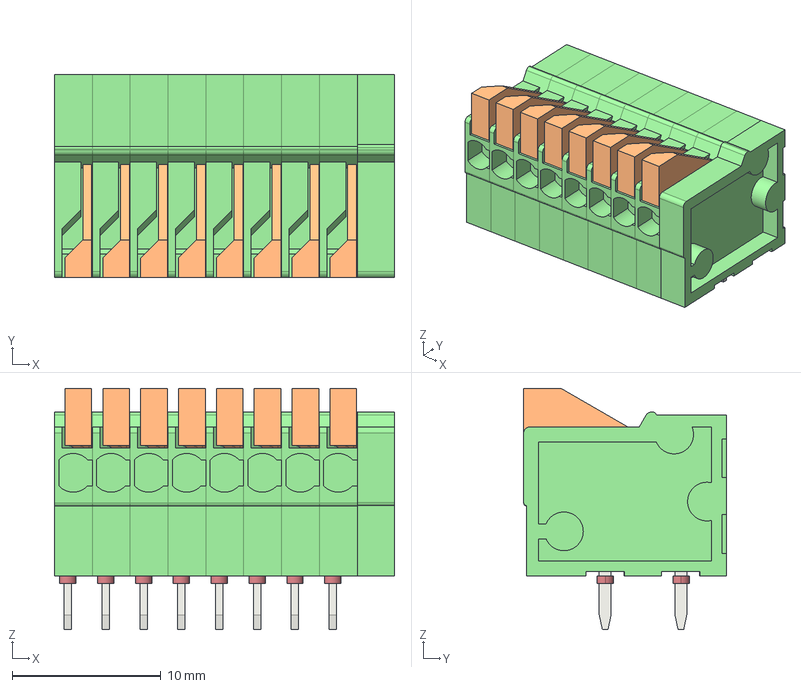
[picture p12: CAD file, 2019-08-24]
pcb/kicad-libs/sensact.3d/pxc_1780837_01_FFKDSA1-H-2-54-8_3D.stp
22.8 x 13.6 x 16.2 mm
Bohrlochdurchmesser_11 x 16
FFKDS-H_2.54-GEH.1.1.2 x 8
FFKDS-H_2.54-GEH

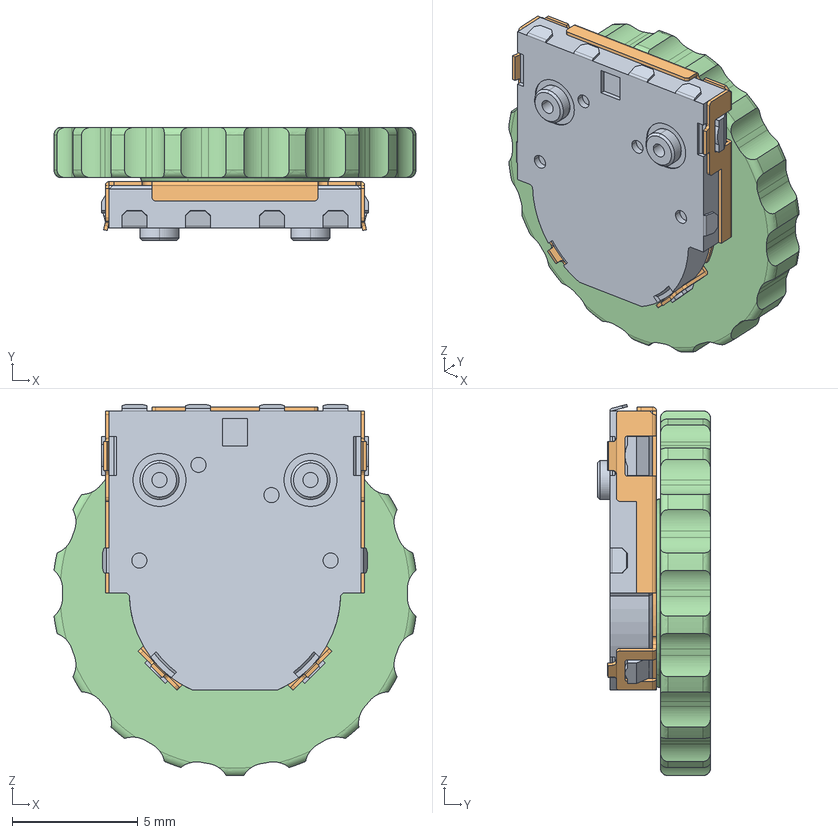
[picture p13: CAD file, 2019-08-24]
pcb/kicad-libs/sensact.3d/SIQ-02FVS3.stp
14.4 x 4.50 x 14.8 mm
SIQ_BASE_ASM
SIQ_COVER
SIQ_ROTOR_ASM
DIAL_KNOB

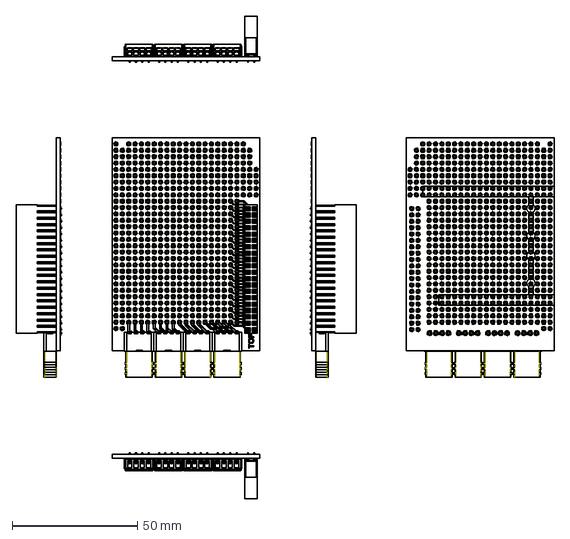
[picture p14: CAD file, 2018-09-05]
pcb/2202994.dxf
214.7 x 192.4 mm

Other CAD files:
pcb/din_schiene_seitenwand/plots/din_schiene_seitenwand-F_Cu.dxf
pcb/din_schiene_seitenwand/plots/din_schiene_seitenwand-B_Cu.dxf
pcb/din_schiene_seitenwand/plots/din_schiene_seitenwand-B_Mask.dxf
pcb/din_schiene_seitenwand/plots/din_schiene_seitenwand-B_Paste.dxf
pcb/din_schiene_seitenwand/plots/din_schiene_seitenwand-B_Silkscreen.dxf
pcb/din_schiene_seitenwand/plots/din_schiene_seitenwand-F_Mask.dxf
pcb/din_schiene_seitenwand/plots/din_schiene_seitenwand-F_Paste.dxf
pcb/din_schiene_seitenwand/plots/din_schiene_seitenwand-F_Silkscreen.dxf
pcb/kicad-libs/sensact.3d/HutschieneV2 v38.f3d

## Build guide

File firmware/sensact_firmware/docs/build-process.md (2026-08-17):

# Build-Prozess

Diese Seite beschreibt, wie ein Build/Flash-Durchlauf für `sensact_firmware`
abläuft.

## Voraussetzungen

- **ESP-IDF**: Version gemäß `dependencies.lock` (`idf 6.0.0`, Target `esp32s3`).
  Umgebungsvariable `IDF_PATH` muss gesetzt sein (`BuildFirmware`/`FlashFirmware`
  prüfen das explizit und brechen mit einer klaren Fehlermeldung ab, wenn nicht);
  der Build ruft intern `%IDF_PATH%\export.bat` auf, bevor er `idf.py` aufruft.
- **.NET SDK** (aktuell `net10.0`) für `builder/`.
- **Node.js/npm** im `web/`-Ordner (für den Vite-Build) sowie in den generierten
  npm-Projekten unter `generated/` (werden vom Builder bei Bedarf selbst per
  `npm install` initialisiert).
- **`builder/appsettings.json`** (gitignored, personal – getrackt ist nur
  `appsettings.json.template`; wird beim ersten Build automatisch aus dem
  Template kopiert, s. `builder.csproj`s `EnsureAppSettings`-Target). Enthält
  ausschließlich maschinenabhängige, nicht versionierbare absolute Pfade:

  | Key | Bedeutung |
  |---|---|
  | `BoardsDir` | Board-Archiv (pro Board ein Unterordner `<mac6hex>_<macDecimal>_<mac12hex>`: Zertifikate, Flash-Encryption-Key, `board_info.json`). |
  | `CertsDir` | Private CA + Server-Root-Zertifikat. |
  | `SubjectPrefix` | Zertifikats-Subject-Präfix (`/C=.../ST=.../L=.../O=...`). |
  | `NpmPackagesDir` | Checkout-Pfad des `npm-packages`-Repos (klaus-liebler/npm-packages) – von generierten npm-Projekten per relativem `file:`-Pfad referenziert. |
  | `WebmanagerBestBinaryBuffersSchemaDir` | Checkout-Pfad von `espidf-component-webmanager/best_binary_buffers_schema` – zweite BestBinaryBuffers-Schema-Quelle neben dem eigenen `best_binary_buffers_schema/`. |

  Alles andere (generierte Dateien, Repo-interne Pfade) ist projektlokal und
  braucht keine Konfiguration, s. unten.

## Hausmodell-Codegenerierung (`GenerateModelFiles`)

Das Hausautomations-Modell (welche Apps auf welchem Node existieren und wie sie
verdrahtet sind, definiert als C#-Klassen mit IntelliSense-Unterstützung) wird
über die Phase `GenerateModelFiles --model Sattlerstrasse16|Testmodel` erzeugt.
Die Generierungs-Engine (`ModelGeneration/Generator.cs`, `SourceCodeGenerator<T>`,
`ModelBuilder<T>`, ...) sowie die beiden Hausmodelle selbst
(`Models/Sattlerstrasse16/`, `Models/Testmodel/`) liegen unter `builder/`.

Schreibt u.a. die `.inc`-Dateien, die `sensact-applicationmodel` direkt
einbindet, nach `generated/sensact_model/` (Teil des projektlokalen
`GeneratedRoot`, s. unten). Kopiert danach zusätzlich die beiden ws-protocol-
Enum-Quellen (`generated/sensact_model/common/applicationIds.enums.cs` /
`commandTypes.enums.cs`) nach `best_binary_buffers_schema/`
(`sensact_applicationIds.enums.cs` / `sensact_commandTypes.enums.cs`) – dort
git-getrackt, damit eine echte Modelländerung als normaler `git diff` sichtbar
wird, statt still in einem gitignorten Verzeichnis zu verschwinden. Deshalb
muss `GenerateModelFiles` vor `GenerateWsProtocolFiles` laufen (`Pipeline`
macht das in der richtigen Reihenfolge).

## Generierte Dateien: projektlokal

Alle von `builder` erzeugten Dateien liegen unter `sensact_firmware/generated/`
(`builder/Paths.cs`: `GeneratedRoot = RootDir + "/generated"`, gitignored).

| Artefakt | Zielpfad | Erzeugt von (Phase) |
|---|---|---|
| ws-protocol C++ | `generated/wsprotocol_cpp/ws_protocol.hh` | `GenerateWsProtocolFiles` |
| ws-protocol TS | `generated/wsprotocol_ts/` (eigenes npm-Paket) | `GenerateWsProtocolFiles` |
| Runtimeconfig C++ | `generated/runtimeconfig_cpp/` | `GenerateRuntimeConfig` |
| Runtimeconfig TS | `generated/runtimeconfig_ts/` (eigenes npm-Paket) | `GenerateRuntimeConfig` |
| CMake-Config | `generated/cmake/config.json` | `GenerateRuntimeConfig` |
| Sensact-Model | `generated/sensact_model/` | `GenerateModelFiles` (s.o.) |
| `sendCommandImplementation` | `generated/sensact_sendCommandImplementation/` (eigenes npm-Paket) | `GenerateSensactFiles` |
| `sensactapps` (digitaler Zwilling für Web-UI) | `generated/sensact_appsbuilder/` (eigenes npm-Paket) | `GenerateSensactFiles` |
| Web-Bundle (komprimiert) | `generated/web/index.compressed.br` | `BuildWebApp`, eingebettet via `main/CMakeLists.txt` (`EMBED_FILES`) |
| Board-Zertifikat/-Key | `<BoardsDir>\<mac-dir>\certificates\` | `GenerateCertificates`, eingebettet via `main/CMakeLists.txt` (`EMBED_TXTFILES`) |

Cross-Repo-Konsumenten (die npm-Pakete in `npm-packages/@klaus-liebler/*` sowie
`web/` selbst) referenzieren die generierten TS-Pakete per relativem
`file:`-Pfad; für `npm-packages/*` ist das ein Sibling-Pfad
(`../../../sensact/firmware/sensact_firmware/generated/...`), für `web/`
(gleiches Repo) ein kurzer (`../generated/...`).

Alle Namespaces mit echter Server-Implementierung nutzen
[BestBinaryBuffers](https://github.com/klaus-liebler/best_binary_buffers) als
Wire-Format (Schema als annotierter C#-Code unter `best_binary_buffers_schema/`).

## Die Repo-Abhängigkeiten für einen Build

Siehe [repo-map.md](repo-map.md) für die vollständige Repo-Landschaft.
Kurzfassung: `EXTRA_COMPONENT_DIRS` (`CMakeLists.txt`) zieht ESP-IDF-Komponenten
aus drei weiteren Repos/Ordnern hinzu; `web/package.json` zieht npm-Pakete aus
`npm-packages/@klaus-liebler/...` (Pfad kommt aus `appsettings.json`s
`NpmPackagesDir`, s.o.) sowie aus dem eigenen `generated/`.

## Die Phasen von `builder`

Aufruf: `dotnet run --project builder -- <Phase> [Argumente]` (aus dem
`builder/`-Verzeichnis auch ohne `--project builder`). Vollständige Liste s.
Kopfkommentar in `builder/Program.cs`.

| Phase | Was passiert |
|---|---|
| `Info` | Zeigt aktuellen Board-/Verbindungsstatus. |
| `GitStatus` | Git-Kurz-Hash etc. für den Build-Banner. |
| `GenerateWsProtocolFiles` | Liest `*.cs`-Schema-Dateien aus `best_binary_buffers_schema/` (eigenes Repo) **und** `WebmanagerBestBinaryBuffersSchemaDir` (s.o.), generiert `ws_protocol.hh`/`ws-protocol.ts` über `BestBinaryBuffers`. |
| `GenerateRuntimeConfig` | Sammelt Build-Defines (Board-Settings, Node-Descriptor, Git-Hash, Zeitstempel, Banner …), schreibt `cmake/config.json`, `runtimeconfig.hh`/`runtimeconfig_defines.hh`, `runtimeconfig_ts`. |
| `GenerateCertificates` | Lazy: Board-Zertifikat (node-forge, signiert mit der Root-CA aus `CertsDir`) + Flash-Encryption-Key, nur falls noch nicht vorhanden. |
| `GenerateModelFiles --model <Name>` | Erzeugt das Hausmodell (`.inc`-Dateien, ws-protocol-Enum-Quellen), s. Abschnitt oben. |
| `GenerateSensactFiles` | Baut `sensact_sendCommandImplementation`/`sensact_appsbuilder` aus Templates (`web/templates/*.template.ts`) + Hausmodell-`.inc`-Snippets. |
| `BuildWebApp` | Vite-Build des `web/`-Projekts + Brotli-Kompression. |
| `BuildFirmware` | `export.bat && idf.py build` (ein einziger verketteter Prozess, s. Kommentar in `BuildFirmware.cs` zur `PATH`-Vererbung). |
| `ReadHardwareIds` | Liest MAC etc. vom per USB verbundenen Board. |
| `FlashFirmware [--resetNVSPartition]` | Flasht (nur unverschlüsselter Pfad implementiert, s. Kommentar in `FlashFirmware.cs`); `--resetNVSPartition` löscht zusätzlich die NVS-Partition (WLAN-/Usersettings vergessen). |
| `Pipeline --model <Name> [--resetNVSPartition]` | Kompletter Zyklus: alle obigen Phasen (außer `Info`/`GitStatus`) einmal nacheinander, endet mit `FlashFirmware`. |

## Neues Board anlegen / in Betrieb nehmen

Siehe [board-provisioning.md](board-provisioning.md) für den vollständigen Ablauf.

## Web-Dev-Server / Proxy

`npm run dev` im `web/`-Ordner startet den Vite-Dev-Server. Ein `wsProxyPlugin` in
`web/vite.config.mts` proxied WebSocket-Verbindungen zum echten Board, weil Browser
(Dev-Server-Origin) und Board unterschiedliche Origins haben und das Session-Cookie
sonst nicht mitgeschickt würde – der Proxy loggt sich selbst einmalig gegen
`/login` ein und cached das resultierende Session-Cookie für nachfolgende
Verbindungen. Dieser Teil hängt eng mit dem Login/Session-Code im Wifimanager
zusammen, siehe [plan_v2/03-wifimanager-review.md](plan_v2/03-wifimanager-review.md).

## Troubleshooting

- **`idf.py build` schlägt mit "config.json not found" fehl**:
  `GenerateRuntimeConfig` wurde noch nicht ausgeführt – muss vor jedem
  CMake-Konfigurationslauf gelaufen sein (`Pipeline` macht das automatisch).
- **`Konnte Repo-Wurzel nicht finden`**: `builder/Paths.cs`s `FindRootDir()`
  erwartet die `CMakeLists.txt` ausschließlich im unmittelbar übergeordneten
  Verzeichnis von `builder/` – kein generisches Aufwärtssuchen darüber hinaus.
  Tritt z.B. auf, wenn `builder/` versehentlich in ein anderes Verzeichnis
  kopiert wurde, ohne die zugehörige `CMakeLists.txt` mitzunehmen.
- **Zertifikatsfehler beim Flashen**: prüfen, ob die Root-CA unter `CertsDir`
  existiert (wird nicht automatisch von `GenerateCertificates` angelegt, nur
  die board-spezifischen Zertifikate sind lazy-generiert).

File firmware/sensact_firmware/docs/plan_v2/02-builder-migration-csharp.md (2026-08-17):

# Stufe 2 – Builder von gulp/TypeScript auf C# umstellen

Referenzprojekt: `C:\repos\factory_in_a_box\firmware_factory_control_unit\builder`
(fertiges C#-Konsolenprogramm für einen strukturell sehr ähnlichen Zweck – ESP-IDF-artiger
Build + Web-Build + Flash, dort für STM32). Die Architektur dieses Referenzprojekts wird
so weit wie sinnvoll übernommen.

## Architektur des Referenzprojekts (Vorlage)

- **Kein Framework, kein DI-Container.** `Program.cs` ist ein Top-Level-Statement-
  Programm: `argv[0]` = Phasenname, danach `--preset`/`--board`-Optionen. Ein simples
  `switch` ruft `Phases.<Phase>.Run(...)` auf. Zusätzlich 3 "Pipeline"-Verbund-Befehle,
  die einfach mehrere Phasen nacheinander in-process aufrufen (keine eigene
  Orchestrierungs-Abstraktion).
- **Phasen** sind `public static class` mit einer `Run(...)`-Methode, ohne gemeinsames
  Interface. Reihenfolge/Abhängigkeiten sind nur in Kommentaren dokumentiert und werden
  dadurch erzwungen, dass jede Phase wirft, wenn eine Voraussetzung (Datei/Verzeichnis)
  fehlt.
- **State fließt über das Dateisystem**, nicht über Rückgabewerte: ein
  "Board-Archiv"-Verzeichnis (`BoardArchive.cs`) pro Board-ID sammelt alle
  generierten Artefakte (Zertifikate, Keys, generierte Header/`.inc`/`.ts`-Dateien).
  `BoardContext.cs` merkt sich nur die zuletzt benutzte Board-ID
  (`build/.last-board-id`).
- Ein optionales SQLite (`BuilderDb.cs`) merkt sich Board-Typ pro Chip-UID, um
  Verwechslungen beim Flashen zu vermeiden. **Geklärt (siehe "Entschieden"): wird
  NICHT übernommen** – die ESP32-Seite hatte historisch genau so ein SQLite-basiertes
  Board-Tracking (`builder.db`, siehe unten) und ist bewusst davon auf das heutige
  dateibasierte Konzept (`board_info.json` pro Board-Verzeichnis) umgestiegen.
- **`ProcessRunner.cs`**: einzige Stelle, die Subprozesse startet, mit drei Varianten
  (`Run` → stdout als String, `RunBinary` → stdout als Bytes, `RunInherit` → Kind erbt
  Konsole für Live-Ausgabe). Wirft `ProcessException` mit stdout/stderr/exitcode bei
  Fehlern.
- **`Paths.cs`**: findet das Projekt-Root robust, indem es von `AppContext.BaseDirectory`
  nach oben läuft, bis es `CMakeLists.txt` + `builder/`-Sibling findet.
- **Konfiguration**: `appsettings.json` (gitignored, maschinenspezifisch) +
  `appsettings.json.template` (getrackt). `BuilderOptions.cs` bindet das per
  `Microsoft.Extensions.Configuration`, als `Lazy<T>`-Singleton. Ein MSBuild-Target
  kopiert das Template automatisch, falls `appsettings.json` fehlt.
- **TypeScript-Dateien im C#-Projekt sind kein Versehen**: `BuildWebApp.cs` ruft
  Node/Vite direkt auf (`node node_modules/vite/bin/vite.js build ...`), und
  `vite-plugin-single-file-firmware-asset.ts` ist ein echtes Vite-Plugin, das vom
  `web/vite.config.ts` importiert wird. Vite hat keine C#-API – dieser Teil bleibt
  zwangsläufig TypeScript/Node, das C#-Programm ruft es nur als Subprozess auf.
- **Keine Tests vorhanden** im Referenzprojekt (kein Testprojekt, keine `.sln`).
  Für unseren Port sollten wir das nicht unreflektiert kopieren, siehe unten.

## Mapping: aktuelle Gulp-Tasks → geplante C#-Phasen

| Gulp-Task (`gulpfile.ts`) | Neue C#-Phase | Bemerkung |
|---|---|---|
| `info` | `Info` | Liest/zeigt Board-Status |
| `addOrUpdateConnectedBoard` | `ReadHardwareIds` (Name in Anlehnung an Referenz) | **Wichtigster Unterschied zur Vorlage**: aktuell liest `esp32.ts` MAC/Efuse-Infos über ein selbstgebautes SLIP/ROM-Loader-Protokoll direkt über die serielle Schnittstelle (kein `esptool` o.ä.). Für C# empfehlenswert: **nicht neu implementieren**, sondern `esptool.py chip_id`/`read_mac`/`--after no_reset` via `ProcessRunner` aufrufen (analog zum Referenzprojekt, das auch alles über CLI-Tools abwickelt) – spart eine komplette Low-Level-Protokoll-Portierung. Muss geprüft werden, ob alle heute genutzten Felder (Chip-Typ, Efuse-Key-Purpose-Register für Flash-Encryption-Status) darüber erreichbar sind. |
| `createFiles` | `GenerateFiles` (mehrteilig, s.u.) | Größter Brocken |
| `buildAndCompressWebProject` | `BuildWebApp` | Direktes Vorbild in der Referenz vorhanden – Muster übernehmen |
| `buildFirmware` | `BuildFirmware` | `idf.py build` statt `cmake --preset`/`cmake --build`, sonst analog |
| `encryptFirmwareIfNecessary` + `flashFirmware` | `FlashFirmware` | `espsecure.py`/`espefuse.py`/`esptool.py` via `ProcessRunner`, analog zu `STM32_Programmer_CLI`-Aufrufen in der Vorlage |
| (implizit: Vollkette) | `pipeline:*`-Verbundbefehle | Wie in der Vorlage: einfache Sequenzen der obigen Phasen |

`GenerateFiles` zerfällt inhaltlich in mehrere Unterschritte, die je einzeln portiert
werden können (jeder Schritt = 1 Datei/Modul in `espidf-vite-secure-build-tools`, siehe
Referenz-Quellcode dort):

1. **Sensact-Codegenerierung** (`sensact_code_generator.ts` → `SensactCodeGenerator.cs`):
   Template-Expansion (aktuell simpler String-Replace `"//TEMPLATE_HERE"`) für
   `applicationIds.fbs`, `commandTypes.fbs`, generierte TS-Pakete
   `sensact_sendCommandImplementation`/`sensact_appsbuilder`. Die TS-Paket-Erzeugung
   bleibt zwangsläufig "Node-artig" (schreibt `package.json` + `npm install`), das
   C#-Programm kann das per `ProcessRunner` (npm) erledigen, muss aber die
   Template-Dateien selbst rendern.
2. **~~Flatbuffers~~ → WsProtocol-Codegenerierung** (`flatbuffers.ts`/`flatc` entfällt
   komplett, siehe eigener Abschnitt unten "Flatbuffers wird durch ws-protocol
   ersetzt"): kein externer Tool-Aufruf mehr, sondern eine in-process C#-Phase
   (`GenerateWsProtocolFiles`), portiert aus dem Referenzprojekt
   (`builder/Phases/ReadWebSocketProtocol.cs`).
3. **Zertifikate** (`certificates.ts`, nutzt `node-forge`): in C# gibt es mit
   `System.Security.Cryptography.X509Certificates` eine vollwertige native
   Alternative – **kein Shell-out zu openssl nötig** (die Referenzvorlage nutzt zwar
   `openssl` per Prozessaufruf, aber .NET kann X.509-Zertifikate + Signierung nativ,
   was robuster/portabler ist als ein weiterer externer Tool-Aufruf). Empfehlung:
   nativ in C# nachbauen statt openssl zu shellen.
4. **Config-Dateien** (`key_value_file_helper.ts` → `RuntimeConfigWriter.cs`): reines
   Text-Rendering (CMake-JSON, C++-Header, TS-Modul) aus einem
   `Dictionary<string, object>` – trivial zu portieren, kein Analogon in der Vorlage
   nötig (aber `ReadModbusRegisterMap.cs`/`ReadGitStatus.cs` in der Vorlage zeigen
   das gleiche Muster: "lies Quelle X, rendere Header/TS/JSON").
5. **Board-Kontext** (`context.ts`, `Context`/`ContextConfig`) →
   `BoardContext.cs`/`BoardArchive.cs`-Äquivalent: board-spezifisches Verzeichnis unter
   `OneDrive - HSOS\esp32_boards\<mac-dir>\` lesen/schreiben (`board_info.json`,
   `sensact.json`, Zertifikate, Flash-Encryption-Key). Sehr nah am
   `BoardArchive.cs`-Konzept der Vorlage, nur mit anderer Verzeichnisbenennung
   (`<mac-dir>` statt `<boardId>`).
6. **Git-Info** (`git.ts` → analog zu `GitInfo.cs`/`ReadGitStatus.cs` – **existiert in
   der Vorlage bereits 1:1 im passenden Zuschnitt**, kann fast unverändert übernommen
   werden).
7. **ASCII-Art-Banner** (`ascii_art.ts`): kleine Fleißarbeit, es gibt .NET-Pakete für
   Figlet-Fonts, oder man rendert den Banner-Text weiterhin einmalig per Node-Skript
   (nicht kritisch, niedrige Priorität).

## Testbarkeit des neuen Tools

Die Vorlage hat **keine Tests**. Empfehlung: diesen Mangel *nicht* übernehmen, sondern
für den C#-Builder von Anfang an die Teile testen, die keine Hardware/Netzwerk
brauchen:
- `RuntimeConfigWriter`/Template-Rendering (reine String-/JSON-Transformationen)
- `Paths`-Auflösung (Root-Suche)
- `BoardContext`/`BoardArchive`-Pfadlogik
- Zertifikatsgenerierung (Struktur/Gültigkeit prüfen, nicht den kryptografischen Inhalt)

Test-Framework: xUnit oder NUnit (Standard-.NET-Wahl, unabhängig von Stufe 5, die C++
betrifft).

## Bestätigt: SQLite war für ESP32-Boards eine Interims-Lösung, JSON-Dateien sind der Zielzustand

Klaus erinnerte sich, dass die ESP32-Board-Verwaltung früher auch mal SQLite-basiert
war, und bat um Verifikation. Bestätigt per Git-Historie in `C:\repos\npm-packages`:
- Commit `d832ff4` ("Initial commit") führte `@klaus-liebler/espidf-vite/database.ts`
  ein (SQLite-basierte Board-Verwaltung).
- Commit `1f9ad35` ("Generate everything in special 'GENERATED'-Directory",
  2025-01-26) **löschte `database.ts` (39 Zeilen) wieder** und baute die
  Board-Verwaltung stattdessen in `context.ts` auf Basis von JSON-Dateien
  (`board_info.json` pro Board-Verzeichnis) um – exakt das Konzept, das heute in
  `context.ts`/`gulpfile.ts` verwendet wird.
- Passender Beleg: unter `%USERPROFILE%\OneDrive - HSOS\esp32_boards\builder.db`
  liegt noch eine verwaiste SQLite-Datei (zuletzt geschrieben 2025-01-21, also
  unmittelbar vor der Umstellung) – ein stehengelassenes Artefakt der alten Lösung,
  seither nicht mehr angefasst. Kann bei Gelegenheit gelöscht werden (kein Code
  referenziert sie mehr), aber unkritisch, da außerhalb jedes Repos.
- **Konsequenz für den neuen ESP32-C#-Builder**: JSON-Dateien sind schon länger der
  bewusste Zielzustand, nicht SQLite (siehe oben, "Architektur des Referenzprojekts").

### Neue Aufgabe: STM32-Builder (`factory_in_a_box`) auf dasselbe Konzept umstellen

Klaus möchte, dass der STM32-Builder (`firmware_factory_control_unit/builder`, das
Referenzprojekt dieser Migration) konsistent zum – schon vor über einem Jahr
getroffenen – ESP32-Entschluss ebenfalls von SQLite (`BuilderDb.cs`, `boards.db`)
auf dateibasierte JSON-Verwaltung umgestellt wird. Das ist eine **separate Aufgabe
in einem dritten Repo** (`C:\repos\factory_in_a_box`, eigenes Remote), nicht Teil
des eigentlichen ESP32-Builder-Ports, aber inhaltlich direkt dadurch motiviert.

- [ ] `BuilderDb.cs` (`mcu_types`/`board_types`/`boards`/`flash_events`-Schema) durch
      ein dateibasiertes Äquivalent ersetzen, analog zum ESP32-Konzept: pro erkannter
      Chip-UID ein JSON-Datensatz (Board-Typ-Zuordnung), plus ein Append-Log für
      Flash-Events (z.B. eine Zeile pro Ereignis in einer JSONL-Datei statt einer
      SQL-Tabelle), abgelegt unter dem bestehenden `BoardsDir`
      (`BoardArchive.cs`/`appsettings.json`).
  - Betroffene Call-Sites: `TryGetBoardTypeNameForChipUid` (`BuilderDb.cs:67-78`,
    genutzt von `ReadHardwareIds`) und `RecordSuccessfulFlash`
    (`BuilderDb.cs:128-173`, genutzt von `FlashFirmware`) müssen auf die neue
    dateibasierte Quelle umgestellt werden.
  - Danach `BuilderDb.cs` und die SQLite-Abhängigkeit (falls als NuGet-Paket
    eingebunden) entfernen, `boards.db` aus `.gitignore`/Doku austragen.
- [ ] Eigener Commit in `factory_in_a_box`, unabhängig vom Zeitplan dieser Stufe hier
      – kann parallel oder danach passieren, ist keine Voraussetzung für den
      ESP32-C#-Port.
- **Nicht Teil der jetzigen Sitzung** (Fokus liegt auf Start von Stufe 1) – als
  eigenständiger, bereits entschiedener Task hier vorgemerkt, zur Umsetzung sobald
  an Stufe 2 bzw. an `factory_in_a_box` gearbeitet wird.

## `configware` (Hausmodell-Generator) wird voll in den Orchestrator verschmolzen

Wichtiger Nachtrag (2026-07-31): Es gibt eine bisher in diesem Plan nicht erfasste,
aber fundamentale Codegenerierungs-Stufe, die **vor** dem bisherigen
`createFiles`-Schritt liegt: `C:\repos\sensact\configware\` – dasselbe Repo wie
`sensact_firmware` (siehe [repo-map.md](../repo-map.md)), aber bisher völlig
unabhängig vom Gulp-Build.

**Ist-Zustand**: `common/` (geteilte Engine) + je ein eigenständiges
Konsolenprojekt pro Hausmodell (`configware_sattlerstrasse`, `configware_testmodel`),
jedes mit eigener Kopie einer `ApplicationId`-Enum. `common/Generator.cs`
(`SourceCodeGenerator<ApplicationIdType>`) nutzt Reflection über
`[SensactCommandMethod]`-attributierte Methoden der Basisklasse `SensactApplication`,
um rund 20 Artefakte zu erzeugen: C++/Flatbuffers-Enums (ApplicationIds,
CommandTypes, EventTypes), virtuelle/override-Deklarationen, TS-Sende-Funktionen,
pro-Node-`.inc`-Dateien (`glo2LocCmd.inc`, `applicationInitializers.inc`,
`nodeDescription.inc`, `nodeMasterApplicationId.inc`, `sensactapps_local.ts`),
JSON-Deskriptoren (`node_descriptor.json`) und die TS-UI-Builder-Datei
(`sensactapps.ts`). Output-Pfad laut `appsettings.json`:
`C:/repos/generated/sensact_model` – **identisch** mit
`SENSACT_COMPONENT_GENERATED_PATH` aus `gulpfile.ts`.

**Befund**: Die meisten `.inc`-Dateien, die `sensact-applicationmodel` (die
eigentlichen C++-Apps) per `#include` einbindet, stammen tatsächlich aus
`configware`, nicht aus der TS-Pipeline. `sensact_code_generator.ts` faltet nur
zwei der hier bereits erzeugten Snippets (`applicationIds.fbs`, `commandTypes.fbs`)
in Templates und liest `node_descriptor.json`. `configware` läuft bisher komplett
manuell (`dotnet run` in Visual Studio, `Program.cs` endet blockierend mit
`Console.ReadKey()`), ist nirgends in Gulp verdrahtet und war bisher auch nicht in
`docs/build-process.md` erfasst – eine reale Fehlerquelle ("Hausmodell geändert,
aber `configware` vergessen neu laufen zu lassen").

### Entschieden: volle Verschmelzung, kein separates Tool

`configware` wird kein eigenständiges Tool bleiben, sondern **vollständig Teil des
neuen C#-Build-Orchestrators** – als weitere, obligatorische Phase
(`GenerateModelFiles`) vor der bisherigen `GenerateFiles`-Phase.

**Geklärte Generics-Frage**: `ModelBuilder<ApplicationIdType>`/
`SourceCodeGenerator<ApplicationIdType>` sind bereits vollständig generisch – zwei
geschlossene generische Typen wie `ModelBuilder<Sattlerstrasse16.ApplicationId>` und
`ModelBuilder<Testmodel.ApplicationId>` können ohne Weiteres im selben
Assembly/Projekt koexistieren. Der einzige Grund für die bisherigen getrennten
Projekte war eine Namensraum-Kollision (beide definierten einen Typ
`Klli.Sensact.Model.ApplicationId`), kein Generics-/Type-System-Problem. Die
Laufzeitebene (`SensactApplication`, `Node`, `ModelContainer`, `Generator`) arbeitet
ohnehin durchgehend mit `ushort`, nicht mit dem Enum-Typ selbst – die
Enum-Typisierung existiert ausschließlich für die Autorenzeit (IntelliSense beim
Verdrahten in `Sattlerstrasse16Builder`/`TestmodelBuilder`).

**Zielstruktur** (innerhalb des neuen Orchestrator-Projekts):

```
Models/
  Sattlerstrasse16/
    ApplicationId.cs        – namespace ...Model.Sattlerstrasse16
    Sattlerstrasse16Builder.cs
  Testmodel/
    ApplicationId.cs        – namespace ...Model.Testmodel
    TestmodelBuilder.cs
ModelGeneration/             – ehemals configware/common: Generator, ModelBuilder<T>,
                                Node, SensactApplication, ...
```

- Auswahl, welches Modell generiert wird, per CLI-Parameter/Konfiguration (analog zu
  `--board`), z.B. `--model Sattlerstrasse16`. Welches Modell zu welchem physischen
  Board gehört, wird als neues Feld (`"model"`) in `board_info.json`/`sensact.json`
  hinterlegt – analog dazu, wie heute schon `NODE_ID` bestimmt, welches
  `main/hal/<NODE_ID>/` aktiv ist.
- `Program.cs` von `configware_*` wird aufgelöst: die eigentliche
  Generierungslogik (aktuell in `Main()` verwoben mit DI-Container-Aufbau und NLog)
  wird zu einer sauberen, aufrufbaren Methode, die die neue Phase
  `GenerateModelFiles` direkt in-process aufruft – kein Subprozess, keine zweite
  `.exe`.
- **Wird beim Merge mit erledigt**: das blockierende `Console.ReadKey()` am Ende von
  `Program.cs` entfernen (notwendige Voraussetzung für jede Automatisierung).
- `GenerateModelFiles` läuft **vor** `GenerateFiles`. Die bisherige "Sensact-
  Codegenerierung" (Unterschritt 1 von `GenerateFiles`, siehe Mapping-Tabelle oben)
  entfällt dadurch in ihrer heutigen Form (Template-Expansion aus vorgefertigten
  `.inc`-Schnipseln), weil die `.inc`-Dateien jetzt direkt und vollständig durch
  `GenerateModelFiles` entstehen, statt nur teilweise per Template zusammengefügt zu
  werden.

- [ ] `configware/common` (Engine) und die Modell-Definitionen
      (`configware_sattlerstrasse`, `configware_testmodel`) in die Zielstruktur
      oben überführen (Namensraum-Umbau `ApplicationId` pro Modell).
- [ ] `Console.ReadKey()`/interaktiven Konsolen-Flow aus der Generierungslogik
      entfernen, saubere aufrufbare Methode extrahieren.
- [ ] Modell-Auswahl-Mechanismus einbauen: **CLI-Flag** (`--model Sattlerstrasse16`),
      s. "Entschieden (Ergänzung)" unten.
- [ ] `GenerateModelFiles`-Phase vor `GenerateFiles` einhängen, Unterschritt 1 von
      `GenerateFiles` (Template-Expansion) entsprechend reduzieren/anpassen.
- [ ] `docs/build-process.md` und `docs/repo-map.md` (Stufe 1) um `configware`
      ergänzen (bisher dort nicht erfasst).
- [ ] `configware/` als eigener Unterordner in den neuen Orchestrator überführen
      (s. "Entschieden (Ergänzung)" unten) – kein Neuschrieb, sondern Verschieben +
      Namensraum-Umbau.

### Entschieden (Ergänzung, 2026-08-01)

- **Modell-Auswahl: CLI-Flag** (`--model Sattlerstrasse16`/`--model Testmodel`),
  keine Ableitung aus `board_info.json`/`board_settings`.
- **`configware` wird als eigener Unterordner** in den neuen Orchestrator überführt
  (kein reiner Neuschrieb) – d.h. `configware/common` → `ModelGeneration/`,
  `configware_sattlerstrasse`/`configware_testmodel` → `Models/Sattlerstrasse16/`
  bzw. `Models/Testmodel/` (s. Zielstruktur oben), Dateien werden verschoben und im
  Namensraum angepasst, nicht von Grund auf neu geschrieben.

## Flatbuffers wird durch das neue ws-protocol-Verfahren ersetzt

Nachtrag (2026-07-31): Klaus hatte eine parallele Änderung im Referenzprojekt
(`factory_in_a_box`) entdeckt: dort wurde Flatbuffers durch ein eigenes, viel
schlankeres binäres Nachrichtenprotokoll (`best_binary_buffers_schema/*.json` →
`builder/Phases/ReadWebSocketProtocol.cs` → generiertes `ws_protocol.hh`/
`ws-protocol.ts`) ersetzt. Auf Wunsch wurde zunächst geprüft, ob dieses Verfahren
sensacts tatsächliche Flatbuffers-Nutzung (12 Namespaces, sowohl in
`espidf-component-webmanager` als auch in `sensact_firmware` selbst) abdecken kann
– und dann der Generator direkt im Referenzprojekt entsprechend erweitert (siehe
unten). Das Ergebnis: **ja**, und der Ersatz wird jetzt Teil dieser Migration statt
weiterhin `flatc` als externe Abhängigkeit mitzuschleppen.

### Ursprüngliche Lücken und wie sie geschlossen wurden

Eine erste Prüfung von `ReadWebSocketProtocol.cs` gegen alle 12 sensact-Namespaces
(`ns01wifimanager` … `ns10journal`, `ns20sensact`, `ns21nodemaster`) ergab vier
Lücken gegenüber Flatbuffers. Alle vier wurden im Zuge dieser Planung im
Referenzprojekt-Generator nachgerüstet und mit Compile-/Typecheck-/Roundtrip-Tests
(ARM-g++, `tsc --strict`, Node-Ausführung) verifiziert:

| Lücke (Flatbuffers-Konstrukt) | Betroffene sensact-Schemas | Lösung im Generator |
|---|---|---|
| Verschachtelte Strings in Array-Elementen (`[AccessPoint]`, `[Finger]`, `[PartitionInfo]`, `[JournalItem]`, `[Range]`) | wifimanager, fingerprint, systeminfo, journal, nodemaster | Neuer Typ **Class** (`"classes"` in der Schema-Datei) – wie eine Message, darf Strings enthalten, wird per `{"type":"array","classes":["ns.Name"]}` referenziert |
| Feste Byte-/Wort-Arrays als `struct` (`Mac6`, `CanData`, `Payload`, `StatusPayload`, `Uint8x32`, `OneWeekIn15MinutesData`) | systeminfo, canmonitor, sensact, fingerprint, scheduler | Neuer Typ **Struct** (`"structs"`), referenziert per `{"type":"struct","structRef":"Name"}`; einzelne Bytes/Wörter per `"count":N` statt N einzelner Felder |
| Union als Feldtyp, nicht nur als Array-Element (`scheduler.Schedule.schedule:uSchedule`) | scheduler | Neuer Feldtyp `{"type":"class","classes":[...]}` – ein einzelnes polymorphes Feld (wie ein Array-Element, aber ohne Liste/Zähler), muss letztes Feld seines Objekts sein |
| Geteilte Enums über mehrere Nachrichten hinweg (`ApplicationId`/`CommandType`, von `configware` erzeugt) | sensact (`RequestCommand.id`, `RequestStatus.ids`, `NotifyStatus.id`, `ResponseStatusItem.id`) | Neue `"enums"`-Deklaration + `{"type":"enumRef","enumRef":"ns.Name"}`, plus: Namespaces sind jetzt **nicht mehr an Dateien gebunden**, sondern ergeben sich aus dem Punkt im `"name"` jeder Deklaration (`"sensact.ApplicationId"`) – dadurch kann `configware` sein Enum unabhängig von allen anderen Schema-Dateien beisteuern |

Details/Wire-Format aller vier Erweiterungen: `docs/websocket-protocol.md` (im
Referenzprojekt) Abschnitt 8. Diese Doku ist die eigentliche Spezifikation, hier nur
die sensact-spezifische Einordnung.

**Zwei weitere Lücken, erst beim tatsächlichen Portieren der restlichen 9
`espidf-component-webmanager`-Namespaces gefunden (nicht bei der ursprünglichen
Prüfung anhand der `.fbs`-Dateien allein sichtbar) – ebenfalls im
Referenzprojekt-Generator nachgerüstet und verifiziert:**

| Lücke | Gefunden bei | Lösung im Generator |
|---|---|---|
| Kein Fließkommatyp (`float`/`double`) | `ns04heaterexperiment` (8 float-Felder) | Neuer Feldtyp `float32` – bitweise Übertragung per `memcpy` (C++) bzw. `DataView.getFloat32`/`setFloat32` (TS), NICHT per Integer-Bitshift (das würde den Wert konvertieren statt das Bitmuster zu übertragen) |
| Kein 64-Bit-Ganzzahltyp | `ns02systeminfo` (`seconds_epoch`/`seconds_uptime:int64`), `ns10journal` (`last_message_timestamp:uint64`) | Neue Feldtypen `uint64`/`int64` – C++ wie gehabt (mit `uint64_t`-Akkumulator statt `uint32_t`, um Trunkierung/UB zu vermeiden), TypeScript bildet auf `number` ab (kein `DataView`-Zugriff für 64-Bit-`number` vorhanden) und zerlegt/komponiert manuell aus zwei 32-Bit-Hälften – **exakt nur für nicht-negative Werte bis 2^53**, für sensacts Zeitstempel-Anwendungsfälle ausreichend |
| Nur EIN abschließendes `classes`-Array/-Einzelfeld pro Message/Class erlaubt | `ns07fingerprint.ResponseFingers` (braucht ZWEI: `scheduleNames` und `fingers`, je ein eigenes `classes`-Array) | Validierung gelockert: statt "muss das letzte Feld sein" jetzt "muss Teil eines zusammenhängenden Blocks solcher Felder am Ende sein" – mehrere `classes`-Arrays/-Einzelfelder hintereinander sind erlaubt, da Encode/Decode ohnehin sequenziell durch alle Felder laufen und jedes Element selbstbeschreibend ist (kein technischer Grund für die Beschränkung auf genau eines) |

Details: `docs/websocket-protocol.md` Abschnitt 5 (float32/int64/uint64) und
Abschnitt 8.2/8.2b (trailing-Block-Regel).

### Wire-Format-Unterschied zu Flatbuffers: Dispatch statt Union-Wrapper

Sensacts Flatbuffers-Schemas nutzen durchgängig ein `RequestWrapper{request:Requests}`/
`ResponseWrapper{response:Responses}`-Muster (ein Flatbuffers-`union` aus allen
Request-/Response-Typen eines Namespace). Im neuen Protokoll entfällt dieser Wrapper
ersatzlos – der 4-Byte-Kopf jeder Nachricht (`namespaceId`+`messageTypeId`) übernimmt
die Dispatch-Funktion direkt: der Websocket-Handler auf Firmware-Seite
(`handle_webmanager_ws` in `espidf-component-webmanager/cpp/webmanager.hh`, s.
[03-wifimanager-review.md](03-wifimanager-review.md)) und der Client-Dispatcher
(`AppController` in `web-components`) müssen von "Flatbuffers-Root parsen, dann
`response_type()` switchen" auf "erste 4 Bytes lesen, dann auf
`(namespaceId, messageTypeId)` switchen" umgestellt werden – siehe
`web/src/ws-client.ts`-Beispiel in `docs/websocket-protocol.md` Abschnitt 7 im
Referenzprojekt als Vorlage für das Dispatch-Muster.

### Mapping: sensact-Namespace → benötigte ws-protocol-Konstrukte

| Namespace (`.fbs`-Datei, Repo) | Neue Konstrukte |
|---|---|
| `ns01wifimanager` (`espidf-component-webmanager`) | Class `AccessPoint` (Liste in `ResponseNetworkInformation`) – **erledigt** |
| `ns02systeminfo` (`espidf-component-webmanager`) | Struct `Mac6` (5×), Class `PartitionInfo` (Liste), erster Test von `int64`/`uint64` (`secondsEpoch`/`secondsUptime`) und `float32` (`chipTemperature`) – **erledigt**, fand die int64/uint64-Lücke |
| `ns03functionblock` (`espidf-component-webmanager`) | Bare-Skalar-Array-Workaround (`BoolValue`/`IntValue`/`FloatValue`/`ColorValue`, je ein `value`-Feld) für `bools`/`integers`/`floats`/`colors` in `ResponseDebugData` – **erledigt** |
| `ns04heaterexperiment` (`espidf-component-webmanager`) | Erster Test von `float32` (8 Felder in Request/ResponseHeater), geteiltes Enum `Mode` – **erledigt**, fand die float32-Lücke |
| `ns05chatbot` (`espidf-component-webmanager`) | nur Strings – keine neuen Konstrukte nötig – **erledigt** |
| `ns06canmonitor` (`espidf-component-webmanager`) | Struct `CanData` (8 Bytes, `count`) – **erledigt** |
| `ns07fingerprint` (`espidf-component-webmanager`) | Struct `Uint8x32` (32 Bytes, `count`), Class `Finger` (Liste), Class `StringValue` (Einzelfeld-Wrapper) für `schedule_names:[string]`; `ResponseFingers` braucht ZWEI aufeinanderfolgende `classes`-Arrays (`scheduleNames`+`fingers`) – **erledigt**, fand die "mehrere trailing classes-Felder"-Lücke (s. oben) |
| `ns08scheduler` (`espidf-component-webmanager`) | Struct `OneWeekIn15MinutesData` (84 Bytes, `count`); `Schedule` selbst wird zur **Class** mit `name:string` + einem **trailing einzelnen polymorphen Feld** (`type:"class"`, Predefined/OneWeekIn15Minutes/SunRandom); `ResponseSchedulerOpen`/`RequestSchedulerSave` betten `Schedule` dann ihrerseits als **einzelnes einelementiges polymorphes Feld** (`{"classes":["scheduler.Schedule"]}`) ein – s. ausgearbeitetes Beispiel im "Vorgehen" – **erledigt** |
| `ns09usersettings` (`espidf-component-webmanager`) | `SettingWrapper{setting_key,setting:Setting}` wird zu 4 eigenständigen Classes (`StringSettingWrapper`, `IntegerSettingWrapper`, `BooleanSettingWrapper`, `EnumSettingWrapper`, je mit `setting_key`+Wert) – heterogene Liste dieser 4 Classes ersetzt die verschachtelte Union sauberer als das Original – **erledigt** |
| `ns10journal` (`espidf-component-webmanager`) | Class `JournalItem` (Liste), erstmals `uint64` INNERHALB einer Class (`lastMessageTimestamp`, nicht nur direkt in einer Message) – **erledigt** |
| `ns20sensact` (`sensact_firmware`) | Struct `Payload`/`StatusPayload` (`count`), **geteiltes Enum** `sensact.ApplicationId`/`sensact.Command` (`enumRef`, aus `configware` gespeist statt aus Flatbuffers-`.fbs`-Text; Enum heißt `Command`, nicht `CommandType`, s. Status unten), Bare-Enum-Array-Workaround für `ids:[ApplicationId]` – **erledigt** |
| `ns21nodemaster` (`sensact_firmware`) | Class `Range` (Liste, wegen `name:string`) – **erledigt** |

### Betroffene Repos – dies ist eine Migration über DREI Repos hinweg

- **`sensact`** (dieses Repo, umfasst sowohl `firmware/sensact_firmware/` als auch
  `configware/` – s. [repo-map.md](../repo-map.md)):
  - `ns20sensact`/`ns21nodemaster` → neue `best_binary_buffers_schema/*.json`-Dateien; `main/`
    (Nutzung der generierten Typen in C++).
  - `configware` muss statt `.fbs`-Text für `ApplicationId`/`CommandType`
    (`GenerateApplicationIds`/`GenerateCommandTypes` in `Generator.cs`) eine
    ws-protocol-`"enums"`-Deklaration erzeugen – fällt zeitlich mit der
    `configware`-Verschmelzung (s. oben) zusammen, sollte im selben Zug erledigt
    werden.
- **`espidf-component-webmanager`** (eigenes Repo): `ns01`–`ns10` → neue
  `best_binary_buffers_schema/*.json`-Dateien; `webmanager.hh` (Dispatch-Umstellung, s.o.).
- **`npm-packages`** (eigenes Repo): `web-components`s `AppController`/
  `WifimanagerController` u.a. Screen-Controller müssen von der generierten
  `flatbuffers`-JS-API auf die neue generierte `ws-protocol.ts`-API umgestellt
  werden (Dispatch, Encode/Decode-Aufrufe) – das ist der aufwändigste Einzelteil,
  weil hier die meiste UI-Logik hängt (siehe die Screen-Controller, die in der
  Kapazitätsprüfung für Stufe 3 bereits identifiziert wurden).

### Vorgehen

- [ ] Reihenfolge: **einen** Namespace zuerst komplett durchziehen, End-to-End
      inkl. Client-Umstellung, bevor die übrigen 11 im großen Batch folgen.
      **Entschieden (auf Wunsch bewusst mit dem komplexesten Fall zuerst, um
      restliche Lücken so früh wie möglich zu finden): `ns08scheduler`.**
      Begründung: einziger Namespace, der gleich drei Dinge gleichzeitig
      braucht – den größten Struct (`OneWeekIn15MinutesData`, 84 Bytes),
      das neueste/am wenigsten battle-getestete Feature (einzelnes polymorphes
      Feld) UND eine Class, die selbst wieder ein einzelnes polymorphes Feld als
      letztes Feld trägt (`Schedule`), referenziert von zwei anderen Nachrichten
      als einelementige Klassenliste – die bislang am wenigsten in Kombination
      geprüfte Konstruktion. `ns07fingerprint` (meiste Nachrichten-Paare, auch
      eine Class mit `[string]`-Workaround) wäre die zweitkomplexeste Wahl,
      falls `ns08scheduler` unerwartet reibungslos durchläuft und ein zweiter
      harter Testfall gewünscht ist.

      **Status (2026-07-31): Schema geschrieben und verifiziert.** Liegt bereits
      real (nicht nur als Plan-Skizze) unter
      `C:\repos\espidf-component-webmanager\ws-protocol\scheduler.json`. Verifiziert
      mit demselben Verfahren wie die Generator-Erweiterungen selbst: mit dem
      Referenzgenerator (`--ws-protocol-path` auf diese Datei) generiert, das
      Ergebnis mit `arm-none-eabi-g++` kompiliert und mit `tsc --strict` +
      echtem Node-Laufzeit-Roundtrip getestet – alle Fälle (verschachtelte
      Polymorphie `ResponseSchedulerOpen.payload`→`Schedule`→`schedule`, das
      84-Byte-Struct zwei Ebenen tief eingebettet, das leere `Predefined`,
      die homogene Klassenliste `ResponseSchedulerList.items`) bestehen.
      **Dabei einen echten Generator-Bug gefunden und behoben**: `GenerateCppClass`
      erzeugte für eine Class mit einem eigenen abschließenden `ClassField`
      (wie `Schedule.schedule`) nie die noetigen `Append*/Decode*Elements`-
      Hilfsfunktionen – nur `GenerateCppMessage` tat das. Genau der Fall, den die
      "komplexesten Namespace zuerst"-Strategie finden sollte; behoben in
      `ReadWebSocketProtocol.cs` (TS-Seite war bereits korrekt, da dort alles
      inline statt über benannte Hilfsfunktionen läuft).

      **Noch offen für `ns08scheduler`** (das Schema selbst ist fertig, aber die
      Migration ist erst mit diesen Schritten abgeschlossen): `webmanager.hh`s
      Dispatch auf `namespaceId`/`messageTypeId` umstellen, `AppController`/
      Scheduler-UI in `web-components` auf die neue `ws-protocol.ts`-API
      umstellen, alte `ns08scheduler.fbs` erst danach löschen (s. Checkliste
      unten) – das alles braucht die tatsächliche `GenerateWsProtocolFiles`-Phase
      im neuen C#-Orchestrator, die noch nicht existiert (Stufe 2 ist insgesamt
      noch nicht umgesetzt).

      Das Schema selbst, zur Referenz:
      ```json
      {
        "structs": [
          { "name": "scheduler.OneWeekIn15MinutesData", "fields": [
            { "name": "v", "type": "uint8", "count": 84 }
          ]}
        ],
        "classes": [
          { "name": "scheduler.Predefined", "fields": [] },
          { "name": "scheduler.OneWeekIn15Minutes", "fields": [
            { "name": "data", "type": "struct", "structRef": "scheduler.OneWeekIn15MinutesData" }
          ]},
          { "name": "scheduler.SunRandom", "fields": [
            { "name": "offsetMinutes", "type": "uint16" },
            { "name": "randomMinutes", "type": "uint16" }
          ]},
          { "name": "scheduler.Schedule", "fields": [
            { "name": "name", "type": "string" },
            { "name": "schedule", "type": "class", "classes": [
              "scheduler.Predefined", "scheduler.OneWeekIn15Minutes", "scheduler.SunRandom"
            ]}
          ]},
          { "name": "scheduler.SchedulerListItem", "fields": [
            { "name": "name", "type": "string" },
            { "name": "type", "type": "EnumU8", "enumName": "ScheduleType", "enumValues": [
              { "name": "PREDEFINED", "value": 0 }, { "name": "ONE_WEEK_IN_15_MINUTES", "value": 1 }, { "name": "SUN_RANDOM", "value": 2 }
            ]}
          ]}
        ],
        "messages": [
          { "name": "scheduler.RequestSchedulerList", "kind": "request", "fields": [] },
          { "name": "scheduler.ResponseSchedulerList", "kind": "response", "fields": [
            { "name": "items", "type": "array", "classes": ["scheduler.SchedulerListItem"] }
          ]},
          { "name": "scheduler.RequestSchedulerOpen", "kind": "request", "fields": [
            { "name": "name", "type": "string" },
            { "name": "type", "type": "EnumU8", "enumName": "ScheduleType", "enumValues": [
              { "name": "PREDEFINED", "value": 0 }, { "name": "ONE_WEEK_IN_15_MINUTES", "value": 1 }, { "name": "SUN_RANDOM", "value": 2 }
            ]}
          ]},
          { "name": "scheduler.ResponseSchedulerOpen", "kind": "response", "fields": [
            { "name": "payload", "type": "class", "classes": ["scheduler.Schedule"] }
          ]},
          { "name": "scheduler.RequestSchedulerSave", "kind": "request", "fields": [
            { "name": "payload", "type": "class", "classes": ["scheduler.Schedule"] }
          ]},
          { "name": "scheduler.ResponseSchedulerSave", "kind": "response", "fields": [
            { "name": "name", "type": "string" }
          ]},
          { "name": "scheduler.RequestSchedulerRename", "kind": "request", "fields": [
            { "name": "oldName", "type": "string" }, { "name": "newName", "type": "string" }
          ]},
          { "name": "scheduler.RequestSchedulerDelete", "kind": "request", "fields": [
            { "name": "name", "type": "string" }
          ]}
        ]
      }
      ```
      `payload` ist in `ResponseSchedulerOpen`/`RequestSchedulerSave` jeweils das
      EINZIGE Feld, erfüllt also trivial die "muss letztes Feld sein"-Regel für
      einzelne polymorphe Felder.
  - [x] `scheduler.json` schreiben und gegen den Referenzgenerator verifizieren
        (s. Status oben) – **erledigt**.
  - [x] `wifimanager`/`systeminfo`/`functionblock`/`heaterexperiment`/`chatbot`/
        `canmonitor`/`fingerprint`/`usersettings`/`journal` (die übrigen 9
        Namespaces) als `best_binary_buffers_schema/*.json` neu geschrieben (in
        `espidf-component-webmanager/best_binary_buffers_schema/`) – **erledigt (2026-08-01)**.
        Alle 10 Namespaces (inkl. `scheduler`) zusammen gegen den
        Referenzgenerator verifiziert (`--ws-protocol-path` auf das gesamte
        Verzeichnis): `arm-none-eabi-g++ -fsyntax-only` auf das generierte
        `ws_protocol.hh`, `tsc --strict --noEmit` auf das generierte
        `ws-protocol.ts`, sowie zwei Node-Laufzeit-Testsuiten mit echtem
        Encode/Decode-Roundtrip je Namespace (u.a. `secondsUptime` nahe 2^40,
        float32 in `heaterexperiment`, die zwei aufeinanderfolgenden
        `classes`-Arrays in `fingerprint.ResponseFingers`, die 4-gliedrige
        heterogene Liste in `usersettings.ResponseGetUserSettings`, `uint64`
        innerhalb einer Class in `journal.JournalItem`) – alle bestanden. Dabei
        die zwei oben dokumentierten Generator-Lücken (float32/int64, mehrere
        trailing `classes`-Felder) gefunden und behoben. `usersettings` nutzt
        das oben bestätigte 4-Classes-Design; `fingerprint.ResponseFingers`
        nutzt zwei separate `classes`-Arrays statt einer verschachtelten
        Struktur (s. Lücken-Tabelle oben); `fingerprint.NotifyEnrollNewFinger`/
        `NotifyFingerDetected` sind trotz "Notify"-Namen `kind:"response"`
        (nicht `"event"`), weil sie im Original Teil der `Responses`-Union
        waren (anders als `canmonitor.NotifyCanMessage`, das außerhalb beider
        Unions stand und deshalb `kind:"event"` ist).

        Nach jedem Testlauf wurde `best_binary_buffers_schema/ids.txt` (im Referenzprojekt)
        auf seine 2-Zeilen-Baseline zurückgesetzt und der (aus einem
        physischen Board gecachte) `build/.last-board-id` vor jedem Testlauf
        beiseite verschoben und danach wiederhergestellt – sonst hätte
        `ReadWebSocketProtocolAndGenerateFiles` ohne `--board`-Angabe die
        Test-Schemas ins reale Board-Archiv (`BoardsDir`, außerhalb des Repos)
        statt nach `Core/generated`/`web/generated` geschrieben. Das ist beim
        ersten Testlauf dieser Session tatsächlich passiert und wurde
        korrigiert (Board-Archiv mit dem echten `system.json`-Output
        neu generiert) – **Vorsicht bei künftigen Testläufen mit
        `--ws-protocol-path` in diesem Referenzprojekt**, falls ein Board
        gerade angeschlossen war/ist.
  - [x] `ns20sensact`/`ns21nodemaster` als `best_binary_buffers_schema/*.json` neu geschrieben
        (in `sensact_firmware/best_binary_buffers_schema/`) – **erledigt (2026-08-01)**.
  - [x] `configware`s `GenerateApplicationIds`/`GenerateCommandTypes` geben jetzt
        ZUSÄTZLICH (nicht ersetzend – s. unten) eine ws-protocol-`"enums"`-JSON
        aus – **erledigt (2026-08-01), aber bewusst nur ein Zwischenschritt**:
        `GenerateApplicationIds` schreibt neben `applicationIds`/`applicationIds.fbs`
        jetzt auch `applicationIds.enums.json` (`sensact.ApplicationId`, u16),
        `GenerateCommandTypes` analog `commandTypes.enums.json`
        (**`sensact.Command`**, u8 – bewusst NICHT `sensact.CommandType`: das
        Original-Flatbuffers-Template (`commandTypes.template.fbs`) nennt die
        Wire-Enum schon immer `Command`, der C#-interne Typname `CommandType`
        wurde nie auf die Wire-Ebene durchgereicht). Der bisherige `.fbs`-Output
        bleibt unverändert bestehen, damit der aktuell laufende
        Flatbuffers-Build nicht bricht – die eigentliche Umstellung (`.fbs`-Pfad
        entfernen) ist weiterhin für die `configware`-Verschmelzung vorgesehen,
        s. "Migrationsstrategie" unten.

        **Verifiziert** mit demselben Verfahren wie alle anderen Namespaces:
        `configware_sattlerstrasse` tatsächlich laufen lassen (liefert die
        ECHTEN ~360 `ApplicationId`-Werte des realen Sattlerstrasse16-Hausmodells,
        nicht nur Testdaten), die beiden erzeugten `.enums.json`-Dateien nach
        `sensact_firmware/best_binary_buffers_schema/` kopiert (`sensact_applicationIds.enums.json`/
        `sensact_commandTypes.enums.json`), `sensact.json`/`nodemaster.json`
        dagegen geschrieben (referenzieren die Enums per `enumRef`), dann mit dem
        Referenzgenerator generiert, `arm-none-eabi-g++ -fsyntax-only` +
        `tsc --strict` + echtem Node-Roundtrip getestet (u.a. `NO_APPLICATION`
        als u16-Maximalwert 65535, das ~360-Werte-Enum selbst, der
        `ids:[ApplicationId]`-Bare-Enum-Array-Workaround, `nodemaster.Range` als
        Class wegen des `name:string`-Felds) – alle bestanden, keine weiteren
        Generator-Lücken gefunden.

        Nebenbefund beim Ausführen von `configware_sattlerstrasse`, **behoben
        (2026-08-01)**: `configware_testmodel.csproj` zielte auf `net9.0`,
        `sensactmodelcommon` (das gemeinsame Projekt) auf `net10.0` –
        inkompatibel, `dotnet build` schlug fehl (`NU1201`). Auf `net10.0`
        gezogen (jetzt identisch mit `configware_sattlerstrasse.csproj`); dabei
        einen ZWEITEN, dadurch erst sichtbar gewordenen Fehler gefunden:
        `Testmodel.cs` referenzierte `RotaryEncoder.ROTARYENCODER_1`, das
        Enum (`common/Nodes/Node.cs`) kennt aber nur `ROTENC0`/`ROTENC1` –
        vermutlich Bit-Rot aus der Zeit, bevor die TFM-Inkompatibilität
        `configware_testmodel` faktisch unbuildbar machte. Auf `ROTENC0`
        korrigiert (passend zum einzigen Rotary-Encoder des Testmodells,
        analog zu den meisten `RotaryEncoder.ROTENC0`-Verwendungen in
        `Sattlerstrasse16.cs`). `configware_testmodel` läuft jetzt
        durch und erzeugt korrekt sein (kleineres, 27-Werte-)
        `applicationIds.enums.json` – **beide Hausmodelle sind damit
        buildbar**. Nach der Verifikation `configware_sattlerstrasse` erneut
        laufen lassen, um `C:/repos/generated/sensact_model` (gemeinsamer,
        nicht-repo-gebundener Ausgabeordner) wieder auf den echten
        Sattlerstrasse16-Stand zurückzusetzen (Testmodel-Lauf hätte ihn sonst
        mit den kleineren Testmodell-Werten überschrieben stehen lassen).
  - [ ] `webmanager.hh`s Dispatch (`handle_webmanager_ws`) auf
        `namespaceId`+`messageTypeId`-Switch umstellen (in
        `espidf-component-webmanager`).
  - [ ] `AppController`/Screen-Controller in `web-components` auf generierte
        `ws-protocol.ts`-API umstellen (in `npm-packages`).
- [ ] Alte `.fbs`-Dateien erst löschen, wenn der jeweilige Namespace vollständig
      umgestellt UND getestet ist (Parallelbetrieb pro Namespace möglich, da
      `namespaceId` ohnehin schon die fachliche Trennung ist).
- [ ] `flatbuffers`-Abhängigkeiten (npm-Paket, `flatc`-Toolchain-Vorbedingung in
      `docs/build-process.md`) erst entfernen, wenn ALLE 12 Namespaces umgestellt
      sind.

### Entschieden (Ergänzung)

- Reihenfolge: `ns08scheduler` zuerst (bewusst der komplexeste Fall, s. "Vorgehen"
  oben, um verbleibende Lücken so früh wie möglich zu finden), danach die übrigen
  11 Namespaces im Batch. Das oben ausgearbeitete Schema-Design ist noch
  ungetestet – erster Schritt bei Aufnahme der Arbeit ist, es tatsächlich zu
  generieren/kompilieren/durchzutesten (analog zum Vorgehen, mit dem die
  Generator-Erweiterungen selbst verifiziert wurden).
- `ns09usersettings`-Umbau auf 4 Classes: bestätigt, s. "Entschieden" oben.

## Migrationsstrategie

- [x] Neues C#-Projekt `builder/` neben dem bestehenden `builder/` angelegt
      (`sensact_firmware/builder/`) – **erledigt (2026-08-01)**. Grundgerüst
      analog zum Referenzprojekt: `builder.csproj` (net10.0, `Exe`,
      `Microsoft.Extensions.Configuration`-basiert), `Paths.cs`
      (Root-Suche über `CMakeLists.txt` + `builder/`-Sibling, analog zur
      Vorlage), `BuilderOptions.cs` (`appsettings.json`/`.template`-Muster
      1:1 übernommen, `BoardsDir`/`CertsDir` aus `gulpfile.ts` befüllt: `OneDrive
      - HSOS\esp32_boards`/`...\certificates`), `IBoardInfo.cs` (C#-Äquivalent
      von `IBoardInfo` aus `espidf-vite-secure-build-tools/utils.ts`, inkl.
      `BoardPaths.BoardSpecificPath`/`Mac6Char`/`Mac12Char` als Portierung von
      `paths.ts`s `mac_6char`/`mac_12char`/`Paths.boardSpecificPath` –
      Verzeichniskonvention `<mac6hex>_<macDezimal>_<mac12hex>` gegen die
      echte, real existierende Board-Archiv-Struktur verifiziert). `.gitignore`
      um `builder/appsettings.json`/`bin/`/`obj/` ergänzt (Muster von
      `factory_in_a_box/.gitignore` übernommen).
- [ ] Reihenfolge der Portierung (kleinstes Risiko zuerst):
  1. `Info`-Phase (nur Lesen, kein Risiko) – **erledigt (2026-08-01), mit
     bewusster Einschränkung**: beim genaueren Lesen von `context.ts` stellte
     sich heraus, dass `Context.printInfo()` ZUERST per `esp32.ts` (eigenes
     SLIP/ROM-Loader-Protokoll über die serielle Schnittstelle) die MAC eines
     TATSÄCHLICH ANGESCHLOSSENEN Boards abfragt und mit dem Cache vergleicht –
     also entgegen der Einstufung oben NICHT frei von der Hardware-Frage, die
     bewusst auf Schritt 11 (`ReadHardwareIds`) verschoben wird. Entschieden:
     `Info` liest fürs Erste NUR den zwischengespeicherten Stand
     (`<Repo-Root>/board_info.json`, dort abgelegt vom letzten echten
     Board-Connect) plus das zugehörige Board-Archiv unter `BoardsDir` – KEINE
     Live-Board-Abfrage, mit `TODO(ReadHardwareIds)`-Kommentar im Code markiert.
     Verifiziert gegen die echten Daten dieses Repos (`board_info.json` mit
     `mac:79336146357860` → korrekt aufgelöst zu Board-Archiv-Verzeichnis
     `d24e64_79336146357860_4827e2d24e64`, alle Felder – Name/Version/Rollen/
     Settings/Zeitstempel/Encryption-Status – stimmen mit der echten
     board-spezifischen `board_info.json` überein). "Is current board"-Zeile
     entsprechend durch einen erklärenden Platzhalter ersetzt, bis
     `ReadHardwareIds` existiert.
  2. Git-Info + ASCII-Banner (trivial, kein externer State) – **Git-Info
     erledigt (2026-08-01), ASCII-Banner bewusst zurückgestellt** (s. unten).
     `GitInfo.cs`/`GitInfoReader` fast 1:1 aus dem Referenzprojekt übernommen
     (reiner `git`-CLI-Aufruf, keine STM32-Spezifika). **Bewusst OHNE die
     4-Datei-Ausgabe der Vorlage** (`gitconstants.hh`/`firmware_constants.hh`/
     `build-info.ts`/`gitstatus.json`, board-archiv-gebunden) – sensact_firmware
     nutzt Git-Infos aktuell nur als EINEN Eintrag (`GIT_SHORT_HASH`) im
     gemeinsamen `defines`-Dictionary des Config-/Runtimeconfig-Writers
     (`gulpfile.ts`: `createObjectWithDefines()` → `cfg.create*`, s. Mapping-
     Tabelle Unterschritt 4) – die eigentliche Dateigenerierung entsteht daher
     erst dort, nicht als eigene Phase. Bis dahin per eigenständiger
     `GitStatus`-Phase (`dotnet run --project builder -- GitStatus`)
     verifizierbar – gegen rohe `git`-Befehle geprüft (Commit-Hash/Branch/Tag/
     Autor/Message/Dirty-Status stimmen exakt überein, `IsDirty` erkennt den
     echten, zum Testzeitpunkt tatsächlich unsauberen Arbeitsbaum korrekt).
     ASCII-Banner zurückgestellt: laut Plan ohnehin "nicht kritisch, niedrige
     Priorität" (s. Unterschritt 7 oben) – wird nachgeholt, wenn der
     Config-/Runtimeconfig-Writer (Schritt 4) tatsächlich angegangen wird, da
     der Banner-Text (`ascii_art.createAsciiArt`) ohnehin dort als Teil der
     `defines` gebraucht wird, nicht isoliert.
  3. `GenerateWsProtocolFiles` (portiert aus `ReadWebSocketProtocol.cs`, s. eigener
     Abschnitt "Flatbuffers wird durch ws-protocol ersetzt") – ersetzt den
     bisherigen `flatc`-Aufruf; kann isoliert entwickelt/getestet werden (reine
     Text-zu-Text-Generierung, kein Board-Kontext nötig), sollte aber inhaltlich erst
     NACH mindestens einem vollständig migrierten Namespace (s. dortiges "Vorgehen")
     production-scharf geschaltet werden – **portiert (2026-08-01)**.

     Die komplette Parsing-/Codegenerierungs-Logik (alles bis auf `Run()`) ist
     UNVERÄNDERT aus `ReadWebSocketProtocol.cs` übernommen (bereits vollständig
     generisch, keine STM32-Spezifika). Angepasst nur `Run()` selbst: kein
     Board-Archiv-Konzept (das ws-protocol gilt für die gesamte sensact-Flotte,
     nicht board-spezifisch), Ausgabe direkt nach
     `Paths.GeneratedWsProtocolCppDir`/`GeneratedWsProtocolTsDir`
     (`c:\repos\generated\wsprotocol_cpp`/`_ts` – sensacts eigene
     "gemeinsames externes generated-Verzeichnis"-Konvention aus `paths.ts`,
     nicht die repo-interne `Core/generated`-Konvention der Vorlage; bewusst
     NEUE Ordnernamen, solange Flatbuffers noch parallel produktiv läuft). Die
     Phase wird mit BEIDEN ws-protocol-Quellen aufgerufen
     (`Paths.WsProtocolDir` UND `Paths.WebmanagerWsProtocolDir`, Letzteres
     unverändert aus `gulpfile.ts`s `IDF_COMPONENT_WEBMANAGER_ROOT`
     übernommen), da erst beide zusammen den vollständigen sensact-
     Nachrichtensatz ergeben.

     **Echt end-to-end verifiziert** (nicht nur kompiliert): `dotnet run
     --project builder -- GenerateWsProtocolFiles` liest tatsächlich 14
     Dateien aus beiden Repos (die 4 unter `sensact_firmware/best_binary_buffers_schema/` +
     die 10 unter `espidf-component-webmanager/best_binary_buffers_schema/`) und erzeugt ein
     gemeinsames `ws_protocol.hh`/`ws-protocol.ts` mit allen 12 echten
     Namespaces (`canmonitor`, `chatbot`, `fingerprint`, `functionblock`,
     `heaterexperiment`, `journal`, `nodemaster`, `scheduler`, `sensact`,
     `systeminfo`, `usersettings`, `wifimanager` – **kein** `system`, das
     gehört nur zu `factory_in_a_box`). `arm-none-eabi-g++ -fsyntax-only` und
     `tsc --strict --noEmit` beide fehlerfrei auf dem echten Output. Zweiter
     Lauf bestätigt Idempotenz (keine neuen Zeilen in `ids.txt`). Dabei
     entstand `sensact_firmware/best_binary_buffers_schema/ids.txt` als ECHTE, eigene
     ID-Tabelle dieses Projekts (unabhängig von der Tabelle im
     Referenzprojekt) – **muss mitversioniert werden** (nicht gitignored, s.
     docs/websocket-protocol.md Abschnitt 8.5), analog zu
     `sensact.json`/`nodemaster.json` selbst.
  4. Config-/Runtimeconfig-Writer – **portiert (2026-08-01)**.

     `RuntimeConfigWriter.cs` (Portierung von `key_value_file_helper.ts`, rein
     generisches Text-Rendering eines flachen `defines`-Dictionary in 3
     Formate: `config.json` fürs CMake-Konfigurationssystem, C++-Header
     `runtimeconfig_defines.hh`/`runtimeconfig.hh` mit `#define`s bzw.
     `namespace cfg{ constexpr auto ...}`, TS-Modul `index.ts`) +
     `Phases/GenerateRuntimeConfig.cs` (Portierung von
     `gulpfile.ts:createObjectWithDefines()`), baut das Dictionary aus:
     `node_descriptor.json` des aktuellen Nodes (von `configware` erzeugt),
     `board_settings.web`/`.firmware` aus der board-spezifischen
     `board_info.json` (aktuell für alle bekannten Boards leer, Logik trotzdem
     1:1 inkl. der eigentümlichen Doppel-`JSON.stringify`-Behandlung aus dem
     TS-Original übernommen, NICHT stillschweigend "korrigiert"), sowie
     `NODE_ID`/`HOSTNAME`/`BOARD_*`/`APP_*`/`CREATION_DT*`/`GIT_SHORT_HASH`
     (Letzteres über `GitInfoReader`, s. Schritt 2). **Bewusst OHNE `BANNER`
     als echtes ASCII-Art-Rendering** – `ascii_art.ts` nutzt das npm-Paket
     `figlet`, keine triviale .NET-Entsprechung vorhanden, laut Plan ohnehin
     niedrige Priorität (s. Schritt 2 oben) – `BANNER` bekommt stattdessen
     vorläufig nur den reinen Text (`"<APP_NAME> <NODE_ID>"`) ohne ASCII-Art.

     **Wichtige Abhängigkeit, die diesen Schritt eigentlich hinter Schritt 7
     einordnen würde**: `node_descriptor.json` kommt von `configware`
     (`GenerateModelFiles`, Schritt 7, noch nicht portiert) – diese Phase setzt
     also voraus, dass `configware_sattlerstrasse`/`_testmodel` (das
     BESTEHENDE, noch nicht gemergte Konsolenprogramm) vorher schon einmal
     gelaufen ist und aktuelle Ausgaben unter `Paths.SensactModelGeneratedDir`
     hinterlassen hat (klare Fehlermeldung, falls nicht). Trotzdem wie geplant
     an dieser Stelle portiert (nicht auf Schritt 7 verschoben), weil die
     eigentliche Rendering-Logik unabhängig vom Ursprung der Eingabedaten ist
     und schon jetzt korrekt end-to-end getestet werden kann, solange
     `configware` weiterhin manuell vorher läuft.

     **Echt end-to-end verifiziert**: gegen die realen Daten des tatsächlich
     verbundenen Boards (`SNSCT_L3_WORK_HS`/Sattlerstraße 16, `node_id` aus der
     board-spezifischen `sensact.json`) 17 Defines erzeugt, alle drei
     Ausgabeformate inhaltlich mit dem erwarteten Ergebnis abgeglichen
     (inkl. Sonderzeichen `ß` in `SENSACT_MODEL_NAME` – dabei eine echte
     Diskrepanz zum TS-Original gefunden und behoben: `System.Text.Json`
     escaped Nicht-ASCII-Zeichen standardmäßig (`ß`), `JSON.stringify`
     tut das nicht – `JavaScriptEncoder.UnsafeRelaxedJsonEscaping` behebt das).
     Beide generierten C++-Header mit `arm-none-eabi-g++ -fsyntax-only`
     fehlerfrei kompiliert, `index.ts` mit `tsc --strict --noEmit` fehlerfrei
     typgeprüft.
  5. Zertifikate – **portiert (2026-08-01)**.

     `Certificates.cs`, bewusst NICHT 1:1 aus `certificates.ts` übersetzt
     (das nutzt `node-forge`), sondern nativ mit
     `System.Security.Cryptography.X509Certificates`/`CertificateRequest`
     neu gebaut, wie in "Entschieden" vorgesehen (kein `openssl`-Shell-out
     nötig, anders als im Referenzprojekt). Erzeugt dieselben drei
     Zertifikatsarten wie das Original: selbstsignierte Root-CA
     (`CreateRootCA`, nur für einmaliges, manuelles CA-Setup – NICHT Teil der
     eigentlichen Phase), signierte Board-/Server-Zertifikate mit IP+mehreren
     DNS-SANs (`CreateAndSignCert`) und Client-Zertifikate (`CreateAndSignClientCert`,
     feste IP `192.168.4.1`, ein DNS-SAN = Username) – RSA-2048/SHA-256, 3000
     Tage Gültigkeit, alle Werte/Erweiterungen 1:1 aus `certificates.ts`
     übernommen (inkl. der eigentümlichen Custom-OID-Extension mit fest
     codiertem Wert `"false"`, bewusst nicht "korrigiert"). Dazu
     `Phases/GenerateCertificates.cs` (Portierung des "Certificates
     (lazy)"-Abschnitts aus `gulpfile.ts:createFiles()`): erzeugt nur ein
     neues Board-Zertifikat, wenn im Board-Archiv noch keins liegt, signiert
     mit der echten, produktiv genutzten Root-CA (nur lesend).

     **Korrektur nach Rückmeldung**: Country/State/Locality/Organization für
     das Zertifikats-Subject standen zunächst als hartcodierte Konstanten in
     `Certificates.cs` – im Referenzprojekt steckt genau das dagegen in
     `appsettings.json` (`BuilderOptions.SubjectPrefix`, OpenSSL-`-subj`-Notation
     `/C=.../ST=.../L=.../O=...`, genutzt für `openssl req -subj` in
     `Phases/ReadHardwareIds.cs`). Behoben: `BuilderOptions.cs` bekam
     dasselbe `SubjectPrefix`-Feld (gleiches Format, damit `appsettings.json`
     zwischen beiden Projekten strukturell vergleichbar bleibt), `Certificates.cs`
     parst den Slash-String zur Laufzeit in ein `X500DistinguishedName`
     (RFC-2253-Notation, umgekehrte RDN-Reihenfolge) statt `openssl` direkt
     aufzurufen. Erneut end-to-end verifiziert (Test-Zertifikat gegen die
     echte Root-CA erzeugt, `openssl x509 -noout -subject` zeigt das korrekt
     zusammengesetzte Subject, `openssl verify` weiterhin `OK`).

     **Echten Fehler beim Portieren gefunden und behoben**: `certificates.ts`s
     `authorityKeyIdentifier`-Extension setzt bei genauerem Hinsehen NUR
     `authorityCertIssuer`+`serialNumber`, KEIN `keyIdentifier` – passend dazu
     hat die echte, produktiv genutzte Root-CA selbst keine
     Subject-Key-Identifier-Extension (nur `basicConstraints`+`keyUsage`, s.
     `createRootCaExtensions()`). Der naheliegende .NET-Aufruf
     `X509AuthorityKeyIdentifierExtension.CreateFromCertificate(caCert,
     includeKeyIdentifier: true, ...)` scheitert deshalb an der echten Root-CA
     mit `CryptographicException: certificate does not have a Subject Key
     Identifier extension` – behoben durch `includeKeyIdentifier: false`
     (was ohnehin dem Original entspricht, kein Kompromiss).

     **Echt end-to-end verifiziert, nicht nur kompiliert**: `GenerateCertificates`
     gegen das echte, verbundene Board ausgeführt – bestätigt korrektes
     Lazy-Verhalten (Zertifikat existiert bereits, kein Schreibzugriff,
     s. "Ausführung mit Vorsicht" unten). Für die eigentliche Kryptografie-
     Verifikation zusätzlich alle drei Zertifikatsarten testweise erzeugt
     (Leaf-Zertifikat + Client-Zertifikat signiert mit der ECHTEN,
     produktiven Root-CA – nur lesend, Ausgabe in ein Scratch-Verzeichnis,
     NICHT ins Board-Archiv; sowie eine neue selbstsignierte Test-Root-CA) und
     unabhängig mit `openssl` geprüft: `openssl x509 -text` zeigt korrekte
     Struktur (Version 3, positive Seriennummer, richtige Gültigkeitsdauer,
     Subject/Issuer, alle Erweiterungen inkl. SAN mit IP+3 DNS-Namen),
     `openssl verify -CAfile rootCA.pem.crt` bestätigt `OK` für Leaf- UND
     Client-Zertifikat (echte Kettenvalidierung gegen die reale Produktions-CA),
     Public-Key-Modulus von Zertifikat und privatem Schlüssel stimmen überein
     (MD5-Vergleich), die selbstsignierte Test-Root-CA verifiziert sich selbst.
     Alle drei Testfälle liefen über einen temporären Debug-Pfad in
     `Program.cs`, der nach erfolgreicher Verifikation wieder entfernt wurde.

     **Vorsicht bei künftigen Testläufen von `GenerateCertificates`**: die
     Phase schreibt (außerhalb des Lazy-Falls) ins ECHTE Board-Archiv
     (`BoardsDir`) – für reine Verifikation der Zertifikats-Logik selbst
     lieber `Certificates.CreateAndSignCert(...)` direkt mit einem
     Scratch-Ausgabepfad aufrufen (analog zum jetzt wieder entfernten
     Debug-Pfad), nicht die Phase selbst gegen ein Board mit bereits
     vorhandenem Zertifikat "erzwingen".
  6. Board-Kontext (Lesen/Schreiben `board_info.json` etc.) – **portiert
     (2026-08-01)**.

     `BoardContext.cs` (Portierung von `Context.get()` aus `context.ts`,
     NUR der `updateWithCurrentlyConnectedBoard: false`-Zweig – der `true`-Zweig
     braucht dieselbe Live-ESP32-Abfrage, die auch bei `Info` bewusst
     zurückgestellt wurde, s. Schritt 1 oben und Schritt 11): liest den
     zwischengespeicherten Stand (`Paths.BoardInfoJsonPath`), löst daraus das
     Board-Archiv-Verzeichnis auf, legt bei fehlender board-spezifischer
     `board_info.json` einen neuen Eintrag mit Default-Werten an
     (`DEFAULT_BOARD_NAME`/`DEFAULT_BOARD_VERSION` aus `gulpfile.ts`
     übernommen), und synchronisiert den Repo-Root-Cache zurück (Äquivalent zu
     `fs.cpSync(...)` am Ende von `Context.get()`).

     **Ersetzt duplizierte Logik**: `Phases/Info.cs`, `Phases/GenerateRuntimeConfig.cs`
     und `Phases/GenerateCertificates.cs` hatten bislang je eigene, inline
     geschriebene "lies `board_info.json`, löse Board-Verzeichnis auf"-Logik
     (aus der Zeit, bevor es eine gemeinsame Stelle dafür gab). **Bewusste
     Ausnahme**: `Info.cs` wurde NICHT auf `BoardContext.LoadCached()`
     umgestellt, weil das (wie `Context.get()`) bei fehlendem Eintrag einen
     NEUEN anlegt – für die rein informative `Info`-Phase (Äquivalent zu
     `Context.printInfo()`, die nie etwas anlegt) wäre das ein unerwarteter
     Seiteneffekt. `GenerateRuntimeConfig`/`GenerateCertificates` (die
     inhaltlich `Context.get()` entsprechen, nicht `Context.printInfo()`)
     wurden dagegen umgestellt – dabei gewinnen sie nebenbei auch das bisher
     fehlende "lege mit Default-Werten an, falls unbekannt"-Verhalten korrekt
     dazu, statt nur zu werfen.

     **Verifiziert**: beide umgestellten Phasen nach dem Refactoring erneut
     gegen das echte Board ausgeführt – identisches, weiterhin korrektes
     Ergebnis (17 Defines, Zertifikat-Lazy-Skip), `board_info.json` im
     Repo-Root nach dem Copy-Back-Schritt inhaltlich unverändert (war bereits
     konsistent mit dem board-spezifischen Stand).
  7. `GenerateModelFiles` (`configware`-Merge, siehe eigener Abschnitt oben) – muss
     vor Schritt 8 stehen, da dessen Output (`.inc`-Dateien) dort gebraucht wird;
     `configware`s Enum-Ausgabe wird dabei gleich auf `"enums"` (ws-protocol) statt
     `.fbs`-Text umgestellt – **portiert (2026-08-01)**.

     Wie in "Entschieden (Ergänzung)" oben festgelegt: `configware/common` →
     `builder/ModelGeneration/` verschoben (Generator, `ModelBuilder<T>`,
     `SourceCodeGenerator<T>`, `Node`, `SensactApplication`, `Applications/`,
     `Nodes/`, ... – **unverändert**, keine Namensraum-Anpassung nötig, da
     `common/` nachweislich (per Grep verifiziert) nie direkt von der
     modellspezifischen `ApplicationId` abhing, sondern ausschließlich über den
     generischen Typparameter). `configware_sattlerstrasse`/`configware_testmodel`
     → `builder/Models/Sattlerstrasse16/`
     bzw. `.../Models/Testmodel/` (Dateinamen `ApplicationId.cs`/
     `Sattlerstrasse16Builder.cs`/`TestmodelBuilder.cs`, s. Zielstruktur oben),
     `ApplicationId`-Namespace disambiguiert zu `Klli.Sensact.Model.Sattlerstrasse16`
     bzw. `.Testmodel` (die "Geklärte Generics-Frage" von oben bestätigt: beide
     geschlossenen generischen Typen `SourceCodeGenerator<Sattlerstrasse16.ApplicationId>`/
     `SourceCodeGenerator<Testmodel.ApplicationId>` koexistieren problemlos im
     selben Assembly). Neue Phase `Phases/GenerateModelFiles.cs` dispatcht per
     `--model Sattlerstrasse16|Testmodel`-CLI-Flag (s. "Entschieden") manuell auf
     die passende geschlossene generische Instanziierung (kein Reflection nötig,
     nur 2 Modelle). `configware_*`s DI-Container/NLog/blockierendes
     `Console.ReadKey()` ersatzlos entfernt – einfache aufrufbare Methode mit
     Standard-Konsolen-Logging (`Microsoft.Extensions.Logging.Console`).

     **Drei Compiler-Fehler beim Verschieben gefunden und behoben** (alles
     Altlasten der ursprünglichen Zwei-Projekte-Struktur, die durch das
     Zusammenführen erstmals sichtbar wurden):
     1. `System.ApplicationId` (ein echter BCL-Typ, durch `ImplicitUsings`
        global eingebunden) kollidierte mit `Klli.Sensact.Model.<Modell>.ApplicationId`
        – behoben per `using ApplicationId = Klli.Sensact.Model.<Modell>.ApplicationId;`
        (Alias statt normalem `using`) in beiden `*Builder.cs`-Dateien.
     2. Beide `*Builder.cs`-Dateien nutzten daneben an vielen Stellen
        `Model.ApplicationId.X` (kein `using`-Alias, sondern C#s relative
        Namespace-Auflösung: `Model` löste, weil der Code in `Klli.Sensact.Config`
        liegt, auf `Klli.Sensact.Model` auf) – das brach, seit `ApplicationId`
        eine Ebene tiefer liegt (`Klli.Sensact.Model.<Modell>`). Behoben durch
        einheitliches Ersetzen von `Model.ApplicationId` → `ApplicationId` (matcht
        jetzt den Alias aus Punkt 1) in beiden Dateien.
     3. `ILogger<T>` fehlte (`ModelGeneration/Generator.cs` nutzt es, `builder.csproj`
        hatte aber keine `Microsoft.Extensions.Logging`-Pakete) – ergänzt.

     **Kritischer Fund beim End-to-End-Vergleich, betrifft reale
     Hausautomatisierungs-Firmware**: `builder.csproj` hatte
     `<InvariantGlobalization>true</InvariantGlobalization>` (unreflektiert aus
     dem STM32-Referenzprojekt übernommen). `ModelGeneration/Generator.cs`
     verlässt sich an zwei Stellen auf `DateTime.Now.ToString()` OHNE
     Formatstring (kulturabhängig) für `SENSACT_MODEL_CREATION_DT_STRING` und
     die eingebettete `NodeDescription`-C++-Konstante – mit
     `InvariantGlobalization=true` wechselt das Format von
     `dd.MM.yyyy HH:mm:ss` (deutsches System, bisheriges Verhalten) auf
     `MM/dd/yyyy HH:mm:ss` (invariante Kultur). Erst durch einen echten
     Byte-für-Byte-Vergleich (s. Verifikation unten) entdeckt – wäre sonst
     unbemerkt in generierte Firmware-Strings eingeflossen. Behoben durch
     Entfernen von `InvariantGlobalization` (das ursprüngliche
     `configware_sattlerstrasse.csproj` hatte es nie gesetzt).

     **Danach auf Wunsch durchgängig auf ISO-Format umgestellt**
     (`yyyy-MM-dd HH:mm:ss` bzw. `yyyy-MM-dd`, statt der bisherigen
     kultur-/gebietsschema-abhängigen Formatierung) – betrifft
     `ModelGeneration/Generator.cs` (`SENSACT_MODEL_CREATION_DT_STRING`,
     `NodeDescription`), `Phases/GenerateRuntimeConfig.cs` (`CREATION_DT_STR`,
     vorher probeweise `dd.MM.yyyy` als de-DE-Nachbildung), `Phases/Info.cs`
     (`IBoardInfo.FromUnixMillis`, First/Last connected) und
     `Phases/GitStatus.cs` (Commit Date). Damit weicht dieses Datumsformat
     bewusst vom bisherigen TS-Verhalten (de-DE-lokalisiert) ab – das ist eine
     bewusste Entscheidung, kein Versehen.

     **Echt end-to-end verifiziert, mit dem höchsten Risiko aller bisherigen
     Schritte** (generiert echten Code für die real betriebene Hausautomatisierung):
     das bestehende `configware_sattlerstrasse`-Programm frisch laufen lassen und
     seinen kompletten Output (88 Dateien unter `C:/repos/generated/sensact_model`)
     als Referenz-Snapshot gesichert, danach `builder -- GenerateModelFiles
     --model Sattlerstrasse16` laufen lassen und rekursiv verglichen
     (`diff -rq`): **alle 88 Dateien identisch bis auf die beiden erwartbar
     zeitstempelbehafteten Dateien pro Node** (`node_descriptor.json`,
     `nodeDescription.inc` – enthalten den Erzeugungszeitpunkt, unterscheiden
     sich zwangsläufig zwischen zwei zeitlich getrennten Läufen). Nach dem
     ISO-Format-Umbau erneut verifiziert: identische Struktur, nur das
     (gewünschte) neue Datumsformat weicht ab. Zusätzlich `--model Testmodel`
     probeweise durchlaufen lassen (bestätigt, dass beide geschlossenen
     generischen Typen im selben Lauf/Assembly sauber funktionieren) und
     danach den gemeinsamen, externen `C:/repos/generated/sensact_model`-Ordner
     wieder auf den echten Sattlerstrasse16-Stand zurückgesetzt.

     **Erledigt (2026-08-17)**: das alte `configware/`-Verzeichnis (drei
     `.csproj`) wurde gelöscht. Anlass: die beiden parallel gepflegten Kopien
     der Generierungs-Engine (`configware/common/Generator.cs` vs.
     `builder/ModelGeneration/Generator.cs`) waren real auseinandergelaufen
     (JSON->`.cs`-Enum-Format-Umstellung hatte nur eine Kopie erreicht) – bei
     der Fehlersuche dafür bestätigt, dass `builder -- GenerateModelFiles`
     inzwischen production-tauglich ist (end-to-end gegen das echte
     Sattlerstrasse16-Modell verifiziert), also war die "Fallback/
     Vergleichsreferenz"-Begründung von oben nicht mehr nötig. Bei Bedarf über
     die Git-Historie wiederherstellbar.
  8. Sensact-Codegenerierung (jetzt nur noch der verbleibende Template-Teil, s.o.)
     – **portiert (2026-08-01)**.

     Beim genaueren Lesen von `sensact_code_generator.ts` (`Sensact.PrepareSensactFiles()`)
     stellte sich heraus, dass die frühere Einschätzung oben ("entfällt dadurch in
     ihrer heutigen Form") zu pauschal war: **zwei** der vier dortigen
     Template-Expansionen (`applicationIds.fbs`/`commandTypes.fbs`) sind
     tatsächlich obsolet – die erzeugt jetzt `configware`/`GenerateModelFiles`
     direkt als vollständige ws-protocol-`"enums"`-JSON (s. oben). Die
     **anderen zwei** (`sendCommandImplementation.ts`, `sensactapps.ts`)
     bleiben dagegen unverändert nötig: sie kombinieren einen TS-Template-Rahmen
     (`web/templates/*.template.ts`, feste Imports/Funktionssignatur) mit einem
     von `configware` erzeugten `.inc`-Schnipsel (`sendCommandImplementation.ts.inc`
     bzw. `sensactapps_local.ts.inc`) und legen dafür je ein eigenständiges,
     generiertes npm-Paket an (`@generated/sensact_sendCommandImplementation`/
     `@generated/sensact_appsbuilder`) – das ist reines Text-Rendering + `npm
     install`, unabhängig vom Flatbuffers/ws-protocol-Wechsel.

     Neue Dateien: `NpmProject.cs` (Portierung von `npm.ts`s
     `CreateAndInstallNpmProjectLazily` – schreibt `package.json` und ruft `npm
     install` nur auf, wenn sich der Inhalt geändert hat oder `node_modules/`
     fehlt) und `Phases/GenerateSensactFiles.cs` (Portierung der verbleibenden
     zwei Template-Expansionen aus `PrepareSensactFiles()`). `BoardContext.GetNodeId()`
     ergänzt (dritte Stelle, die das brauchte – zusätzlich `GenerateRuntimeConfig`/
     `GenerateCertificates` darauf umgestellt, ersetzt jeweils eigene
     `sensact.json`-Lese-Logik). **Bewusst unverändert gelassen**: die beiden
     `*.template.ts`-Dateien importieren weiterhin aus
     `@generated/flatbuffers_ts/sensact` – das auf `ws-protocol` umzustellen ist
     Teil der separaten, größeren `webmanager.hh`/`AppController`-Migration (s.
     "Vorgehen" oben), nicht dieses Schritts.

     **Echt end-to-end verifiziert**: bestehenden Output beider generierter
     npm-Projekte gesichert, `GenerateSensactFiles` gegen das echte, verbundene
     Board laufen lassen. `sendCommandImplementation.ts` und beide
     `package.json` **byte-identisch** zum vorherigen Stand (kein unnötiger
     `npm install`-Aufruf ausgelöst, da Inhalt unverändert). `sensactapps.ts`
     wich in einer Zeile ab (Beschreibungstext von `POWIT_L1_LVNG_C1`,
     "Wandlampen" → "Esszimmerlampe") – das ist KEINE Regression, sondern
     korrektes Verhalten: der alte Snapshot war schlicht älter als der
     aktuelle Stand von `Sattlerstrasse16Builder.cs` (per Grep bestätigt: die
     Quelle sagt bereits "Esszimmerlampe"), die neue Phase spiegelt also
     korrekt den aktuellen Quellstand wider.
  9. `BuildWebApp` (Vite-Aufruf) – **portiert (2026-08-01)**.

     Vite hat keine C#-API (wie schon in der Referenz festgestellt) – Aufruf
     deshalb über die Vite-CLI (`node web/node_modules/vite/bin/vite.js build
     web --outDir ... --sourcemap true --emptyOutDir`) statt der JS-API
     (`vite.build({...})`), die `vite_helper.ts` nutzt. Die dortigen
     Inline-Overrides `cssCodeSplit:false`/`esbuild.legalComments:'none'` sind
     nicht als CLI-Flags verfügbar, mussten aber auch nicht nachgebildet
     werden: `web/vite.config.mts` setzt beide bereits selbst identisch
     (redundante Doppelsetzung im TS-Original) – das Endergebnis der
     Konfigurations-Zusammenführung ist unabhängig vom CLI- vs.
     JS-API-Weg dasselbe. `ProcessRunner.cs` dafür unverändert aus dem
     Referenzprojekt übernommen (vollständig generisch, wird auch für
     `BuildFirmware`/`FlashFirmware` gebraucht).

     Brotli-Kompression (`index.html` → `index.compressed.br`) in C#
     nachgebildet (`System.IO.Compression.BrotliStream`,
     `CompressionLevel.SmallestSize` für Qualitätsstufe 11, analog zu Node's
     `zlib.brotliCompressSync()`-Standardeinstellung) statt Node dafür ein
     zweites Mal aufzurufen.

     **Echt end-to-end verifiziert**: `dotnet run --project builder --
     BuildWebApp` gegen das echte Web-Projekt laufen lassen – Vite-Build lief
     durch (152 Module transformiert, `viteSingleFile`-Plugin inlined JS/CSS
     wie gewohnt), komprimierte Größe (29.710 Byte) praktisch identisch zum
     vorherigen, Node-erzeugten Stand (29.702 Byte – die winzige Differenz
     kommt vom leicht unterschiedlichen JS-Bundle-Hash zwischen zwei
     Build-Läufen, nicht von der Brotli-Implementierung). Zusätzlich mit Node
     unabhängig gegengeprüft: `zlib.brotliDecompressSync()` auf die
     .NET-erzeugte `index.compressed.br` liefert byte-identisch dieselbe
     `index.html` zurück.

     **Nachtrag (2026-08-01): Lit-Template-Minifizierer + Inline-Brotli-Kompression
     aus der Referenz übernommen, auf Wunsch.** `vite-plugin-single-file-firmware-asset.ts`
     und `singlefile-minify.ts` (+`html-minifier-terser.d.ts`) unverändert aus dem
     Referenzprojekt nach `web/` kopiert, NUR die Ausgabe angepasst: statt eines
     fest verdrahteten `../build/assets/index.html.br` (STM32-Konvention) schreibt
     das Plugin jetzt nach `options.dir` (Vites tatsächlich aufgelöster
     `outDir`, unabhängig von Config-Datei/CLI-Flag) mit konfigurierbarem
     Dateinamen – aufgerufen als `singleFileFirmwareAssetPlugin("index.compressed.br")`
     in `web/vite.config.mts`, um den von `main/CMakeLists.txt` erwarteten
     Dateinamen (`EMBED_FILES "${GENERATED_DIR}/web/index.compressed.br"`)
     beizubehalten. Ersetzt `@klaus-liebler/vite-single-file` (aus
     `web/package.json` entfernt), neue Dev-Dependencies `terser`+`html-minifier-terser`
     (`^5.x`/`^7.2.0`, wie in der Referenz). `BuildWebApp.cs` dadurch
     vereinfacht: die zuvor selbst nachgebaute `BrotliStream`-Kompression
     entfällt ersatzlos, da das Plugin jetzt selbst brotli-komprimiert
     (genau wie in der Referenz, ein einziger Rutsch statt zweier Prozesse).

     **Nebenbefund beim `npm install`**: ein echter npm/Arborist-Bug (nicht
     durch diese Änderung verursacht) ließ `npm install` mit
     `TypeError: Cannot read properties of null (reading 'package')`
     abstürzen, sobald die per `file:`-Symlink eingebundenen
     `@klaus-liebler/*`/`@generated/*`-Pakete beim Scannen des bestehenden
     `node_modules`-Baums mit eingelesen wurden. Workaround: diese
     Symlink-Verzeichnisse kurz aus `node_modules` verschoben, `npm install`
     lief dann durch, npm hat sie beim Install automatisch wiederhergestellt
     (identische Ziele, keine Daten verloren).

     **Echt end-to-end verifiziert**: `BuildWebApp` erneut gegen das echte
     Web-Projekt laufen lassen. Komprimierte Größe **29.447 Byte** (vorher,
     ohne Minifizierer: 29.710 Byte) – kleiner trotz GRÖSSEREM unkomprimiertem
     HTML (147.413 vs. 144.754 Byte, vermutlich durch abweichende
     JS-Minifizierung/Terser-Ausgabe ggü. esbuilds Standardminifizierung) –
     Brotli gleicht das mehr als aus, weil es Whitespace ohnehin schon sehr
     effizient komprimiert; der eigentliche Gewinn ist bescheiden, aber
     real. Ausgabe unabhängig geprüft: mit Node dekomprimiert, Struktur
     validiert (genau 1 `<script>`, 1 `<style>`, `<!doctype>` vorhanden,
     `<head>`/`<body>` korrekt), den extrahierten `<script>`-Inhalt mit
     `node --check` auf syntaktische Gültigkeit geprüft – bestanden.
  10. `BuildFirmware` (`idf.py build`) – **portiert, aber NICHT verifiziert
      (2026-08-01)**.

      Portierung von `gulpfile.ts:buildFirmware()` (`espidf.ts:buildFirmware()`/
      `exec_in_idf_terminal()`): `export.bat` (setzt PATH/PYTHONPATH für die
      ESP-IDF-Python-Umgebung) und `idf.py build` müssen als EIN per `&&`
      verketteter Befehl im selben Prozess laufen (die von `export.bat`
      gesetzten Umgebungsvariablen gelten nur innerhalb dieses einen
      Prozesses) – deshalb über `cmd.exe /c "\"<IDF_PATH>\export.bat\" &&
      idf.py build"` per `ProcessRunner.RunInherit`, nicht als zwei getrennte
      Aufrufe.

      **Nicht end-to-end testbar in dieser Session**: beim Ausprobieren des
      `export.bat`/`idf.py`-Verkettungsmusters (zunächst nur mit `idf.py
      --version` als risikoarmer Testlauf) schlug bereits die
      Python-venv-Aktivierung selbst fehl – `activate_venv.py` suchte
      `C:\Users\mail\scoop\apps\python313\current\python.exe`, das nicht
      (mehr) existiert (Exit-Code 103). Das ist ein vorbestehendes
      Umgebungsproblem auf diesem Rechner (vermutlich eine veraltete
      ESP-IDF-Tool-Konfiguration nach einem scoop-Python-Update/-Umzug),
      unabhängig vom hier portierten Code – **auf Wunsch trotzdem portiert,
      Verifikation nachgeholt, sobald die Python-venv repariert ist**. Bis
      dahin bleibt offen, ob die `cmd.exe`-Verkettung/Quotierung in der Praxis
      tatsächlich funktioniert.
  11. `ReadHardwareIds` (MAC-Auslesen über `esptool`) – bewusst spät, weil hier die
      größte Verhaltensänderung ggü. dem aktuellen `esp32.ts`-SLIP-Ansatz steckt
      – **portiert und ECHT gegen ein angeschlossenes Board verifiziert (2026-08-01)**.

      Wie im Mapping-Kapitel empfohlen: KEIN Neubau des eigenen SLIP/ROM-Loader-
      Protokolls aus `esp32.ts`, sondern Aufruf von `esptool`/`espefuse`
      (`EspTool.cs`). Geprüft und bestätigt: **beide heute genutzten Felder sind
      darüber erreichbar** – `esptool read-mac` liefert Chip-Typ + MAC direkt im
      Klartext-Banner (kein `--format json` für diesen Befehl verfügbar, daher
      per Regex geparst), `espefuse summary --format json` liefert
      `KEY_PURPOSE_0`.."5"/`SPI_BOOT_CRYPT_CNT` bereits **chip-übergreifend
      decodiert** – im TS-Original musste `ESP32S3.updateChipInfo()` dafür noch
      chip-spezifische Efuse-Registeradressen von Hand kennen (separate
      `ESP32Classic`/`ESP32S3`-Unterklassen); `espefuse` nimmt diese Arbeit
      komplett ab. Die Purpose-Kombinatorik selbst (welche
      `KEY_PURPOSE`-Kombination + `SPI_BOOT_CRYPT_CNT`-Bit-Parität bedeutet
      "Verschlüsselung aktiv") 1:1 aus `esp32.ts` übernommen.

      **Zwei echte Stolpersteine beim Testen gegen das echte, angeschlossene
      Board gefunden**:
      1. `esptool` erkennt den angeschlossenen Port selbstständig (kein
         VID/PID-Scan wie `esp32.ts`s `FindProbablePorts()` nötig), `espefuse`
         dagegen NICHT – braucht zwingend `--port`. Behoben, indem der von
         `esptool read-mac`s Ausgabe erkannte Port (`Serial port COM4:`)
         mitgelesen und an den `espefuse`-Aufruf weitergereicht wird, statt
         ihn ein zweites Mal zu suchen oder fest zu verdrahten.
      2. **Echter Bug, reale Datei betroffen**: `IBoardInfo.cs`s berechnete
         Anzeige-Properties (`BoardRolesDisplay`/`BoardSettingsDisplay`,
         ursprünglich nur für `Phases/Info.cs`s Konsolenausgabe gedacht)
         hatten kein `[JsonIgnore]` – beim ersten echten Schreibzugriff von
         `BoardContext.LoadFromLiveMac()` (aktualisiert `last_connected_dt`
         eines bestehenden Eintrags, dafür `JsonSerializer.Serialize(board)`)
         wurden dadurch zwei zusätzliche, nie vorher in `board_info.json`
         vorhandene Felder in die ECHTE Datei dieses Boards geschrieben.
         Sofort bemerkt (Vorher/Nachher-Vergleich, Teil der etablierten
         Vorsichtsroutine), `[JsonIgnore]` ergänzt, betroffene Dateien
         (Repo-Root-Cache UND Board-Archiv) durch erneuten Lauf bereinigt.

      **`BoardContext.cs` erweitert**: `Load()` jetzt mit einem
      `updateLastConnected`-Parameter, geteilt zwischen `LoadCached()`
      (unverändert, `false`) und neu `LoadFromLiveMac(mac)`
      (`true` – Äquivalent zu `Context.get(config, updateWithCurrentlyConnectedBoard: true)`
      bzw. dem `addOrUpdateConnectedBoard`-Gulp-Task). `Phases/Info.cs`
      bewusst NICHT auf `LoadFromLiveMac` umgestellt (bliebe read-only) –
      stattdessen ruft es jetzt `EspTool.ReadHardwareIds()` best-effort in
      einem `try/catch` auf und vergleicht die live gelesene MAC gegen den
      Cache, ohne jemals zu schreiben – löst damit das seit Schritt 1
      offene `TODO(ReadHardwareIds)` ("Is current board") aus dem
      TS-Original nach.

      **Nebenbefund, unabhängig von diesem Code**: die ESP-IDF-Python-venv auf
      diesem Rechner ist defekt (s. Schritt 10, `BuildFirmware`) – `esptool`/
      `espefuse` brauchen sie aber gar nicht zwingend (eigenständige,
      pip-installierbare Pakete), deshalb per `pip install esptool` in eine
      andere, funktionierende Python-Installation auf diesem Rechner
      installiert. `EspTool.cs` ruft sie deshalb bewusst OHNE
      `export.bat`-Aktivierung auf (anders als `BuildFirmware.cs`/`idf.py`).

      **Echt end-to-end verifiziert, gegen das tatsächlich angeschlossene
      Board** (MAC `48:27:e2:d2:4e:64`, exakt das Board, mit dem in dieser
      Session durchgehend gearbeitet wurde): `esptool read-mac` erkennt Chip
      `ESP32-S3` und die korrekte MAC; `Phases/Info.cs` zeigt jetzt live
      "Is current board: yes"; `Phases/ReadHardwareIds.cs` aktualisiert
      `last_connected_dt` korrekt in Repo-Root-Cache UND Board-Archiv, alle
      anderen Felder bleiben unverändert. Flash-Encryption-Key-Erkennung
      meldet korrekt "no" (passend zu `SPI_BOOT_CRYPT_CNT = Disable`, per
      `espefuse summary` bestätigt) – der "Key vorhanden"-Zweig (ESP32-S3 mit
      `XTS_AES_256`/`_128`) konnte mangels eines Testboards MIT aktivierter
      Verschlüsselung nicht real durchgespielt werden, nur die Logik dafür
      1:1 aus `esp32.ts` übernommen. ESP32-"Classic"-Chips (nicht-S3, andere
      Efuse-Feldnamen) ebenfalls nicht real testbar – `EspTool.cs` fällt in
      diesem Fall konservativ auf "keine Verschlüsselung" zurück statt zu
      werfen.
  12. `FlashFirmware` (inkl. Encryption) – **unverschlüsselter Pfad portiert
      und ECHT gegen das angeschlossene Board geflasht (2026-08-01), letzter
      Schritt der Migrationsstrategie.**

      Portierung von `gulpfile.ts:flashFirmware()` (`espidf.ts:flashFirmware()`).
      Dispatcht wie im TS-Original anhand von `board_info.json`s
      `flash_encryption_key_burned_and_activated` – für jedes bisher bekannte
      sensact-Board `false`, also der unverschlüsselte Pfad. Neue Dateien:
      `FlasherArgs.cs` (liest das von `idf.py build` erzeugte
      `build/flasher_args.json`), `PartitionsCsv.cs` (Portierung von
      `parsePartitionsCSVFromFile()`, aktuell nur fürs spätere NVS-Handling
      vorbereitet, nicht im aktiven Pfad genutzt), `EspTool.WriteFlash()`
      (baut `esptool write-flash --flash-size keep <offset> <file> ...`).

      **Echter, im TS-Original nie aufgefallener Fehler beim Portieren
      gefunden**: `IFlasherConfiguration` (espidf.ts) erwartet ein Feld
      `partitionTable` (camelCase), das reale, von diesem ESP-IDF erzeugte
      `flasher_args.json` nennt es aber `"partition-table"` (mit Bindestrich)
      – ein Zugriff über die TS-Schnittstelle liefert dafür `undefined`,
      vermutlich nie bemerkt, weil dieser Wert praktisch nie gebraucht wurde.
      `FlasherArgs.cs` liest bewusst den ECHTEN Feldnamen, nicht den aus der
      TS-Schnittstelle.

      **Bewusst NICHT implementiert**: der verschlüsselte Pfad
      (`createRandomFlashEncryptionKeyLazily`/
      `encryptPartitions_Bootloader_App_PartitionTable_OtaData`/
      `burnFlashEncryptionKeyAndActivateEncryptedFlash`) – Letzteres brennt
      EFuses PERMANENT UND UNUMKEHRBAR. Kein aktuell bekanntes Board nutzt
      diesen Pfad; eine so folgenschwere, echte Hardware dauerhaft
      verändernde Operation gehört nicht "nebenbei" in eine
      Migrationsarbeit, sondern in einen eigenen, separat abgestimmten
      Schritt, falls tatsächlich einmal ein Board verschlüsselt werden soll.
      Ebenso ausgelassen: NVS-Überschreiben (in `gulpfile.ts` ohnehin per
      Konstante deaktiviert, bräuchte zusätzlich die noch nicht portierte
      Usersettings-NVS-Codegenerierung) – bewusst kein toter Code dafür
      mitgeschleppt.

      **Echt end-to-end verifiziert, mit expliziter Rückfrage vor der
      Ausführung** (echter Schreibzugriff auf das aktive, am Haus laufende
      Board – höheres Risiko als alles vorherige in dieser Session, da
      generierte Dateien beliebig oft neu erzeugt werden können, ein
      Flash-Vorgang dagegen die Firmware auf dem echten Gerät ersetzt):
      mit der vorhandenen (vom 2026-06-29 stammenden, da `BuildFirmware`
      mangels funktionierender ESP-IDF-venv keine frische Binary erzeugen
      konnte) `build/`-Firmware alle 5 Sektionen
      (Bootloader/App/Partition-Table/OTA-Data/Storage) erfolgreich
      geschrieben UND von `esptool` selbst verifiziert ("Hash of data
      verified" je Sektion), danach Hard-Reset über RTS-Pin – das Board lief
      nach dem Flash normal weiter. Damit sind 11 der 12
      Migrationsstrategie-Schritte real gegen das tatsächliche Board
      verifiziert (nur `BuildFirmware` bleibt wegen der kaputten venv offen,
      s. Schritt 10 – `FlashFirmware` selbst brauchte dafür keinen frischen
      Build, da `esptool`/`espefuse` unabhängig von `idf.py`/`export.bat`
      funktionieren).
- [ ] Für jeden migrierten Schritt: beide Wege (alt/neu) parallel gegen dasselbe Board
      laufen lassen und Ergebnis vergleichen (Diff der generierten Dateien), bevor der
      alte Gulp-Task entfernt wird.
- [ ] `builder/package.json`-Scripts (`i`, `f`, `u`, `c`, `wc`) erst löschen, wenn das
      C#-Äquivalent nachweislich das Gleiche tut.
- [ ] `docs/build-process.md` (Stufe 1) parallel nachziehen.

## Entschieden

- Das neue C#-Tool lebt im selben Repo (`sensact` → `firmware/sensact_firmware/`),
  nicht in einem eigenständigen Repo.
- `esptool.py`/`espsecure.py`/`espefuse.py` bleiben als Python-CLI-Aufrufe (über
  `ProcessRunner`, analog zum bisherigen `exec_in_idf_terminal`-Ansatz) – keine
  Nativisierung.
- SQLite-basierte Board-Typ-Historie wird **nicht** übernommen, dateibasiertes
  Konzept (`board_info.json`) bleibt Zielarchitektur – siehe eigener Abschnitt oben
  ("Bestätigt: SQLite war für ESP32-Boards eine Interims-Lösung...").
- `builder/` neben dem bestehenden `builder/` als Übergangszustand während der
  Migration ist ok (bestätigt).
- `ns09usersettings`-Umbau auf 4 eigenständige Classes statt einer Union-in-Class
  (s. Mapping-Tabelle oben) ist so gewünscht (bestätigt).

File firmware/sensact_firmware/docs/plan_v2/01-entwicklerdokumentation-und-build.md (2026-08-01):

# Stufe 1 – Entwicklerdokumentation (insbesondere Build-Prozess)

Ziel: Ein neuer Entwickler (oder Klaus in 6 Monaten) kann anhand von `docs/` allein
verstehen, woraus das System besteht, wie ein Build/Flash abläuft und wo welche
Artefakte herkommen – ohne den Gulp-Code lesen zu müssen.

## Warum das jetzt zuerst sinnvoll ist

Die Recherche für diesen Plan hat gezeigt: das Wissen über den Build-Prozess steckt
aktuell ausschließlich im Code (`gulpfile.ts`, mehrere TS-Module in
`espidf-vite-secure-build-tools`, `CMakeLists.txt`). Es gibt keine einzige
zusammenfassende Doku-Seite. Das macht sowohl Stufe 2 (Migration) als auch das
Onboarding neuer Mitwirkender unnötig schwer.

## Struktur des neuen `docs/`-Ordners (Vorschlag)

```
docs/
  README.md                  – Einstiegspunkt, verlinkt alles andere
  repo-map.md                – Die Repo-Landschaft (siehe 00-overview.md), Abhängigkeiten
  build-process.md           – Der Build-Prozess Schritt für Schritt (siehe unten)
  board-provisioning.md      – Wie ein neues Board angelegt/verbunden wird
  architecture.md            – Lebendes Architektur-Dokument, wird in Stufe 4 gepflegt
  plan_v2/                   – dieser Plan
```

## Inhalt von `build-process.md` (Kernstück dieser Stufe)

Muss mindestens folgende Punkte erklären, jeweils mit Verweis auf die Quelldatei:

1. **Voraussetzungen**
   - ESP-IDF Version (`dependencies.lock`: `idf 6.0.0`, Target `esp32s3`), `IDF_PATH`
     muss gesetzt sein.
   - Node.js/npm im `builder/`-Ordner (`npm install`), `flatc` (Flatbuffers-Compiler)
     im PATH.
   - Absoluter Pfad-Bedarf: `C:\repos\generated\` (hart codiert, siehe
     `CMakeLists.txt:4` und `gulpfile.ts:37`), `%USERPROFILE%\OneDrive - HSOS\...`
     für Board-Secrets. **Das ist ein Portabilitätsproblem** – in `docs/` erstmal nur
     dokumentieren ("so ist es aktuell"), die eigentliche Bereinigung ist Sache von
     Stufe 4 (siehe dort).
   - `.claude`/`.vscode`-Setup, falls relevant für neue Mitwirkende.

2. **Die Repo-Abhängigkeiten für einen Build** (Diagramm/Tabelle):
   - `EXTRA_COMPONENT_DIRS` aus `CMakeLists.txt:7`: `espidf-components`,
     `sensact/espidf-components`, `espidf-components-lcd`,
     `espidf-component-webmanager`.
   - `builder/package.json`-Dependencies auf `file:../../../../npm-packages/...` und
     `web/package.json`-Dependencies auf `file:../../../../generated/...` und
     `file:../../../../npm-packages/...`.

3. **Die npm-Scripts in `builder/package.json`** und was sie tun (Mapping auf
   Gulp-Tasks in `gulpfile.ts`):
   - `npm run i` → `info` – zeigt aktuellen Board-/Verbindungsstatus.
   - `npm run u` → `addOrUpdateConnectedBoard` – liest verbundenes Board aus (MAC
     etc.), legt/aktualisiert `board_info.json` board-spezifisch ab.
   - `npm run f` → `createFiles` (`gulpfile.ts:100`) – der zentrale Codegen-Schritt:
     1. `sensact.Sensact.PrepareSensactFiles()` (`sensact_code_generator.ts`):
        generiert `applicationIds.fbs`/`commandTypes.fbs`, TS-Pakete
        `sensact_sendCommandImplementation` und `sensact_appsbuilder` aus
        Board-/Node-spezifischen Templates.
     2. Flatbuffers-Codegen für C++ und TS (`flatbuffers_generate_c/_ts`, ruft
        `flatc` auf) aus `flatbuffers/*.fbs` (dieses Repo) und
        `espidf-component-webmanager/flatbuffers/*.fbs`.
     3. Zertifikate (lazy, nur wenn nicht vorhanden): selbstsigniertes ESP32-Zertifikat
        über `certificates.ts` (node-forge), signiert mit der lokalen Root-CA aus
        `OneDrive - HSOS\certificates`.
     4. Flash-Encryption-Key (lazy).
     5. Config-Dateien: `createObjectWithDefines()` sammelt alle Build-Defines
        (Board-Settings, Sensact-Node-Descriptor, Git-Hash, Zeitstempel, ASCII-Banner
        …) und schreibt sie dreifach raus: `cmake/config.json` (für CMake),
        C++-Header `runtimeconfig.hh`/`runtimeconfig_defines.hh`, TS-Paket
        `runtimeconfig_ts`.
   - `npm run wc` → `buildWebForCurrent` = `createFiles` + `buildAndCompressWebProject`
     (Vite-Build + Brotli-Kompression, `vite_helper.ts`).
   - `npm run c` → `buildForCurrent` = obiges + `idf.py build` (`espidf.ts`).
   - Default-Task (`gulp` ohne Argument) → volle Kette inkl. Flash:
     `addOrUpdateConnectedBoard` → `buildForCurrent` →
     `encryptFirmwareIfNecessary` → `flashFirmware`.

4. **Was wird wohin generiert** (Tabelle: Artefakt → Zielpfad → erzeugt von):
   Flatbuffers C++/TS, Runtimeconfig C++/TS, Web-Bundle, Zertifikate,
   Flash-Encryption-Key, `cmake/config.json`.

5. **Board-Provisioning-Flow** (eigene Datei `board-provisioning.md`, aber hier
   verlinkt): Wie sieht der Ablauf für ein *neues* Board aus? MAC auslesen → Eintrag
   unter `OneDrive - HSOS\esp32_boards\<mac-dir>\board_info.json` → `NODE_ID`/Board-Rolle
   festlegen → passendes `main/hal/<NODE_ID>/{hal.inc, station_config_hardware.inc,
   station_config_hosts.inc}` muss existieren (wer generiert diese – aktuell scheinbar
   manuell gepflegt, klären und dokumentieren!).

6. **Web-Dev-Server / Proxy** (aktuell in Bearbeitung, siehe `web/vite.config.mts`,
   uncommitted Änderung im Arbeitsverzeichnis zum Zeitpunkt der Planerstellung):
   - `npm run dev` im `web/`-Ordner startet Vite-Dev-Server.
   - `wsProxyPlugin` proxied WebSocket-Verbindungen zum echten Board
     (`WEBSOCKET_HOST`), weil Browser und Board unterschiedliche Origins haben und
     das Session-Cookie sonst nicht mitgeschickt wird. Der Proxy loggt sich selbst
     einmalig ein und cached das Session-Cookie.
   - Dieser Teil ist eng mit Stufe 3 (Wifimanager/Login-Review) verzahnt – auf
     Konsistenz zwischen beiden Stufen achten, insbesondere den dort dokumentierten
     Set-Cookie-Bug.

7. **Troubleshooting**: bekannte Stolpersteine (z.B. Zertifikatspfad-Diskrepanz
   zwischen `gulpfile.ts` und `main/CMakeLists.txt` – dokumentieren als bekanntes
   Problem, Fix in Stufe 4).

## Vorgehen

- [x] `docs/README.md`, `docs/repo-map.md`, `docs/build-process.md`,
      `docs/board-provisioning.md` angelegt (2026-07-31).
- [x] Mit Klaus geklärt: `main/hal/<NODE_ID>/*.inc`-Dateien werden reine Handarbeit
      gepflegt (kein Generator). In `board-provisioning.md` festgehalten.
- [x] `docs/architecture.md` als erste Bestandsaufnahme angelegt (2026-07-31,
      Node/HAL/Apps-Architektur + Cross-Cutting + bekannte tote Teile) – **noch nicht
      vollständig verifiziert**, wird im Zuge von Stufe 4 weiter geprüft/erweitert.
- [ ] Nach Abschluss von Stufe 2 (Builder-Migration): `build-process.md` aktualisieren,
      alte Gulp-Befehle durch die neuen C#-Befehle ersetzen bzw. beides
      gegenüberstellen, solange beide Wege parallel existieren.
- [ ] Laufend, im Zuge von Stufe 4: `architecture.md` verifizieren/erweitern.

## Entschieden

- Doku wird auf Deutsch geschrieben (bestätigt).

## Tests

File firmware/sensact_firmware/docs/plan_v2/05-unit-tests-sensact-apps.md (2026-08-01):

# Stufe 5 – Unit-Tests für die sensact-Apps

**Repo-Hinweis:** Zielcode liegt in
`C:\repos\sensact\espidf-components\sensact-applicationmodel\` – das ist **dasselbe
Git-Repo** wie `sensact_firmware` (beide sind Unterordner von `C:\repos\sensact`),
also unproblematisch bzgl. Commits. Liegt aber außerhalb des aktuellen
Session-Arbeitsverzeichnisses (`...\firmware\sensact_firmware`) – für Schreibzugriff
ggf. Pfad-Erlaubnis nötig bzw. neue Session mit weiterem Arbeitsverzeichnis.

## Was sind "sensact apps" konkret

Gefunden in `sensact-applicationmodel/apps/`: `blind`/`blindstimer` (Rollladen),
`onoff` (Relais mit ON/OFF/TOGGLE + Auto-Off-Timer), `pump`, `singlepwm`, `rgbw`,
`sound`, `milightcontroller`, `pushbutton`, `rotaryencoder`, `node`, `fingerprint`.
Jede App erbt von der abstrakten Basis `sensact::apps::cApplication`
(`cApplication.hh`: `Setup(iSensactContext*)`, `Loop(iSensactContext*)`,
`FillStatus(iSensactContext&, array<uint16_t,4>&)`, generierte
Command-Handler-Virtuals). Die Registry `cApplications::Glo2locCmd[]`/`Glo2locEvt[]`
(`cApplications.hh`, `model_applications.cc`) bildet `eApplicationID` auf konkrete
Instanzen ab. `cApplicationHost` (in `sensact_firmware/main/`) treibt
Setup/Loop/Status-Publishing aller Apps an.

## Warum das (relativ) gut testbar ist

Alle App-Methoden nehmen `iSensactContext*`/`iSensactContext&` entgegen – **eine
Abstraktion, keine ESP-IDF-Typen direkt**. Das ist die entscheidende
Testbarkeits-Voraussetzung: Wenn die App-Klassen selbst keine `esp_*`-Header
einbinden, lassen sie sich auf dem Host (Windows/Linux, ganz normaler
Desktop-Compiler) bauen und testen, ganz ohne ESP32-Hardware oder QEMU – wir müssen
nur ein Mock/Fake von `iSensactContext` bereitstellen.

## Vorgehen

- [ ] **Erster Schritt (Voraussetzung prüfen, bevor irgendwas gebaut wird):** alle
      Dateien in `sensact-applicationmodel/apps/*.cc/.hh` sowie `cApplication.hh`,
      `iSensactContext.hh` nach `#include <esp_...>`/`#include <freertos/...>`
      o.ä. durchsuchen. Falls einzelne Apps direkt ESP-IDF-Header einbinden
      (statt nur über `iSensactContext`), diese Stellen als Blocker vermerken – sie
      müssten zuerst entkoppelt werden (Architektur-Fund, ggf. nach
      `04-architektur-review.md` verschieben), bevor der Host-Test für genau diese
      App möglich ist.
- [ ] **Test-Framework-Entscheidung:** GoogleTest + GoogleMock, host-seitig (eigenes
      CMake-Projekt ohne ESP-IDF-Toolchain), nicht ESP-IDFs On-Target-Unity-Tests.
      Begründung: die Apps hängen nur an einem Interface (`iSensactContext`) – ein
      reiner Host-Build mit Mock ist erheblich schneller und einfacher aufzusetzen
      als ESP-IDFs `idf.py --preset linux`/QEMU-Testkomponenten, und es gibt mit
      `C:\repos\cpp-gtest-gmock-example` bereits eine funktionierende Referenz für
      CMake+GoogleTest-Setup, die als Vorlage dienen kann.
      **Bitte bestätigen**, falls eine andere Präferenz besteht (z.B. falls ESP-IDFs
      eigenes Unity-Test-Framework aus anderen Gründen gewünscht ist, etwa um auch
      HAL-nahen Code später mit demselben Framework zu testen).
- [ ] **Test-Projekt-Struktur anlegen** (Vorschlag, zur Bestätigung):
      `sensact-applicationmodel/test/` mit eigenem `CMakeLists.txt`
      (Host-Compiler, FetchContent für GoogleTest), das die App-`.cc`-Dateien direkt
      mitkompiliert (nicht die ESP-IDF-Komponente als Ganzes).
- [ ] **Einmalig:** `MockSensactContext : public iSensactContext` mit GoogleMock
      (`MOCK_METHOD`) für alle Interface-Methoden (`Now`, `SetU16Output`,
      `GetU16Input`, `SetRGBLed`, `GetRotaryEncoderValue`, `PlayMP3`, …) schreiben –
      wird von allen folgenden App-Tests wiederverwendet.
- [ ] **Pilot-App:** `onoff.cc` zuerst (kleinste, klarste App: ON/OFF/TOGGLE-Kommandos
      + Auto-Off-Timer). Damit das CMake/GoogleTest-Setup End-to-End einmal
      durchgespielt und als Muster für die restlichen Apps etabliert ist, bevor der
      Rollout beginnt.
- [ ] **Rollout auf die übrigen Apps**, je eigener Schritt/PR:
      `blind`/`blindstimer`, `pump`, `singlepwm`, `rgbw`, `sound`,
      `milightcontroller`, `pushbutton`, `rotaryencoder`, `node`, `fingerprint`.
      Reihenfolge nach Komplexität aufsteigend (nach `onoff` z.B. `pump`/`singlepwm`
      vor `blind`/`blindstimer`, die zustandsbehafteter sind – Timer-Logik).
- [ ] Je Test-Suite mindestens abdecken: Kommando-Handler (alle definierten
      Commands), `FillStatus`-Ausgabe für die wichtigsten Zustände, Timer-/
      Zeit-abhängiges Verhalten (über die gemockte `Now()` steuerbar), Edge Cases
      (z.B. ungültige Werte/Range-Grenzen, falls vorhanden).
- [ ] Optional, später: in `docs/build-process.md` (Stufe 1) dokumentieren, wie die
      Tests lokal ausgeführt werden (`ctest`/direkter Testbinary-Aufruf). CI ist
      aktuell nirgends im Projekt vorhanden – ob/wie das nachgerüstet wird, ist explizit
      **nicht Teil dieser Stufe**, nur als spätere Möglichkeit vermerkt.

## Entschieden

- Framework: **GoogleTest/GoogleMock**, host-seitig.
- Test-Projekt: **eigenständiges CMake-Projekt**, unabhängig von ESP-IDF buildbar.
- **Timing (wichtige Korrektur ggü. der ursprünglichen Annahme in
  [00-overview.md](00-overview.md)): Unit-Tests werden ganz zum Schluss umgesetzt,
  nicht parallel zu den anderen Stufen.** Diese Stufe ist also die letzte in der
  Praxis, nicht (wie ursprünglich vorgeschlagen) früh parallelisierbar. Wichtig
  während *aller* anderen Stufen: bei jedem Refactoring immer mitdenken, dass der
  entstehende Code hinterher gut testbar sein muss (z.B. weiterhin sauber gegen
  `iSensactContext` statt gegen ESP-IDF-Header programmieren) – Testbarkeit ist ein
  Kriterium für *jede* Umbau-Entscheidung, auch wenn die Tests selbst erst am Ende
  geschrieben werden. Siehe auch der entsprechende Hinweis in
  [04-architektur-review.md](04-architektur-review.md).

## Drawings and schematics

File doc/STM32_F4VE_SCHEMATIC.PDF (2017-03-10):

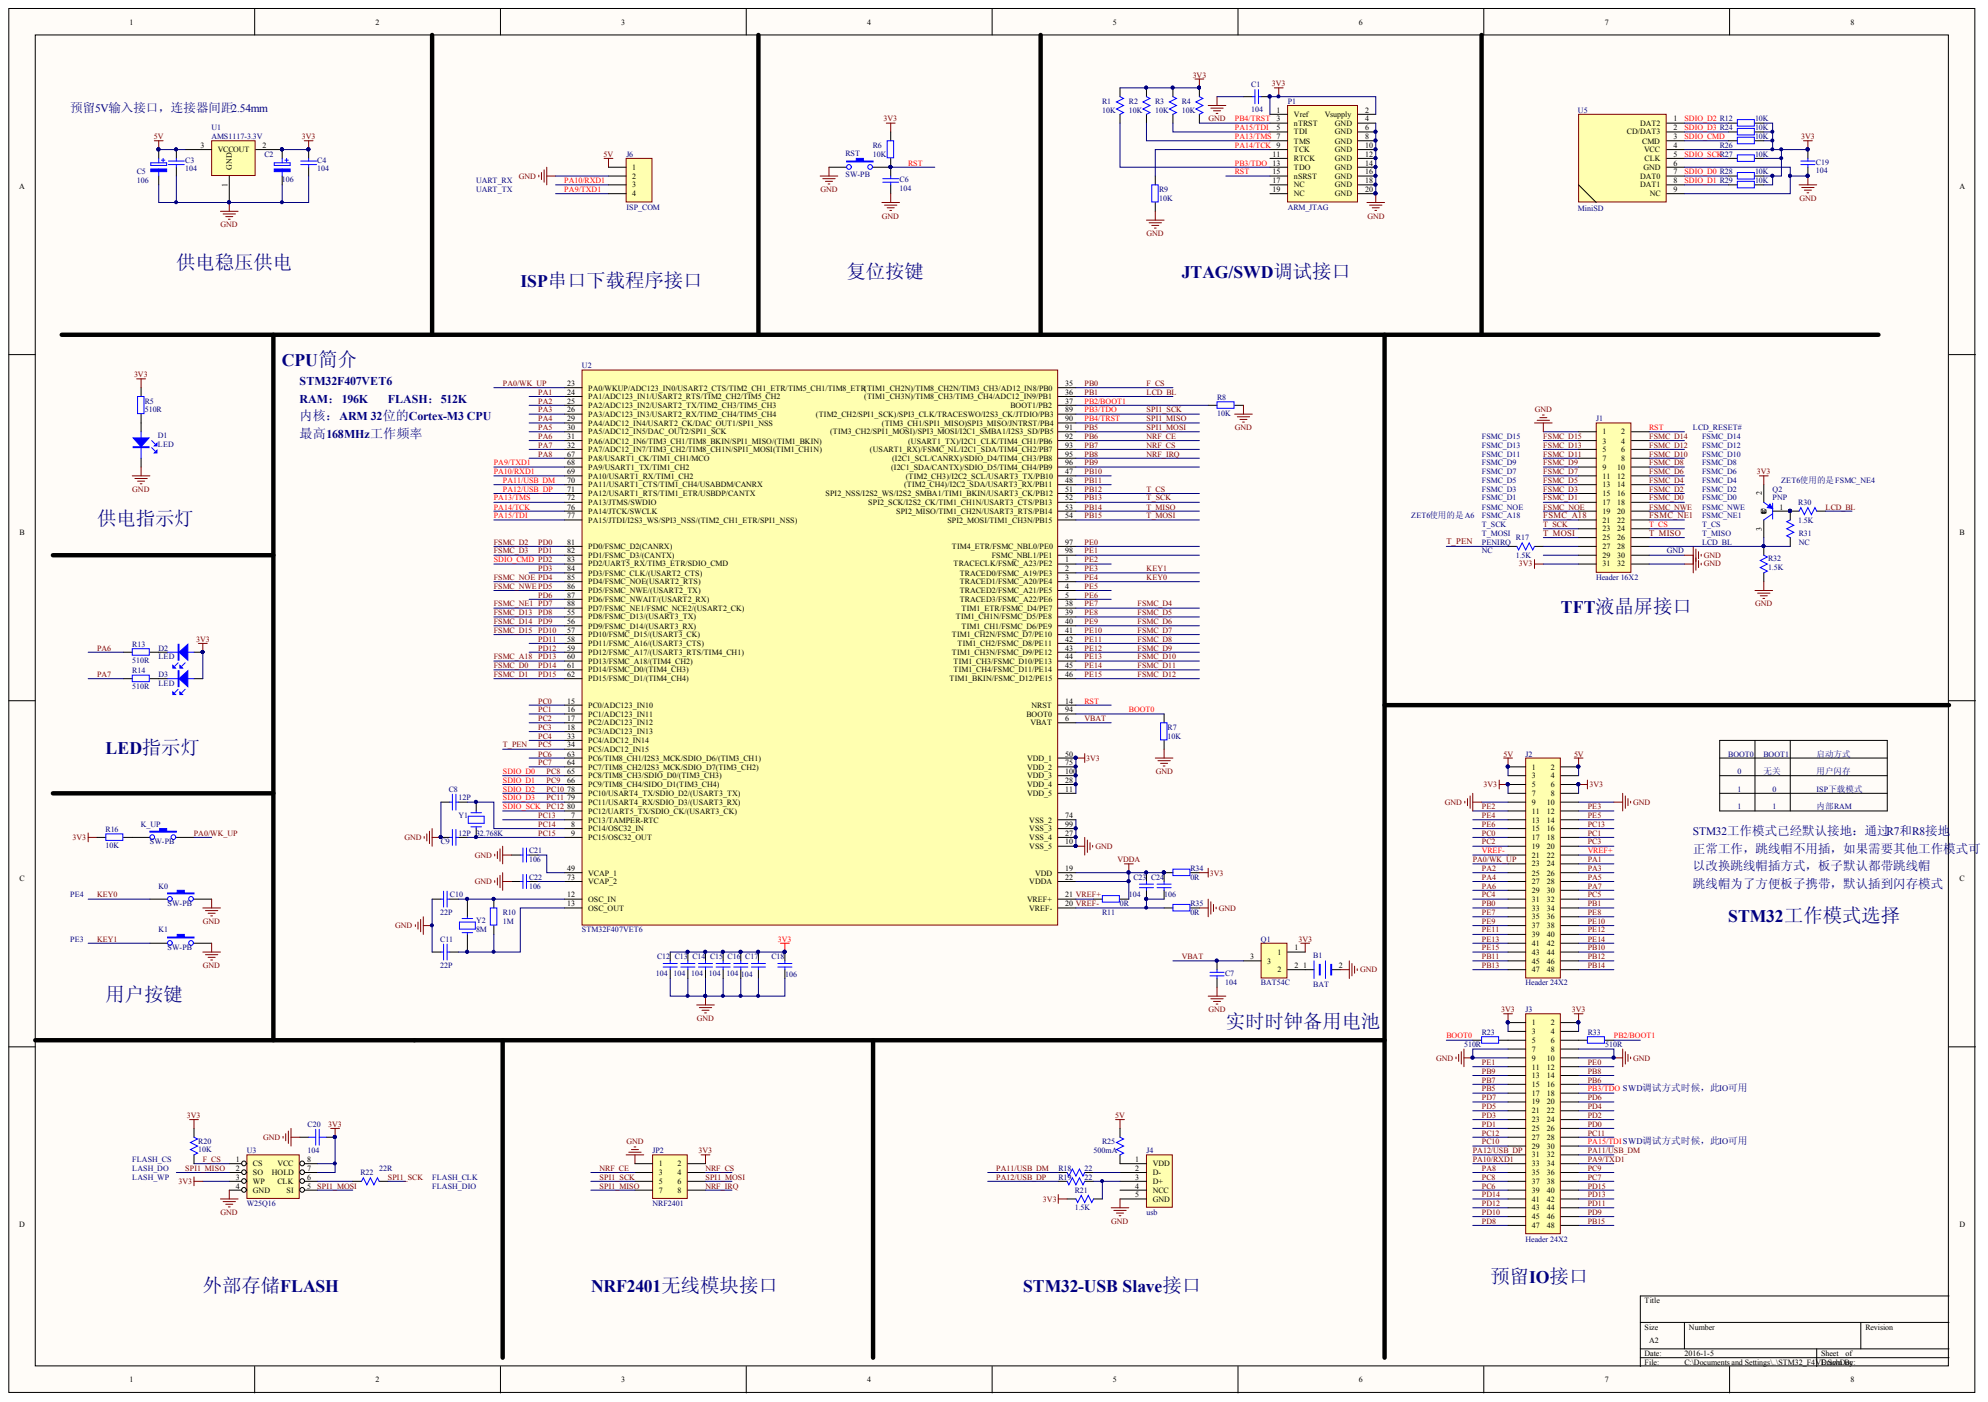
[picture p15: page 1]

SDIO_SCK PC12 | PC12/UART5_TX/SDIO_CK/(USART3_CK) 80

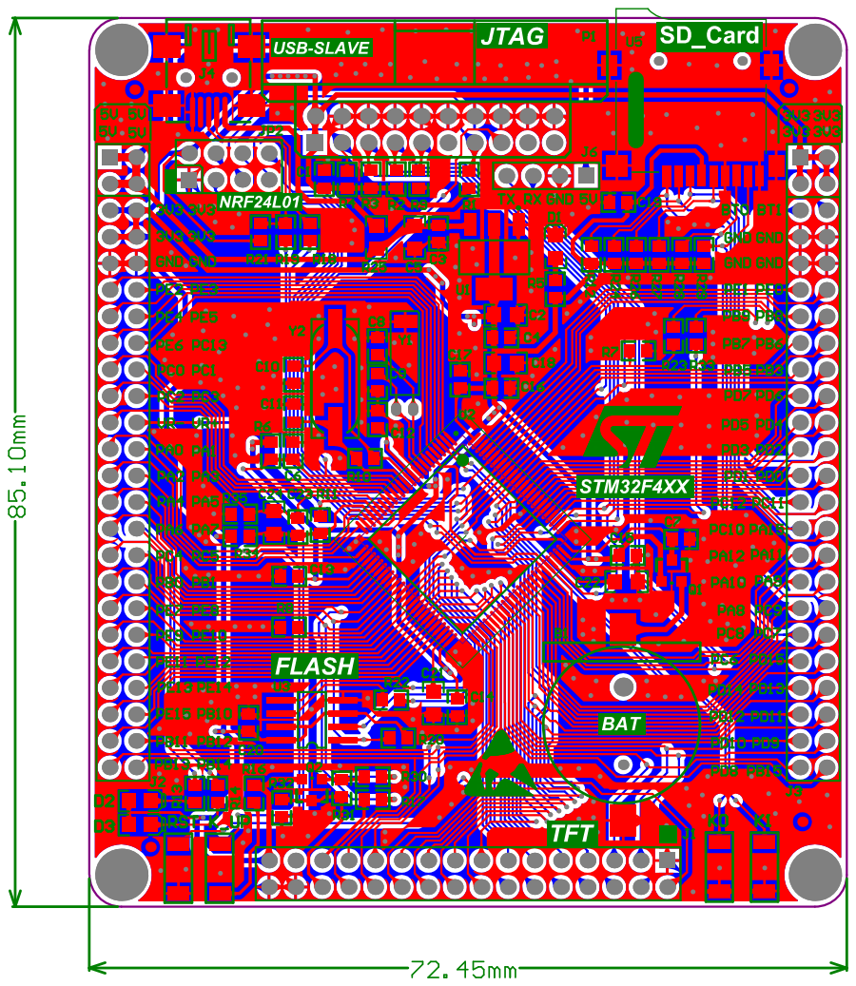
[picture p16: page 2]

Comment | Description | Designator | Footprint | LibRef | Quantity
BAT | | B1 | BAT | BATTERY | 1
104 | Capacitor, Capacitor, Capacitor, Capacitor, Capacitor, Capacitor, Capacitor, Capacitor, Capacitor, Capacitor, Capacitor, Capacitor (Semiconductor SIM Model), [NoValue], Capacitor | C1, C3, C4, C6, C7, C12, C13, C14, C15, C16, C17, C19, C20, C23 | RC0603 | Cap, CAP, CAP, CAP, Cap, Cap, Cap, Cap, Cap, Cap, Cap, Cap Semi, CAP, Cap | 14
106 | [NoValue], [NoValue], Capacitor, Capacitor, Capacitor, Capacitor | C2, C5, C18, C21, C22, C24 | RC0805 | ELECTRO2, ELECTRO2, Cap, Cap, Cap, Cap | 6
12P | | C8, C9 | RC0603 | CAP | 2
22P | Capacitor | C10, C11 | RC0603 | CAP | 2
LED | | D1, D2, D3 | LED0805 | LED | 3
Header 16X2 | Header, 16-Pin, Dual row | J1 | IDE2X16 | Header 16X2 | 1
Header 24X2 | Header, 24-Pin, Dual row | J2, J3 | IDE2X24 | Header 24X2 | 2
usb | | J4 | Mini_USB | usb | 1
ISP_COM | Header, 4-Pin | J6 | HDR1X4 | Header 4 | 1
NRF2401 | Header, 4-Pin, Dual row | JP2 | IDE2X4 | Header 4X2 | 1
SW-PB | | K0, K1, K_UP, RST | SW-SPST | SW-PB | 4
ARM_JTAG | JTAG | P1 | JTAG-20P | JTAG | 1
BAT54C | | Q1 | SOT-23-BAT54C | BAT54C | 1
PNP | PNP Bipolar Transistor | Q2 | PNP_SOT23 | PNP | 1
10K | [NoValue], [NoValue], [NoValue], [NoValue], Resistor, Resistor, Resistor, Resistor, Resistor, Resistor, [NoValue], Resistor, Resistor, Resistor, Resistor, Resistor | R1, R2, R3, R4, R6, R7, R8, R9, R12, R16, R20, R24, R26, R27, R28, R29 | RC0603 | RES, RES, RES, RES, Res2, Res2, Res2, Res2, Res2, Res2, RES, Res2, Res2, Res2, Res2, Res2 | 16
510R | Resistor | R5, R13, R14, R23, R33 | RC0603 | Res2 | 5
1M | Resistor | R10 | RC0603 | Res2 | 1
0R | Resistor | R11, R34, R35 | RC0603 | Res2 | 3
1.5K | | R17, R21, R30, R32 | RC0603 | RES | 4
22 | | R18, R19 | RC0603 | RES | 2
22R | | R22 | RC0603 | RES | 1
500mA | | R25 | RC0805 | RES | 1
NC | | R31 | RC0603 | RES | 1
AMS1117-3.3V | | U1 | SOT-223 | 11 | 1
STM32F407VET6 | | U2 | | STM32F407VET6 | 1
W25Q16 | | U3 | SOP8L | W25X16 | 1
MiniSD | | U5 | TF_SD | MiniSD | 1
32.768K | 晶振 | Y1 | JZ32768 | CRYSTAL | 1
8M | Crystal | Y2 | 49S_SMD | CRYSTAL | 1

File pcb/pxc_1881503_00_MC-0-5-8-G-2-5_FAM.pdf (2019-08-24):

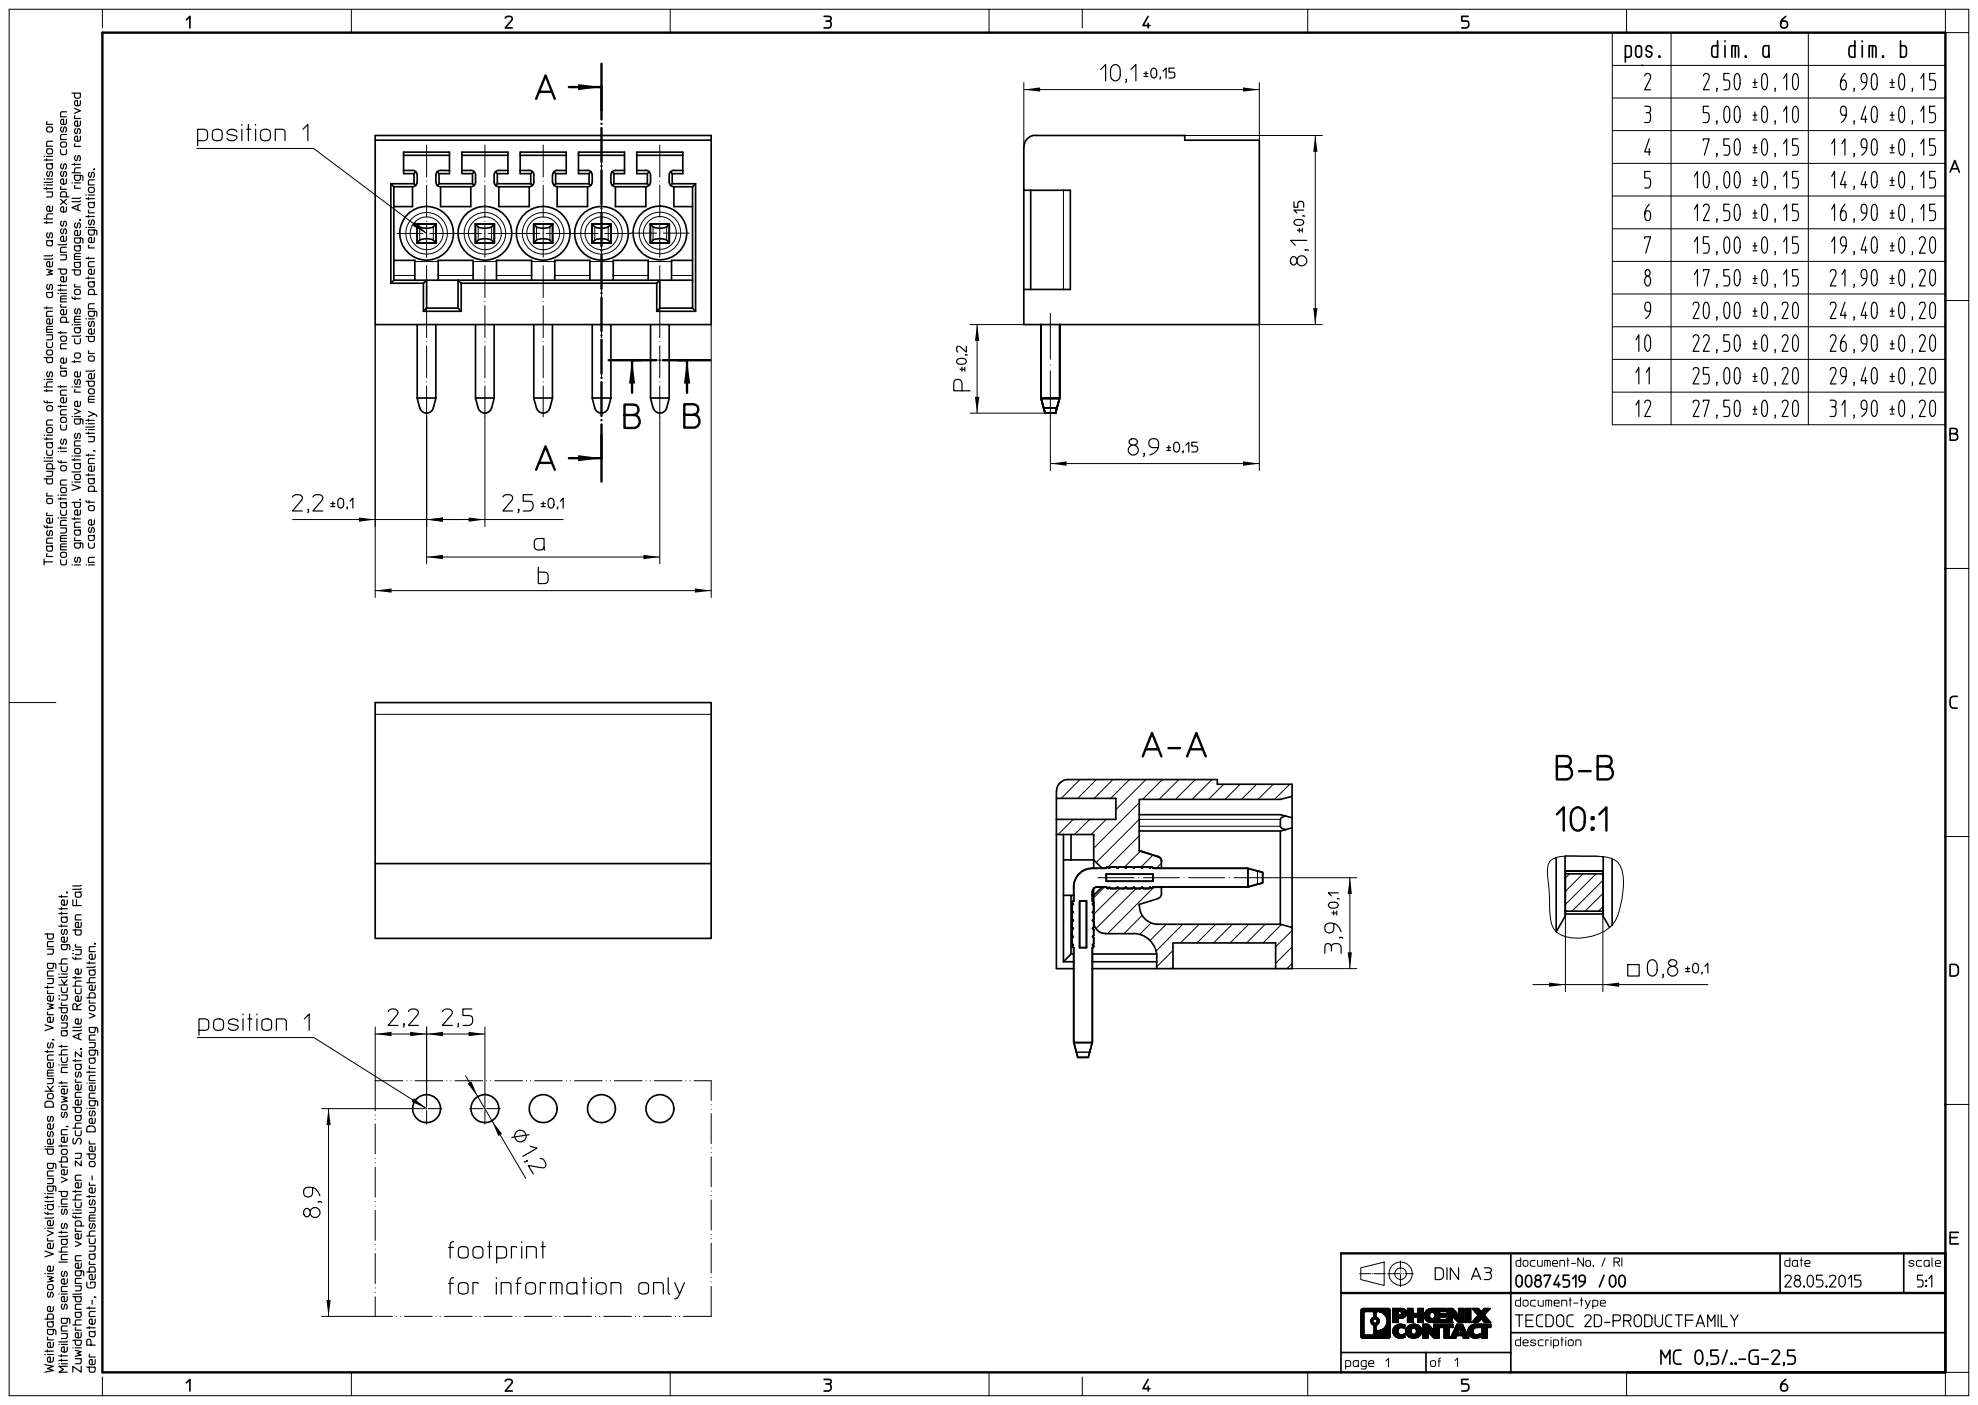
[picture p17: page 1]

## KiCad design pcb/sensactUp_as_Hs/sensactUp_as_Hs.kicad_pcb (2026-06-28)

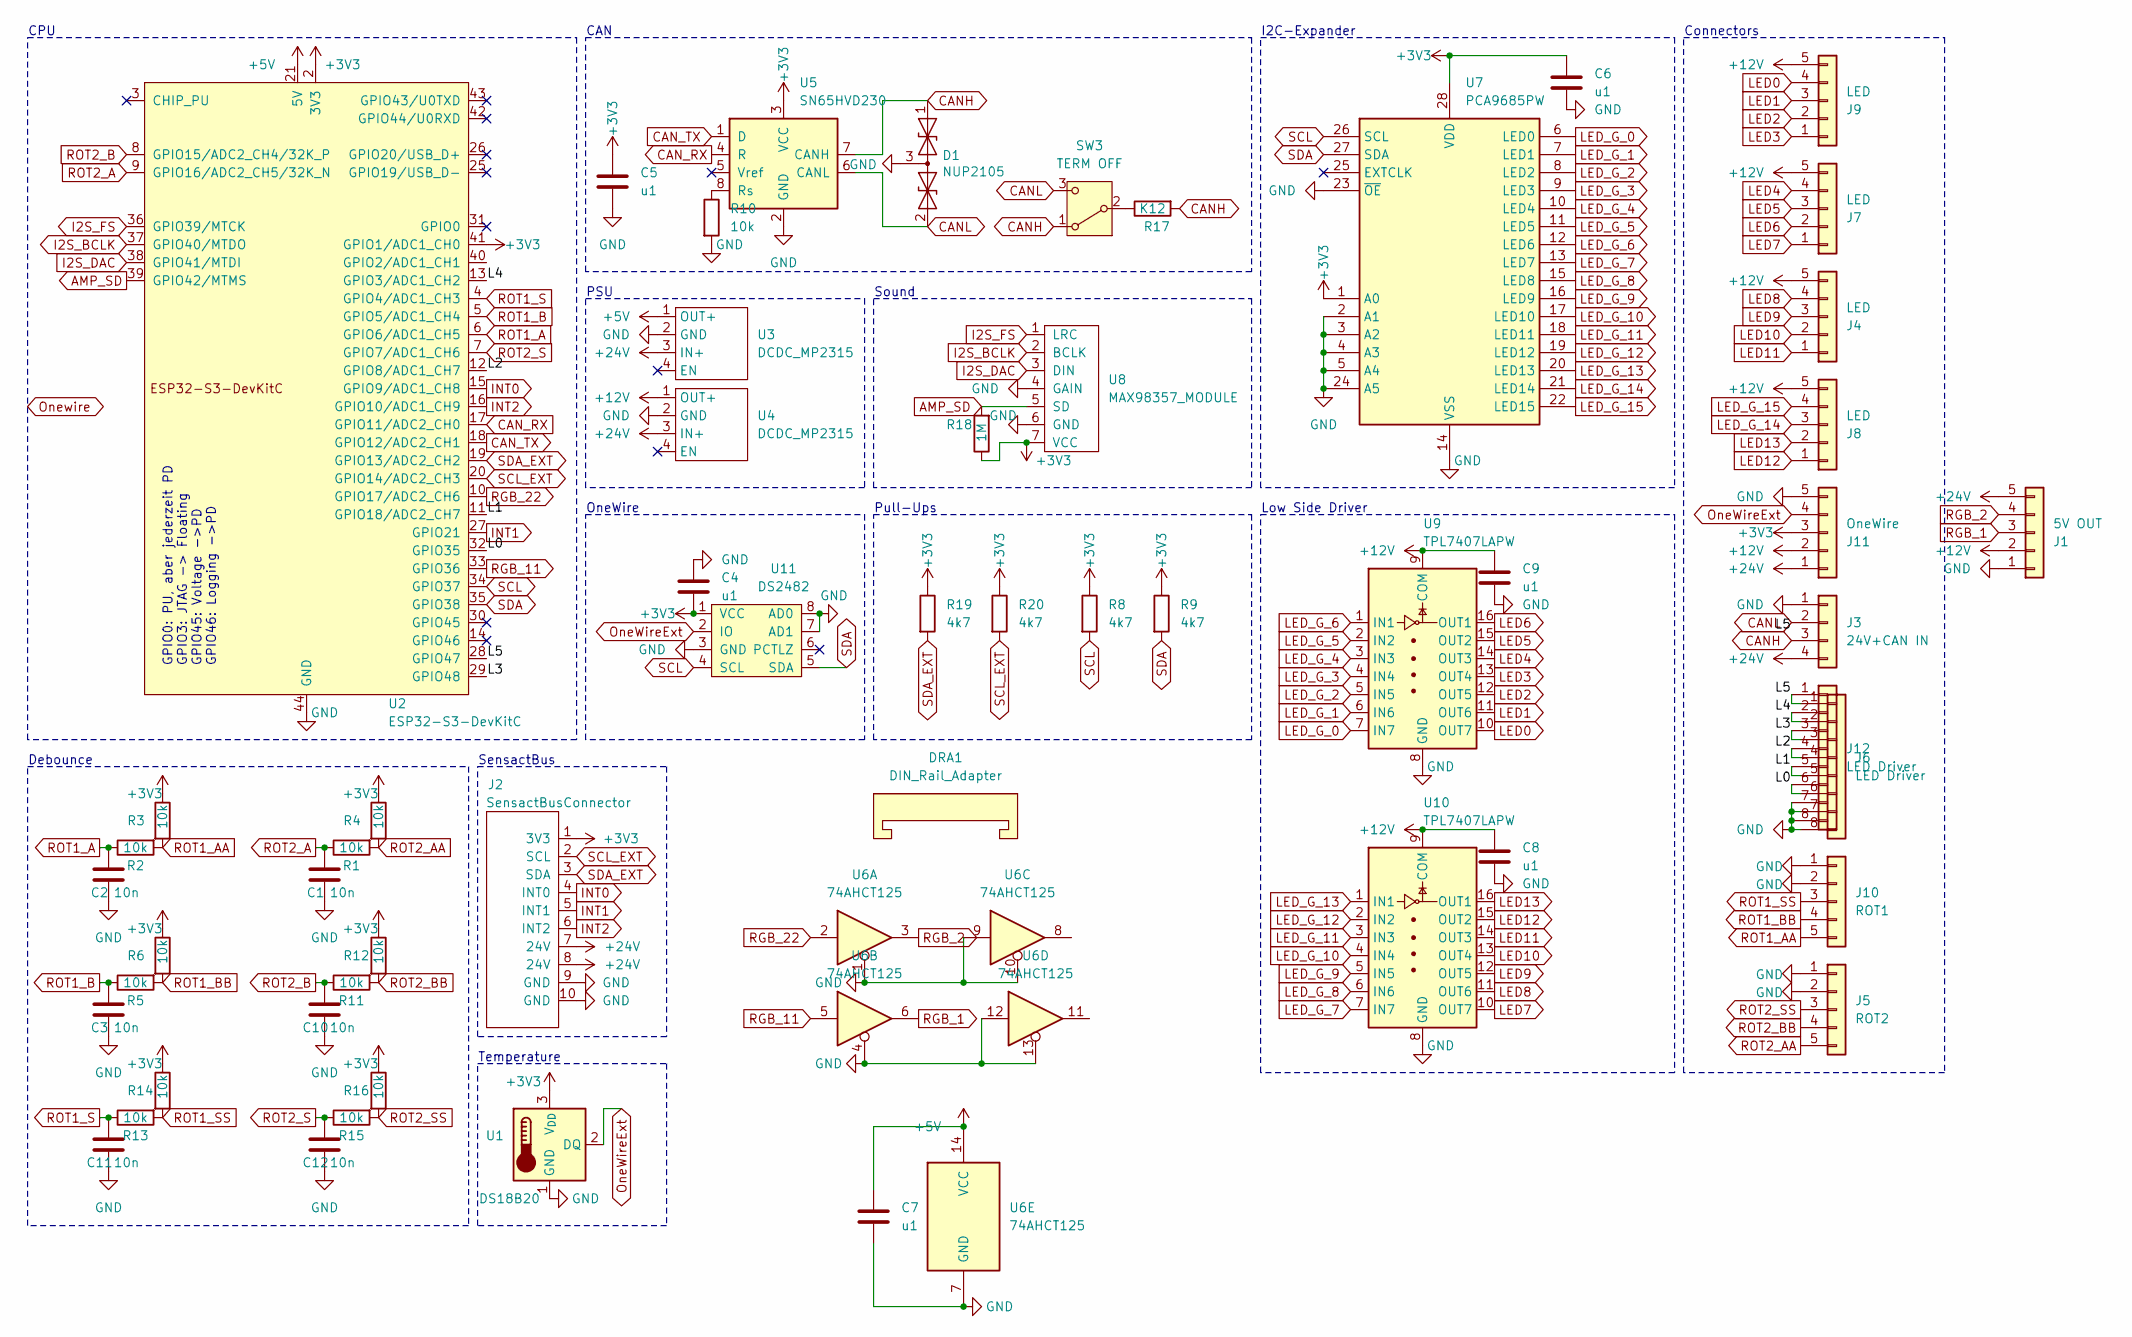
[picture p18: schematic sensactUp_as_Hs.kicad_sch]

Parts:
C1, C2, C3, C10, C11, C12: 10n; C_0805_2012Metric_Pad1.18x1.45mm_HandSolder
C4, C5, C6, C7, C8, C9: u1; C_0805_2012Metric_Pad1.18x1.45mm_HandSolder
D1: NUP2105; SOT-23_Handsoldering; MPN NUP2105L
DRA1: DIN_Rail_Adapter; Camdenboss CNMB-6
J1: 5V OUT; PhoenixContact_MCV_1,5_5-G-3.81_1x05_P3.81mm_Vertical_small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
J2: SensactBusConnector; IDC-Header_2x05_P2.54mm_Horizontal
J3: 24V+CAN IN; PhoenixContact_MCV_1,5_4-G-3.5_1x04_P3.50mm_Vertical_smalle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
J4, J7, J8, J9: LED; PhoenixContact_MCV_1,5_5-G-3.81_1x05_P3.81mm_Vertical_small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
J5: ROT2; PhoenixContact_MCV_1,5_5-G-3.81_1x05_P3.81mm_Vertical_small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
J6: LED Driver; PhoenixContact_MC_0,5_8-G-2.5_1x08_P2.50mm_Horizontal
J10: ROT1; PhoenixContact_MCV_1,5_5-G-3.81_1x05_P3.81mm_Vertical_small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
J11: OneWire; PhoenixContact_MCV_1,5_5-G-3.81_1x05_P3.81mm_Vertical_small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
J12: LED Driver; PinHeader_1x08_P2.54mm_Vertical
R1, R2, R3, R4, R5, R6, R10, R11, R12, R13, R14, R15, R16: 10k; R_0805_2012Metric_Pad1.20x1.40mm_HandSolder
R8, R9, R19, R20: 4k7; R_0805_2012Metric_Pad1.20x1.40mm_HandSolder
R17: K12; R_1206_3216Metric_Pad1.30x1.75mm_HandSolder; MPN 1206W4F1200T5E
R18: 1M; R_0805_2012Metric_Pad1.20x1.40mm_HandSolder
SW3: TERM OFF; Switch_SS12D00
U1: DS18B20; TO-92L_HandSolder
U2: ESP32-S3-DevKitC; ESP32-S3 chinese dev board
U3, U4: DCDC_MP2315; DCDC_MP2315_horizontal
U5: SN65HVD230; SOIC-8_3.9x4.9mm_P1.27mm
U6: 74AHCT125; SOIC-14_3.9x8.7mm_P1.27mm_handsolder
U7: PCA9685PW; TSSOP-28_4.4x9.7mm_Pitch0.65mm_handsolder
U8: MAX98357_MODULE; PinHeader_1x07_P2.54mm_Vertical
U9, U10: TPL7407LAPW; TSSOP-16_4.4x5mm_P0.65mm
U11: DS2482; SOIC-8_3.9x4.9mm_P1.27mm_handsolder

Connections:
+3V3: C4.1, C5.1, C6.1, J2.1 (3V3), J11.3, R3.1, R4.1, R6.1, R8.1, R9.1, R12.1, R14.1, R16.1, R18.1, R19.1, R20.1, U1.3 (V_{DD}), U2.1 (3V3), U2.2 (3V3), U2.41 (GPIO1/ADC1_CH0), U5.3 (VCC), U7.1 (A0), U7.28 (VDD), U8.7 (VCC), U11.1 (VCC)
+5V: C7.2, U2.21 (5V), U3.1 (OUT+), U6.14 (VCC)
+12V: C8.1, C9.1, J1.2, J4.5, J7.5, J8.5, J9.5, J11.2, U4.1 (OUT+), U9.9 (COM), U10.9 (COM)
+24V: J1.5, J2.7 (24V), J2.8 (24V), J3.4, J11.1, U3.3 (IN+), U4.3 (IN+)
/L0: J6.6, J12.6, U2.32 (GPIO35)
/L1: J6.5, J12.5, U2.11 (GPIO18/ADC2_CH7)
/L2: J6.4, J12.4, U2.12 (GPIO8/ADC1_CH7)
/L3: J6.3, J12.3, U2.29 (GPIO48)
/L4: J6.2, J12.2, U2.13 (GPIO3/ADC1_CH2)
/L5: J6.1, J12.1, U2.28 (GPIO47)
AMP_SD: R18.2, U2.39 (GPIO42/MTMS), U8.5 (SD)
CANH: D1.1 (A1), J3.3, R17.2, SW3.1 (A), U5.7 (CANH)
CANL: D1.2 (A2), J3.2, SW3.3 (C), U5.6 (CANL)
CAN_RX: U2.17 (GPIO11/ADC2_CH0), U5.4 (R)
CAN_TX: U2.18 (GPIO12/ADC2_CH1), U5.1 (D)
GND: C1.1, C2.1, C3.1, C4.2, C5.2, C6.2, C7.1, C8.2, C9.2, C10.1, C11.1, C12.1, D1.3 (common), J1.1, J2.9 (GND), J2.10 (GND), J3.1, J5.1, J5.2, J6.7, J6.8, J10.1, J10.2, J11.5, J12.7, J12.8, R10.2, U1.1 (GND), U2.22 (GND), U2.23 (GND), U2.24 (GND), U2.44 (GND), U3.2 (GND), U4.2 (GND), U5.2 (GND), U6.1, U6.4, U6.7 (GND), U6.9, U6.10, U6.12, U6.13, U7.2 (A1), U7.3 (A2), U7.4 (A3), U7.5 (A4), U7.14 (VSS), U7.23 (~OE), U7.24 (A5), U8.4 (GAIN), U8.6 (GND), U9.8 (GND), U10.8 (GND), U11.3 (GND), U11.7 (AD1), U11.8 (AD0)
I2S_BCLK: U2.37 (GPIO40/MTDO), U8.2 (BCLK)
I2S_DAC: U2.38 (GPIO41/MTDI), U8.3 (DIN)
I2S_FS: U2.36 (GPIO39/MTCK), U8.1 (LRC)
INT0: J2.4 (INT0), U2.15 (GPIO9/ADC1_CH8)
INT1: J2.5 (INT1), U2.27 (GPIO21)
INT2: J2.6 (INT2), U2.16 (GPIO10/ADC1_CH9)
LED0: J9.4, U9.10 (OUT7)
LED1: J9.3, U9.11 (OUT6)
LED2: J9.2, U9.12 (OUT5)
LED3: J9.1, U9.13 (OUT4)
LED4: J7.4, U9.14 (OUT3)
LED5: J7.3, U9.15 (OUT2)
LED6: J7.2, U9.16 (OUT1)
LED7: J7.1, U10.10 (OUT7)
LED8: J4.4, U10.11 (OUT6)
LED9: J4.3, U10.12 (OUT5)
LED10: J4.2, U10.13 (OUT4)
LED11: J4.1, U10.14 (OUT3)
LED12: J8.1, U10.15 (OUT2)
LED13: J8.2, U10.16 (OUT1)
LED_G_0: U7.6 (LED0), U9.7 (IN7)
LED_G_1: U7.7 (LED1), U9.6 (IN6)
LED_G_2: U7.8 (LED2), U9.5 (IN5)
LED_G_3: U7.9 (LED3), U9.4 (IN4)
LED_G_4: U7.10 (LED4), U9.3 (IN3)
LED_G_5: U7.11 (LED5), U9.2 (IN2)
LED_G_6: U7.12 (LED6), U9.1 (IN1)
LED_G_7: U7.13 (LED7), U10.7 (IN7)
LED_G_8: U7.15 (LED8), U10.6 (IN6)
LED_G_9: U7.16 (LED9), U10.5 (IN5)
LED_G_10: U7.17 (LED10), U10.4 (IN4)
LED_G_11: U7.18 (LED11), U10.3 (IN3)
LED_G_12: U7.19 (LED12), U10.2 (IN2)
LED_G_13: U7.20 (LED13), U10.1 (IN1)
LED_G_14: J8.3, U7.21 (LED14)
LED_G_15: J8.4, U7.22 (LED15)
unnamed: R17.1, SW3.2 (B)
unnamed: R10.1, U5.8 (Rs)
OneWireExt: J11.4, U1.2 (DQ), U11.2 (IO)
RGB_1: J1.3, U6.6
RGB_2: J1.4, U6.3
RGB_11: U2.33 (GPIO36), U6.5
RGB_22: U2.10 (GPIO17/ADC2_CH6), U6.2
ROT1_A: C2.2, R2.1, U2.6 (GPIO6/ADC1_CH5)
ROT1_AA: J10.5, R2.2, R3.2
ROT1_B: C3.2, R5.1, U2.5 (GPIO5/ADC1_CH4)
ROT1_BB: J10.4, R5.2, R6.2
ROT1_S: C11.2, R13.1, U2.4 (GPIO4/ADC1_CH3)
ROT1_SS: J10.3, R13.2, R14.2
ROT2_A: C1.2, R1.1, U2.9 (GPIO16/ADC2_CH5/32K_N)
ROT2_AA: J5.5, R1.2, R4.2
ROT2_B: C10.2, R11.1, U2.8 (GPIO15/ADC2_CH4/32K_P)
ROT2_BB: J5.4, R11.2, R12.2
ROT2_S: C12.2, R15.1, U2.7 (GPIO7/ADC1_CH6)
ROT2_SS: J5.3, R15.2, R16.2
SCL: R8.2, U2.34 (GPIO37), U7.26 (SCL), U11.4 (SCL)
SCL_EXT: J2.2 (SCL), R20.2, U2.20 (GPIO14/ADC2_CH3)
SDA: R9.2, U2.35 (GPIO38), U7.27 (SDA), U11.5 (SDA)
SDA_EXT: J2.3 (SDA), R19.2, U2.19 (GPIO13/ADC2_CH2)

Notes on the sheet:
GPIO0: PU, aber jederzeit PD GPIO3: JTAG -> Floating GPIO45: Voltage ->PD GPIO46: Logging ->PD
Low Side Driver
OneWire
Sound
CAN
Pull-Ups
I2C-Expander
Debounce
SensactBus
CPU
PSU
Connectors
Temperature

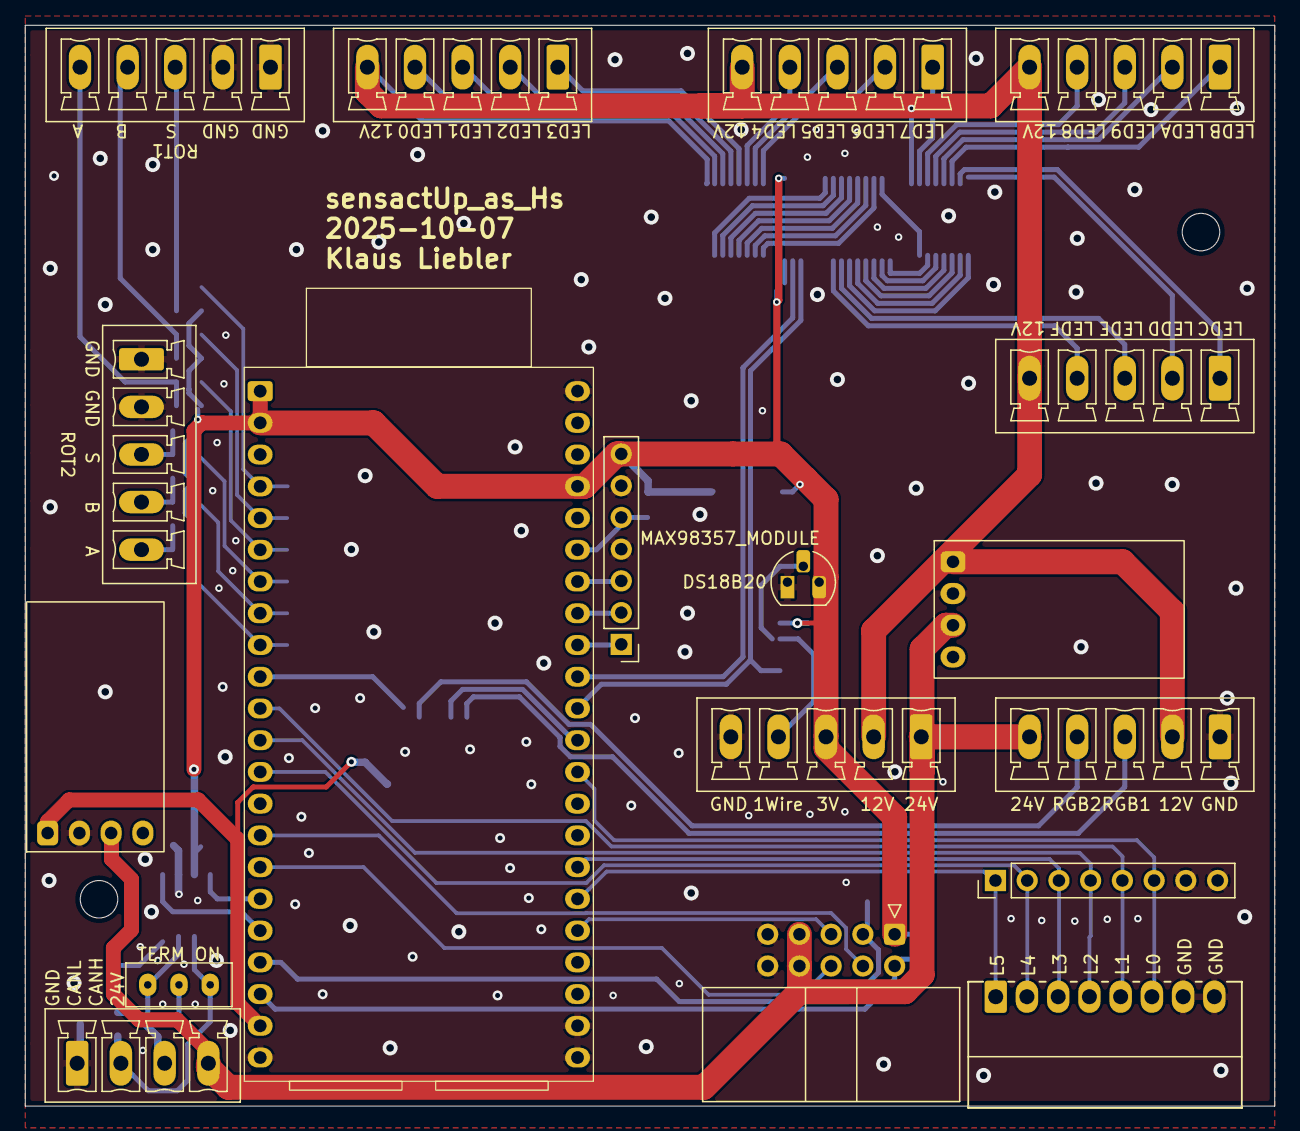
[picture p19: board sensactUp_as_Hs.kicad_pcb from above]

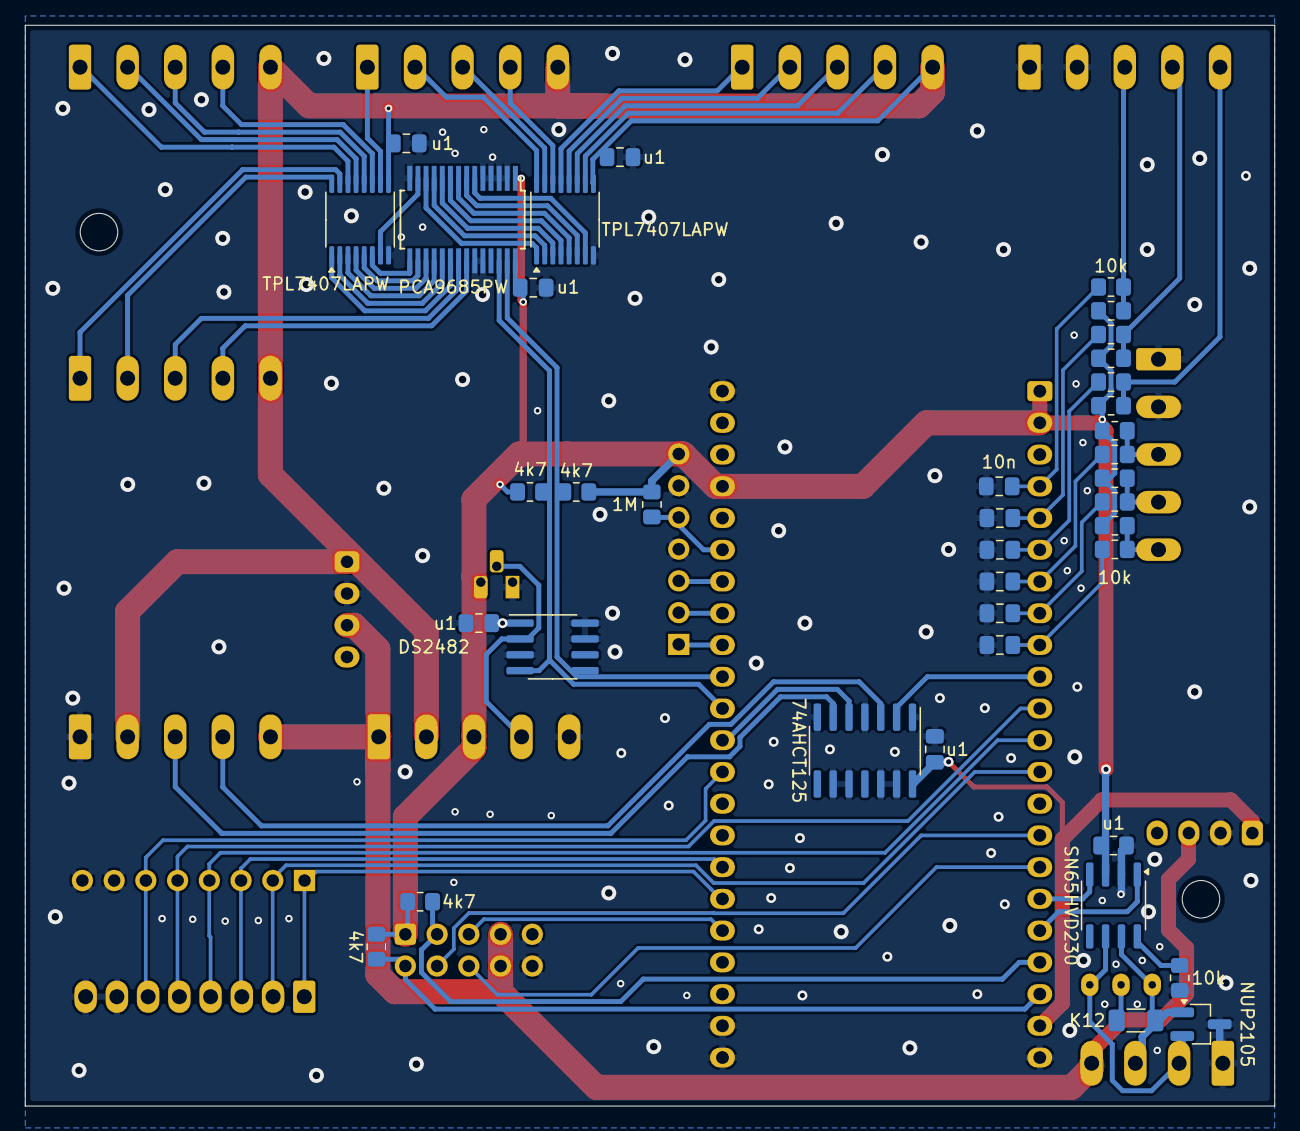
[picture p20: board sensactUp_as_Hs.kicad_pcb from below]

Board: 2 copper layers, 100.0 x 86.5 mm, 57 parts (38 on the bottom side), 75 nets.

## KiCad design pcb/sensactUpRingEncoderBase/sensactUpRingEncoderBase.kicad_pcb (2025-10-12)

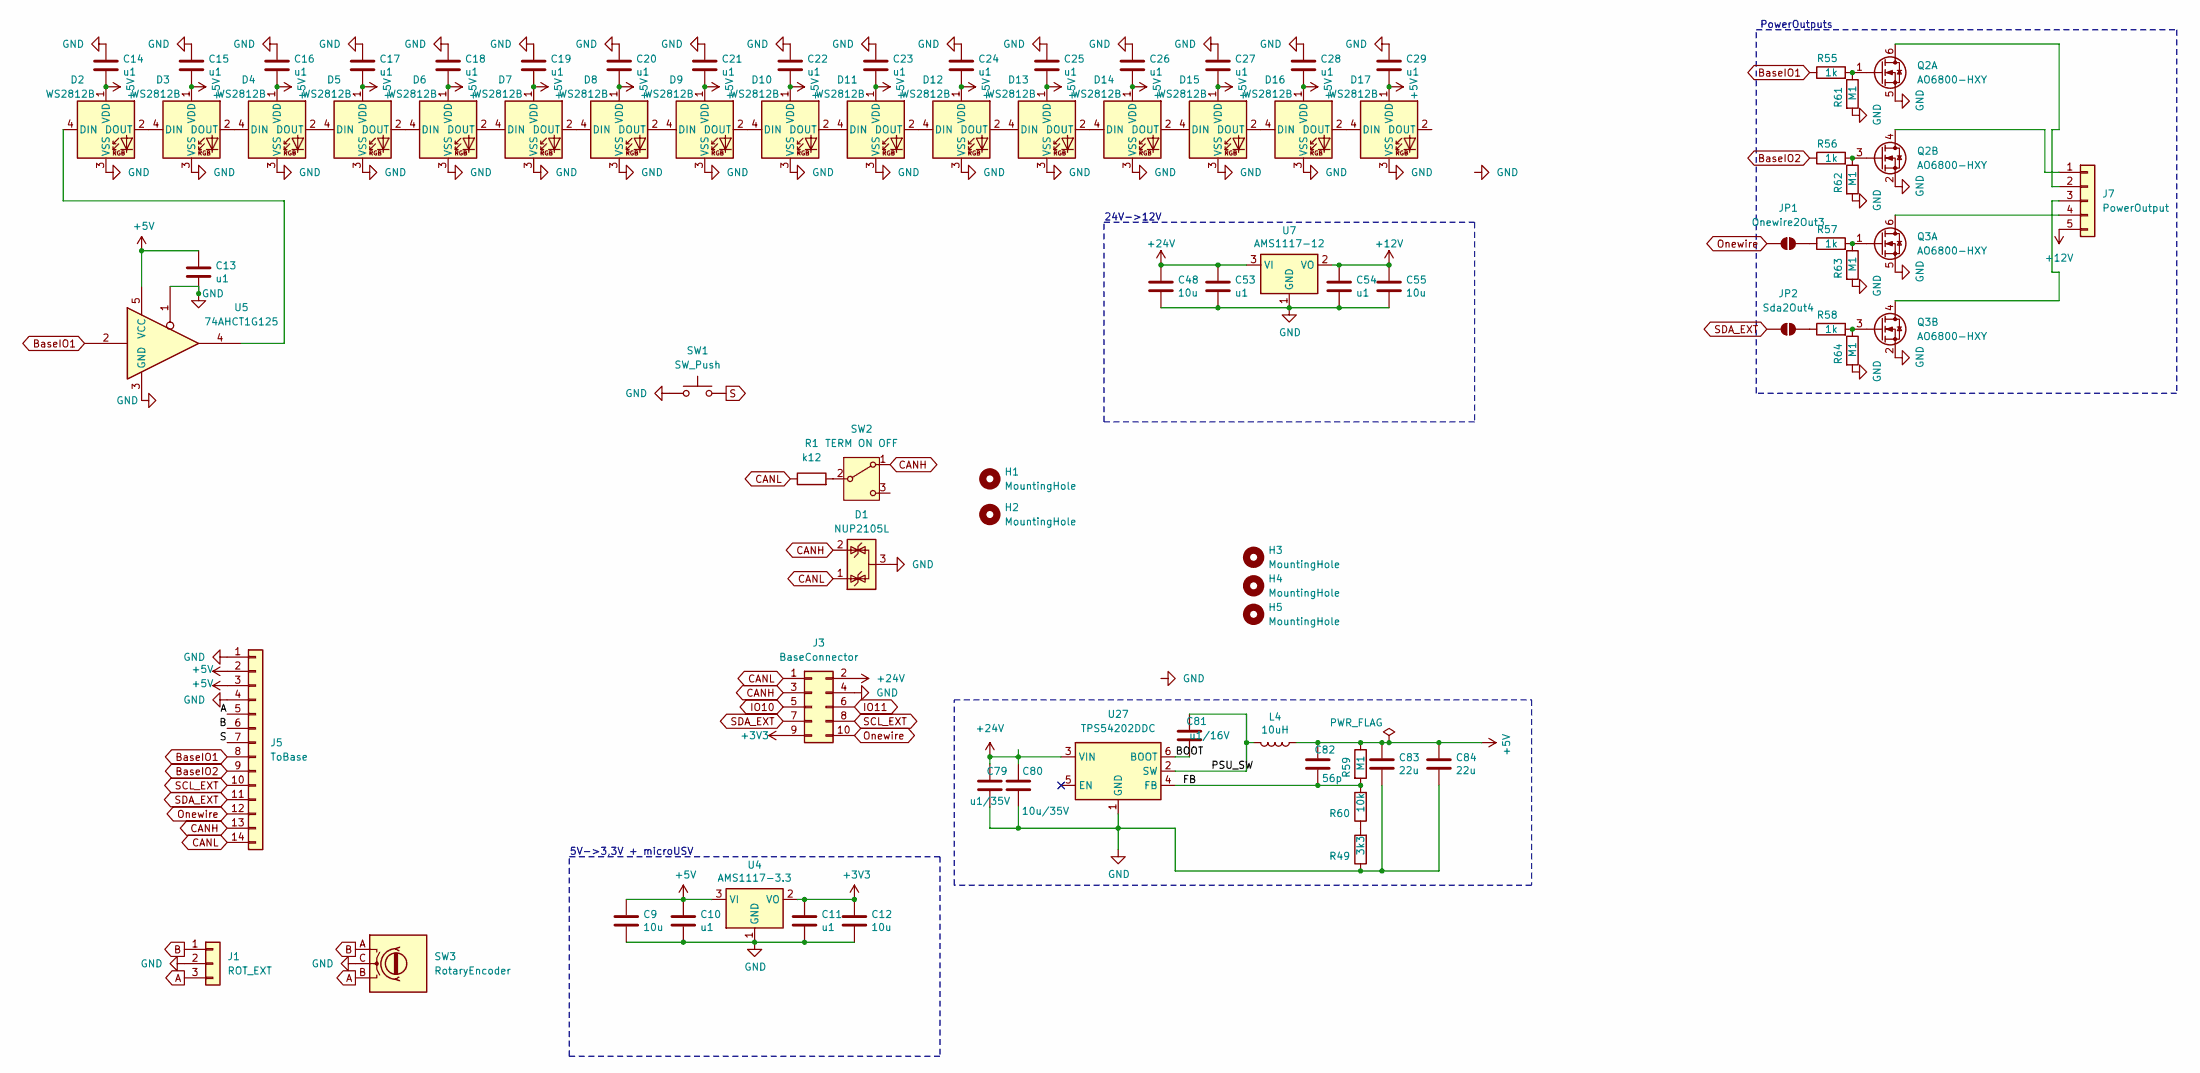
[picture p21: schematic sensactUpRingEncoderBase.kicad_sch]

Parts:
C9, C12, C48, C55: 10u; C_0805_2012Metric_Pad1.18x1.45mm_HandSolder
C10, C11, C13, C14, C15, C16, C17, C18, C19, C20, C21, C22, C23, C24, C25, C26, C27, C28, C29, C53, C54: u1; C_0805_2012Metric_Pad1.18x1.45mm_HandSolder
C79: u1/35V; R_0805_2012Metric_Pad1.20x1.40mm_HandSolder; MPN CC0603KRX7R9BB104
C80: 10u/35V; C_1206_3216Metric_Pad1.33x1.80mm_HandSolder; MPN CGA0805X5R106K350MT
C81: u1/16V; R_0805_2012Metric_Pad1.20x1.40mm_HandSolder; MPN CC0603KRX7R9BB104
C82: 56p; R_0805_2012Metric_Pad1.20x1.40mm_HandSolder; MPN CC0402JRNPO9BN560
C83, C84: 22u; R_0805_2012Metric_Pad1.20x1.40mm_HandSolder; MPN CL10A226MP8NUNE
D1: NUP2105L; SOT-23_Handsoldering
D2, D3, D4, D5, D6, D7, D8, D9, D10, D11, D12, D13, D14, D15, D16, D17: WS2812B; LED_WS2812B-Mini_PLCC4_3.5x3.5mm
H1, H2: MountingHole; MountingHole_5mm
H3, H4, H5: MountingHole; MountingHole_2.2mm_M2
J1: ROT_EXT; PhoenixContact_MCV_1,5_3-G-3.5_1x03_P3.50mm_Vertical_smalle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
J3: BaseConnector; IDC-Header_2x05_P2.54mm_Vertical
J5: ToBase; Hirose_FH12-14S-0.5SH_1x14-1MP_P0.50mm_Horizontal_handsolder
J7: PowerOutput; PinHeader_1x05_P2.54mm_Vertical
JP1: Onewire2Out3; SolderJumper-2_P1.3mm_Open_RoundedPad1.0x1.5mm
JP2: Sda2Out4; SolderJumper-2_P1.3mm_Open_RoundedPad1.0x1.5mm
L4: 10uH; L_0630; MPN FXL0630-100-M
Q2, Q3: AO6800-HXY; SOT-23-6_Handsoldering
R1: k12; R_0805_2012Metric_Pad1.20x1.40mm_HandSolder
R49: 3k3; R_0805_2012Metric_Pad1.20x1.40mm_HandSolder; MPN 0402WGF3301TCE
R55, R56, R57, R58: 1k; R_0805_2012Metric_Pad1.20x1.40mm_HandSolder
R59, R61, R62, R63, R64: M1; R_0805_2012Metric_Pad1.20x1.40mm_HandSolder; MPN 0201WMF1003TEE
R60: 10k; R_0805_2012Metric_Pad1.20x1.40mm_HandSolder; MPN 0201WMF1002TEE
SW1: SW_Push; Button_12mm_ANCHOR_CENTER
SW2: TERM ON OFF; SW_SPDT_PCM12_handsolder
SW3: RotaryEncoder; Encoder Alps-Alpine EC35
U4: AMS1117-3.3; SOT-223-3_TabPin2_HANDSOLDER
U5: 74AHCT1G125; SOT-353_SC-70-5_Handsoldering
U7: AMS1117-12; SOT-223-3_TabPin2_HANDSOLDER
U27: TPS54202DDC; SOT-23-6_Handsoldering; MPN TPS54202DDCR

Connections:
+3V3: C11.1, C12.1, J3.9, U4.2 (VO)
+5V: C9.1, C10.1, C13.1, C14.2, C15.2, C16.2, C17.2, C18.2, C19.2, C20.2, C21.2, C22.2, C23.2, C24.2, C25.2, C26.2, C27.2, C28.2, C29.2, C82.2, C83.1, C84.1, D2.1 (VDD), D3.1 (VDD), D4.1 (VDD), D5.1 (VDD), D6.1 (VDD), D7.1 (VDD), D8.1 (VDD), D9.1 (VDD), D10.1 (VDD), D11.1 (VDD), D12.1 (VDD), D13.1 (VDD), D14.1 (VDD), D15.1 (VDD), D16.1 (VDD), D17.1 (VDD), J5.2, J5.3, L4.1, R59.1, U4.3 (VI), U5.5 (VCC)
+12V: C54.1, C55.1, J7.5, U7.2 (VO)
+24V: C48.1, C53.1, C79.2, C80.2, J3.2, U7.3 (VI), U27.3 (VIN)
/BOOT: C81.1, U27.6 (BOOT)
/FB: C82.1, R59.2, R60.2, U27.4 (FB)
/PSU_SW: C81.2, L4.2, U27.2 (SW)
A: J1.3, J5.5, SW3.B
B: J1.1, J5.6, SW3.A
BaseIO1: J5.8, R55.1, U5.2
BaseIO2: J5.9, R56.1
CANH: D1.2 (K), J3.3, J5.13, SW2.1 (A)
CANL: D1.1 (K), J3.1, J5.14, R1.1
GND: C9.2, C10.2, C11.2, C12.2, C13.2, C14.1, C15.1, C16.1, C17.1, C18.1, C19.1, C20.1, C21.1, C22.1, C23.1, C24.1, C25.1, C26.1, C27.1, C28.1, C29.1, C48.2, C53.2, C54.2, C55.2, C79.1, C80.1, C83.2, C84.2, D1.3 (A), D2.3 (VSS), D3.3 (VSS), D4.3 (VSS), D5.3 (VSS), D6.3 (VSS), D7.3 (VSS), D8.3 (VSS), D9.3 (VSS), D10.3 (VSS), D11.3 (VSS), D12.3 (VSS), D13.3 (VSS), D14.3 (VSS), D15.3 (VSS), D16.3 (VSS), D17.3 (VSS), J1.2, J3.4, J5.1, J5.4, Q2.2 (S), Q2.5 (S), Q3.2 (S), Q3.5 (S), R49.1, R61.2, R62.2, R63.2, R64.2, SW1.1, SW3.C, U4.1 (GND), U5.1, U5.3 (GND), U7.1 (GND), U27.1 (GND)
IO10: J3.5
IO11: J3.6
unnamed: D2.4 (DIN), U5.4
unnamed: D2.2 (DOUT), D3.4 (DIN)
unnamed: D3.2 (DOUT), D4.4 (DIN)
unnamed: D4.2 (DOUT), D5.4 (DIN)
unnamed: D5.2 (DOUT), D6.4 (DIN)
unnamed: D6.2 (DOUT), D7.4 (DIN)
unnamed: D7.2 (DOUT), D8.4 (DIN)
unnamed: D8.2 (DOUT), D9.4 (DIN)
unnamed: D9.2 (DOUT), D10.4 (DIN)
unnamed: D10.2 (DOUT), D11.4 (DIN)
unnamed: D11.2 (DOUT), D12.4 (DIN)
unnamed: D12.2 (DOUT), D13.4 (DIN)
unnamed: D13.2 (DOUT), D14.4 (DIN)
unnamed: D14.2 (DOUT), D15.4 (DIN)
unnamed: D15.2 (DOUT), D16.4 (DIN)
unnamed: D16.2 (DOUT), D17.4 (DIN)
unnamed: J7.1, Q2.4 (D)
unnamed: J7.2, Q2.6 (D)
unnamed: J7.3, Q3.4 (D)
unnamed: J7.4, Q3.6 (D)
unnamed: JP1.2 (B), R57.1
unnamed: JP2.2 (B), R58.1
unnamed: Q2.1 (G), R55.2, R61.1
unnamed: Q2.3 (G), R56.2, R62.1
unnamed: Q3.1 (G), R57.2, R63.1
unnamed: Q3.3 (G), R58.2, R64.1
unnamed: R49.2, R60.1
unnamed: R1.2, SW2.2 (B)
Onewire: J3.10, J5.12, JP1.1 (A)
S: J5.7, SW1.2
SCL_EXT: J3.8, J5.10
SDA_EXT: J3.7, J5.11, JP2.1 (A)

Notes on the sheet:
PowerOutputs
5V->3,3V + microUSV
24V->12V

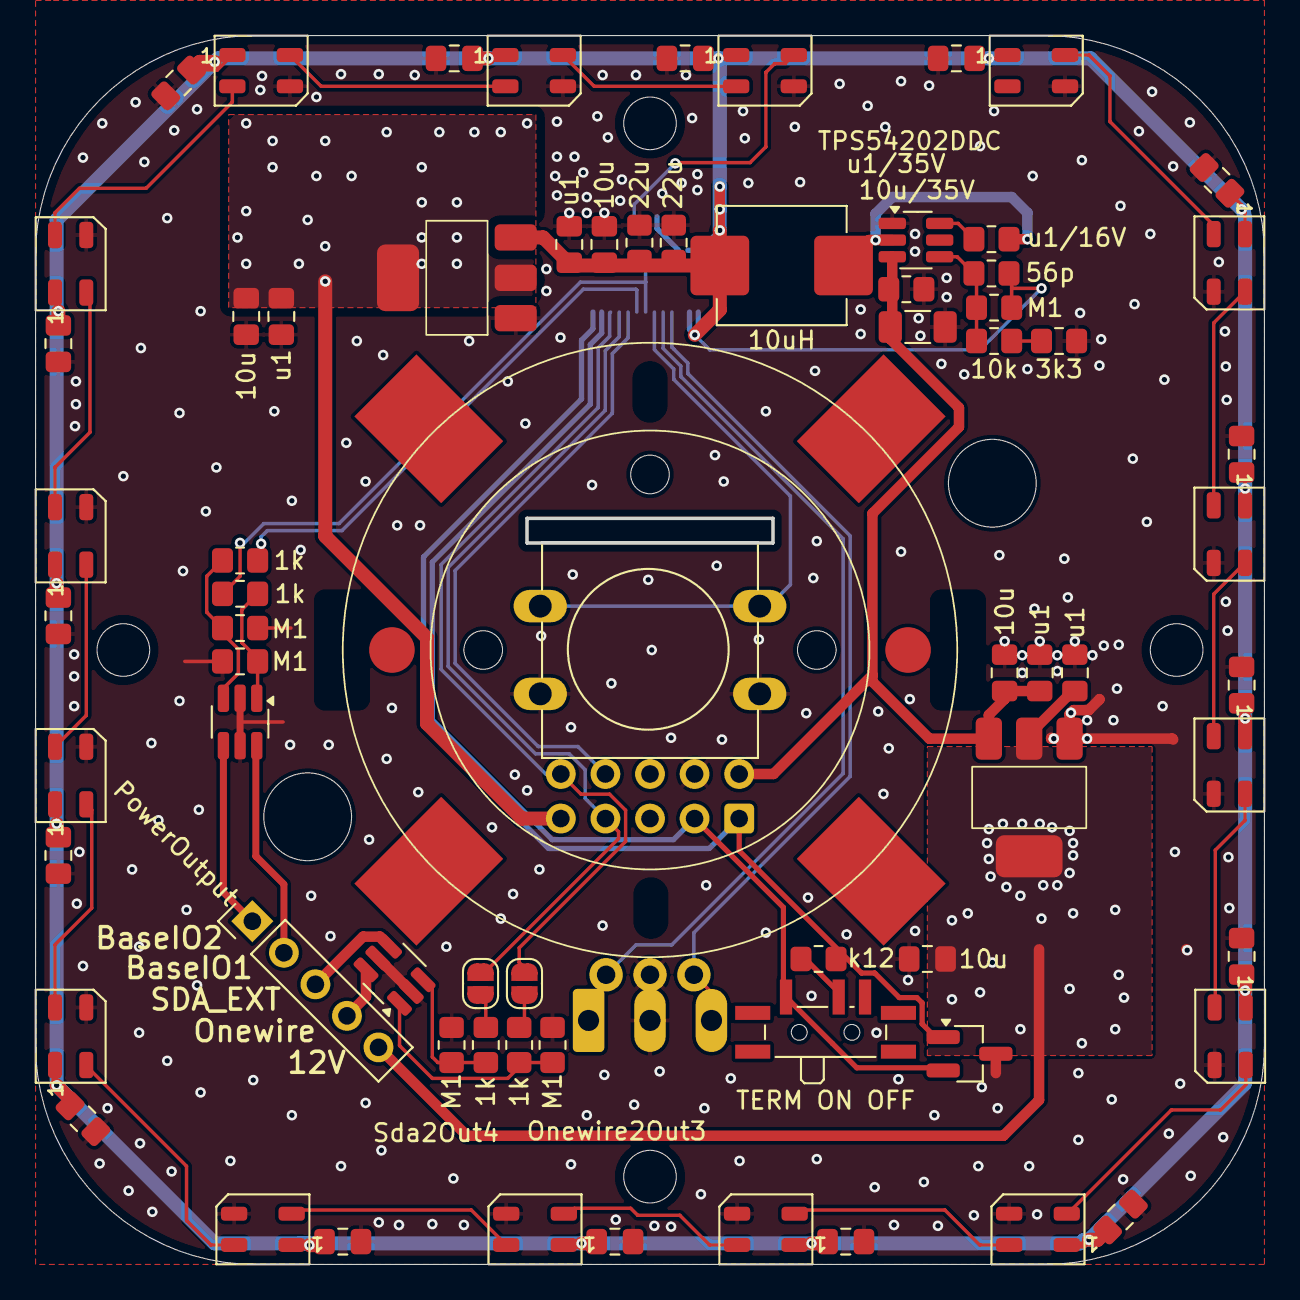
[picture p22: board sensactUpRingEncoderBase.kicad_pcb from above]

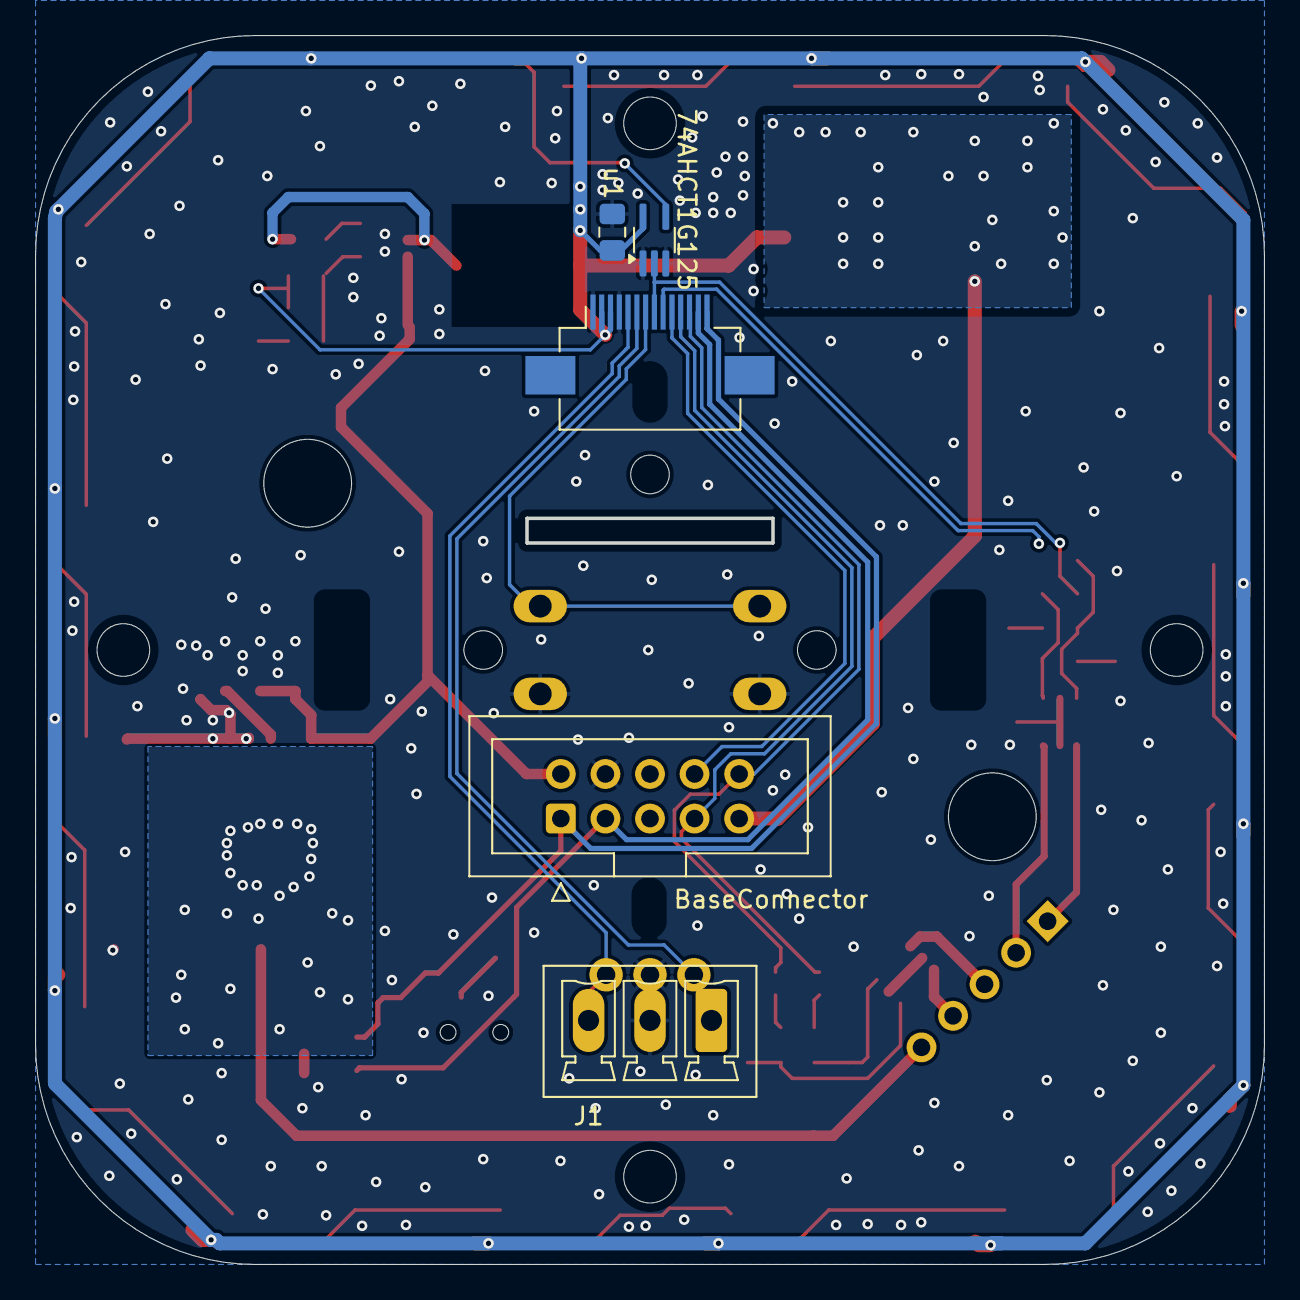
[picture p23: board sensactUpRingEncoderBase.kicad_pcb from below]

Board: 2 copper layers, 70.0 x 70.0 mm, 81 parts (5 on the bottom side), 46 nets.

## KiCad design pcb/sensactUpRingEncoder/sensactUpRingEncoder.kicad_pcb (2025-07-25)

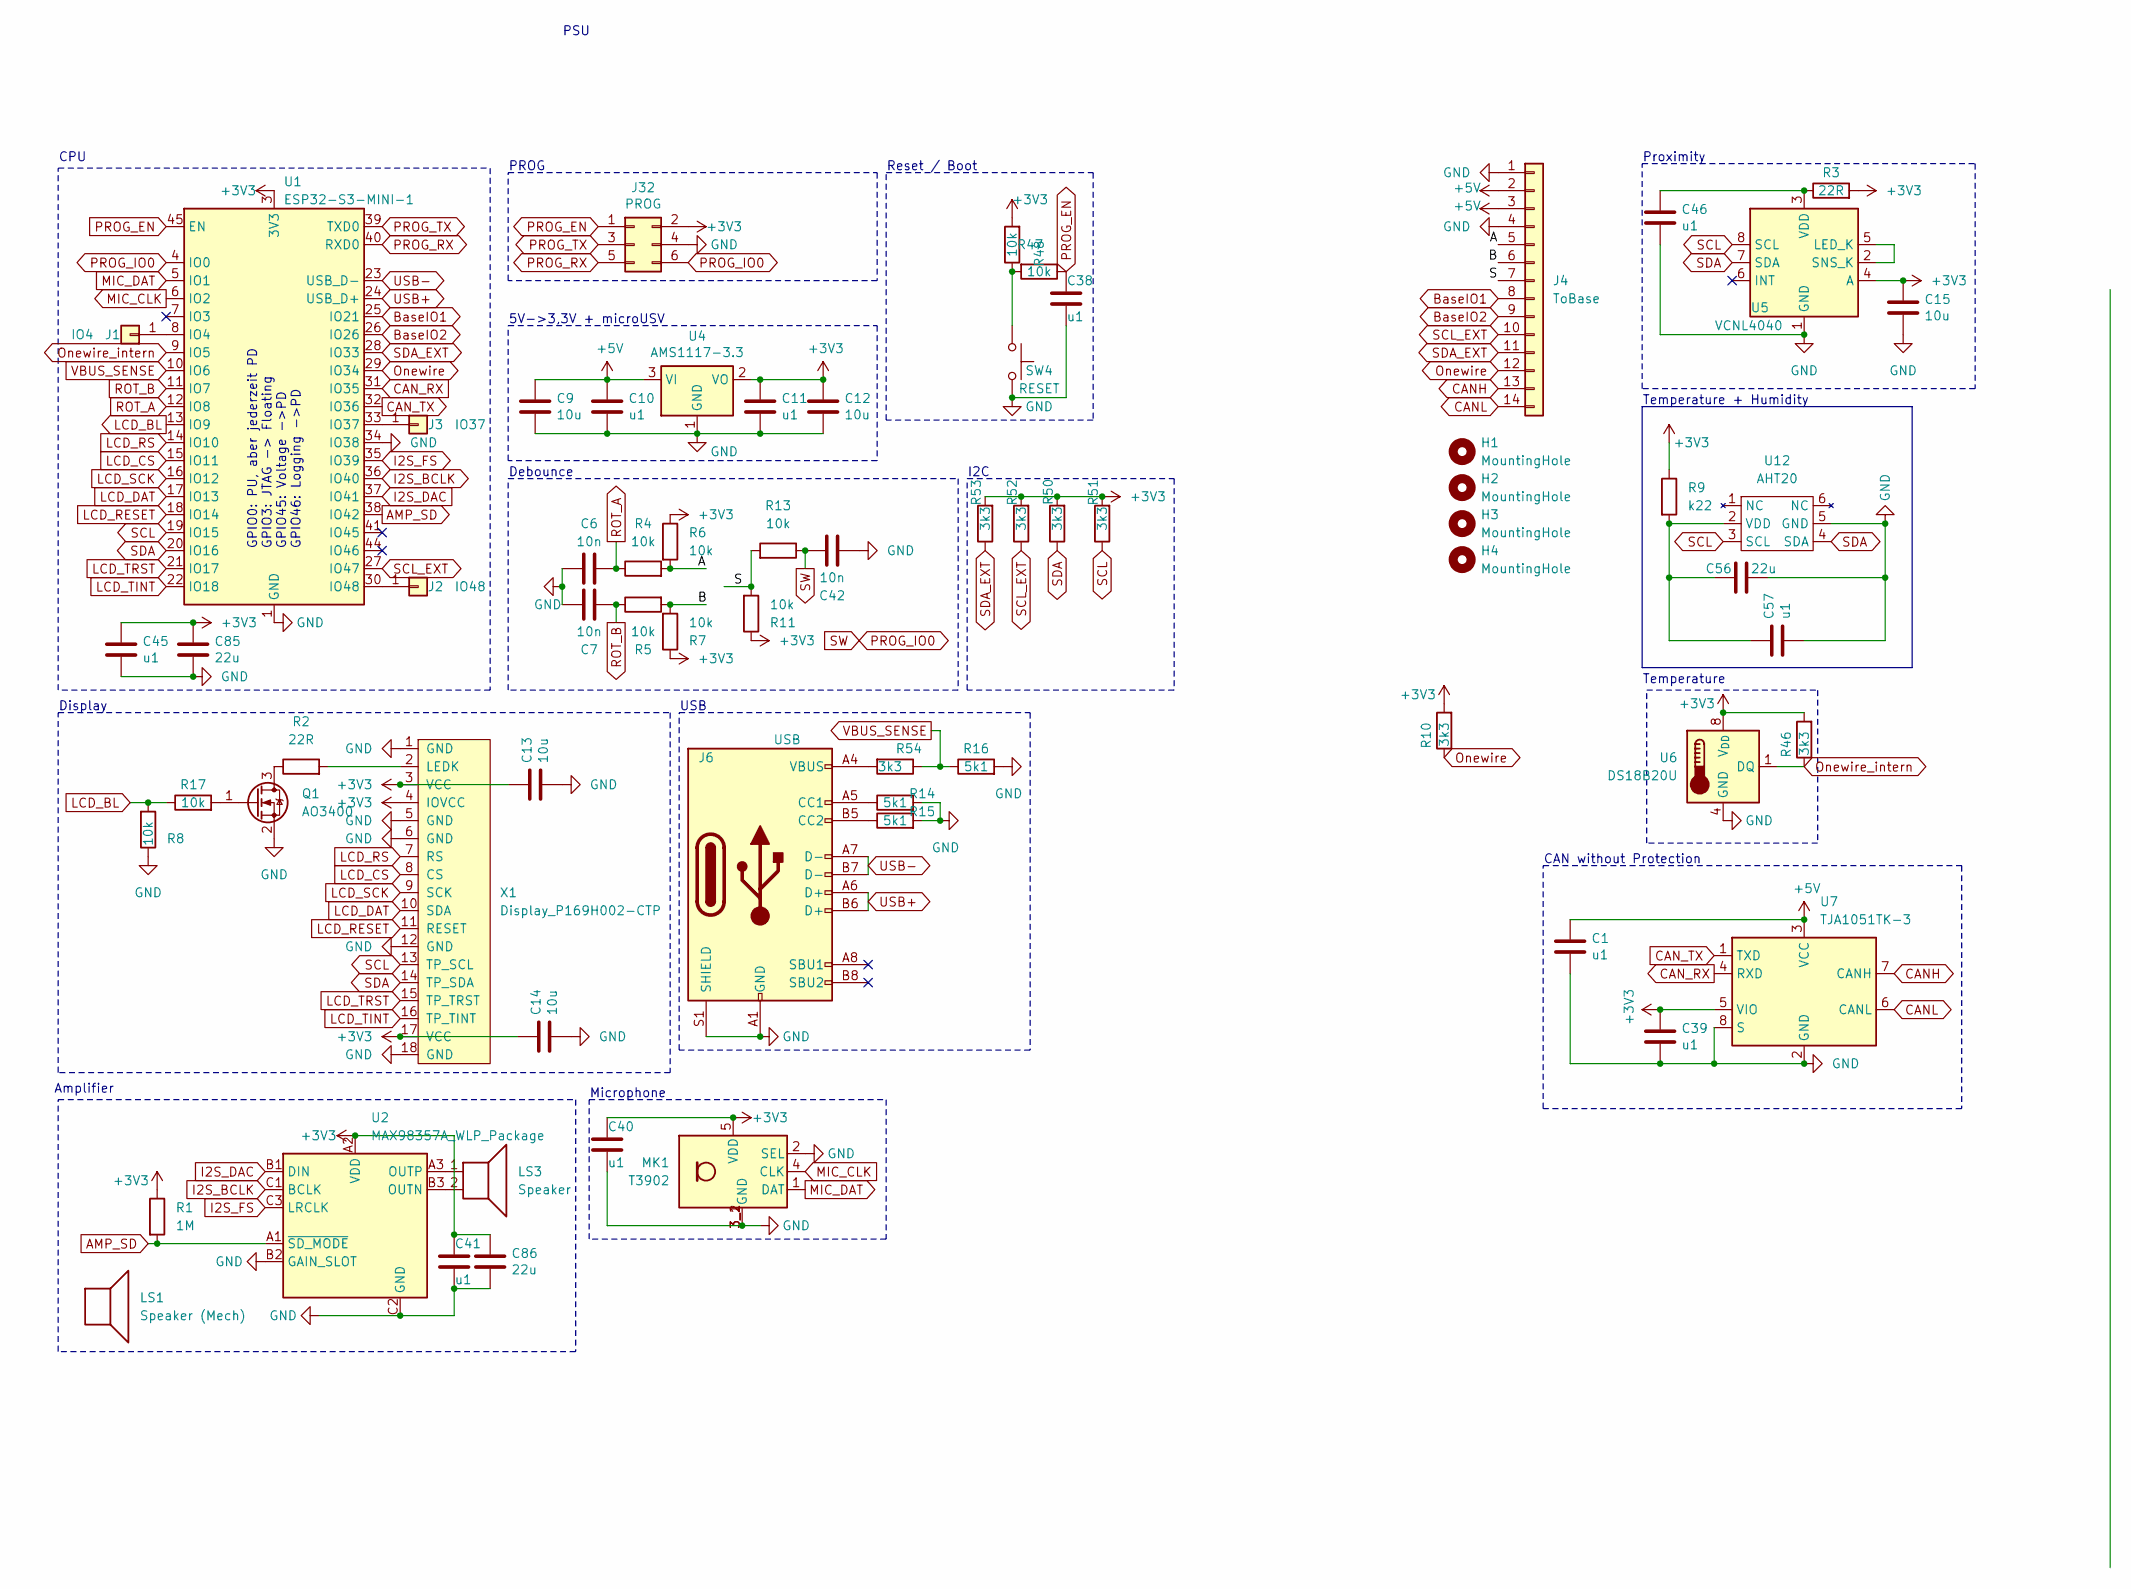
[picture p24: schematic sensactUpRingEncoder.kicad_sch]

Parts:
C1, C10, C11, C38, C39, C40, C41, C45, C46: u1; C_0201_0603Metric
C6, C7, C42: 10n; C_0201_0603Metric
C9, C12, C13, C14, C15: 10u; C_0402_1005Metric
C56, C85, C86: 22u; C_0603_1608Metric; MPN CL10A226MP8NUNE
C57: u1; C_0201_0603Metric; MPN GRM033R61A104KE15D
H1, H2, H3, H4: MountingHole; MountingHole_2.2mm_M2_DIN965
J1: IO4; TestPoint_THTPad_D1.0mm_Drill0.5mm
J2: IO48; TestPoint_THTPad_D1.5mm_Drill0.7mm
J3: IO37; TestPoint_THTPad_D1.5mm_Drill0.7mm
J4: ToBase; Hirose_FH12-14S-0.5SH_1x14-1MP_P0.50mm_Horizontal
J6: USB; USB_C_Receptacle_HRO_TYPE-C-31-M-12
J32: PROG; PinHeader_2x03_P1.27mm_Vertical_SMD
LS1: Speaker (Mech); SPEAKER_2415
LS3: Speaker; PinHeader_1x02_P1.27mm_Vertical
MK1: T3902; MIC_T3902
Q1: AO3400; SOT-23_smaller
R1: 1M; R_0805_2012Metric_Pad1.20x1.40mm_HandSolder
R2, R3: 22R; R_0805_2012Metric
R4, R5, R6, R7, R8, R11, R13, R17, R47, R48: 10k; R_0201_0603Metric
R9: k22; R_0805_2012Metric_Pad1.20x1.40mm_HandSolder; MPN 0402WGF2200TCE
R10, R46: 3k3; R_0402_1005Metric
R14, R15, R16: 5k1; R_0402_1005Metric
R50, R51, R52, R53, R54: 3k3; R_0402_1005Metric; MPN 0402WGF3301TCE
SW4: RESET; SW_Push_SPST_NO_4x3x2_handsolder
U1: ESP32-S3-MINI-1
U2: MAX98357A_WLP_Package; Maxim_WLP-9_1.595x1.415_Layout3x3_P0.4mm_Ball0.27mm_Pad0.25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
U4: AMS1117-3.3; SOT-223-3_TabPin2
U5: VCNL4040; VCNL4040_handsolder
U6: DS18B20U; MSOP-8_3x3mm_P0.65mm_handsolder
U7: TJA1051TK-3; HVSON-8-1EP_3x3mm_P0.65mm_EP1.6x2.4mm
U12: AHT20; AHT21; MPN AHT20
X1: Display_P169H002-CTP

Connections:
+3V3: C11.1, C12.1, C13.1, C14.1, C15.1, C39.1, C40.1, C41.1, C45.1, C85.1, C86.1, J32.2, MK1.5 (VDD), R1.1, R3.2, R6.1, R7.1, R9.1, R10.2, R11.1, R46.2, R47.2, R50.2, R51.2, R52.2, R53.2, U1.3 (3V3), U2.A2 (VDD), U4.2 (VO), U5.4 (A), U6.8 (V_{DD}), U7.5 (VIO), X1.3 (VCC), X1.4 (IOVCC), X1.17 (VCC)
+5V: C1.1, C9.1, C10.1, J4.2, J4.3, U4.3 (VI), U7.3 (VCC)
/A: J4.5, R4.2, R6.2
/B: J4.6, R5.2, R7.2
/S: J4.7, R11.2, R13.2
AMP_SD: R1.2, U1.38 (IO42), U2.A1 (~SD_MODE)
BaseIO1: J4.8, U1.25 (IO21)
BaseIO2: J4.9, U1.26 (IO26)
CANH: J4.13, U7.7 (CANH)
CANL: J4.14, U7.6 (CANL)
CAN_RX: U1.31 (IO35), U7.4 (RXD)
CAN_TX: U1.32 (IO36), U7.1 (TXD)
GND: C1.2, C6.1, C7.1, C9.2, C10.2, C11.2, C12.2, C13.2, C14.2, C15.2, C38.2, C39.2, C40.2, C41.2, C42.2, C45.2, C46.2, C56.2, C57.1, C85.2, C86.2, J4.1, J4.4, J6.A1 (GND), J6.A12 (GND), J6.B1 (GND), J6.B12 (GND), J6.S1 (SHIELD), J32.4, MK1.2 (SEL), MK1.3_1 (GND), MK1.3_2 (GND), Q1.2 (S), R8.1, R14.2, R15.2, R16.2, SW4.2, U1.1 (GND), U1.2 (GND), U1.34 (IO38), U1.42 (GND), U1.43 (GND), U1.46 (GND), U1.47 (GND), U1.48 (GND), U1.49 (GND), U1.50 (GND), U1.51 (GND), U1.52 (GND), U1.53 (GND), U1.54 (GND), U1.55 (GND), U1.56 (GND), U1.57 (GND), U1.58 (GND), U1.59 (GND), U1.60 (GND), U1.61 (GND), U1.62 (GND), U1.63 (GND), U1.64 (GND), U1.65 (GND), U2.B2 (GAIN_SLOT), U2.C2 (GND), U4.1 (GND), U5.1 (GND), U6.4 (GND), U7.2 (GND), U7.8 (S), U7.9 (GND), U12.5 (GND), X1.1 (GND), X1.5 (GND), X1.6 (GND), X1.12 (GND), X1.18 (GND)
I2S_BCLK: U1.36 (IO40), U2.C1 (BCLK)
I2S_DAC: U1.37 (IO41), U2.B1 (DIN)
I2S_FS: U1.35 (IO39), U2.C3 (LRCLK)
LCD_BL: R8.2, R17.1, U1.13 (IO9)
LCD_CS: U1.15 (IO11), X1.8 (CS)
LCD_DAT: U1.17 (IO13), X1.10 (SDA)
LCD_RESET: U1.18 (IO14), X1.11 (RESET)
LCD_RS: U1.14 (IO10), X1.7 (RS)
LCD_SCK: U1.16 (IO12), X1.9 (SCK)
LCD_TINT: U1.22 (IO18), X1.16 (TP_TINT)
LCD_TRST: U1.21 (IO17), X1.15 (TP_TRST)
MIC_CLK: MK1.4 (CLK), U1.6 (IO2)
MIC_DAT: MK1.1 (DAT), U1.5 (IO1)
unnamed: J1.1, U1.8 (IO4)
unnamed: J2.1, U1.30 (IO48)
unnamed: J3.1, U1.33 (IO37)
unnamed: J6.A5 (CC1), R14.1
unnamed: J6.B5 (CC2), R15.1
unnamed: J6.A4 (VBUS), J6.A9 (VBUS), J6.B4 (VBUS), J6.B9 (VBUS), R54.2
unnamed: Q1.3 (D), R2.1
unnamed: Q1.1 (G), R17.2
unnamed: R47.1, R48.2, SW4.1
unnamed: LS3.2, U2.B3 (OUTN)
unnamed: LS3.1, U2.A3 (OUTP)
unnamed: U5.2 (SNS_K), U5.5 (LED_K)
unnamed: C46.1, R3.1, U5.3 (VDD)
unnamed: C56.1, C57.2, R9.2, U12.2 (VDD)
unnamed: R2.2, X1.2 (LEDK)
Onewire: J4.12, R10.1, U1.29 (IO34)
Onewire_intern: R46.1, U1.9 (IO5), U6.1 (DQ)
PROG_EN: C38.1, J32.1, R48.1, U1.45 (EN)
PROG_IO0: C42.1, J32.6, R13.1, U1.4 (IO0)
PROG_RX: J32.5, U1.40 (RXD0)
PROG_TX: J32.3, U1.39 (TXD0)
ROT_A: C6.2, R4.1, U1.12 (IO8)
ROT_B: C7.2, R5.1, U1.11 (IO7)
SCL: R51.1, U1.19 (IO15), U5.8 (SCL), U12.3 (SCL), X1.13 (TP_SCL)
SCL_EXT: J4.10, R52.1, U1.27 (IO47)
SDA: R50.1, U1.20 (IO16), U5.7 (SDA), U12.4 (SDA), X1.14 (TP_SDA)
SDA_EXT: J4.11, R53.1, U1.28 (IO33)
USB+: J6.A6 (D+), J6.B6 (D+), U1.24 (USB_D+)
USB-: J6.A7 (D-), J6.B7 (D-), U1.23 (USB_D-)
VBUS_SENSE: R16.1, R54.1, U1.10 (IO6)

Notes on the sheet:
CAN without Protection
Temperature
Proximity
Reset / Boot
Temperature + Humidity
Amplifier
USB
5V->3,3V + microUSV
Debounce
Display
CPU
PSU
I2C
GPIO0: PU, aber jederzeit PD GPIO3: JTAG -> Floating GPIO45: Voltage ->PD GPIO46: Logging ->PD
Microphone
PROG

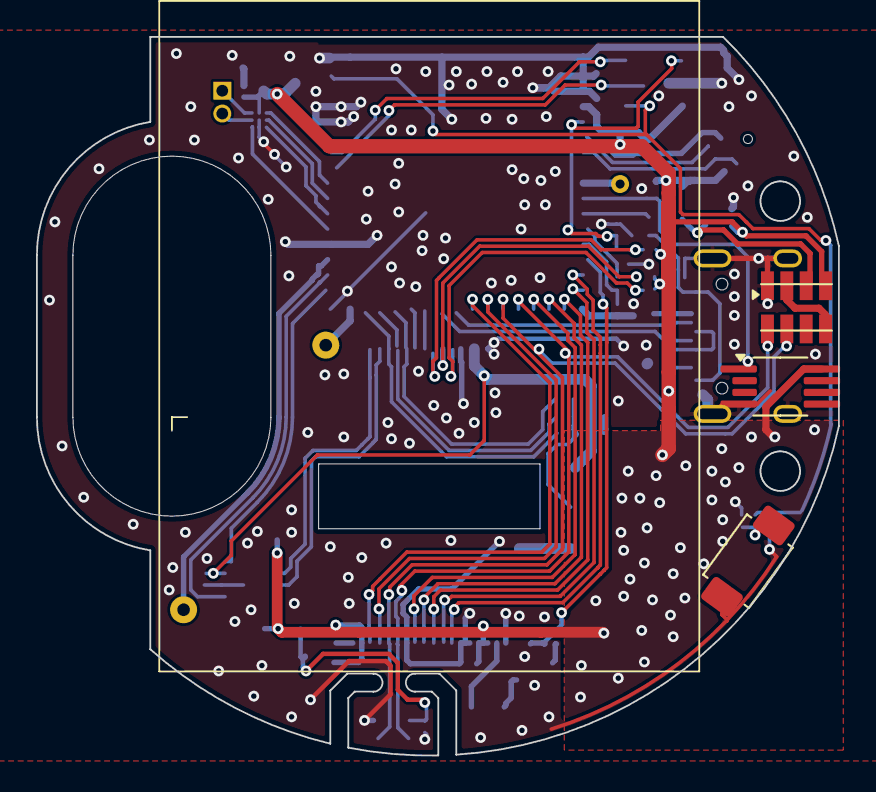
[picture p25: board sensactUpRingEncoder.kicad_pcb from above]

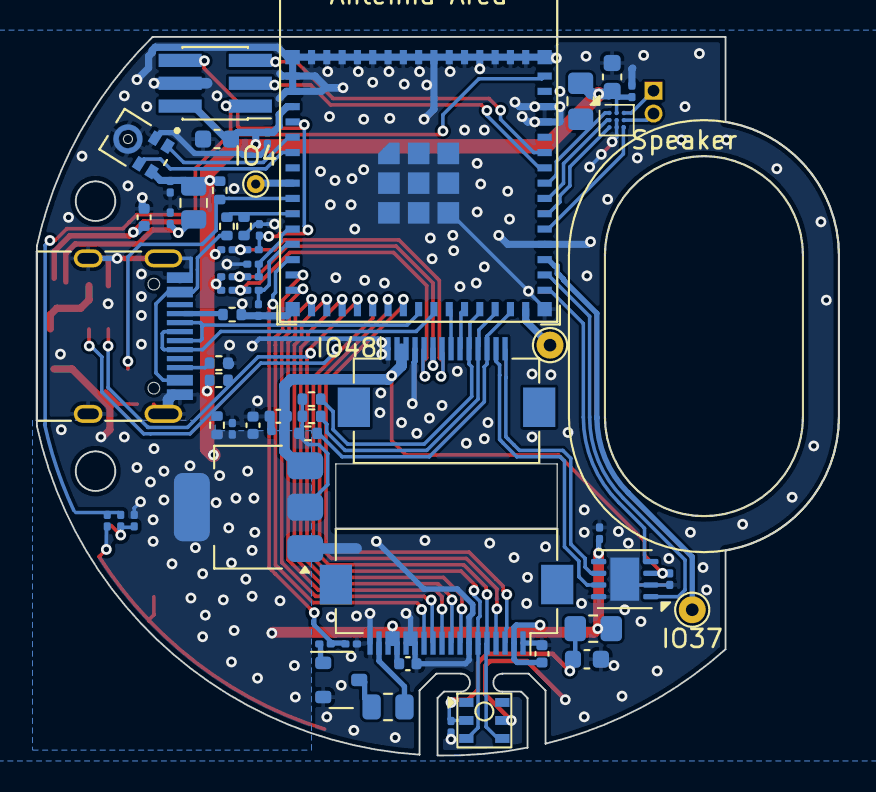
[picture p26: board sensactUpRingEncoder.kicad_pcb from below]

Board: 2 copper layers, 44.6 x 39.9 mm, 68 parts (61 on the bottom side), 56 nets.

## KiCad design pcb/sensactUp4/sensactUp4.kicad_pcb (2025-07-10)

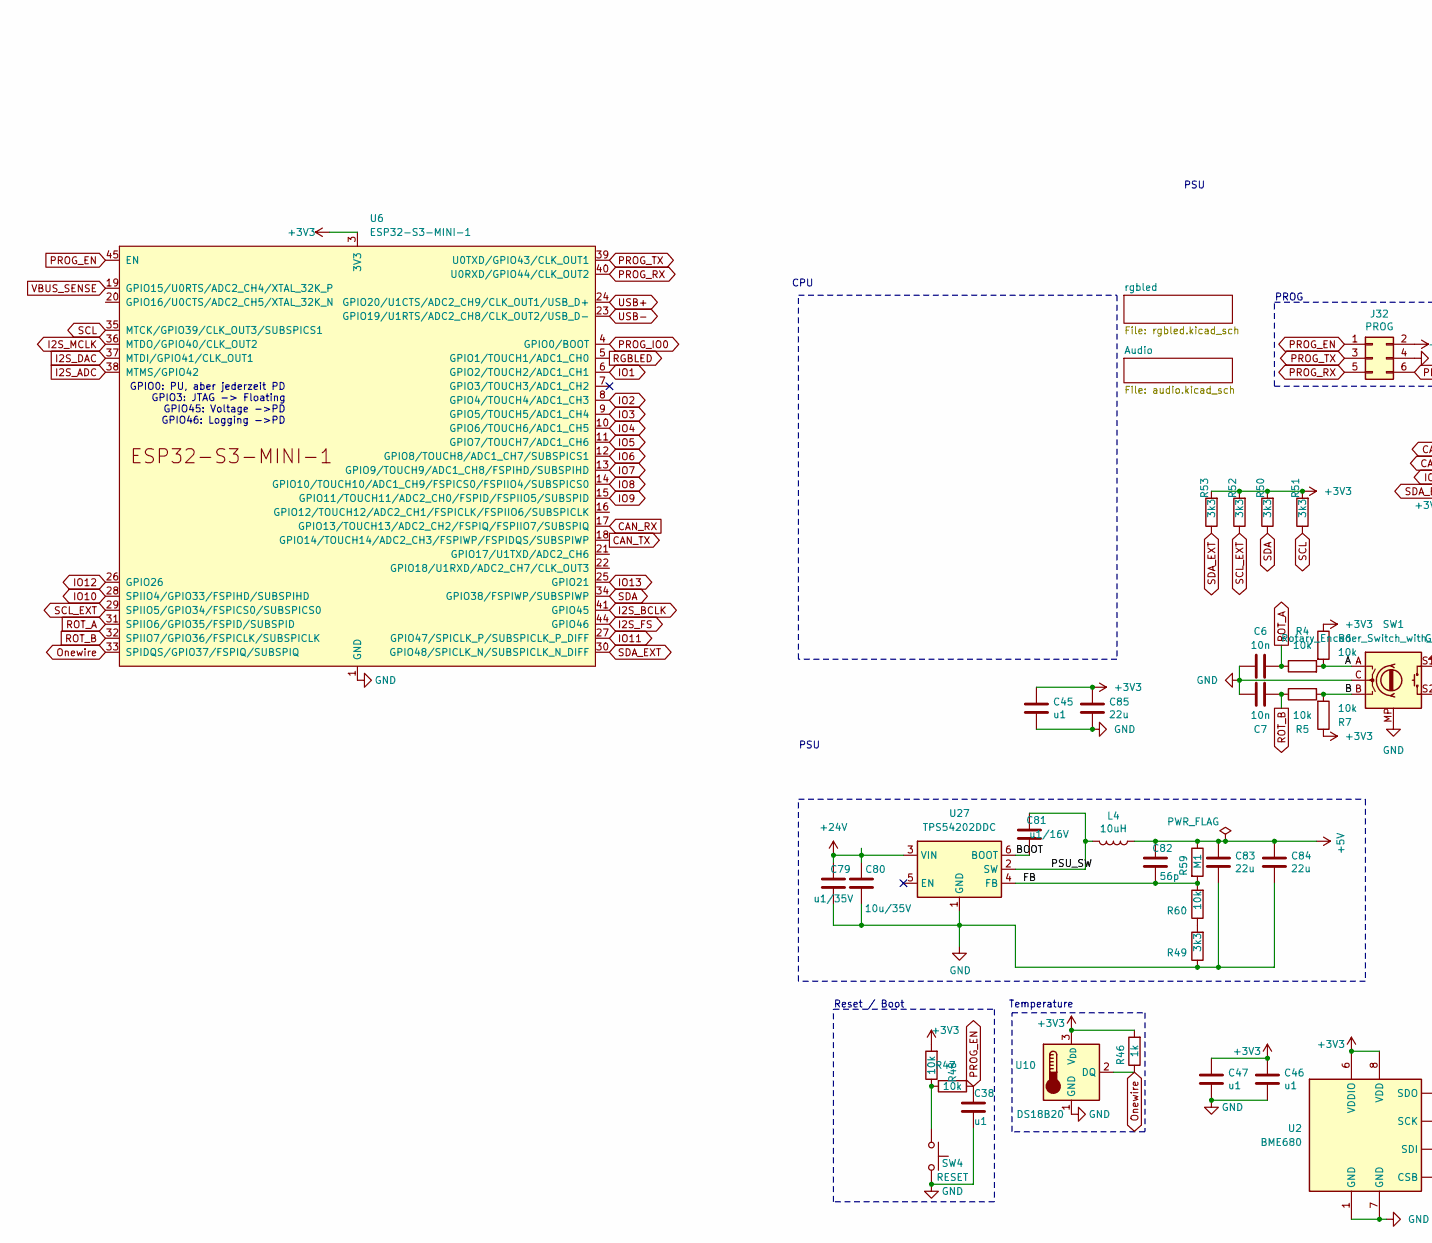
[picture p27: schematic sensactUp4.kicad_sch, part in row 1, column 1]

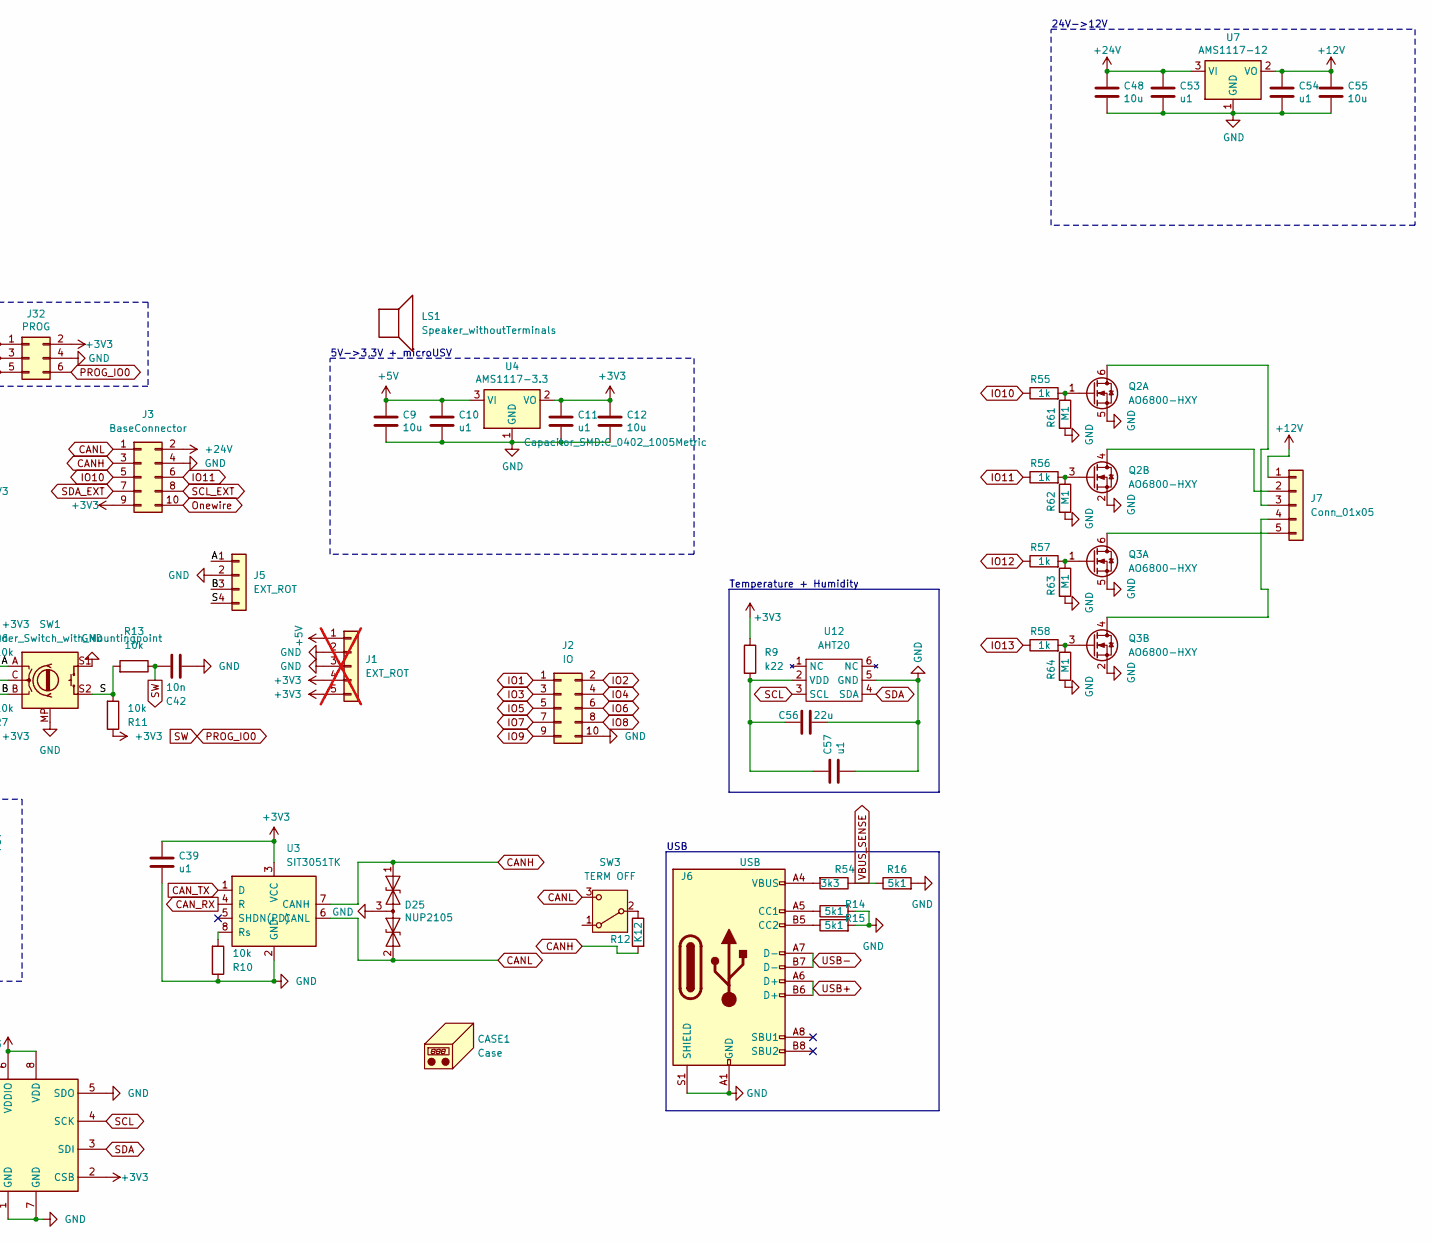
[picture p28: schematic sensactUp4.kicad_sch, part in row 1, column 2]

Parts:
C6, C7, C42: 10n; C_0201_0603Metric
C9, C12: 10u; C_0402_1005Metric
C10, C11, C38, C39, C45, C46, C47: u1; C_0201_0603Metric
C48, C55: 10u; C_0805_2012Metric_Pad1.18x1.45mm_HandSolder
C53, C54: u1; C_0805_2012Metric_Pad1.18x1.45mm_HandSolder
C56, C83, C84, C85: 22u; C_0603_1608Metric; MPN CL10A226MP8NUNE
C57: u1; C_0201_0603Metric; MPN GRM033R61A104KE15D
C79: u1/35V; C_0603_1608Metric; MPN CC0603KRX7R9BB104
C80: 10u/35V; C_0805_2012Metric; MPN CGA0805X5R106K350MT
C81: u1/16V; C_0201_0603Metric; MPN CC0603KRX7R9BB104
C82: 56p; C_0201_0603Metric; MPN CC0402JRNPO9BN560
CASE1: Case; KiCad-Logo_5mm_SilkScreen
D25: NUP2105; SOT-23_Handsoldering; MPN NUP2105L
J1: EXT_ROT; PinHeader_1x05_P2.54mm_Vertical; not fitted
J2: IO; PinHeader_2x05_P2.54mm_Vertical
J3: BaseConnector; IDC-Header_2x05_P2.54mm_Vertical
J5: EXT_ROT; PhoenixContact_MCV_1,5_4-G-3.5_1x04_P3.50mm_Vertical
J6: USB; GT-USB-7051A
J7: Conn_01x05; PinHeader_1x05_P2.54mm_Vertical
J32: PROG; PinHeader_2x03_P2.54mm_Vertical
L4: 10uH; L_Abracon_ASPI-0630LR; MPN FXL0630-100-M
LS1: Speaker_withoutTerminals; SPEAKER_2415
Q2, Q3: AO6800-HXY; SOT-23-6
R4, R5, R6, R7, R10, R11, R13, R47, R48: 10k; R_0201_0603Metric
R9: k22; R_0402_1005Metric; MPN 0402WGF2200TCE
R12: K12; R_1206_3216Metric_Pad1.30x1.75mm_HandSolder; MPN 1206W4F1200T5E
R14, R15, R16: 5k1; R_0402_1005Metric
R46, R55, R56, R57, R58: 1k; R_0402_1005Metric
R49, R50, R51, R52, R53, R54: 3k3; R_0402_1005Metric; MPN 0402WGF3301TCE
R59, R61, R62, R63, R64: M1; R_0201_0603Metric; MPN 0201WMF1003TEE
R60: 10k; R_0201_0603Metric; MPN 0201WMF1002TEE
SW1: Rotary_Encoder_Switch_with_Mountingpoint; RotaryEncoder_Alps_EC11E-Switch_Vertical_H20mm
SW3: TERM OFF; Switch_SS12D00
SW4: RESET; SW_SPST_TL3342_smaller_handsolder
U2: BME680; Bosch_LGA-8_3x3mm_P0.8mm_ClockwisePinNumbering
U3: SIT3051TK; DFN-8-1EP_3x3mm_P0.65mm_EP1.55x2.4mm
U4: AMS1117-3.3; SOT-223-3_TabPin2
U6: ESP32-S3-MINI-1
U7: AMS1117-12; SOT-223-3_TabPin2_HANDSOLDER
U10: DS18B20; TO-92L_HandSolder
U12: AHT20; AHT21; MPN AHT20
U27: TPS54202DDC; SOT-23-6_Handsoldering; MPN TPS54202DDCR

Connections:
+3V3: C11.1, C12.1, C39.1, C45.1, C46.1, C47.1, C85.1, J1.4, J1.5, J3.9, J32.2, R6.1, R7.1, R9.1, R11.1, R46.2, R47.2, R50.2, R51.2, R52.2, R53.2, U2.2 (CSB), U2.6 (VDDIO), U2.8 (VDD), U3.3 (VCC), U4.2 (VO), U6.3 (3V3), U10.3 (V_{DD}); also elsewhere on the board
+5V: C9.1, C10.1, C82.2, C83.1, C84.1, J1.1, L4.1, R59.1, U4.3 (VI); also elsewhere on the board
+12V: C54.1, C55.1, J7.1, U7.2 (VO)
+24V: C48.1, C53.1, C79.2, C80.2, J3.2, U7.3 (VI), U27.3 (VIN)
/A: J5.1, R4.2, R6.2, SW1.A
/B: J5.3, R5.2, R7.2, SW1.B
/BOOT: C81.1, U27.6 (BOOT)
/FB: C82.1, R59.2, R60.2, U27.4 (FB)
/PSU_SW: C81.2, L4.2, U27.2 (SW)
/S: J5.4, R11.2, R13.2, SW1.S2
CANH: D25.1 (A1), J3.3, R12.2, U3.7 (CANH)
CANL: D25.2 (A2), J3.1, SW3.3 (C), U3.6 (CANL)
CAN_RX: U3.4 (R), U6.17 (GPIO13/TOUCH13/ADC2_CH2/FSPIQ/FSPIIO7/S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)
CAN_TX: U3.1 (D), U6.18 (GPIO14/TOUCH14/ADC2_CH3/FSPIWP/FSPIDQS/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)
GND: C6.1, C7.1, C9.2, C10.2, C11.2, C12.2, C38.2, C39.2, C42.2, C45.2, C46.2, C47.2, C48.2, C53.2, C54.2, C55.2, C56.2, C57.1, C79.1, C80.1, C83.2, C84.2, C85.2, D25.3 (common), J1.2, J1.3, J2.10, J3.4, J5.2, J6.A1 (GND), J6.A12 (GND), J6.B1 (GND), J6.B12 (GND), J6.S1 (SHIELD), J32.4, Q2.2 (S), Q2.5 (S), Q3.2 (S), Q3.5 (S), R10.1, R14.2, R15.2, R16.2, R49.1, R61.2, R62.2, R63.2, R64.2, SW1.C, SW1.MP, SW1.S1, SW4.2, U2.1 (GND), U2.5 (SDO), U2.7 (GND), U3.2 (GND), U3.9 (PAD), U4.1 (GND), U6.1 (GND), U6.2 (GND), U6.42 (GND), U6.43 (GND), U6.46 (GND), U6.47 (GND), U6.48 (GND), U6.49 (GND), U6.50 (GND), U6.51 (GND), U6.52 (GND), U6.53 (GND), U6.54 (GND), U6.55 (GND), U6.56 (GND), U6.57 (GND), U6.58 (GND), U6.59 (GND), U6.60 (GND), U6.61 (GND), U6.62 (GND), U6.63 (GND), U6.64 (GND), U6.65 (GND), U7.1 (GND), U10.1 (GND), U12.5 (GND), U27.1 (GND); also elsewhere on the board
I2S_ADC: U6.38 (MTMS/GPIO42); also elsewhere on the board
I2S_BCLK: U6.41 (GPIO45); also elsewhere on the board
I2S_DAC: U6.37 (MTDI/GPIO41/CLK_OUT1); also elsewhere on the board
I2S_FS: U6.44 (GPIO46); also elsewhere on the board
I2S_MCLK: U6.36 (MTDO/GPIO40/CLK_OUT2); also elsewhere on the board
IO1: J2.1, U6.6 (GPIO2/TOUCH2/ADC1_CH1)
IO2: J2.2, U6.8 (GPIO4/TOUCH4/ADC1_CH3)
IO3: J2.3, U6.9 (GPIO5/TOUCH5/ADC1_CH4)
IO4: J2.4, U6.10 (GPIO6/TOUCH6/ADC1_CH5)
IO5: J2.5, U6.11 (GPIO7/TOUCH7/ADC1_CH6)
IO6: J2.6, U6.12 (GPIO8/TOUCH8/ADC1_CH7/SUBSPICS1)
IO7: J2.7, U6.13 (GPIO9/TOUCH9/ADC1_CH8/FSPIHD/SUBSPIHD)
IO8: J2.8, U6.14 (GPIO10/TOUCH10/ADC1_CH9/FSPICS0/FSPIIO4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)
IO9: J2.9, U6.15 (GPIO11/TOUCH11/ADC2_CH0/FSPID/FSPIIO5/S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)
IO10: J3.5, R55.1, U6.28 (SPIIO4/GPIO33/FSPIHD/SUBSPIHD)
IO11: J3.6, R56.1, U6.27 (GPIO47/SPICLK_P/SUBSPICLK_P_DIFF)
IO12: R57.1, U6.26 (GPIO26)
IO13: R58.1, U6.25 (GPIO21)
unnamed: J6.A5 (CC1), R14.1
unnamed: J6.B5 (CC2), R15.1
unnamed: J6.A4 (VBUS), J6.A9 (VBUS), J6.B4 (VBUS), J6.B9 (VBUS), R54.2
unnamed: J7.2, Q2.4 (D)
unnamed: J7.3, Q2.6 (D)
unnamed: J7.4, Q3.4 (D)
unnamed: J7.5, Q3.6 (D)
unnamed: Q2.1 (G), R55.2, R61.1
unnamed: Q2.3 (G), R56.2, R62.1
unnamed: Q3.1 (G), R57.2, R63.1
unnamed: Q3.3 (G), R58.2, R64.1
unnamed: R47.1, R48.2, SW4.1
unnamed: R49.2, R60.1
unnamed: R12.1, SW3.2 (B)
unnamed: R10.2, U3.8 (Rs)
unnamed: C56.1, C57.2, R9.2, U12.2 (VDD)
Onewire: J3.10, R46.1, U6.33 (SPIDQS/GPIO37/FSPIQ/SUBSPIQ), U10.2 (DQ)
PROG_EN: C38.1, J32.1, R48.1, U6.45 (EN)
PROG_IO0: C42.1, J32.6, R13.1, U6.4 (GPIO0/BOOT)
PROG_RX: J32.5, U6.40 (U0RXD/GPIO44/CLK_OUT2)
PROG_TX: J32.3, U6.39 (U0TXD/GPIO43/CLK_OUT1)
RGBLED: U6.5 (GPIO1/TOUCH1/ADC1_CH0); also elsewhere on the board
ROT_A: C6.2, R4.1, U6.31 (SPIIO6/GPIO35/FSPID/SUBSPID)
ROT_B: C7.2, R5.1, U6.32 (SPIIO7/GPIO36/FSPICLK/SUBSPICLK)
SCL: R51.1, U2.4 (SCK), U6.35 (MTCK/GPIO39/CLK_OUT3/SUBSPICS1), U12.3 (SCL); also elsewhere on the board
SCL_EXT: J3.8, R52.1, U6.29 (SPIIO5/GPIO34/FSPICS0/SUBSPICS0)
SDA: R50.1, U2.3 (SDI), U6.34 (GPIO38/FSPIWP/SUBSPIWP), U12.4 (SDA); also elsewhere on the board
SDA_EXT: J3.7, R53.1, U6.30 (GPIO48/SPICLK_N/SUBSPICLK_N_DIFF)
USB+: J6.A6 (D+), J6.B6 (D+), U6.24 (GPIO20/U1CTS/ADC2_CH9/CLK_OUT1/USB_D+)
USB-: J6.A7 (D-), J6.B7 (D-), U6.23 (GPIO19/U1RTS/ADC2_CH8/CLK_OUT2/USB_D-)
VBUS_SENSE: R16.1, R54.1, U6.19 (GPIO15/U0RTS/ADC2_CH4/XTAL_32K_P)

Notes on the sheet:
Temperature
Reset / Boot
Temperature + Humidity
USB
5V->3,3V + microUSV
CPU
PSU
24V->12V
GPIO0: PU, aber jederzeit PD GPIO3: JTAG -> Floating GPIO45: Voltage ->PD GPIO46: Logging ->PD
PROG

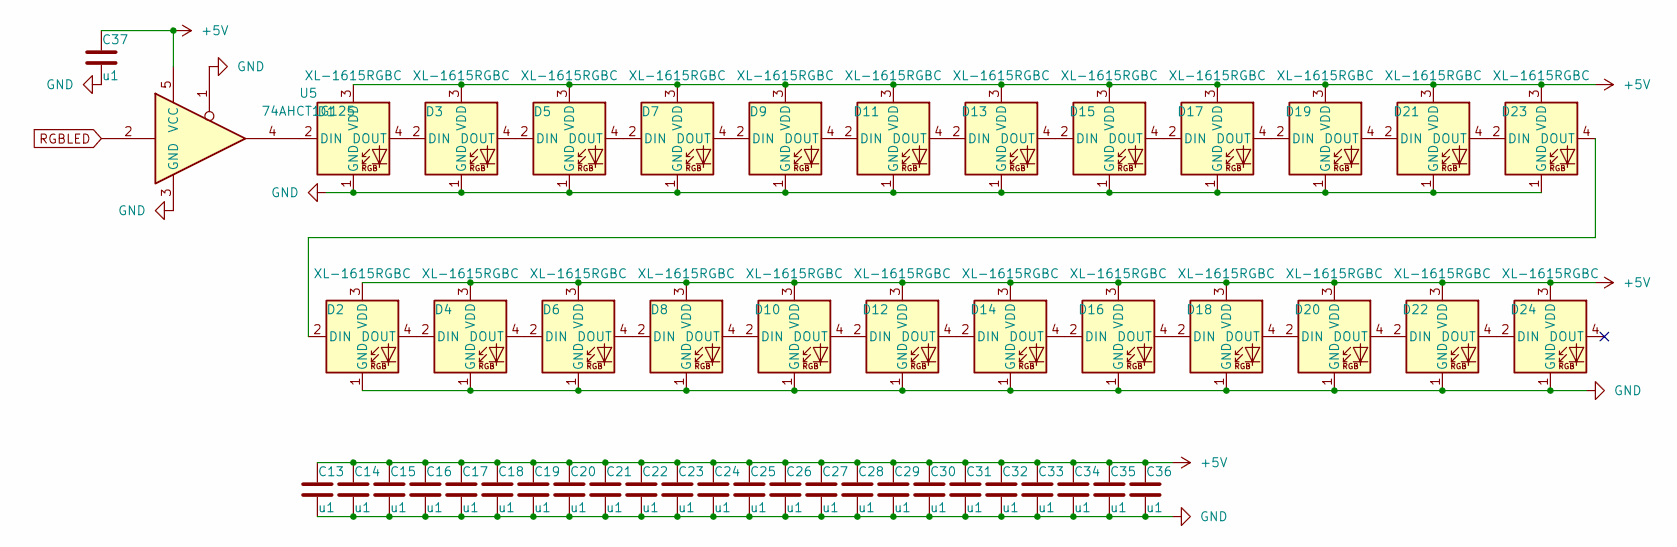
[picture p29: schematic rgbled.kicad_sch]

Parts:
C13, C14, C15, C16, C17, C18, C19, C20, C21, C22, C23, C24, C25, C26, C27, C28, C29, C30, C31, C32, C33, C34, C35, C36, C37: u1; C_0201_0603Metric
D1, D2, D3, D4, D5, D6, D7, D8, D9, D10, D11, D12, D13, D14, D15, D16, D17, D18, D19, D20, D21, D22, D23, D24: XL-1615RGBC; XL-1615
U5: 74AHCT1G125; SOT-23-5

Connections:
+5V: C13.1, C14.1, C15.1, C16.1, C17.1, C18.1, C19.1, C20.1, C21.1, C22.1, C23.1, C24.1, C25.1, C26.1, C27.1, C28.1, C29.1, C30.1, C31.1, C32.1, C33.1, C34.1, C35.1, C36.1, C37.1, D1.3 (VDD), D2.3 (VDD), D3.3 (VDD), D4.3 (VDD), D5.3 (VDD), D6.3 (VDD), D7.3 (VDD), D8.3 (VDD), D9.3 (VDD), D10.3 (VDD), D11.3 (VDD), D12.3 (VDD), D13.3 (VDD), D14.3 (VDD), D15.3 (VDD), D16.3 (VDD), D17.3 (VDD), D18.3 (VDD), D19.3 (VDD), D20.3 (VDD), D21.3 (VDD), D22.3 (VDD), D23.3 (VDD), D24.3 (VDD), U5.5 (VCC); also elsewhere on the board
GND: C13.2, C14.2, C15.2, C16.2, C17.2, C18.2, C19.2, C20.2, C21.2, C22.2, C23.2, C24.2, C25.2, C26.2, C27.2, C28.2, C29.2, C30.2, C31.2, C32.2, C33.2, C34.2, C35.2, C36.2, C37.2, D1.1 (GND), D2.1 (GND), D3.1 (GND), D4.1 (GND), D5.1 (GND), D6.1 (GND), D7.1 (GND), D8.1 (GND), D9.1 (GND), D10.1 (GND), D11.1 (GND), D12.1 (GND), D13.1 (GND), D14.1 (GND), D15.1 (GND), D16.1 (GND), D17.1 (GND), D18.1 (GND), D19.1 (GND), D20.1 (GND), D21.1 (GND), D22.1 (GND), D23.1 (GND), D24.1 (GND), U5.1, U5.3 (GND); also elsewhere on the board
unnamed: D1.2 (DIN), U5.4
unnamed: D1.4 (DOUT), D3.2 (DIN)
unnamed: D2.2 (DIN), D23.4 (DOUT)
unnamed: D2.4 (DOUT), D4.2 (DIN)
unnamed: D3.4 (DOUT), D5.2 (DIN)
unnamed: D4.4 (DOUT), D6.2 (DIN)
unnamed: D5.4 (DOUT), D7.2 (DIN)
unnamed: D6.4 (DOUT), D8.2 (DIN)
unnamed: D7.4 (DOUT), D9.2 (DIN)
unnamed: D8.4 (DOUT), D10.2 (DIN)
unnamed: D10.4 (DOUT), D12.2 (DIN)
unnamed: D9.4 (DOUT), D11.2 (DIN)
unnamed: D11.4 (DOUT), D13.2 (DIN)
unnamed: D12.4 (DOUT), D14.2 (DIN)
unnamed: D13.4 (DOUT), D15.2 (DIN)
unnamed: D14.4 (DOUT), D16.2 (DIN)
unnamed: D15.4 (DOUT), D17.2 (DIN)
unnamed: D16.4 (DOUT), D18.2 (DIN)
unnamed: D17.4 (DOUT), D19.2 (DIN)
unnamed: D18.4 (DOUT), D20.2 (DIN)
unnamed: D19.4 (DOUT), D21.2 (DIN)
unnamed: D20.4 (DOUT), D22.2 (DIN)
unnamed: D21.4 (DOUT), D23.2 (DIN)
unnamed: D22.4 (DOUT), D24.2 (DIN)
RGBLED: U5.2; also elsewhere on the board


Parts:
C40, C41: 1u; CP_EIA-3216-10_Kemet-I; MPN TAJA105K016RNJ
C43, C44, C49, C50, C51, C52: 4u7; C_0402_1005Metric; MPN CL05A475MP5NRNC
C65, C66: u1; C_0201_0603Metric; MPN GRM033R61A104KE15D
FB1: 600R; L_0603_1608Metric; MPN BLM18AG601SN1D
LS2: Speaker; PinHeader_1x02_P1.27mm_Vertical
MK1: Mic; Microphone_6mm; MPN GMI6050P-64DB
NT1: NetTie_2; NetTie-2_SMD_Pad0.5mm
R23: 0R; R_0805_2012Metric_Pad1.20x1.40mm_HandSolder; MPN 0805W8F0000T5E
R24: 2k2; R_0402_1005Metric; MPN 0402WGF2201TCE
R26: 10k; R_0201_0603Metric; MPN 0201WMF1002TEE
U11: NAU8822; QFN-32-1EP_5x5mm_P0.5mm_EP3.6x3.6mm_ThermalVias; MPN NAU88C22YG

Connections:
+3.3VA: C51.1, FB1.1, U11.31 (VDDA)
+3V3: C49.1, C50.1, C65.1, C66.1, FB1.2, U11.13 (VDDC), U11.14 (VDDB); also elsewhere on the board
+5V: C52.1, U11.26 (VDDSPK); also elsewhere on the board
GND: C49.2, C50.2, C65.2, C66.2, NT1.1, R26.2, U11.12 (VSSD); also elsewhere on the board
GNDA: C43.2, C44.2, C51.2, C52.2, NT1.2, R23.1, U11.24 (VSSSPK), U11.28 (VSSA), U11.33 (EXPOSED_PAD)
I2S_ADC: U11.9 (ADCOUT); also elsewhere on the board
I2S_BCLK: U11.8 (BCLK); also elsewhere on the board
I2S_DAC: U11.10 (DACIN); also elsewhere on the board
I2S_FS: U11.7 (FS); also elsewhere on the board
I2S_MCLK: U11.11 (MCLK); also elsewhere on the board
unnamed: C41.1, MK1.2 (+), R24.1
unnamed: C40.1, MK1.1 (-), R23.2
unnamed: C40.2, U11.2 (LMICN), U11.5 (RMICN)
unnamed: C41.2, U11.1 (LMICP), U11.4 (RMICP)
unnamed: LS2.1, U11.25 (LSPKOUT)
unnamed: C43.1, R24.2, U11.32 (MICBIAS)
unnamed: R26.1, U11.18 (MODE)
unnamed: LS2.2, U11.23 (RSPKOUT)
unnamed: C44.1, U11.27 (VREF)
SCL: U11.16 (SCLK); also elsewhere on the board
SDA: U11.17 (SDIO); also elsewhere on the board



Board: 2 copper layers, 70.0 x 70.0 mm, 147 parts (7 on the bottom side), 99 nets.

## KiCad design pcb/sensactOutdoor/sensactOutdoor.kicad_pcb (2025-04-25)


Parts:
C1, C2, C20: m1; C_1206_3216Metric; JLCPCB C15008
C9, C13, C17, C18, C19, C25, C27, C28, C30, C32: u1; C_0805_2012Metric_Pad1.18x1.45mm_HandSolder
C10, C21, C24, C26, C31: 10u; C_1206_3216Metric_Pad1.33x1.80mm_HandSolder
C12: 10u; C_0805_2012Metric_Pad1.18x1.45mm_HandSolder; JLCPCB C19702
C14, C22: 10u; C_0805_2012Metric_Pad1.18x1.45mm_HandSolder
C15: u1; C_0805_2012Metric_Pad1.18x1.45mm_HandSolder; JLCPCB C1525
C16: 22u; C_0805_2012Metric_Pad1.18x1.45mm_HandSolder; JLCPCB C59461
C23: 22n/250V; C_Rect_L11.0mm_W5.1mm_P10.00mm_MKT
C29: u1; C_0805_2012Metric; MPN GRM033R61A104KE15D
C33: 56p; C_0805_2012Metric_Pad1.18x1.45mm_HandSolder
C34, C35: 22u; C_0805_2012Metric_Pad1.18x1.45mm_HandSolder
D1: MAINS; LED_0805_2012Metric_Pad1.15x1.40mm_HandSolder
D2, D3, D4, D10: SM4007PL; D_SOD-123_handsolder; JLCPCB C64898
D7: Info1; LED_D5.0mm-4_RGB_Staggered_Pins
D8: NUP2105; SOT-23_Handsoldering; MPN NUP2105L
D9: 1N5819WS; D_SMA_Handsoldering
D12: LED0; LED_0805_2012Metric_Pad1.15x1.40mm_HandSolder; JLCPCB C2286
D13: L1; LED_0805_2012Metric_Pad1.15x1.40mm_HandSolder; JLCPCB C2286
D14: L2; LED_0805_2012Metric_Pad1.15x1.40mm_HandSolder; JLCPCB C2286
D15: L3; LED_0805_2012Metric_Pad1.15x1.40mm_HandSolder; JLCPCB C2286
D16: L4; LED_0805_2012Metric_Pad1.15x1.40mm_HandSolder; JLCPCB C2286
D23: INFO; LED_0805_2012Metric_Pad1.15x1.40mm_HandSolder
F1: T2.0; Fuse_Littelfuse_372_D8.50mm
H1, H2, H3, H4, H5, H6, H7, H8: H; MountingHole_3.2mm_M3
J1: USB; PinHeader_1x04_P2.54mm_Vertical
J6: CAN; PhoenixContact_MCV_1,5_4-G-3.5_1x04_P3.50mm_Vertical
J7: EXT1; JST_XH_B5B-XH-A_1x05_P2.50mm_Vertical
J8: LED Out; ÖLFLEX 4x1mm2
J9: L_IN; Flachstecker gewinkelt 4,8 oder 6,35mm
J10, J11, J12, J15, J18, J19, J20, J21, J22: LED1; JST_XH_B2B-XH-A_1x02_P2.50mm_Vertical
J13: RGB; PinHeader_1x03_P2.54mm_Vertical
J14: PE_IN; Flachstecker gewinkelt 4,8 oder 6,35mm
J16: N_IN; Flachstecker gewinkelt 4,8 oder 6,35mm
J17: LED Out; PhoenixContact_MCV_1,5_4-G-3.5_1x04_P3.50mm_Vertical
J23: L1; Flachstecker gewinkelt 4,8 oder 6,35mm
J24: L2; Flachstecker gewinkelt 4,8 oder 6,35mm
J25: L3; Flachstecker gewinkelt 4,8 oder 6,35mm
J26: L4; Flachstecker gewinkelt 4,8 oder 6,35mm
J27, J29: N; Flachstecker gewinkelt 4,8 oder 6,35mm
J28, J30: PE; Flachstecker gewinkelt 4,8 oder 6,35mm
J32: PROG; PinHeader_2x03_P2.54mm_Vertical
K1, K2, K3, K4: ALDP105W; RELAY_ALDP105W
L1, L2: 22uH; L_0630; JLCPCB C408455
L3: 10uH; L_0630
PS2: HLK-30M24C; Converter_ACDC_Hi-Link_HLK-30Mxx
Q6: BC847; SOT-23_Handsoldering; JLCPCB C8512
Q7, Q8, Q9: BC847; SOT-23_Handsoldering
R1, R5, R6, R7, R8, R46: 1k; R_0805_2012Metric_Pad1.20x1.40mm_HandSolder
R2, R13: 0R15; R_1206_3216Metric_Pad1.30x1.75mm_HandSolder; JLCPCB C25271
R3, R29, R47: 10k; R_0805_2012Metric_Pad1.20x1.40mm_HandSolder
R4: 22k; R_0805_2012Metric_Pad1.20x1.40mm_HandSolder
R9, R32, R48: k1; R_0805_2012Metric_Pad1.20x1.40mm_HandSolder
R10: 15k; R_0805_2012Metric_Pad1.20x1.40mm_HandSolder
R11: 10k; R_0805_2012Metric_Pad1.20x1.40mm_HandSolder; MPN 0201WMF1002TEE
R12: K12; R_1206_3216Metric_Pad1.30x1.75mm_HandSolder; MPN 1206W4F1200T5E
R14, R33, R34, R37, R38: k47; R_0805_2012Metric_Pad1.20x1.40mm_HandSolder
R15: M1; R_0805_2012Metric_Pad1.20x1.40mm_HandSolder
R16, R28: 3k3; R_2512_6332Metric_Pad1.40x3.35mm_HandSolder
R17, R18: 6k8; R_0805_2012Metric_Pad1.20x1.40mm_HandSolder
R25, R26: 4k7; R_0805_2012Metric_Pad1.20x1.40mm_HandSolder
R30, R31: 470K; R_2512_6332Metric_Pad1.40x3.35mm_HandSolder
RV1: 10D561K; RV_Disc_D12mm_W3.9mm_P7.5mm
SW1: TERM OFF; Switch_SS12D00
SW2: PROG; SW_SPST_TL3342_smaller_handsolder
SW4: RESET; SW_SPST_TL3342_smaller_handsolder
TP3: LED0; TestPoint_THTPad_D2.0mm_Drill1.0mm
U1: MAX98357_MODULE; PinHeader_1x07_P2.54mm_Vertical
U2, U3: TPS92200D2DDCR; SOT-23-6_Handsoldering
U4: NRF24L01_Breakout_SMD; NRF24L01-Module-SMD
U5: AMS1117-3.3; SOT-223-3_TabPin2_HANDSOLDER
U7: SN65HVD230; SOIC-8_3.9x4.9mm_Pitch1.27mm_handsolder; MPN SN65HVD230DR
U8: EL817; SO-4_7.6x3.6mm_P2.54mm_handsolder
U9: TPS54202DDC; SOT-23-6_Handsoldering
U10: DS18B20; TO-92L_HandSolder
U11: ESP32-S3-WROOM-1; ESP32-S3-WROOM-1_handsolder

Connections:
+3V3: C2.1, C13.1, C14.1, C15.1, C16.1, C22.1, C29.1, J6.4, J7.4, J32.2, R3.2, R25.1, R26.1, R29.2, R46.2, R47.2, U1.7 (VCC), U4.1 (VCC), U5.2 (VO), U7.3 (VCC), U10.3 (V_{DD}), U11.2 (3V3), U11.19 (IO11)
+5P: C9.2, C33.2, C34.1, C35.1, D2.1 (K), D3.1 (K), D4.1 (K), D7.3 (VDD), D9.2 (A), D10.1 (K), J7.5, J13.1, K1.A1, K2.A1, K3.A1, K4.A1, L3.1, R15.1
+5V: C1.1, C12.1, C20.1, D9.1 (K), U5.3 (VI)
+24V: C10.1, C18.1, C24.1, C27.1, C30.2, C31.2, PS2.6 (+Vout), U2.4 (VIN), U3.4 (VIN), U9.3 (VIN)
/BOOT: C32.1, U9.6 (BOOT)
/FB: C33.1, R15.2, R17.2, U9.4 (FB)
/L1: J23.1, K1.14
/L2: J24.1, K2.14
/L3: J25.1, K3.14
/L4: J26.1, K4.14
/LINE_FUSED: C23.1, F1.1, PS2.2 (AC/N), R30.2, RV1.1
/SW: C32.2, L3.2, U9.2 (SW)
CANH: D8.1 (A1), J6.1, SW1.2 (B), SW1.3 (C), U7.7 (CANH)
CANL: D8.2 (A2), J6.2, R12.2, U7.6 (CANL)
CAN_RX: U7.4 (R), U11.35 (IO42)
CAN_TX: U7.1 (D), U11.39 (IO1)
CE: U4.3 (CE), U11.4 (IO4)
CSN: U4.4 (~CSN), U11.5 (IO5)
GND: C1.2, C2.2, C9.1, C10.2, C12.2, C13.2, C14.2, C15.2, C16.2, C17.2, C18.2, C20.2, C21.2, C22.2, C24.2, C25.2, C26.2, C27.2, C29.2, C30.1, C31.1, C34.2, C35.2, D7.2 (GND), D8.3 (common), D12.1 (K), D13.1 (K), D14.1 (K), D15.1 (K), D16.1 (K), D23.1 (K), J1.1, J6.3, J7.3, J13.3, J32.4, PS2.3 (-Vout), Q6.2 (E), Q7.2 (E), Q8.2 (E), Q9.2 (E), R2.2, R4.2, R11.2, R13.2, R18.1, SW2.2, SW4.2, U1.6 (GND), U2.3 (GND), U3.3 (GND), U4.2 (GND), U5.1 (GND), U7.2 (GND), U8.3, U9.1 (GND), U10.1 (GND), U11.1 (GND), U11.40 (GND), U11.41 (GND)
I2S_BCLK: U1.3 (DIN), U11.32 (IO39)
I2S_DATA: U1.4 (GAIN), U11.31 (IO38)
I2S_GAIN: U1.1 (LRC), U11.34 (IO41)
I2S_LRC: U1.2 (BCLK), U11.33 (IO40)
I2S_SD: U1.5 (SD), U11.26 (IO45)
INFO_LED: R1.2, U11.16 (IO46)
IRQ: U4.8 (IRQ), U11.9 (IO16)
K1: R5.1, R33.1, U11.10 (IO17)
K2: R6.1, R34.1, U11.11 (IO18)
K3: R7.1, R37.1, U11.17 (IO9)
K4: R8.1, R38.1, U11.18 (IO10)
LED0+: C26.1, J17.1, L2.1
LED0-: J17.2, R13.1, U2.1 (FB)
LED0_DIM: R14.1, TP3.1, U2.2 (DIM), U11.25 (IO48)
LED1+: C21.1, J17.4, L1.1
LED1-: J17.3, R2.1, U3.1 (FB)
LED1_DIM: U3.2 (DIM), U11.24 (IO47)
LINE: F1.2, J9.1, K1.11, K2.11, K3.11, K4.11
MAINS: R29.1, R32.2, U11.23 (IO21)
MISO: U4.7 (MISO), U11.8 (IO15)
MOSI: U4.6 (MOSI), U11.7 (IO7)
NEUT: J16.1, J27.1, J29.1, PS2.1 (AC/L), R28.2, RV1.2
unnamed: D1.2 (A), R16.1, U8.2
unnamed: C23.2, D1.1 (K), R31.1, U8.1
unnamed: D2.2 (A), K2.A2, Q7.3 (C)
unnamed: D3.2 (A), K3.A2, Q8.3 (C)
unnamed: D4.2 (A), K4.A2, Q9.3 (C)
unnamed: D10.2 (A), K1.A2, Q6.3 (C)
unnamed: D12.2 (A), R14.2
unnamed: D13.2 (A), R33.2
unnamed: D14.2 (A), R34.2
unnamed: D15.2 (A), R37.2
unnamed: D16.2 (A), R38.2
unnamed: D23.2 (A), R1.1
unnamed: J8.1, J10.1
unnamed: J10.2, J11.1
unnamed: J11.2, J15.1
unnamed: J12.1, J15.2
unnamed: J12.2, J18.1
unnamed: J8.2, J18.2
unnamed: J8.4, J19.1
unnamed: J19.2, J20.1
unnamed: J20.2, J21.1
unnamed: J21.2, J22.1
unnamed: J8.3, J22.2
unnamed: Q6.1 (B), R5.2
unnamed: Q7.1 (B), R6.2
unnamed: Q8.1 (B), R7.2
unnamed: Q9.1 (B), R8.2
unnamed: R9.1, SW2.1
unnamed: R16.2, R28.1
unnamed: R17.1, R18.2
unnamed: R30.1, R31.2
unnamed: R32.1, U8.4
unnamed: R48.1, SW4.1
unnamed: R12.1, SW1.1 (A)
unnamed: C28.1, U2.6 (BOOT)
unnamed: C28.2, L2.2, U2.5 (SW)
unnamed: C19.1, U3.6 (BOOT)
unnamed: C19.2, L1.2, U3.5 (SW)
unnamed: R11.1, U7.8 (Rs)
Onewire: R46.1, U10.2 (DQ), U11.22 (IO14)
PE: J14.1, J28.1, J30.1
PROG_EN: C25.1, J32.1, R47.1, R48.2, U11.3 (EN)
PROG_IO0: C17.1, J32.6, R3.1, R9.2, U11.27 (IO0)
PROG_RX: J32.5, U11.36 (RXD0)
PROG_TX: J32.3, U11.37 (TXD0)
RGB_LED: D7.4 (DI), U11.15 (IO3)
RGB_OUT: D7.1 (DO), J13.2
SCK: U4.5 (SCK), U11.6 (IO6)
SCL: J7.2, R26.2, U11.20 (IO12)
SDA: J7.1, R25.2, U11.21 (IO13)
USB+: J1.2, U11.14 (USB_D+)
USB-: J1.3, U11.13 (USB_D-)
VBUS: J1.4, R10.1
VBUS_SENSE: R4.1, R10.2, U11.12 (IO8)

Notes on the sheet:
230V->5V
Relais
CPU
Temperature
LED CC
PSU
RF 2.4GHz
Connectors
CAN
230V_DETECT
Info LEDs
Reset / Boot
RGB LED
PROG
5V->3,3V + microUSV
GPIO0: PU, aber jederzeit PD GPIO3: JTAG -> Floating GPIO45: Voltage ->PD GPIO46: Logging ->PD



Board: 2 copper layers, 100.0 x 91.6 mm, 137 parts (82 on the bottom side), 95 nets.

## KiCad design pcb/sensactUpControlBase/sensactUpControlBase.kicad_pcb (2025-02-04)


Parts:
C1: 10u; C_1206_3216Metric_Pad1.33x1.80mm_HandSolder
C2, C6: u1; C_0805_2012Metric_Pad1.18x1.45mm_HandSolder
C3: 56p; C_0805_2012Metric_Pad1.18x1.45mm_HandSolder
C4, C5: 22u; C_0805_2012Metric_Pad1.18x1.45mm_HandSolder
J1: BaseConnect; PinHeader_2x07_P2.54mm_Vertical
J2, J9: WAGO_250-210
J3: GND T0 T1; WAGO_250_203A
J4: A RS485 B; WAGO_250_203A
L1: 10u; L_0630
R1: M1; R_0805_2012Metric_Pad1.20x1.40mm_HandSolder
R2: 22k; R_0805_2012Metric_Pad1.20x1.40mm_HandSolder
R3: k22; R_0805_2012Metric_Pad1.20x1.40mm_HandSolder
U1: TPS54202DDC; SOT-23-6_Handsoldering
U2: PC817; mdip_4_handsolder

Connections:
+3V3: C3.2, C4.1, C5.1, J1.8, J2.10, J3.1, L1.1, R1.1
+24V: C1.2, C6.2, J2.8, J9.1, J9.5, U1.3 (VIN), U2.4
/BOOT: C2.1, U1.6 (BOOT)
/FB: C3.1, R1.2, R2.2, U1.4 (FB)
/SW: C2.2, L1.2, U1.2 (SW)
CANH: J1.11, J9.3, J9.7
CANL: J1.12, J9.4, J9.8
CONTACT1: J1.4, J2.2
CONTACT2: J1.2, J2.3
FINGER_IRQ: J1.3, J2.6
FINGER_RX: J1.1, J2.4
FINGER_TX: J1.5, J2.5
GND: C1.1, C4.2, C5.2, C6.1, J1.7, J1.10, J2.1, J2.9, J3.3, J4.2, J9.2, J9.6, R2.1, U1.1 (GND), U2.2
MOTOR: J1.9, R3.2
MOTOR1: J2.7, U2.3
unnamed: R3.1, U2.1
ONE_WIRE: J1.6, J3.2
RS485A: J1.13, J4.3
RS485B: J1.14, J4.1

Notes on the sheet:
Motor
PSU



Board: 2 copper layers, 36.0 x 48.2 mm, 17 parts (12 on the bottom side), 19 nets.

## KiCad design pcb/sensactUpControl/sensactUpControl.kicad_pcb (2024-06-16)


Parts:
BZ1: Buzzer; XDCR_CMT-7525-80-SMT-TR_handsolder
C1, C2, C8, C10: u1; C_0805_2012Metric_Pad1.18x1.45mm_HandSolder
C3, C4: 1u; C_0805_2012Metric_Pad1.18x1.45mm_HandSolder
C9: 22u; C_0805_2012Metric_Pad1.18x1.45mm_HandSolder
D1: PSM712; SOT-23_Handsoldering
D2: NUP2105; SOT-23_Handsoldering
D3, D7: LED; LED_PLCC_2835_Handsoldering
H1: CentralHole; MountingHole_3.2mm_M3
J1: -USB+; PinHeader_1x02_P2.00mm_Vertical
J2: GND; PinHeader_1x02_P2.00mm_Vertical
J8: BaseConnect; PinHeader_2x07_P2.54mm_Vertical
J10: PROG; IDC_2x03_P1.27mm_Vertical
J11: I2C_Sensor; PinHeader_1x04_P2.54mm_Vertical
Q1, Q3, Q4: BC847; SOT-23_Handsoldering
Q2: AO3400A; SOT-23_Handsoldering
R1, R2, R7, R17: 4k7; R_0805_2012Metric_Pad1.20x1.40mm_HandSolder
R3, R4, R6, R9, R11, R14, R15: 1k; R_0805_2012Metric_Pad1.20x1.40mm_HandSolder
R5, R8: K12; R_1206_3216Metric_Pad1.30x1.75mm_HandSolder
R10: k1; R_0805_2012Metric_Pad1.20x1.40mm_HandSolder
R12, R13: 10k; R_0805_2012Metric_Pad1.20x1.40mm_HandSolder
R16, R24: k22; R_1206_3216Metric_Pad1.30x1.75mm_HandSolder
SW1: ON TERM 485; SW_SPDT_PCM12_handsolder
SW2: ON TERM CAN; SW_SPDT_PCM12_handsolder
SW4: Reset; SW_SPST_TL3342_smaller_handsolder
SW5: Boot; SW_SPST_TL3342_smaller_handsolder
U1: ESP32-S3-WROOM-1; ESP32-S3-WROOM-1_handsolder
U2: MAX3485; SOIC-8_3.9x4.9mm_Pitch1.27mm_handsolder
U3: SN65HVD230; SOIC-8_3.9x4.9mm_Pitch1.27mm_handsolder
U7: NRF24L01_Breakout; nRF24L01_Breakout
U8: DS18B20; TO-92_HandSolder
X1: LH114; FP-114 13pol top only

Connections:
485_DE: U1.16 (GPIO46), U2.2 (~RE), U2.3 (DE)
485_DI: U1.15 (GPIO3/TOUCH3/ADC1_CH2), U2.4 (DI)
485_RO: U1.17 (GPIO9/TOUCH9/ADC1_CH8/FSPIHD/SUBSPIHD), U2.1 (RO)
+3V3: BZ1.P (+), C1.2, C2.1, C3.1, C4.1, C8.1, C9.1, J8.8, J10.2, J11.1, R1.2, R2.2, R4.1, R11.1, R12.2, R13.2, R16.1, R17.2, R24.1, U1.2 (3V3), U2.8 (VCC), U3.3 (VCC), U7.2 (VCC), U8.3 (V_{DD}), X1.10 (VCC), X1.12 (LEDA)
/LEDK: R10.2, X1.11 (LEDK)
/Reset: R11.2, X1.6 (RES)
BUZZER: R6.2, U1.6 (GPIO6/TOUCH6/ADC1_CH5)
CANH: D2.1 (A1), J8.11, R8.2, U3.7 (CANH)
CANL: D2.2 (A2), J8.12, SW2.2 (B), SW2.3 (C), U3.6 (CANL)
CAN_RX: U1.18 (GPIO10/TOUCH10/ADC1_CH9/FSPICS0/FSPIIO4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), U3.4 (R)
CAN_TX: U1.19 (GPIO11/TOUCH11/ADC2_CH0/FSPID/FSPIIO5/S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), U3.1 (D)
CONTACT1: J8.4, U1.24 (GPIO47/SPICLK_P/SUBSPICLK_P_DIFF)
CONTACT2: J8.2, U1.25 (GPIO48/SPICLK_N/SUBSPICLK_N_DIFF)
FINGER_IRQ: J8.3, U1.32 (MTCK/GPIO39/CLK_OUT3/SUBSPICS1)
FINGER_RX: J8.1, U1.31 (GPIO38/FSPIWP/SUBSPIWP)
FINGER_TX: J8.5, U1.33 (MTDO/GPIO40/CLK_OUT2)
GND: C1.1, C2.2, C3.2, C4.2, C8.2, C9.2, C10.2, D1.3 (A), D2.3 (common), J2.1, J2.2, J8.7, J8.10, J10.4, J11.2, Q1.2 (E), Q2.2 (S), Q3.2 (E), Q4.2 (E), R3.2, R7.2, SW4.1, SW5.1, U1.1 (GND), U1.40 (GND), U1.41 (GND), U2.5 (GND), U3.2 (GND), U7.1 (GND), U8.1 (GND), X1.8 (GND), X1.13 (GND)
LCD_BACKLIGHT: R9.1, U1.26 (GPIO45)
LCD_CS: U1.20 (GPIO12/TOUCH12/ADC2_CH1/FSPICLK/FSPIIO6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), X1.7 (~CS)
LCD_MOSI: U1.23 (GPIO21), X1.3 (SDA)
LCD_RS: U1.21 (GPIO13/TOUCH13/ADC2_CH2/FSPIQ/FSPIIO7/S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), X1.5 (RS)
LCD_SCLK: U1.22 (GPIO14/TOUCH14/ADC2_CH3/FSPIWP/FSPIDQS/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), X1.4 (SCL)
LED1: R14.2, U1.39 (GPIO1/TOUCH1/ADC1_CH0)
LED2: R15.2, U1.38 (GPIO2/TOUCH2/ADC1_CH1)
MOTOR: J8.9, U1.35 (MTMS/GPIO42)
NRF_CE: U1.7 (GPIO7/TOUCH7/ADC1_CH6), U7.3 (CE)
NRF_CS: U1.8 (GPIO15/U0RTS/ADC2_CH4/XTAL_32K_P), U7.4 (~CSN)
NRF_IRQ: U1.12 (GPIO8/TOUCH8/ADC1_CH7/SUBSPICS1), U7.8 (IRQ)
NRF_MISO: U1.11 (GPIO18/U1RXD/ADC2_CH7/CLK_OUT3), U7.7 (MISO)
NRF_MOSI: U1.10 (GPIO17/U1TXD/ADC2_CH6), U7.6 (MOSI)
NRF_SCLK: U1.9 (GPIO16/U0CTS/ADC2_CH5/XTAL_32K_N), U7.5 (SCK)
unnamed: BZ1.N (-), Q1.3 (C)
unnamed: D3.2 (A), R16.2
unnamed: D3.1 (K), Q4.3 (C)
unnamed: D7.2 (A), R24.2
unnamed: D7.1 (K), Q3.3 (C)
unnamed: Q1.1 (B), R6.1
unnamed: Q2.3 (D), R10.1
unnamed: Q2.1 (G), R9.2
unnamed: Q3.1 (B), R14.1
unnamed: Q4.1 (B), R15.1
unnamed: R5.1, SW1.1 (A)
unnamed: R8.1, SW2.1 (A)
unnamed: R7.1, U3.8 (Rs)
ONE_WIRE: J8.6, R17.1, U1.34 (MTDI/GPIO41/CLK_OUT1), U8.2 (DQ)
PROG_EN: C10.1, J10.1, R12.1, SW4.2, U1.3 (EN)
PROG_IO0: J10.6, R13.1, SW5.2, U1.27 (GPIO0/BOOT)
PROG_RX: J10.5, U1.36 (U0RXD/GPIO44/CLK_OUT2)
PROG_TX: J10.3, U1.37 (U0TXD/GPIO43/CLK_OUT1)
RS485A: D1.2 (K), J8.13, R4.2, R5.2, U2.6 (A)
RS485B: D1.1 (K), J8.14, R3.1, SW1.2 (B), SW1.3 (C), U2.7 (B)
SCL: J11.3, R2.1, U1.4 (GPIO4/TOUCH4/ADC1_CH3)
SDA: J11.4, R1.1, U1.5 (GPIO5/TOUCH5/ADC1_CH4)
USB+: J1.1, U1.14 (GPIO20/U1CTS/ADC2_CH9/CLK_OUT1/USB_D+)
USB-: J1.2, U1.13 (GPIO19/U1RTS/ADC2_CH8/CLK_OUT2/USB_D-)

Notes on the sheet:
Leds
Buzzer
CAN
0-> Boot Mode PU 3-> JTAG PD 45->SPI Voltage PD 46 ->Boot Messages PD
RS485
PROG

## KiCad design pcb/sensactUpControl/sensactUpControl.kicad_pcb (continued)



Board: 2 copper layers, 68.0 x 68.0 mm, 50 parts (11 on the bottom side), 55 nets.

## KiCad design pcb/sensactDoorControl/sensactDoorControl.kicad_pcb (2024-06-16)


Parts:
BZ1: Buzzer; XDCR_CMT-7525-80-SMT-TR_handsolder
C1: 56p; C_0805_2012Metric_Pad1.18x1.45mm_HandSolder
C2, C10, C15: 22u; C_0805_2012Metric_Pad1.18x1.45mm_HandSolder
C3, C7, C8, C9, C14: u1; C_0805_2012Metric_Pad1.18x1.45mm_HandSolder
C11: 10u; C_1206_3216Metric_Pad1.33x1.80mm_HandSolder
D1: NUP2105; SOT-23_Handsoldering
D2: PSM712; SOT-23_Handsoldering
D3: INFO; LED_0805_2012Metric_Pad1.15x1.40mm_HandSolder
D4: D; D_SOD-123_handsolder
J1: Finger_large; PhoenixContact_MC_1,5_4-G-3.5_1x04_P3.50mm_Horizontal_small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
J2: Can+24V; PhoenixContact_MC_1,5_4-G-3.5_1x04_P3.50mm_Horizontal_small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
J3: RS485; PhoenixContact_MC_1,5_4-G-3.5_1x04_P3.50mm_Horizontal_small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
J4: PROG; JST_SH_SM06B-SRSS-TB_1x06-1MP_P1.00mm_Horizontal_handsolder
J5: Motor; PhoenixContact_MC_1,5_4-G-3.5_1x04_P3.50mm_Horizontal_small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
J6: LCD; PinSocket_1x04_P2.54mm_Vertical
J9: G16; TestPoint_THTPad_D1.5mm_Drill0.7mm
J10: Fingerprint; JST_SH_SM06B-SRSS-TB_1x06-1MP_P1.00mm_Horizontal_handsolder
J12: G23; TestPoint_THTPad_D1.5mm_Drill0.7mm
J13: I2C; JST_XH_B6B-XH-A_1x06_P2.50mm_Vertical
L2: 10u; L_0630
Q1, Q3: BC847; SOT-23_Handsoldering
Q2: PNP; SOT-23_Handsoldering
R1, R2, R10, R14, R15, R18, R19: 1k; R_0805_2012Metric_Pad1.20x1.40mm_HandSolder
R3, R12, R13: 4k7; R_0805_2012Metric_Pad1.20x1.40mm_HandSolder
R4, R9: K12; R_1206_3216Metric_Pad1.30x1.75mm_HandSolder
R5, R17: M1; R_0805_2012Metric_Pad1.20x1.40mm_HandSolder
R6, R7: 10k; R_0805_2012Metric_Pad1.20x1.40mm_HandSolder
R8: 22k; R_0805_2012Metric_Pad1.20x1.40mm_HandSolder
R11: k22/1k; R_0805_2012Metric_Pad1.20x1.40mm_HandSolder
R16: k22; R_0805_2012Metric_Pad1.20x1.40mm_HandSolder
SW1: Boot; SW_SPST_TL3342_smaller_handsolder
SW2: Reset; SW_SPST_TL3342_smaller_handsolder
SW3: ON TERM; SW_SPDT_PCM12_handsolder
SW4: TERM ON; SW_SPDT_PCM12_handsolder
U1: ESP32-WROOM-E; ESP32-WROOM-32_HANDSOLDER
U2: TPS54202DDC; SOT-23-6_Handsoldering
U3: PC817; mdip_4_handsolder
U4: SN65HVD230; SOIC-8_3.9x4.9mm_Pitch1.27mm_handsolder
U5: MAX3485; SOIC-8_3.9x4.9mm_Pitch1.27mm_handsolder

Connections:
485_DE: U1.9 (32K_XN/GPIO33/ADC1_CH5), U5.2 (~RE), U5.3 (DE)
485_DI: U1.10 (DAC_1/ADC2_CH8/GPIO25), U5.4 (DI)
485_RO: U1.4 (SENSOR_VP/GPIO36/ADC1_CH0), U5.1 (RO)
+3V3: BZ1.P (+), C1.2, C2.1, C3.2, C7.1, C8.1, C10.1, C15.1, D3.2 (A), J1.4, J4.2, J6.3, J10.1, J13.6, L2.1, Q2.2 (E), R2.1, R5.1, R6.2, R7.2, R12.2, R13.2, R17.1, R19.1, U1.2 (3V3), U4.3 (VCC), U5.8 (VCC)
+24V: C11.2, D4.1 (K), J2.4, J5.4, U2.3 (VIN), U3.4
/BOOT: C14.1, U2.6 (BOOT)
/FB: C1.1, R5.2, R8.2, U2.4 (FB)
/IO21: R14.2, R15.1, U1.33 (GPIO21)
/SW: C14.2, L2.2, U2.2 (SW)
BUZZER: R10.2, U1.14 (MTDI/GPIO12/ADC2_CH5)
CANH: D1.1 (A1), J2.3, R4.2, U4.7 (CANH)
CANL: D1.2 (A2), J2.2, SW3.2 (B), SW3.3 (C), U4.6 (CANL)
CAN_RX: U1.30 (GPIO18), U4.4 (R)
CAN_TX: U1.29 (GPIO5), U4.1 (D)
FINGER_IRQ: J10.2, U1.7 (GPIO35/ADC1_CH7)
FINGER_ON: R18.1, U1.23 (MTDO/GPIO15/ADC2_CH3)
FINGER_RX: J1.3, J10.4, U1.5 (SENSOR_VN/GPIO39/ADC1_CH3)
FINGER_TX: J1.2, J10.3, U1.8 (32K_XP/GPIO32/ADC1_CH4)
GND: C2.2, C3.1, C7.2, C8.2, C9.2, C10.2, C11.1, C15.2, D1.3 (common), D2.3 (A), J1.1, J2.1, J3.1, J4.4, J5.1, J6.4, J10.5, J13.5, Q1.2 (E), Q3.2 (E), R1.2, R3.2, R8.1, R15.2, SW1.1, SW2.2, U1.1 (GND), U1.15 (GND), U1.38 (GND), U1.39 (GND_THERMAL), U2.1 (GND), U3.2, U4.2 (GND), U5.5 (GND)
IO13: J13.1, U1.16 (MTCK/GPIO13/ADC2_CH4)
IO26: J3.4, J13.2, R19.2, U1.11 (DAC_2/ADC2_CH9/GPIO26)
LED: R16.2, U1.36 (GPIO22)
MOTOR: R11.2, U1.24 (ADC2_CH2/GPIO2)
MOTOR1: D4.2 (A), J5.3, Q3.3 (C), U3.3
unnamed: BZ1.N (-), Q1.3 (C)
unnamed: D3.1 (K), R16.1
unnamed: J5.2, R14.1
unnamed: J9.1, U1.27 (GPIO16)
unnamed: J10.6, Q2.3 (C)
unnamed: J12.1, U1.37 (GPIO23)
unnamed: Q1.1 (B), R10.1
unnamed: Q2.1 (B), R17.2, R18.2
unnamed: Q3.1 (B), R11.1, U3.1
unnamed: R4.1, SW3.1 (A)
unnamed: R9.1, SW4.1 (A)
unnamed: R3.1, U4.8 (Rs)
PROG_EN: C9.1, J4.1, R6.1, SW2.1, U1.3 (EN/CHIP_PU)
PROG_IO0: J4.6, R7.1, SW1.2, U1.25 (GPIO0/BOOT/ADC2_CH1)
PROG_RX: J4.5, U1.34 (U0RXD/GPIO3)
PROG_TX: J4.3, U1.35 (U0TXD/GPIO1)
RS485A: D2.2 (K), J3.2, R2.2, R9.2, U5.6 (A)
RS485B: D2.1 (K), J3.3, R1.1, SW4.2 (B), SW4.3 (C), U5.7 (B)
SCL: J6.2, J13.4, R13.1, U1.13 (MTMS/GPIO14/ADC2_CH6)
SDA: J6.1, J13.3, R12.1, U1.12 (ADC2_CH7/GPIO27)

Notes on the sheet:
CAN
Prog
STRAP_PU
STRAP_PD
PSU



Board: 2 copper layers, 40.2 x 35.8 mm, 57 parts (28 on the bottom side), 44 nets.

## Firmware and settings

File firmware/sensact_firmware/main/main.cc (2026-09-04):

//#define HTTP
#define HTTPS

//c++ lib incudes
#include <cstdio>
#include <cstring>
#include <vector>

//FreeRTOS & Lwip includes
#include <freertos/FreeRTOS.h>
#include <freertos/task.h>

//esp idf includes
#include <esp_system.h>
#include <esp_log.h>
#include <esp_littlefs.h>
#include <spi_flash_mmap.h>
#include <esp_log.h>
#include <nvs.h>
#include <nvs_flash.h>
#include "tinyusb.h"
#include "tinyusb_cdc_acm.h"
#include "tinyusb_console.h"
#include "tinyusb_default_config.h"

#ifdef HTTPS
#include <esp_https_server.h>
#ifndef CONFIG_ESP_HTTPS_SERVER_ENABLE
#error "Enable HTTPS_SERVER in menuconfig!"
#endif
#endif
#ifdef HTTP
#include <esp_http_server.h>
#endif

//klaus-liebler component components
#include <common-esp32.hh>
#include <adc_buttons.hh>
#include <webmanager.hh>

//sensact in
#include <sensact_projectconfig.hh>
#include <can_message_builder_parser.hh>
#include <nodemaster.hh>
#include <busmaster.hh>
#include <model_node.hh>
#include <runtimeconfig_cpp/runtimeconfig.hh>
#include <runtimeconfig_cpp/runtimeconfig_defines.hh>
#include <webmanager_plugins/systeminfo_plugin.hh>


constexpr const char* NVS_PARTITION_NAME{NVS_DEFAULT_PART_NAME};

//board specific includes
#include "hal/board_init_interface.hh"
#include <board_init.hh>
#include <cApplications.hh>

#define TAG "main"
using namespace sensact;

httpd_handle_t http_server{nullptr};

FLASH_FILE(esp32_pem_crt);
FLASH_FILE(esp32_pem_key);

// ---- USB descriptors --------------------------------------------------------
// Espressif VID 0x303A, PID 0x4001 = CDC-only (bit 0 set)
static const tusb_desc_device_t s_usb_device_desc = {
    sizeof(tusb_desc_device_t), // bLength
    TUSB_DESC_DEVICE,           // bDescriptorType
    0x0200,                     // bcdUSB  USB 2.0
    TUSB_CLASS_MISC,            // bDeviceClass    (required for IAD/CDC)
    MISC_SUBCLASS_COMMON,       // bDeviceSubClass
    MISC_PROTOCOL_IAD,          // bDeviceProtocol
    CFG_TUD_ENDPOINT0_SIZE,     // bMaxPacketSize0
    0x303Au,                    // idVendor  (Espressif)
    0x4001u,                    // idProduct (CDC-only auto-PID)
    0x0100u,                    // bcdDevice
    0x01,                       // iManufacturer
    0x02,                       // iProduct
    0x03,                       // iSerialNumber
    0x01,                       // bNumConfigurations
};

static const char *s_usb_string_desc[] = {
    "\x09\x04",           // 0: Language ID – English (0x0409)
    "Klaus Liebler",       // 1: Manufacturer
    cfg::NODE_ID,          // 2: Product
    cfg::NODE_ID,          // 3: Serial number (unique per node)
    "Sensact CDC Device",  // 4: CDC interface
    nullptr,
};

// CDC-ACM configuration descriptor (matches component default EP layout:
// EP1 IN = CDC notification, EP2 OUT/IN = CDC data)
#define SENSACT_USB_EPNUM_CDC_NOTIF  0x81
#define SENSACT_USB_EPNUM_CDC_OUT    0x02
#define SENSACT_USB_EPNUM_CDC_IN     0x82
#define SENSACT_USB_CFG_DESC_LEN     (TUD_CONFIG_DESC_LEN + TUD_CDC_DESC_LEN)
static const uint8_t s_usb_cfg_desc[] = {
    TUD_CONFIG_DESCRIPTOR(1, 2, 0, SENSACT_USB_CFG_DESC_LEN, 0, 100),
    TUD_CDC_DESCRIPTOR(0, 4, SENSACT_USB_EPNUM_CDC_NOTIF, 8,
                       SENSACT_USB_EPNUM_CDC_OUT, SENSACT_USB_EPNUM_CDC_IN, 64),
};
// -----------------------------------------------------------------------------

extern "C" void app_main(void)
{
    //ESP_LOGI(TAG, "\n%s", cfg::BANNER);
    ESP_LOGI(TAG, "%s is booting up. Firmware build at %s on Git %s", cfg::NODE_ID, cfg::CREATION_DT_STR, cfg::GIT_SHORT_HASH);

    sensact::BoardInit boardInit;

    // Configure NVS and SPIFFS
    size_t total = 0, used = 0;
    esp_vfs_littlefs_conf_t conf = {"/spiffs", "storage", nullptr, 0,0,0,0};
    ESP_ERROR_CHECK(esp_vfs_littlefs_register(&conf));
    ESP_ERROR_CHECK(esp_littlefs_info(conf.partition_label, &total, &used));
    ESP_LOGI(TAG, "LittleFS Partition successfully mounted: total: %dbyte, used: %dbyte", total, used);
    nvs_stats_t nvsStats;
    ESP_ERROR_CHECK(nvs_flash_init_and_erase_lazily(NVS_PARTITION_NAME, &nvsStats));
    ESP_LOGI(TAG, "NVS flash initialized. Namespace count: %d, total entries: %d, used entries: %d, free entries: %d, available entries: %d", nvsStats.namespace_count, nvsStats.total_entries, nvsStats.used_entries, nvsStats.free_entries, nvsStats.available_entries);
    
    //Configure USB
    tinyusb_config_t tusb_cfg = TINYUSB_DEFAULT_CONFIG();
    tusb_cfg.descriptor.device = &s_usb_device_desc;
    tusb_cfg.descriptor.string = s_usb_string_desc;
    tusb_cfg.descriptor.string_count = 5; // indices 0-4
    tusb_cfg.descriptor.full_speed_config = s_usb_cfg_desc;
    tusb_cfg.phy.self_powered = true;
    tusb_cfg.phy.vbus_monitor_io = boardInit.VbusSensePin();
    ESP_ERROR_CHECK(tinyusb_driver_install(&tusb_cfg));
    tinyusb_config_cdcacm_t acm_cfg = {}; // the configuration uses default values
    ESP_ERROR_CHECK(tinyusb_cdcacm_init(&acm_cfg));
    ESP_LOGI(TAG, "USB initialization completed. Device IDs are VID=0x%04X PID=0x%04X", s_usb_device_desc.idVendor, s_usb_device_desc.idProduct);

    //Install Temperature sensor. Temperature Sensor is used in generic hal for generic use _AND_ is used in the SystemPlugin
    //this is why the handly is created here and passed to both the hal and the plugin
    temperature_sensor_handle_t tempHandle;
    temperature_sensor_config_t temp_sensor_config = {-10, 80, TEMPERATURE_SENSOR_CLK_SRC_DEFAULT, {0}};
    ESP_ERROR_CHECK(temperature_sensor_install(&temp_sensor_config, &tempHandle));
    ESP_ERROR_CHECK(temperature_sensor_enable(tempHandle));
    ESP_LOGI(TAG, "Temperature sensor initialized and enabled");
    
    std::vector<webmanager::iWebmanagerPlugin*> plugins;
    plugins.push_back(new SystemInfoPlugin(tempHandle));

    aCANMessageBuilderParser* canMBP;
    if(sensact::config::USE_NEW_CAN_ID){
        canMBP = new cCANMessageBuilderParserNew();
    } else{
        canMBP = new cCANMessageBuilderParserOld();
    }
    
    IInitializationContext initCtx{tempHandle, canMBP, NVS_PARTITION_NAME, cfg::HOSTNAME, &plugins};
    std::vector<AbstractBusmaster*> busmasters;
    iHAL* halobj = boardInit.CreateHalAndBusmasters(initCtx, busmasters);
    assert(halobj);

    cNodemaster* nodemaster = new cNodemaster(halobj, &busmasters, canMBP);
    plugins.push_back(nodemaster);
    std::vector<sensact::iHost *> hosts;

    boardInit.CreateHosts(initCtx, nodemaster, hosts);
    nodemaster->Setup(hosts);
    
    //Configure Network
    webmanager::M* wm = webmanager::M::GetSingleton();
    ESP_ERROR_CHECK(wm->Begin(cfg::NODE_ID, "sensact1", cfg::NODE_ID, false, &plugins, true, false, ESP_LOG_WARN,
#ifdef __WEBMANAGER_AUTH_USERNAME__
        cfg::WEBMANAGER_AUTH_USERNAME,
#else
        "admin",
#endif
#ifdef __WEBMANAGER_AUTH_PASSWORD__
        cfg::WEBMANAGER_AUTH_PASSWORD,
#else
        "password",
#endif
#ifdef __WIFIMANAGER_AP_FALLBACK_TIMEOUT_MS__
        (time_t)cfg::WIFIMANAGER_AP_FALLBACK_TIMEOUT_MS * 1000
#else
        webmanager::FAR_FUTURE
#endif
    ));
    
    const char *hostname = wm->GetHostname();
#if defined(HTTPS)
    httpd_ssl_config_t httpd_conf = HTTPD_SSL_CONFIG_DEFAULT();
    httpd_conf.servercert = esp32_pem_crt_start;
    httpd_conf.servercert_len = esp32_pem_crt_end-esp32_pem_crt_start;
    httpd_conf.prvtkey_pem = esp32_pem_key_start;
    httpd_conf.prvtkey_len = esp32_pem_key_end-esp32_pem_key_start;
    httpd_conf.httpd.uri_match_fn = httpd_uri_match_wildcard;
    httpd_conf.httpd.max_uri_handlers = 15;
    ESP_ERROR_CHECK(httpd_ssl_start(&http_server, &httpd_conf));
    ESP_LOGI(TAG, "Secure HTTPS Server listening on https://%s:%d", hostname, httpd_conf.port_secure);
#elif defined(HTTP)
    httpd_config_t httpd_conf = HTTPD_DEFAULT_CONFIG();
    httpd_conf.uri_match_fn = httpd_uri_match_wildcard;
    httpd_conf.max_uri_handlers = 15;
    ESP_ERROR_CHECK(httpd_start(&http_server, &httpd_conf));
    ESP_LOGI(TAG, "Unsecure HTTP Server (not secure!) listening on http://%s:%d", hostname, httpd_conf.server_port);
#else
    #error "Either define HTTP or HTTPS"
#endif
    
    wm->RegisterHTTPDHandlers(http_server);
    wm->CallMeAfterInitializationToMarkCurrentPartitionAsValid();
    
    nodemaster->RunEternalLoopInTask();
    
    int counter{0};
    while (true)
    {
        wm->Supervise();
        if (++counter % 10 == 0)
        {
            ESP_LOGI(TAG, "Heap %6lu nodemaster tells:\n %s", esp_get_free_heap_size(), nodemaster->GetStatusMessage());
        }
        vTaskDelay(pdMS_TO_TICKS(1000));
    }
    
}

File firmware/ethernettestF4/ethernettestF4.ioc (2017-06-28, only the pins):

Mcu.UserName=STM32F407VETx
PA1.Signal=ETH_REF_CLK
PA10.Signal=USART1_RX
PA11.Signal=USB_OTG_FS_DM
PA12.Signal=USB_OTG_FS_DP
PA2.Signal=ETH_MDIO
PA7.Signal=ETH_CRS_DV
PA9.Signal=USART1_TX
PB11.Signal=ETH_TX_EN
PB12.Signal=ETH_TXD0
PB13.Signal=ETH_TXD1
PC1.Signal=ETH_MDC
PC4.Signal=ETH_RXD0
PC5.Signal=ETH_RXD1
PH0-OSC_IN.Signal=RCC_OSC_IN
PH1-OSC_OUT.Signal=RCC_OSC_OUT

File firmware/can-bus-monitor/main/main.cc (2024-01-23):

#include <stdio.h>
#include <stdlib.h>
#include <sys/reent.h>
#include "esp_log.h"
#include "esp_vfs.h"
#include "freertos/FreeRTOS.h"
#include "freertos/task.h"
#include "freertos/queue.h"
#include "freertos/semphr.h"
#include "freertos/event_groups.h"

#include "tinyusb.h"
#include "tusb_cdc_acm.h"
#include "tusb_console.h"
#include "sdkconfig.h"

#include "driver/twai.h"

#include <sys/socket.h>
#include "lwip/err.h"
#include "lwip/sys.h"

#include "esp_system.h"
#include "esp_wifi.h"
#include "esp_event.h"

#include "nvs_flash.h"
#include "esp_err.h"

#include <vector>
#include <array>
#include <cstring>
#include "can_message_builder_parser.hh"





constexpr twai_filter_config_t f_config  = TWAI_FILTER_CONFIG_ACCEPT_ALL();
constexpr twai_timing_config_t t_config  = TWAI_TIMING_CONFIG_125KBITS();

constexpr twai_general_config_t g_config = TWAI_GENERAL_CONFIG_DEFAULT(GPIO_NUM_7, GPIO_NUM_15, TWAI_MODE_NORMAL);

sensact::aCANMessageBuilderParser* canMBP = new sensact::cCANMessageBuilderParserOld();
static EventGroupHandle_t s_wifi_event_group;
#define WIFI_CONNECTED_BIT BIT0

#define TAG "MON"
constexpr auto RX_TASK_PRIO{11};



static void twai_receive_task(void *arg)
{

	// set up address to sendto
	struct sockaddr_in addr;
	memset(&addr, 0, sizeof(addr));
	addr.sin_family = AF_INET;
	addr.sin_port = htons(CONFIG_UDP_PORT);
	addr.sin_addr.s_addr = htonl(INADDR_BROADCAST); // send message to 255.255.255.255
	int fd;
	fd = lwip_socket(AF_INET, SOCK_DGRAM, IPPROTO_UDP ); // Create a UDP socket.
	LWIP_ASSERT("fd >= 0", fd >= 0);
    
    ESP_LOGI(TAG, "Start Receive and Broadcast via UDP");
    while (true) {
        twai_message_t rx_msg;
        ESP_ERROR_CHECK(twai_receive(&rx_msg, portMAX_DELAY));
        sensact::CANMessage message;
        message.Id=rx_msg.identifier;
        memcpy(message.Data, rx_msg.data, 8);
        message.DataLen=rx_msg.data_length_code;
        canMBP->TraceCommandMessage(message);
		/*int ret = */lwip_sendto(fd, (void*)&rx_msg, sizeof(rx_msg), 0, (struct sockaddr *)&addr, sizeof(addr));
       
    }
    vTaskDelete(NULL);
}


/* The event group allows multiple bits for each event, but we only care about two events:
 * - we are connected to the AP with an IP
 * - we failed to connect after the maximum amount of retries */
#define WIFI_CONNECTED_BIT BIT0
#define WIFI_FAIL_BIT      BIT1

constexpr int MAXIMUM_RETRY{10};


static int s_retry_num = 0;


extern "C" void wifi_event_handler(void* arg, esp_event_base_t event_base,
                                int32_t event_id, void* event_data)
{
    if (event_id == WIFI_EVENT_STA_START) {
        ESP_LOGI(TAG, "The show begins - we connect...");
        ESP_ERROR_CHECK(esp_wifi_connect());
    } else if (event_id == WIFI_EVENT_STA_DISCONNECTED) {
        if (s_retry_num < MAXIMUM_RETRY) {
            ESP_ERROR_CHECK(esp_wifi_connect());
            s_retry_num++;
            ESP_LOGI(TAG, "retry to connect to the AP");
        } else {
            ESP_LOGE(TAG, "xEventGroupSetBits(s_wifi_event_group, WIFI_FAIL_BIT);");
            xEventGroupSetBits(s_wifi_event_group, WIFI_FAIL_BIT);
        }
    }
    else{
        ESP_LOGI(TAG, "unknown wifi event %d", (int)event_id);   
    }
}

extern "C" void ip_event_handler(void* arg, esp_event_base_t event_base,
                                int32_t event_id, void* event_data){     
    if(event_id == IP_EVENT_STA_GOT_IP) {
        ip_event_got_ip_t* event = (ip_event_got_ip_t*) event_data;
        ESP_LOGI(TAG, "got ip:" IPSTR, IP2STR(&event->ip_info.ip));
        s_retry_num = 0;
        xEventGroupSetBits(s_wifi_event_group, WIFI_CONNECTED_BIT);
    }else{
        ESP_LOGI(TAG, "unknown ip event %d", (int)event_id);  
    }
}

void wifi_init_sta(void)
{
    s_wifi_event_group = xEventGroupCreate();

    ESP_ERROR_CHECK(esp_netif_init());

    ESP_ERROR_CHECK(esp_event_loop_create_default());
    esp_netif_create_default_wifi_sta();

    wifi_init_config_t cfg = WIFI_INIT_CONFIG_DEFAULT();
    ESP_ERROR_CHECK(esp_wifi_init(&cfg));

    ESP_ERROR_CHECK(esp_event_handler_instance_register(WIFI_EVENT,
                                                        ESP_EVENT_ANY_ID,
                                                        &wifi_event_handler,
                                                        nullptr,
                                                        nullptr));
    ESP_ERROR_CHECK(esp_event_handler_instance_register(IP_EVENT,
                                                        ESP_EVENT_ANY_ID,
                                                        &ip_event_handler,
                                                        nullptr,
                                                        nullptr));

    wifi_config_t wifi_config_sta={};
    strcpy((char *)wifi_config_sta.sta.ssid, CONFIG_WIFI_SSID);
    strcpy((char *)wifi_config_sta.sta.password, CONFIG_WIFI_PASSWORD);
    wifi_config_sta.sta.threshold.authmode = WIFI_AUTH_WPA2_PSK;
    wifi_config_sta.sta.sae_pwe_h2e = WPA3_SAE_PWE_BOTH;
    ESP_ERROR_CHECK(esp_wifi_set_mode(WIFI_MODE_STA) );
    ESP_ERROR_CHECK(esp_wifi_set_config(WIFI_IF_STA, &wifi_config_sta) );
    ESP_ERROR_CHECK(esp_wifi_start() );

    ESP_LOGI(TAG, "wifi_init_sta finished.");

    /* Waiting until either the connection is established (WIFI_CONNECTED_BIT) or connection failed for the maximum
     * number of re-tries (WIFI_FAIL_BIT). The bits are set by event_handler() (see above) */
    EventBits_t bits = xEventGroupWaitBits(s_wifi_event_group,
            WIFI_CONNECTED_BIT | WIFI_FAIL_BIT,
            pdFALSE,
            pdFALSE,
            portMAX_DELAY);

    /* xEventGroupWaitBits() returns the bits before the call returned, hence we can test which event actually
     * happened. */
    if (bits & WIFI_CONNECTED_BIT) {
        ESP_LOGI(TAG, "connected to ap SSID:%s password:%s",
                 CONFIG_WIFI_SSID, CONFIG_WIFI_PASSWORD);
    } else if (bits & WIFI_FAIL_BIT) {
        ESP_LOGI(TAG, "Failed to connect to SSID:%s, password:%s",
                 CONFIG_WIFI_SSID, CONFIG_WIFI_PASSWORD);
    } else {
        ESP_LOGE(TAG, "UNEXPECTED EVENT");
    }
}
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

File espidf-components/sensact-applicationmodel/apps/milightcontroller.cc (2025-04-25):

#include <algorithm> // std::max
#include "milightcontroller.hh"
#include <esp_timer.h>
#include <freertos/FreeRTOS.h>
#include <freertos/queue.h>
#include <freertos/task.h>
#include "cApplications.hh"
#define TAG "MILIGHT"
#include <sensact_logger.hh>

namespace sensact::apps
{
	
	cMilightController::cMilightController(eApplicationID id) : cApplication(id)
	{
		milightQueue = xQueueCreate(10, sizeof(std::pair<uint8_t, uint8_t>));

		this->keyCode2command[milight::keycodesFUT89::KON]= [](sensact::apps::iSensactContext *ctx){
			ctx->SendONCommand(eApplicationID::PWM___LX_BACK_C1, sensact::time::H12_ms);
		};
		this->keyCode2command[milight::keycodesFUT89::KOFF]= [](sensact::apps::iSensactContext *ctx){
			ctx->SendOFFCommand(eApplicationID::PWM___LX_BACK_C1, 0);
		};
		this->keyCode2command[milight::keycodesFUT89::K1_0]= [](sensact::apps::iSensactContext *ctx){
			ctx->SendUPCommand(eApplicationID::BLIND_LX_BACK_J2, false);
		};
		this->keyCode2command[milight::keycodesFUT89::K1_1]= [](sensact::apps::iSensactContext *ctx){
			ctx->SendDOWNCommand(eApplicationID::BLIND_LX_BACK_J2, false);
		};
		this->keyCode2command[milight::keycodesFUT89::K2_0]= [](sensact::apps::iSensactContext *ctx){
			ctx->SendUPCommand(eApplicationID::BLIND_LX_BACK_J3, false);
		};
		this->keyCode2command[milight::keycodesFUT89::K2_1]= [](sensact::apps::iSensactContext *ctx){
			ctx->SendDOWNCommand(sensact::eApplicationID::BLIND_LX_BACK_J3, false);
		};
	}

	eAppType cMilightController::GetAppType()
	{
		return eAppType::REMOT;
	}

	eAppCallResult cMilightController::Setup(iSensactContext *ctx)
	{
		return eAppCallResult::OK;
	}

	eAppCallResult cMilightController::Loop(iSensactContext *ctx)
	{
		std::pair<uint8_t, uint8_t> message;

		while (xQueueReceive(milightQueue, &message, 0) == pdTRUE)
		{
			uint8_t cmd = message.first;
			uint8_t arg = message.second;
			switch (cmd)
            {
            case milight::commandsFUT89::KEYS:{
                if(arg>=milight::keycodesFUT89::MAX) continue;;
                if(keyCode2command[arg]==nullptr) continue;;
                (keyCode2command[arg])(ctx);
                continue;
            }
            case milight::commandsFUT89::DIMMER:{
                //arg von 0...100%
                //ab 95% -->voll
                uint16_t val{0};
                if(arg>98){
                    val=UINT16_MAX;
                }else{
                    val=arg*(UINT16_MAX/100.0);
                }
				ESP_LOGD(TAG, "ctx->SendSET_VERTICAL_TARGETCommand(eApplicationID::PWM___LX_BACK_C1, val)");
				ctx->SendSET_VERTICAL_TARGETCommand(eApplicationID::PWM___LX_BACK_C1, val);
                continue;
            }

            default:
                ESP_LOGD(TAG, "Command %d has no associated handler", cmd);
                continue;;
            }
		}
		return eAppCallResult::OK;
	}

	eFillStatusResult cMilightController::FillStatus(iSensactContext &ctx, std::array<uint16_t, 4>& buf){
		buf[0]=buf[1]=buf[2]=buf[3]=0;
		return eFillStatusResult::NO_STATUS;
	}

	void cMilightController::ReceivedFromMilight(uint8_t cmd, uint8_t arg){
		auto now= esp_timer_get_time();
		if(arg == previousArg && cmd == previousCmd && (now - lastForwarded_us) < 500'000) {
			ESP_LOGD(TAG, "CMD %3d ARG %3d (blocked)", cmd, arg);
			return;
		}
		ESP_LOGI(TAG, "CMD %3d ARG %3d (forwarded)", cmd, arg);
		previousArg=arg;
		previousCmd=cmd;
		lastForwarded_us=now;

		std::pair<uint8_t, uint8_t> message = {cmd, arg};
		
		if (xQueueSend(milightQueue, &message, pdMS_TO_TICKS(10)) != pdPASS)
		{
			ESP_LOGW(TAG, "Queue ist voll, Nachricht verworfen!");
		}
	}
}

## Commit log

2016-07-18 Bugfixes in OneWire-Client, Added i2c communication for sensactse;
    [bme280.cpp]
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2016-07-21 Fixes and Addons
    Changed BME280 access api to Bosch sensortec (almost) original version
    Fixed some compiler warnings
    Rotary encoder fires only once per step
    Fixed and improved RGBW-App
    Added "ON" and "AutoOff" functionality to PWM
    Added LightBarrier application
    Enriched BrightnessSensor ("final target")
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2016-09-06 PCB fixes
    [sensactPwmExt.kicad_pcb]
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2016-10-01 Fix Build & fail safe i2c
2016-10-02 new version of sensactHs
    [ESDProtection.sch, cpu.sch, input.sch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]
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2016-10-09 Implemented i2c-Reset for STM32F1
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2016-10-15 sensact1.0 first ERC ok
    [ESDProtection.sch, cpu.sch, output.sch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]
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2016-10-22 Digital Filter for rotary encoder, Bugfix in cSound
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2016-12-17 Redesign sensactRelExt
    [sensactRelExt.kicad_pcb, sensactRelExt.sch]
2016-12-17 Redesign sensactPwmExt
    [sensactPwmExt.kicad_pcb, sensactPwmExt.sch]
2016-12-17 Redesign sensactInpExt
    [onePwmOut.sch, sensactInpExt.kicad_pcb, sensactInpExt.sch]
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2016-12-17 Some Improvement in sensactHs
    [sensactHs.kicad_pcb]
2017-01-23 Finalize Extension Modules PCB order
    [sensactInpExt-B.Cu.gbr, sensactInpExt-B.Mask.gbr, sensactInpExt-B.Paste.gbr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]
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2017-03-10 Huge Refactoring; still untested
    [Motorinterface.sch, cpu.sch, idcBreakout.sch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]
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2017-03-28 PCB Order for sensactUP
    [sensactUp-B.Cu.gbr, sensactUp-B.Mask.gbr, sensactUp-B.Paste.gbr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]
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2017-06-17 various updates/fixes in the driver modules
2017-06-17 Minor improvement in PCB
    [sensactUp.kicad_pcb]
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2017-07-11 Huge Refactoring
    Added Ethernet/MQTT/HTTP
    Removed Names/applicationType in all application objects as this information is stored centralle
    [sensactUp.sch]
2017-07-11 SensactUP gets LIN-Port and alternative 5V Power Supply
    [cpu.sch, sensactSe.sch, sensactUp.kicad_pcb]
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2017-07-24 sensactUP - going further
    [cpu.sch, sensactUp.kicad_pcb, sensactUp.sch]
2017-07-27 PCB Order @ smart-prototyping 2017-07-26
    [cpu.sch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]
2017-07-30 Firmware as flashed to L3_HS on 2017-07-30
    [sensactPwmExt.sch]
2017-07-30 pwmext completed and basically ready for ordering
    [onePwmOut.sch, sensactPwmExt.kicad_pcb]
2017-08-02 sensactLEDDriver on 5x5cm PCB
    [onePwmOut.sch, sensactLedDriver.kicad_pcb, sensactLedDriver.sch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]
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2017-09-07 Every application knows its apptype
    [onePwmOut.sch, sensactLedDriver.kicad_pcb, sensactLedDriver.sch]
2017-10-02 Fixed label on sensactUP04
    [sensactUp.kicad_pcb]
2017-11-11 Release 11.11.2017 to all UP-Devices
    [sensactRelExt.kicad_pcb]
2018-01-05 Various changes as flashed to NODE_SNSCT_L0_TECH_HS_1
    [sensactUp.kicad_pcb, sensactUp.sch]
2018-03-19 sesnactHsMini & RPi Hat
    [RPi_GPIO.sch, RPi_Hat.kicad_pcb, RPi_Hat.sch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]
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2018-04-20 related to previous commit
    [RPi_GPIO.sch, RPi_Hat.sch, _saved_RPi_Hat.sch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]
2019-07-12 FirmwareUpdate auf CubeMX 24
    [DAC.sch, Verteilerdose001.kicad_pcb, Verteilerdose001.sch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]
2019-07-12 WHS lIb
    WHS lIb
    [cpu.sch]
2019-08-24 Deleted old kicad libraries
    [SIQ-02FVS3.stp, pxc_1780837_01_FFKDSA1-H-2-54-8_3D.stp, pxc_1881503_00_MC-0-5-8-G-2-5_3D.stp]
2019-08-24 Renamed (and updated) SensactVerteilerdose to sensactHsExt
    [Verteilerdose001.kicad_pcb, Verteilerdose001.sch, sensactHsExt.kicad_pcb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]
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2019-10-07 sensactHsIO RC1 and sensactAudioExt, RC1
    [hmi.sch, in.sch, out.sch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]
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2019-11-09 sensactHsIO as ordered at PCB Service
    [sensactHsIO.kicad_pcb]
2019-11-09 sensactHsIO as ordered at JLCPBC (last minute changes)
    [hmi.sch, out.sch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]
2019-12-24 Added bevel to corner of PCB
    [sensactHsIO.kicad_pcb]
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2020-11-15 Initial Layout Top board
    [sensactHsNano.kicad_pcb, sensactHsNano.sch]
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2021-03-13 sensactOutdoor PCB & sensactHSIO3 PCB
    [A6211-Design-Tool.xlsx, sensactHsIO3.kicad_pcb, sensactHsIO3.sch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]
2021-03-13 sensactOutdoor - pretty schematic & 3D rendering
    [sensactOutdoor.sch]
2021-03-14 Added RX470B 433MHz Module
    [sensactOutdoor.kicad_pcb, sensactOutdoor.sch]
2021-03-15 added fuse , optimized routing
    [sensactOutdoor.kicad_pcb, sensactOutdoor.sch]
2021-03-15 Unsafed Changes (belongs to the previous checkin)
    [sensactOutdoor.sch]
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2021-03-18 sensactOutdoor PCB as ordered at JLCPCB
    [sensactOutdoor-B_Cu.gbr, sensactOutdoor-B_Mask.gbr, sensactOutdoor-B_Paste.gbr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]
2021-04-08 variousChanges on sensactHSIO3+4 and sensactOutdoor
    [ESP32_I2C_IRQ.xlsx, I2S_AMP.sch, Platinenabmessungen.dxf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]
2021-04-20 Improvements in pcb design of sensactOutdoor and sensactHsIO4
    [io4.sch, sensactHsIO4.kicad_pcb, sensactHsIO4.sch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]
2021-06-04 Renamed liebler_IC to liebler_SEMICONDUCTORS
    [sensactHsIO4.kicad_pcb, sensactHsIO4.sch]
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2021-08-09 sensactUP2, sensactHsNano sensactHsLED sensactOutdoor as ordered at JLCPCB
    [A6211-Design-Tool.xlsx, PinHints.xlsx, audioamplifier.sch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]
2021-09-02 sensactHsNano for Reflow Soldering
    [A6211-Design-Tool.xlsx, PinHints.xlsx, audioamplifier.sch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]
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2021-11-25 sensactHSnano as ordered @ JLCPCB
    [PinHints.xlsx, audioamplifier.sch, ebus.sch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]
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2022-04-04 Various changes (does not compile)
    [psu.kicad_sch, sensactHsIO4.kicad_pcb, sensactHsIO4.kicad_sch]
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2022-11-09 sensactUP3 and sensactUPUpdates to KiCad6
    [analog_amp.kicad_sch, psu.kicad_sch, sensactOutdoor.kicad_pcb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]
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2023-02-15 PCBs as ordered at JLCPCB
    [BOM-din_schiene_seitenwand.csv, BOM-sensactHsIO5.csv, BOM-sensactHs_modular_esp32.csv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]
2023-04-04 Various updates, new version with ESP32 in beta test :-)
    [BOM-sensactHsIO5.csv, audioamplifier.kicad_sch, din_schiene_seitenwand-B_Cu.dxf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]
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2024-01-24 sh connector with jumper
    [sensactDoorControl.kicad_pcb, sensactDoorControl.kicad_sch]
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2024-01-28 larger i2c mith io pins
    [sensactDoorControl.kicad_pcb, sensactDoorControl.kicad_sch]
2024-01-30 sensactDoorCtrl PCB as ordered @JLCPCB
    [BOM-sensactDoorControl.csv, sensactDoorControl.kicad_pcb, sensactDoorControl.kicad_sch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]
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2025-02-14 Improved Runtime Configuration, Send App State from Web to ESP, Minor Fixes/improvements
    [main.cc, node_applicationhost.cc]
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2025-02-25 Minor fixes due to renaming
    [sensactOutdoor.kicad_pcb]
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2025-04-06 Various Fixes and logging improvements
    [Aufbau der Statusmeldung 4 u16.xlsx]
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2025-04-25 Various fixes for sensact Sattlerstraße
    [Aufbau der Statusmeldung 4 u16.xlsx]
2025-05-04 Fixes for sensactTERRASSE
    [Aufbau der Statusmeldung 4 u16.xlsx]
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2025-10-12 added sensactUp_as_Hs and fixed various compile errors. Untested!
    [sensactUp_as_Hs.kicad_sch]
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2026-03-28 Fixes in i2c, Migration to new IDF 6.0
    [main.cc, node_applicationhost.cc]
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2026-08-01 Migrate ws-protocol from Flatbuffers to BestBinaryBuffers, add C# builder, fix firmware build
    Replaces the Flatbuffers-based wire protocol with BestBinaryBuffers (schema as
    annotated C# instead of .fbs/JSON) across espidf-component-webmanager and
    sensact_firmware's server-side namespaces (wifimanager, scheduler, systeminfo,
    usersettings, nodemaster, sensact, journal, fingerprint), plus the new builder_cs
    C# build orchestrator that generates ws_protocol.hh/.ts and drives the ESP-IDF
    build. Also fixes the compile errors this surfaced now that the firmware was
    build-verified for the first time (missing namespace qualification on generated
    Append/Encode/Decode helpers, a parameter-shadowing bug,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
    [main.cc, node_applicationhost.cc]
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2026-08-17 Document login-credential-save root cause + builder reusability plan in backlog
    Login: analyzed why browsers never offer to remember the webmanager login --
    main.cc hardcodes HTTPS with a self-signed cert from an untrusted private CA,
    and Chrome/Edge deliberately withhold the "save password?" prompt on any page
    reached via a bypassed certificate warning. Documents the mechanism and four
    alternative fixes with tradeoffs (install the CA, drop to HTTP, Basic Auth,
    SPA-side session persistence) for a later decision -- no code change yet.
    Builder reusability: notes the user's intent to extract builder/ into a shared
    C:\repos\dotnet_libs\firmware_builder-style package usable across other ESP32
    pr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
2026-08-17 Stop leaking WEBMANAGER_AUTH_PASSWORD into the client-side JS bundle
    GenerateRuntimeConfig wrote every board_settings define (including the
    "firmware" group, which holds WEBMANAGER_AUTH_USERNAME/_PASSWORD) into
    all three outputs -- C++ header, CMake config, AND the TS runtimeconfig
    package. The latter is imported by web/ and compiled straight into the
    public JS bundle, readable via view-source by anyone, logged in or not.
    Split into two dicts: 'defines' (server-only: C++ header + CMake) and
    'clientDefines' (TS bundle). Only "web"-group board_settings and
    non-secret build metadata go into clientDefines; "firmware"-group
    settings and BOARD_DIRECTORY (a local dev-machine path) stay
    server-side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
2026-09-04 Builder: adopt generalized IBuildContext, generic board_info.json schema
    Follows the FirmwareBuilder.Common refactor (mirrors the STM32 reference
    project's builder): adds SensactBuildContext implementing IBuildContextEsp32,
    SensactContextLoader (sensact.json -> ISensactContext, replaces BoardContext),
    NodeIdBoardTypeCatalog (NODE_ID -> BoardTypeName/BoardTypeVersion, backs
    IBuildContext.BoardTypeName now that board.json no longer carries a
    board_name/board_roles pair). Drops BoardContext.cs/IBoardInfo.cs/Paths.cs,
    rewrites Program.cs as [BuildStep] methods dispatched via BuildStepRunner,
    adds PrepareContextWithCommandLineArguments (nodeId-based offline board
    selection, successor to SelectOff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
2026-09-04 HAL: replace per-board preprocessor splice with BoardInit classes; add Hoymiles/nRF24 + led component
    main.cc used to #include <hal.inc>/<station_config_hardware.inc>/<station_config_hosts.inc>
    mid-scope inside app_main(), relying on app_main() never returning so the
    Busmaster/PCA objects spliced in there stayed valid on the stack. Replaces
    that with main/hal/<NODE_ID>/board_init.hh defining a sensact::BoardInit :
    IBoardInit (board_init_interface.hh) that main.cc constructs explicitly and
    calls (CreateHalAndBusmasters/CreateHosts/VbusSensePin) -- ownership of
    busmaster/peripheral objects is now explicit (heap-allocated) instead of
    implicit. Touches hal_sensact{HsNano3,Outdoor,Up3,UpControl}.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
    [main.cc]
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2026-09-04 web: dedupe single-file Vite plugin into shared package, drop dead deps
    vite-plugin-single-file-firmware-asset.ts/singlefile-minify.ts/
    html-minifier-terser.d.ts were a near-verbatim copy from
    factory_in_a_box. Moved into
    npm-packages/@klaus-liebler/vite-firmware-single-file, consumed here
    via file: dependency instead (terser/html-minifier-terser move with
    it). Also removed esbuild-minify-templates/vite-plugin-svgo (listed
    but never registered as a Vite plugin) and added the missing
    typescript devDependency ("tsc && vite build" relied on a transitive
    install). Verified: Vite config loads and resolves the plugin
    correctly (full app build is currently blocked by pre-existing
    missing generated/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
2026-09-09 applicationmodel: implement cLightbarrier, fix BrightnessSensor codegen
    sensact::apps::cLightbarrier was referenced by the C# model generator
    (LightbarrierApplication) but never implemented in C++. Added it
    (motion-detector input, optionally triggers finalTarget via ON command;
    BrightnessSensor gating not wired up yet, no app-to-app value query API
    exists and no live wiring currently sets it).
    Also fixes GenerateCPPConstructor emitting the raw BrightnessSensor
    ushort as "eApplicationID::65535" (invalid syntax) instead of resolving
    it to a name like FinalTarget already does.
2026-09-11 docs: rewrite top-level docs to describe current state, archive plan_v2
    Removes stale gulp/TypeScript builder references (now the C# builder),
    corrects the HAL board-init description (BoardInit classes replaced the
    old per-board .inc splice), fixes the board_info.json schema example,
    and updates the app/HAL variant lists to match the current code.
    plan_v2/ is marked archived instead of rewritten, since it documents a
    past planning phase rather than current state.
2026-09-11 pcb: ignore KiCad .history backup folders for all boards, update sym-lib-tables
    .history/ was already ignored for two boards but missing for the other six
    (sensactHsExt/IO/IO5/IO5-pca9685/Nano3/Relay), letting KiCad's automatic
    backup snapshots show up as untracked churn. sym-lib-table changes are
    KiCad 7 re-saving the legacy rescue-library entries and adding the
    project cache library.
2026-09-11 firmware: fix SNSCT_L0_TECH_HS_1 bring-up issues found on real hardware
    - can_message_builder_parser: implement the previously-missing
    ParseCanMessageType() for the old CAN-ID scheme (always
    ApplicationCommand for legacy devices), fixing CAN message parse
    failures surfaced by the new detailed error log in
    cApplicationHost::OnApplicationCommand.
    - onoff: fall back to TIME_MAX (stay on) when neither an explicit timer
    nor autoOffCfg is set, matching the constructor's initialState=AN case.
    - hal_sensactHsNano3: call initETH_W5500 with selfInit=false is wrong at
    that point since esp_netif_init()/esp_event_loop_create_default() run
    later in main.cc via webmanager::M::Begin() -- switc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
2026-09-11 Sattlerstrasse16 model: fix corridor button wiring, insert dummy enum slot
    - Sattlerstrasse16Builder: PUSHB_L0_CORR_B11/B21/B31 all referenced
    PWM___LS_STRS_W2 instead of PWM___LS_STRS_W1 in their app-set, so they
    couldn't toggle the light they're physically wired to.
    - ApplicationId: insert SNSCT_XX_DUMMY_1 as an unused placeholder to fix
    the enum numbering (shifts every subsequent app ID by one); regenerated
    sensact_applicationIds.enums.cs via GenerateModelFiles.
2026-09-11 firmware: fix ESP-IDF 6.0 build (newlib workaround, TinyUSB CDC), drop dead sdkconfig line
    CONFIG_LIBC_NEWLIB=y: IDF 6.0 switched its libc default to Picolibc, which
    combined with the freshly-installed xtensa-esp-elf-gcc 15.2.0 toolchain hits
    a real upstream compiler/attribute-placement bug in hal/assert.h's __noreturn
    handling ("'noreturn' attribute does not apply to types", -Werror=attributes).
    Newlib skips that code path entirely -- exactly the escape hatch ESP-IDF's
    own esp_libc/Kconfig help text names for this situation.
    CONFIG_TINYUSB_CDC_ENABLED=y: main.cc includes tinyusb_cdc_acm.h, which
    requires this explicitly (defaults to n upstream) -- was a hard compile
    error otherwise.
    Remov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
2026-09-11 firmware: fix doorbell (SOUND_L0_TECH_AUDIO) playing silence instead of dingdong
    Three independent bugs stacked on this one feature:
    1. Sattlerstrasse16Builder.cs: SOUND_L0_TECH_AUDIO was constructed via
    `new SoundApplication(..., "Türklingel", 17)` instead of the AddSound(...)
    helper -- the trailing `17` landed in the 4th ctor slot (initialVolume),
    leaving defaultSignalOnToggle at its class default of 0 (SOUNDS[0] =
    silence). The doorbell button sends a bare TOGGLE (no payload), and
    cSound::OnTOGGLECommand always plays exactly defaultSignalOnToggle.
    Switched to AddSound(...), whose defaults are correct (defaultSignalOnToggle=1
    = dingdong_mp3); volume set explicitly to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
2026-09-11 firmware: make PWM dimming fade time-based, reduce I2C commit latency
    cSinglePWM::Loop() advanced currentLevel by a fixed step (32*256) per call,
    implicitly assuming a punctual 100ms NodemasterTask cycle. Two problems:
    fade duration silently depended on how often Loop() actually got called
    (delayed by CAN/audio work sharing that task), and a delayed call didn't
    catch up -- it just made the fade run longer than intended. Now computes the
    step from actual elapsed time (same effective rate as before, ~32*256 per
    100ms), measured via ctx->Now() deltas, so duration stays correct regardless
    of Loop() timing jitter.
    Also lowered I2CBusmaster's own tick from 100ms to 20ms (busmaster.hh) --
    it only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
2026-09-16 firmware: activate Sound app UI, add day/night volume + test-play, generic app-param persistence
    cSound (doorbell/notification player) gets day/night volume with a 15-minute-
    resolution time window: OnTOGGLECommand (automatic trigger, e.g. doorbell
    button) now computes volume from wall-clock time via a new
    ComputeAutomaticVolume() helper instead of the fixed manual volume, which stays
    reserved for OnSET_SIGNALCommand/the UI's manual test button.
    New generic SET_PARAM(paramIndex, value) / SAVE_PARAM commands (builder-wide,
    via CommandType.cs + SensactApplication.cs) let an app receive/persist a small
    set of typed values without inventing new wire messages per app. Persistence
    goes through ne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
2026-09-16 firmware: bucket-rotation Loop() scheduling at 20ms, fix broken hal_sensactUp3.hh
    NodemasterTask now ticks at 20ms (was 100ms). cApplicationHost::Loop() no
    longer runs every local app every tick -- each app belongs to one of
    LOOP_BUCKET_COUNT=5 buckets (by position in localAppIds), and only the
    current tick's bucket runs, plus any app whose last NeedsFastLoop() call
    returned true (e.g. cSinglePWM mid-fade). "Cold" apps keep the exact same
    worst-case gap as before (5 buckets * 20ms = 100ms), so nothing that already
    tolerated 100ms-grained Loop() calls is affected; "hot" apps now get looped
    every 20ms instead of every 100ms, so PWM fades advance 5x more often without
    raising total per-100ms-wi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
2026-10-08 firmware: nodemaster manual IO mode + I2C discovery of additional PCA9555/PCA9685
    - I2CBusmaster::Setup() probes the bus after setting up the chips from
    board_init.hh (they stay first, so app indices are unchanged) and appends
    every additionally found PCA9555 (0x20..0x27) and PCA9685 (0x40..0x7F,
    without ALL_CALL 0x70); ranges are named e.g. "pca9685@0x43 (discovered)"
    - cNodemaster gets a non-persistent manual mode: while active, host Loop()
    and OfferMessage() are skipped (incoming CAN messages are dropped) and
    app writes via SetU16Output only update a shadow table, which is replayed
    to the hardware when switching back to app mode
    - ws protocol: new nodemaster.RequestSetMode / R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
2026-10-08 testserver: migrate to BestBinaryBuffers protocol, make it usable from vite dev
    - sensact, canmonitor and nodemaster handlers use @generated/wsprotocol_ts
    and the new websocket_file_testserver API; nodemaster simulates
    configured + discovered chips and RequestSetMode
    - testserver gets its own dependencies and "npm start"
    (node --preserve-symlinks --import tsx, so the shared framework resolves
    this project's generated protocol); tsconfig uses preserveSymlinks too
    - vite: "--mode testserver" points the websocket proxy to localhost:3000;
    new script dev:testserver, wss starts the testserver, it uses both
